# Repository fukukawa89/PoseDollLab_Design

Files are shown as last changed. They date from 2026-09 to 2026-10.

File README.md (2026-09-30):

# PoseDoll 人偶硬件设计

通用静态测姿人偶的独立设计仓库；Manny / Quinn 为软件适配目标。原来位于 `DollSimulation` UE 工程中的硬件、固件与硬件诊断工具已经迁入本目录；UE 插件、角色资产与完整 Python 模拟器留在原项目。

## 当前状态

**O21 已生成约 1500 元的降本工程候选。** 保留 O20 骨架和46路测量；改用 MT6701CT、单面传感板、中央三组16路选择和预制五芯线。单套目标分配1482.50元，尚无正式报价。传感板 ERC/DRC 与固件/主机测试通过；中央板布线、装配集成、实物标定和UE端到端仍未完成，不是整机制造放行。

- [O21设计与成本依据](Hardware/PoseDoll44/docs/DESIGN_REVO21.zh-CN.md)
- [O21预算与通道预览](Hardware/PoseDoll44/tutorials/full-doll-o21/index.html)
- [O21工程设计包](Hardware/PoseDoll44/bench/revO21/PoseDoll_O21_CostDown_Design.zip)
- [加工询价要求](Hardware/PoseDoll44/bench/revO21/RFQ.zh-CN.md)

### O20已保存机械基线

O20为900f572 / posedoll-o20-lightweight-20260930，原ZIP和文件保持不变。保留用户已接受的双髋布局、非相邻姿势避碰及O11摩擦配合结论。

- [O20设计说明](Hardware/PoseDoll44/docs/DESIGN_REVO20.zh-CN.md)
- [O20机械设计包](Hardware/PoseDoll44/bench/revO20/PoseDoll_O20_Universal_Design.zip)

### O19历史记录

**O19 已生成腿杆对齐候选：替换4件腿部连接架，仍为188件/117种打印件。** O11独立小样的配合与可调摩擦已由用户报告通过，不增加摩擦冗余。左大腿及双小腿中间直段对齐参考骨线，右大腿中间段保留向前6mm偏移。双髋中心各外移16mm和既有整机干涉仍保留；24案例及43个中间样本无新增干涉，不能据此声称整机全域通过。

- [O19设计与验证说明](Hardware/PoseDoll44/docs/DESIGN_REVO19.zh-CN.md)
- [O19单台设计包](Hardware/PoseDoll44/bench/revO19/PoseDoll_O19_Universal_Design.zip)
- [O19腿部对照与干涉展示](Hardware/PoseDoll44/tutorials/full-doll-o19/index.html)：本地服务 `/tutorials/full-doll-o19/index.html`。

### O18已保存基线

O18已保存为 `08e8f8b` / `posedoll-o18-prototype-20260930`，342项文件和原ZIP校验通过。以下为O18发布时状态。

**O18 已生成结构简化候选：188件/117种打印件，保留46路测量与USB直连。** 相比O17少14件半壳、28枚螺钉和28枚螺母。O17已冻结为 `5a5ac22` / `posedoll-o17-prototype-20260930`。整机既有干涉仍未解决，先验证Q001/Q002关节小样，不能制造放行。

- [O18设计与已知问题](Hardware/PoseDoll44/docs/DESIGN_REVO18.zh-CN.md)
- [O18简化设计包](Hardware/PoseDoll44/bench/revO18/PoseDoll_O18_Universal_Design.zip)
- [O18三维与外壳对照页](Hardware/PoseDoll44/tutorials/full-doll-o18/index.html)：本地服务 `/tutorials/full-doll-o18/index.html`。

### O17已保存基线

**O17简化候选已冻结：202件/124种打印件。** 保留设计包、三维页面、USB固件与验证报告的原始字节。

- [O17设计与已知问题](Hardware/PoseDoll44/docs/DESIGN_REVO17.zh-CN.md)
- [O17设计包](Hardware/PoseDoll44/bench/revO17/PoseDoll_O17_Universal_Design.zip)
- [O17三维页面](Hardware/PoseDoll44/tutorials/full-doll-o17/index.html)

### O16已保存基线

**O16 单一通用测姿人偶设计候选已冻结保存。** 实体型号收敛为一个，数字高度492.14 mm，46路原始测量；保留O15 Quinn机械几何，不再分别生成两种体型。相邻机构不干涉仍是硬要求，连续全域避碰、实物标定与O16双角色UE验收尚未完成。

- [O16完整设计说明](Hardware/PoseDoll44/docs/DESIGN_REVO16.zh-CN.md)
- [O16单人偶设计包](Hardware/PoseDoll44/bench/revO16/PoseDoll_O16_Universal_Design.zip)：一套打印、采购、线束、实体profile与离线测量参考。
- [O16三维查看页](Hardware/PoseDoll44/tutorials/full-doll-o16/index.html)：先运行下方本地服务，再访问 `/tutorials/full-doll-o16/index.html`。
- 复建与核验脚本：`Hardware/PoseDoll44/cad/revO16/`。本轮不含接触修正，不要求目标角色与实体几何重合。

### O15历史基线

**O15完整数字样机保留，等待实物验证。** 480 mm UE 参考、静态摆姿采集；整机无 1.2 kg 硬门槛，允许手托。采用 FDM 打印与现成金属小件，不需要定制机加工金属件。91 cm 方案继续保留为备用。

- [本次提交与审查入口](Hardware/PoseDoll44/docs/REVIEW_HANDOFF_O15.zh-CN.md)：先读此页，再查详细设计、证据和未验证项。
- [O15 详细审查请求](Hardware/PoseDoll44/docs/REVIEW_REQUEST_REVO15.zh-CN.md)；[数字结果汇总](Hardware/PoseDoll44/generated/revO15/runs/o15_20260929_r1/FINAL_BATCH_SUMMARY.json)。
- [Quinn 统一测试包](Hardware/PoseDoll44/bench/revO15/PoseDoll_O15_Quinn_Prototype.zip) / [Manny 备选包](Hardware/PoseDoll44/bench/revO15/PoseDoll_O15_Manny_Prototype.zip)：只选一套，每套 214 种文件、273 件打印件。
- [中文装配与测试说明](Hardware/PoseDoll44/bench/revO15/guide.html)；[静态采集软件设置](Tools/PoseDollHardwareBridge/README_O15.zh-CN.md)。HTML 请下载打开或通过下方本地服务查看。

本次提交同时收录此前尚未提交的 O5—O14 迭代和 O15 使用的历史依赖。各轮已封存文件保留原字节，旧文档中的“当前”指该轮检查点。O15 的采样几何检查、切片、电路规则、固件构建和 UE 桥接已有数字证据；完整强度、保持力、耐久、带线运动和电子实测仍未完成。

历史入口：[O4](Hardware/PoseDoll44/docs/REVIEW_REQUEST_REVO4.zh-CN.md)、[O3](Hardware/PoseDoll44/docs/START_HERE_REVO3.zh-CN.md)、[O2](Hardware/PoseDoll44/docs/START_HERE_REVO2.zh-CN.md)、[O 初轮](Hardware/PoseDoll44/docs/START_HERE_REVO.zh-CN.md)。不要把历史制造说明与 O15 混用。

以下为备用版的历史基线：

- **机械基线为 Rev N1**：两款分别按 UE 人物参考比例设计，参考身高约 91 cm；胸前大挡板已取消，左肩局部刮碰已修正。
- **下一项为“局部采集 + 外置电源/USB 接口盒”**：方向已确定，新电路板、安装结构和线束尚未实施。
- **小型化仍待比较**：当前尺寸不是已证明的下限，不能直接缩放现有文件，也不能认定重新设计的小型关节必然昂贵。
- 44 个协议槽中，41 轴测量，骨盆 3 轴固定参考；整体位置和全部整体旋转在 UE 调整。
- 当前交付是数字原型候选，尚未实物鉴定。

## 阅读入口

0. [O15历史方案](Hardware/PoseDoll44/docs/REVIEW_HANDOFF_O15.zh-CN.md)。以下 Rev M/N 文档用于备用版。

1. [最新 Rev N1 设计入口](Hardware/PoseDoll44/START_HERE_REVN.zh-CN.md)
2. [胸部修订与设备外置方案](Hardware/PoseDoll44/docs/CHEST_AND_EXTERNAL_REVN.zh-CN.md)
3. [尺寸、磁铁和关节小型化评估](Hardware/PoseDoll44/docs/SIZE_REVIEW_BEFORE_EXTERNAL.zh-CN.md)
4. [制造说明](Hardware/PoseDoll44/docs/FABRICATION_REVM.zh-CN.md)、[装配说明](Hardware/PoseDoll44/docs/ASSEMBLY_REVM.zh-CN.md)、[测试和校准](Hardware/PoseDoll44/docs/BUILD_AND_CALIBRATE_REVM.zh-CN.md)
5. [迁移记录和验证](docs/MIGRATION.zh-CN.md)

Rev M 文档描述原完整基线，使用时应应用 Rev N1 的取消件和左肩修订。更早版本与 `planning/` 是历史依据，不能混作当前制造说明。

## 目录组织

| 路径 | 用途 |
|---|---|
| `Hardware/PoseDoll44/cad/` | 参数化机械模型，保留当前模型仍引用的历史模块 |
| `Hardware/PoseDoll44/electronics/` | 原生 KiCad 工程、符号/封装及板级 STEP 输入 |
| `Hardware/PoseDoll44/mechanical_manifest/` | 轴、接口、比例和网络定义 |
| `Hardware/PoseDoll44/docs/`、`verification/` | 设计说明、数字检查和原型验收依据 |
| `Hardware/PoseDoll44/generated/` | 总装、打印件、查看器、交付清单和本地 CAD 缓存 |
| `Hardware/PoseDoll44/reference/`、`references/` | UE 参考数据及元件资料 |
| `Hardware/PoseDoll44/harness/` | 两款线束与下料表 |
| `Firmware/PoseDollFullBody/` | 六节点完整固件与主机端 C 核心测试 |
| `Firmware/PoseDollHardware/` | 早期单关节固件，历史用途 |
| `Tools/PoseDollHardwareBridge/` | 诊断、校准、数据转换和测试 |
| `Tools/PoseDollSimulator/`、`Shared/` | 硬件需要的协议/运动学代码及配置快照，不含模拟器 GUI |
| `planning/` | 原始规划包副本，父目录中的原下载包也保留 |
| `scripts/` | 独立仓库的检查、构建和查看器入口 |
| `.local/` | 本机迁移清单、运行结果等，不入 Git |

保留 `Hardware/`、`Firmware/`、`Tools/` 层级，以保持已有相对路径及历史资料的可追溯性。协议快照来源与逐文件哈希见 [software_snapshot.json](docs/software_snapshot.json)。

## 环境与离线检查

在本目录打开 PowerShell。本机已经建立独立 `.venv`；新克隆可执行：

```powershell
py -3.13 -m venv .venv
.\.venv\Scripts\python.exe -m pip install -r requirements.txt
.\.venv\Scripts\python.exe scripts/check_repository.py
.\scripts\Build-Design.ps1 -Stage OfflineTests
```

离线检查包括协议配置、Python 测试、C 核心测试和 C/Python 数据帧一致性；不连接硬件或操作 UE。C 测试需要 Visual Studio C 工具链，`-VcVars` 可指定 `vcvars64.bat`。本机迁移后结果为 **81 个 Python 测试、9 个 C 场景通过，数据帧逐字节一致**。

## 打开三维查看器

O15 使用以下命令启动服务，然后访问 `http://127.0.0.1:8769/tutorials/full-doll-o15/index.html`（脚本原来的启动提示仍指向 O14，以此 URL 为准）：

```powershell
python scripts/serve_posedoll_tutorials.py --port 8769
```

提交资料可在新克隆中用 Python 标准库复核：

```powershell
python scripts/verify_o15_review.py
```

以下命令与说明保留为旧版查看器入口：

```powershell
.\scripts\Start-Viewer.ps1
```

默认根据 `verification/revO3/latest.json` 打开 Rev O3 查看器，当前为 `http://127.0.0.1:8874/generated/revO3/runs/o3_20260924_r3/review.html`；通过 `-Revision revN` 打开 91 cm 备用版，仅绑定本机。`-NoBrowser` 只启动服务；端口冲突时可用 `-Port` 指定另一端口，不会自动终止其他进程。

Rev O3 的当前及历史检查运行、HTML、网格、STEP、原生 KiCad 板件、固件产物与原始日志随本次审查提交收录；宿主 C 编译产物通过逐件哈希的 portable ZIP 保存。Rev O 第一轮的 HTML、轻量网格、布局数据及三档关节 STEP 也保留。十份体型布局 STEP 下载需先用 `Build-RevO.ps1 -Stage CAD` 重建。91 cm 备用查看器仍依赖未纳入 Git 的大型网格，需复制旧输出或重建。

## CAD、电路和固件

- CAD：CadQuery 2.7。现有 `Hardware/PoseDoll44/tools/run_cad.py` 可使用本机 CQ-editor 2.7 的环境，需要 CQ-editor 保持开启、Python 版本匹配；也可自行安装常规 CadQuery 环境。
- 电路：KiCad 10，打开 `electronics/` 中对应 `.kicad_pro`。搬迁前已打开的 CQ-editor/KiCad 文件，应从新目录重新打开，避免保存回原路径。
- 固件：ESP-IDF 6.1、ESP32-S3。旧构建缓存已保留，但含旧绝对路径；不要直接在其中增量构建。
- 布线工具：Freerouting 2.4.1 JAR 保留在本机 `Hardware/PoseDoll44/tools/vendor/`，不入 Git；许可证与说明保留。

```powershell
.\scripts\Build-Design.ps1 -Stage CAD
.\scripts\Build-Design.ps1 -Stage Firmware
```

CAD 阶段生成/复核 Rev M 完整基线，耗时较长。Rev N1 的修订脚本位于 `cad/revN/`，依赖 Rev M 完整输出及其复核结果，不是上述命令自动生成的另一套角色。当前源码与必要 CAD 输入纳入 Git。

新构建入口使用本仓库 `.venv`。Firmware 阶段会把检测到旧工程路径的节点缓存移入 `.local/legacy-firmware-builds/` 后重新构建，不删除缓存、不烧录。旧脚本中的 CQ-editor、KiCad、ESP-IDF 安装盘符仍是本机配置；换电脑须配置工具路径，历史工具可参考 `local_toolchain.example.json`。UE 参考重新导出需要原 UE 工程及插件，但导出脚本现在将数据写到本设计仓库。

## Git 与本地成果

Git 收录设计源码、KiCad 工程、固件、必要板级 STEP/角色参考输入、协议快照、说明、交付元数据和检查记录。`.gitattributes` 保留原行尾，避免检出时破坏来源文件的字节哈希。

大型总装 STEP、查看器大网格、CAD 缓存、ESP-IDF 构建目录、Python 环境和第三方工具二进制保留在磁盘，由 `.gitignore` 排除；没有启用 Git LFS。Rev O 审查快照额外收录三档单关节总成 STEP、两个 A 级配合样片 STEP/STL、轻量查看器与本轮原始编译/ERC/DRC 日志，Rev O3 本次另显式收录三个检查运行及其可追溯产物，仍未放开其他版本的整个生成目录。其他机器如需完整本地成果，应另外复制 `Hardware/PoseDoll44/generated/`。**推送 Git 不等于备份全部 6.87 GB 本地成果。**

现有验证报告保留为历史快照，迁移后的路径修复和检查另列记录；没有把迁移当成新一轮全身工程验证。本轮提交由使用者推送到远端；审查应指定 `design/revO-desktop-external` 分支和所读取的完整提交号。

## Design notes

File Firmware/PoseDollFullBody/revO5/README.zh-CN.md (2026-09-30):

# Rev O5 请求式静态采集固件

本目录是 O5 独立后继，保留 A（14 芯跨肩）硬件拓扑，未改写旧 PD41 / O1–O4。G0 和 N1–N6 已通过 ESP-IDF 6.1 编译；**未烧录、未连接传感器，实际 SPI/CAN/USB 时序未测量**。

## A 路径

UE PDS1 request → 主机 `Tools/PoseDollHardwareBridge/bridge.py` → USB PDG5 → G0 的 PDC5 CAN 请求 → 区域 AS5048 诊断与角度读取 → G0 新扫描 → 主机 → PDS1 → UE。

每次扫描先清空 41 个测量槽和节点 boot；3 个根槽为 fixed。区域节点只在新 token 请求到达后读实际配置的 SPI 端口，不从旧周期缓存取值。G0 逐区查询；使用 G0 的首个发送前时刻与最后接收后时刻作为保守全扫描区间，区域时钟只提供 duration，不拼接为全局绝对时间。

约 10 Hz；单个区域查询最多 20 ms，全扫描仍受 100 ms 上限约束；3 s 采集事务截止。A 路径丢失/无效数据将终止采集，下一次需要新 UUID。没有以重复请求重置原采样时间。区域返回的故障字保留，缺节点/缺端口不补齐。最终稳定性和 Capture 仍由 UE 判断。以上是代码策略，不是实测时序保证。

`CONFIG_PD_BENCH_PORTS` 配置该区域前 K 个实接端口（默认 9，再限制到该区端口数）。局部台架只能使用主机 `--diagnostic`，禁止当作完整 41 轴姿势。配置端口掩码不是传感器存在性证明；完整扫描还必须逐槽通过实际读数/诊断校验。

## USB PDG5/1：220 字节，小端序

| 偏移 | 字段 |
|---|---|
| 0 / 4 / 5 / 6 | `PDG5` / version=1 / type / u16 length=220 |
| 8 / 16 | u64 device / G0 boot |
| 24 / 40 | UUID 原始 16 字节 / u64 scan |
| 48 / 56 / 64 | u64 request_start / scan_start / scan_end，单位 µs，均为 G0 时钟 |
| 72 | 6 × u64 区域 boot，N1…N6 |
| 120 | 44 × u16，固定槽 `0x4000`，角度 `<0x4000`，missing=`0xffff`，fault=0x8000 加诊断标志 |
| 208 / 216 | u64 本轮配置并读取端口掩码 / 前 216 字节的 CRC32 |

type：1 PROBE、2 HELLO、3 REQUEST、4 ACCEPTED、5 SCAN、6 CANCEL、7 ERROR、8 STOP。REQUEST/CANCEL/STOP 必须匹配 device/boot。重复当前 REQUEST 只确认相同 UUID 和原 request_start，ACK 的 scan/start/end 为 0。新的 UUID 才开始新事务。串口未完成帧 500 ms 超时；错误数据不会作为姿势解码。ESP 控制台使用 UART0，USB JTAG 单独承载此二进制协议。

## CAN PDC5/1

查询 ID=`0x600+node`，回复 ID=`0x610+node`，node=1…6。标准 CAN 每帧 8 字节：byte0 是片号，其余 7 字节数据，最后补零。请求 28 字节（4 片），回复 52 字节（8 片）；严格顺序、CRC32、100 ms 重组上限，任何错误按整次失败处理。

请求：version/op/node/reserved、G0 boot、token、预期区域 boot、CRC。回复：version/kind/node/count、G0 boot、token、区域 boot、duration、9 个角度/状态字、端口掩码、CRC。具体偏移见 `static_gateway.c`；USB 的完整固定轴序见桥接 `layout.json`。N1/N2/N3/N4/N5/N6 的起始槽分别为 3/6/12/28/21/37，数量 3/6/9/9/7/7。物理 CS 引脚沿用 `../main/pd41_config.h`，旧实时 deadline 常量未用于本实现。

## C 路径的恢复实验

`remote_runtime.*` 是 PDR4/1 编解码器外的有界运行时模型，尚未接 STM32 启动、SPI、UART、DE 或实际 RS485。线格式仍为 68/80 字节，不暗改版本。

一个事务缓存：采集中重复请求返回本地 WAIT（不新增 wire BUSY）；采集完成后，相同字节请求重放同一 80 字节回复，原测量 start/end 不变。100 ms 限制只约束该扫描的重试；下一次合法扫描可在 10 Hz 周期重新采样。已过期的重试使本次 capture 失败，需要更大的 capture_counter。复位必须用新的 boot/nonce/generation 重新绑定；外层入网握手仍须由驱动实现。主控端重试必须保留第一次发出请求的时刻；不能用收到缓存回复的时刻冒充新样本。

## 复算

从设计仓库根目录运行：

```powershell
scripts/Run-RevO5-GatewayTests.cmd "$PWD/.local/o5_gateway_new"
scripts/Run-RevO5-LinkTests.cmd "$PWD/.local/o5_link_new"
Firmware/PoseDollFullBody/revO5/build.ps1 -Role G0 -BuildRoot "$PWD/.local/o5_idf_new"
```

其他角色依次替换为 N1…N6。主机 C 测试 `/W4 /WX`；测试回调是模拟读数。IDF build 不等于实物通过。SDK/编译器本地路径集中在构建脚本中；未执行 flash。

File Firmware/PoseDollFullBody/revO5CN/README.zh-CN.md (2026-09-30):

# MT6701 SSI 数字实验：未接入采集

仅包含平台无关的 24 位帧数学解码与故障输入检查。它不与 ESP-IDF、STM32、O5 G0/区域节点或 UE 的 Capture 路径链接。

使用 Rev1.8 手册的 14 位角度、4 位状态、6 位 CRC、多项式 x^6+x+1。CRC init=0/xor=0 为待确认假设，不是已经验证的硬件契约；SPI 模式未指定。`MT_DECODED_UNQUALIFIED` 表示在该假设下可解释，`capture_eligible` 始终为 false。任一磁场/按压/失跟踪/保留状态均拒绝作为稳定姿势。不能仅由全零合法 CRC 推断设备在线。

测试涵盖全部 2^18 数据输入，对全部 2^14 角度逐位翻转 24 个传输位，并检查长度、空输入、全零和全一。CRC 测试使用独立多项式长除法，不是拿实现自身生成期望值。

运行 `scripts/Run-RevO5CN-CodecTests.cmd <输出目录>`，要求本地 MSVC C11。不得将此试验文件当作已实现的 SSI 硬件驱动。

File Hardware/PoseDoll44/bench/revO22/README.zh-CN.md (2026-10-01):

# O22 工程包入口

先打开 [设计说明](DESIGN.zh-CN.md)，再看 [12项审查状态](optimization_tracker.json)。

- 一套USB测姿人偶，46路原始轴，41个语义自由度；核心测量数量不减少。
- `print_batch/manifest.json`：整机完整打印清单（186件）；`physical_tests/sensor_coupon/`是另外两个可拆卸传感小样附件，不要重复采购O11原摩擦件。
- `manufacturing/`：Gerber、钻孔、贴片坐标、BOM和单套询价模板。
- `electronics/`：KiCad原理图及PCB。载板正式文件名为`PoseDoll_O22_SSI_Carrier.kicad_pcb`，4层；placement/route_input等是过程文件，不用于下单。
- `harness/routing_plan.json`：46路端口、实际骨段固定点、预切长度、完整左臂示例；首件前长度未放行。
- `physical_tests/ACCEPTANCE.zh-CN.md`：新传感小样、16路长支路、逐轴标定及46路→UE验收；空表都是真实未测状态。
- `source/`：PC侧采集/校准/导出与39项单元测试。
- `firmware_source/`、`firmware_binaries/`：沿用O21 P21R/1，原始文件哈希见SOURCE_INDEX。刷写请使用对应固件说明，不混用P17R。
- `ue/target_profiles/`、`ue/editor_scripts/`、`ue/plugin_source/`：双目标配置、回归脚本和对应插件源文件。把这些改动用于现有DollSimulation仓库并重新编译；不要把三个源文件当成独立完整插件。
- `cad_source/`：生成脚本副本，用于审计。重建CAD需完整设计仓库及SOURCE_INDEX列出的历史输入；加工文件已经独立导出，打印不要求运行旧CAD生成器。
- `verification/`：数字测试证据，所有合成输入均明确标注。没有硬件测试或供应商成交价。

ZIP保留`bench/revO22`和`tutorials/full-doll-o22`的相对目录。解压到任意空目录，在根目录运行：

```powershell
python bench/revO22/serve_preview.py
```

然后打开 http://127.0.0.1:8771/tutorials/full-doll-o22/index.html 。该服务仅绑定本机地址。

使用现有工程中的快捷采集脚本：在UE中打开含一个Control Rig的目标序列并停在需要的帧，执行：

```python
import sys, unreal
sys.path.insert(0, unreal.Paths.project_dir() + 'Scripts/O22')
import capture_file
capture_file.capture(r'C:\your_capture\capture.payload.json', 'quinn')
```

正式入口不使用synthetic覆盖开关。它创建可撤销关键帧，保存由编辑者决定；身体整体位置和动画修饰继续在UE中处理。

**目前不能据此宣称整机已无干涉、精度已达标或成本已压到1500元。** 数字工作已收敛为首件包；实测、正式询价以及旧有极限姿势干涉仍是放行条件。

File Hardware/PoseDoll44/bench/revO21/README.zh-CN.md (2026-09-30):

# O21 单台低成本 USB 人偶：目标约 1500 元

本包是 **降本工程设计候选**，不是完整可下单的整机制造包。目标预算 ¥1482.50，按已有打印机、自行打印与机械总装、电子板和线束外包、包含必要备件与运费计算。0 份正式报价，较贵情形约 ¥2210；不含多轮开发失败或购买计量设备。

保留 O20 骨架、46 路原始测量、41 个语义旋转自由度、已获用户实测通过的 O11 摩擦原理和双髋各外移 16mm。新采集方案为 MT6701CT-STD-R＋3×16 路 DO 选择器＋XIAO USB 主控。新 P21R/1 固件、电路和线束不能与 O20/AS5048A 六针级联混装。

- **DESIGN.zh-CN.md**：完整设计、原厂依据、预算与精度边界。
- **RFQ.zh-CN.md / budget.json**：加工方询价清单与逐项预算，包含工程最低收费检查。
- **electronics/sensor**：12×10×1mm SOP8 单面元件小板，ERC/DRC 通过；没有磁场/机构配合实测。
- **electronics/carrier**：中央原理图和网表，ERC 通过；尚未布局布线或确认所有精确采购料号。
- **firmware_source / firmware_binaries**：编译通过的 ESP32-S3 工程候选；没有刷写或连接实物。
- **source**：USB 解码、可选实测周期误差表、机械 FK；保存原始包与标定，拒绝缺轴/过期/坏数据。
- **profiles**：46 路绑定；未标定的空模板，不得冒充已测标定。
- **verification**：本轮软件、电路、浏览器检查记录。
- **mechanical_baseline.json**：O20 版本与 ZIP 哈希。原机械打印文件在已保存的 O20 包中，本包不重复旧整机制造文件。

先运行 python serve_preview.py，打开终端提示的本地地址（viewer/index.html）。预算页也可直接离线打开。便携包中的“机械继承记录”是 O20 来源文件；完整可交互三维页在仓库 tutorials/full-doll-o20/index.html。

软件复核（安装 requirements-reference.txt 中依赖）：

    python source/test_device.py
    python source/test_o21.py
    python source/verify_package.py

本机固件可用 firmware_source/build.ps1 -BuildRoot <独立构建目录> 编译；脚本内记录了本次 ESP-IDF 6.1 的本地工具路径，异机需调整。source_build 中的生成脚本依赖完整设计仓库及其历史输入；它们用于追溯，不是脱离仓库的自动再造程序。KiCad 10 原生文件可独立打开，标准封装依赖 KiCad 10 库。

未完成：中央 PCB 布线/DFM，精确保险丝和连接器定料，新器件/控制盒/线束整机 CAD 集成，相邻机构出线避碰，磁场与全范围角度标定，供应商正式报价，生产 UE 适配及保存/重开验收。O11 已通过的摩擦配合不会因此被重新列为未通过。

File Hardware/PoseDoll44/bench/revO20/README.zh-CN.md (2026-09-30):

# O20 单台USB人偶：少10件，打印体积少2.8%

O19已保存：98c084a / posedoll-o19-leg-alignment-20260930。O20独立提供115种、186件单台打印清单，其中185件装在人偶上，1件为焊接治具。

合并两侧脚趾固定外壳，少2件打印件、4颗M3×20螺钉、4个M3螺母。14件骨架中23段芯孔及控制盒开孔使CAD打印实体少约16.845 cm³。按历史PETG实心口径合计约减29.35 g，非称重；实际值应对比相同切片设置。

双髋各外移16 mm按用户决定保留。远端部件相碰按姿势避让处理，相邻机构仍检查。O11配合与可调摩擦已由用户报告通过，不增加摩擦冗余。

W001–W017为新打印件，其余沿用；W016/W017用原肩轴和垫片。空心杆切片查看最大5 mm内腔桥接，避免无法取出的内部支撑。制造网格已回读验证；新杆加载刚度与UE端到端尚未实测。

运行python serve_preview.py，打开http://127.0.0.1:8771/viewer/index.html。完整性检查：python source/verify_package.py。已有采集/USB测试：python source/test_device.py、python source/test_usb.py。

详见DESIGN.zh-CN.md、PRINT_UNIVERSAL.csv、DESIGN_STATUS.json及verification。cad_source的正式构建入口为design.py、export.py；复建依赖仓库冻结历史输入，打印无需复建。

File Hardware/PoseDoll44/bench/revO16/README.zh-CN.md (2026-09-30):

# PoseDoll O16 Universal

一个实体型号，46路原始测量，25个模块，数字中立高度492.14 mm。

先读 DESIGN.zh-CN.md 与 DESIGN_STATUS.json。本包是数字设计候选，不是整机制造放行。连续全域避碰、带线实测、标定、保持力及O16的Manny/Quinn端到端UE验证尚未通过。

本轮保留O15 Quinn机械几何，取消第二体型；新建目标无关的实际机械模型与采集参考实现。不是重新优化后的另一套关节STL。完整打印数量见 PRINT_UNIVERSAL.csv：214种、273件；同一编号的STL/3MF不要重复打印。

查看三维：解压后在本目录运行 `python -m http.server 8771 --bind 127.0.0.1`，打开 http://127.0.0.1:8771/viewer/index.html 。页面不依赖互联网库。

完整性检查：`python source/verify_package.py`，仅用标准库。
测量参考测试：安装独立环境的NumPy后运行 `python source/test_device.py`。

profiles/calibration_INCOMPLETE.json必须保持未标定状态，直到填写真实证据；measurement_SYNTHETIC.json只是格式示例。source/device.py是离线参考，未接入生产串口或UE。target_adapter_contract.json是适配任务契约，不是已完成的角色配置。

historical_o15/仅提供原装配/采购工艺参考；原文中的Quinn指本版几何来源，不代表还需要第二台人偶。电子和固件使用原型号名称以保持可追溯。默认固件未绑定真实MAC，不直接作为已配对硬件。

原工作区可用 cad/revO16/build.py 复建配置、清单与查看器，用package.py重建本包；完整机械重建仍需要工作区内的历史CAD依赖。

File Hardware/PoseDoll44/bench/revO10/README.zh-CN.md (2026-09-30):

# O10 独立摩擦试验：先知道能否稳住，再定关节尺寸

**这不是整臂打样，也不是孔径测试。** 要测的是：真实 PA12、钢片和碟簧组合，在可调范围内能提供多大的保持力、是否难以转动、停留后是否滑移。没有硬件，因此记录表的测量栏全部留空。

先打开[动画页面](../../tutorials/design-lab/index.html)，选择“04 看测试”。页面中的配重和细线只演示加载方向，不预测保持效果。

## 为什么现在需要这个数据

当前悬空臂模型要求弯折轴约 **0.392 N·m** 的保持力。按两侧各承担一半的初步分配，单侧试验的筛选下限约 **0.196 N·m**；真正的双侧载荷分配仍须在完整关节上检查。100 mm 水平力臂挂约 200 g，即产生约 0.196 N·m，此外还必须计入长臂自身重量。

两片 A8 碟簧反向串联，并不会把 210 N 变成 420 N。厂家目录点为单片高0.45 mm、力210 N；目录也列出了薄碟簧的力偏差。例如按二级偏差，该点可能对应189～273 N，具体等级须与供应商确认。这不是实测值。[锐尔立目录](https://www.raleigh-spring.cn/discspring/list_84_2/)

按现有双侧端面模型和210 N估计，有效摩擦系数需约0.21；若取189 N，则约需0.24。自由钢片、钢片与铝座接触、实际表面、压力分布和塑料蠕变都会影响它。继续假设一个系数来定碟簧数量、轴长和关节直径，会把这个未知量带进胸肩设计。

**测试结果用于决定保持现有尺寸、增加弹簧组，还是扩大摩擦面。** 当前胸肩试排还有双侧前收20°的碰撞；这个试验不会使该结构自动合格，也不代替后续的避让、连接架及完整带线总装工作。

## 小样与器件

| 项目 | 数量建议 | 说明 |
|---|---:|---|
| PA12长臂小样 | 3件 | 与拟议叉架采用同种打印工艺、方向和表面处理；不要用另一种塑料的结果替代 |
| 铝底座 | 1件 | 6061候选；30×30×8 mm，3个Ø4.4通孔，接触面平整；材质、加工和表面状况写入记录 |
| 钢接触片 | 2片，重复件可另备 | 外径12、内径4.24、厚0.5 mm；材质和表面必须与后续关节一致，不能用外径9 mm的普通垫圈悄悄替代 |
| 锐尔立A8碟簧 | 6片 | 8×4.2×0.4 mm；两片反向为一组，三组可比较偏差 |
| M4×20螺钉、M4螺母 | 各1 | 页面显示名义包络；采购时核对实际头部和垫圈尺寸，螺纹使用合格标准件 |
| 前后承压垫圈 | 各1 | 前垫圈名义外径9、内径4.3、厚0.3；后垫圈厚0.8。实际尺寸改变时记录堆叠，不按模型高度假装已压到目录点 |
| 固定支架、两颗底座固定螺栓、挂线 | 1套 | 底座两个偏置安装孔固定在支架上，中心孔供转轴穿过；夹具不能夹住移动长臂 |
| 称、卡尺、角度/位移记录工具 | 按已有设备 | 挂重连同容器一起称；角度不确定度过大时只能记“不确定” |

[PA12长臂 STEP](PA12_lever.step) / [STL](PA12_lever.stl)；[铝底座 STEP](aluminium_base.step) / [STL](aluminium_base.stl)。STEP已做实体有效性和导出回读检查。可用这些文件核对加工方案；**不是整关节生产图纸**。零件采用装配坐标，打印排版时需要落到打印平台。

长臂中心孔成品目标为Ø4.3 mm，必要时在打印后修整到该尺寸。这个准备只保证能够装上轴。小样的摩擦接触内半径约2.15 mm，与关节拟议的2.12 mm略有差别，因此不把系数直接等同；真正的关节仍要复测。

## 如何装和测

1. 将底座固定，**中心轴水平放置**。绿色长臂在竖直平面中转动。顺序为：铝底座 → 内钢片 → PA12长臂 → 外钢片 → 两片反向碟簧 → 前承压垫圈 → 螺钉头；背面是后垫圈和螺母。
2. 清洁并记录实际表面状态。使用干燥接触作为本次候选，不能一件上油、一件不处理而混成同一组数据。拍照记录两片碟簧方向。
3. 先将两片碟簧的总压缩高度设在1.10 mm，记录实际读数；随后研究1.00、0.90 mm。不要把拧螺钉的力矩或这个高度写入“实测轴向力”栏，没有测力设备就把该栏留空。不以压平弹簧来增加保持力。
4. 称长臂自重，测它的重心到轴心的水平距离。将长臂置于水平，在距轴心约100 mm的孔上挂小配重，逐步增加并称量容器总质量。挂线应竖直。实际重力矩为：

   `T = 9.80665 × (挂重kg × 挂点水平力臂m + 长臂kg × 重心水平力臂m)`

5. 每个高度分别测正、反两个方向，至少重复3次。记录开始、60秒、10分钟和1小时的位置。先区分长臂弯曲、夹具松动和摩擦面的滑动；不能分清就记录“不确定”。不要把照片里“似乎没动”写成0°。
6. 记录刚开始转动的峰值阻力和持续转动的阻力。可用测力计在已知垂直力臂上拉动，力×力臂为转矩。要计入并扣除/说明重力作用，不能把抬升配重所需的总拉力全算成摩擦。
7. 记录拆下后的压痕、松动与表面变化。若底座、长臂或夹持已经明显变形，这条记录不能用于宣布摩擦方案合格。

0.3°停留漂移、60 mm手持力臂和20 N操作力沿用为**暂定筛选线**，不是用户确认的最终手感或精度。角度读数的不确定度要和漂移一起比较；例如0.29°±0.05°不能判定通过0.3°。

小样用穿透螺钉和背面螺母，便于独立实验；它不能验证拟议M3自定义轴的防松、铝环变形、两侧分配或整臂的手感。只有小样出现有余量的工作窗口后，再带着实测数据修订并验证完整关节。

## 怎样交回数据

复制[空白记录表](measurement_template.json)，每次测量填一份。空白、非有限数值和分辨率不足都会保留为未完成或不确定。当前目录没有用户的实测数据。

在design根目录可运行：

```powershell
.venv/Scripts/python.exe -X utf8 Hardware/PoseDoll44/cad/revO10/evaluate_bench.py 你的记录.json
```

输出只分析这一条小样观察，不会升级成“整关节通过”。没有轴向力实测时不会生成摩擦系数，也不会把目录210 N填入实测栏。

国产微型滑环是另一项独立电气候选，尚不要求和摩擦小样一起购买。先核对LPMS-05D实际供货图纸、引线和版本，再用现有静态采集协议测转动中的导通、错误帧、掉电和恢复；当前没有可连接硬件，未执行该测试。

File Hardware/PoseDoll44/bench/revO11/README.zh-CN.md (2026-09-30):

# O11：家用打印小样的制作与测试

本版把定制铝底座改成两个打印半件，长臂也用家用 FDM 打印。金属件全部按目录规格购买，无需车轴、铣铝、激光切特殊钢片或打印金属。这里先制作的是独立材料小样，完整人偶尚未制造放行。

## 先打开什么

- 图解页面：`../../tutorials/print-first/index.html`，可旋转、拆开并高亮零件。
- `print_beds/bench.3mf`：只含底座两半和长臂，已经按建议方向摆放。单位 mm，没有 G-code、机器配置或实测打印结果。
- `print_beds/*_on_bed.stl`：单个打印件；以 `printed_` 开头的三件用于小样。
- `print_beds/core_fit_only.3mf`：双轴核心的装配研究件，尚不是完整肩部的制作包。
- `measurement_template.json`：空白记录表，所有数值都需要实际测量。

导入 3MF 时选择自己的打印机、喷嘴和耗材。不要执行别人机器的 G-code，也不要把作者的 X1C 机型设置直接搬到其他打印机。

## 需要准备的零件

| 零件 | 小样数量 | 成品规格或制作方式 |
|---|---:|---|
| 底座前半、底座后半、长臂 | 各1 | 家用 FDM 打印；文件名为 printed_base_plus、printed_base_minus、printed_lever |
| 轴肩螺钉 | 1 | NBK **SBSM-M3-4-8**，光轴直径4、肩长8、M3螺纹长7、头径7、头高3、内六角对边2 mm；在华目录渠道。不得随意用全螺纹螺钉代替 |
| M4 大垫圈 | 2 | 外径12、内径4.3、厚1 mm，嘉立创 FA EPDA-S1W-K 的 M4 规格，SUS304 |
| M4 普通平垫圈 | 1 | 外径9、内径4.3、厚0.8 mm，EPDA-S1W-B 的 M4 规格 |
| M3 大垫圈 | 1 | 外径9、内径3.2、厚0.8 mm，EPDA-S1W-K 的 M3 规格；装在底座内部 |
| M3 六角螺母 | 3 | 对边5.5、厚2.4 mm 的普通六角螺母；1颗内部、2颗连接底座 |
| A8 碟簧 | 2 | 瑞力 A 系列，外径8、内径4.2、料厚0.4 mm，反向串联；不是开口弹簧垫圈 |
| M3×35 圆柱头内六角螺钉 | 2 | 普通标准件，连接两半底座；内六角对边2.5 mm |

目录规格已核对，库存和批次还没有采购核实。商品标题只写“M4垫片”不够，要核对三项尺寸，特别避免把厚1.6 mm的重型垫圈买成厚1 mm的宽型垫圈。SUS304平垫圈是本轮摩擦副候选，不能自动继承先前特殊钢片的摩擦系数。

另备现成小台钳或夹具、2 mm和2.5 mm内六角扳手、5.5 mm扳手、游标卡尺、细绳、小挂钩及可称重的砝码/重物。夹具要同时固定两半底座。底座外侧还留有M4通孔，可按固定板厚度选常规螺栓；这些属于外部台架，不包含在15件小样CAD中。

## 推荐的第一批打印

以 **PLA-CF** 为首轮材料候选，参考用户提供的 ToddlerBot 文件。并不是已经验证它能承受本关节全部长期载荷。普通 PLA 也可先做低载试装，不要将不同材料、方向、壁厚的试验结果混在一起。

- 用耗材厂家认可的耐磨喷嘴；本轮起点是0.4 mm喷嘴、0.2 mm层高、6道外壁。
- 小样的三件先用100%填充、5层顶面/5层底面，目的是固定试验变量，避免把填充差异误认为材料差异。此设置由本项目选择，不是 ToddlerBot 的默认25%填充。
- 使用厂家对应机型的温度和速度配置。机器、喷嘴和耗材未经确认，本包没有编造通用 G-code。
- 长臂平放；底座两半按3MF方向让分合面朝打印平台。切片时检查内部螺母/垫圈座的桥接与支撑；支撑必须能够从分合面清除。
- 看逐层预览：载荷面不能只剩稀疏填充，孔边不能出现断线，不能有封死而无法清理的支撑。几何排版已检查，尚未用用户实际机型完成切片或试打。
- 若要制作双轴核心的装配样件，承力环分合面朝平台，叉架横放方向仅作为候选。检查弧面支撑和孔的层间方向。完整核心的承载验证仍独立于这个小样。

不要通过盲目拧紧去挤出孔径公差。打印中心孔名义4.25 mm；实际小孔可能偏小，去毛刺后确认光轴能够转动，必要时用合适手工具修孔并记录最终尺寸。不要磨薄标准垫圈去强行套用旧版尺寸。

## 按这个顺序装

1. 将两个底座半件分开。把内部M3螺母放入六角槽，M3大垫圈放入相邻圆槽。圆垫圈朝向长臂一侧。它们通过打印件的承压台阶承受轴向力。
2. 合上底座，用两颗M3×35螺钉与两颗外侧螺母连接。先检查分合面闭合、内部零件未夹歪，再均匀紧固。
3. 在正面依次放：**M4大垫圈 → 打印长臂 → M4大垫圈 → 两片反向碟簧 → M4普通平垫圈 → 轴肩螺钉**。
4. 让轴肩螺钉拧入内部M3螺母。先消除明显松旷，再逐步调整；不要把拧紧扭矩直接换算为夹紧力。
5. 固定底座，让转轴水平、长臂在竖直面内摆动。先空载移动，确认没有擦碰、卡死、松脱或分合面张开。

两片碟簧反向串联增加可用压缩行程，不会把210 N变成420 N。目录中的210 N对应特定单片高度，是参考点，不是本件实测力或允许悬挂21 kg。

## 测什么，而不是只改孔径

首先检查小样能否在保持姿势的同时仍然容易转动，并观察打印材料在持续夹紧后是否松弛。孔径只影响能否装配，是前置检查。

1. **先低载。** 从小挂重开始，逐级接近约0.20 N·m的单摩擦点筛选目标。100 mm的实际垂直力臂大约对应200 g挂重，但还需加上长臂、挂钩和绳子的自重力矩。这个目标由新载荷预算确定，并非测得的能力。
2. **记录夹紧状态。** 分别研究两片碟簧总高1.10、1.00、0.90 mm的情况；这些是候选试验点。准确测不到时记录“未测得”，不要用拧了几圈替代高度或力。0.80 mm只用于数字极限尺寸检查，不是推荐的试验起点。
3. **保持与漂移。** 正、反向分别记录60、600、3600秒，另做24小时停留。初始漂移筛选值0.3°；测量误差若已经接近或超过它，只能判“测不清”，不能判通过。
4. **分清底座动还是长臂滑。** 给底座和长臂分别设参照线，对固定背景拍照或测位移，记录两者相对变化。100 mm处0.3°约相当于0.52 mm位移，可用于理解所需测量分辨率，不能替代误差核算。
5. **摆动手感。** 测开始转动和匀速转动所需的力，并记录操作位置。不同预紧分别比较；更能保持不代表更好操作。
6. **松动与磨损。** 给螺钉头做见证标记；多次往返后复查螺母、表面、孔径、夹紧高度和保持能力。出现裂纹、明显变形或突然滑脱即结束该样品试验，保留记录。

若单点小样效果好，下一步才是带两个摩擦点的完整打印核心测试，包括不均匀分担载荷、反向空程和紧固件松动。小样合格不能直接放行整机。外侧转动座、胸肩连接架、电子器件与线束也不能用小样结果代替。

## 本轮可追溯来源

- [ToddlerBot论文](https://arxiv.org/html/2502.00893v3)与[作者物料表](https://hshi74.github.io/toddlerbot/hardware/01_bill_of_materials.html)：打印主体配现成轴承/紧固件的案例。它的主动驱动不能证明我们的被动保持能力。
- [Bambu PLA-CF](https://us.store.bambulab.com/products/pla-cf)：材料与耐磨喷嘴要求。
- [NBK轴肩螺钉目录](https://static.nbk1560-chn.com.cn/images/zh-CN/product/adjustbolt/SBSM/SBSM_1.pdf)：本轮选用的目录规格。
- [嘉立创FA垫圈尺寸表](https://static.jlcfa.com/Serial/E06/EPDA/542502462063341570.pdf)：两种大垫圈与普通平垫圈。
- [瑞力碟簧](https://www.raleigh-spring.cn/discspring/list_84_2/)：弹簧目录参考。实际选购和力—位移仍需核对。

这轮没有采购、打印或硬件测量。所有3D打印文件都是塑料结构件，不是要求家用打印机打印铝或钢。

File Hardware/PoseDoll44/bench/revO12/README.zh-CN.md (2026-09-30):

# O12：按你找到的淘宝零件制作测试小样

本页对应 **6 mm 螺纹轴肩螺钉**和用户提供的垫圈、碟簧、螺母及连接螺钉。先制作独立小样，不是完整人偶。

## 先用哪个文件

- [新版小样 3MF](print_beds/O12_taobao_bench.3mf)：底座两半和长臂，共 3 个塑料打印件，单位 mm。
- [底座后半 STL](print_beds/printed_base_minus_on_bed.stl)。
- [底座前半 STL](print_beds/printed_base_plus_on_bed.stl)。
- [长臂 STL](print_beds/printed_lever_on_bed.stl)：几何沿用 O11；已经打印且尺寸正常时可以复用。
- [动画指南](../../tutorials/taobao-bench/index.html)：旋转、拆开、高亮本版零件。
- [空白记录表](measurement_template.json)：填写实际测量结果，不会自动判定硬件合格。

**底座两半必须一起使用 O12 文件，不混用旧版半件。** 3MF 只有几何与建议摆放，没有 G-code、机器配置或已验证的支撑。

## 为什么改底座

原来的 7 mm 螺纹参考件改为你可以买到的 6 mm 螺纹件。内部螺母及其承压垫圈的座，整体向螺钉头移动 **1 mm**；底座外形仍为 50×30×8 mm，长臂不变。

以底座背面为 z=0、正面为 z=8：
- 螺母原位置 1.0～3.4 mm，新位置 **2.0～4.4 mm**。
- M3 大垫圈原位置 3.4～4.2 mm，新位置 **4.4～5.2 mm**。
- 在两片碟簧总高 1.10、1.00、0.90 mm 时，6 mm 螺纹伸过螺母的名义余量分别为 **1.10、1.20、1.30 mm**；原底座分别只有 0.10、0.20、0.30 mm。
- 打印承压台阶由 3.8 mm 变成 **2.8 mm**。这提高了螺纹覆盖余量，但不能宣称提高了底座强度。台阶变形与持续夹紧后的松弛是本版必须观察的现象。

几何按名义尺寸计算，没有得到淘宝批次的加工公差或打印误差。螺钉端部倒角、螺纹根部退刀区都可能减少有效啮合。敏感性计算使用的是明确标注的假设范围，不是商家承诺的公差。

## 买这些金属小件

| 零件 | 小样用量 | 你找到的规格 | 到货先看什么 |
|---|---:|---|---|
| 轴肩螺钉 | 1 | 304；光杆 Φ4×8，M3×0.5 螺纹长6，头径7、头高3 | 用 3 mm 内六角扳手；记录肩长、螺纹长和端部倒角 |
| M4 大垫圈 | 2 | 外径12、厚1，商品标称孔4 | 每一片能否轻松滑过光杆 |
| M4 普通平垫圈 | 1 | 外径9、厚0.8，商品标称孔4 | 能否轻松滑过光杆 |
| M3 大垫圈 | 1 | 外径9、厚0.8，商品标称孔3 | 能否直接穿过 M3 螺纹段，不靠旋拧 |
| A8 碟簧 | 2 | 不锈钢；外径8、孔4.2、料厚0.4、自由总高0.6 | 钢号和弹力未知；检查自由高度及卸载后是否恢复 |
| M3 普通六角螺母 | 3 | 对边5.5、厚2.4、牙距0.5 | 一颗放内部，两颗连接底座；先与对应螺钉试拧 |
| M3×35 圆柱头内六角螺钉 | 2 | 304；头下长35，头径5.6、头高3、牙距0.5 | 使用 2.5 mm 内六角扳手 |

另备 5.5 mm 扳手、卡尺、能同时固定底座两半的夹具、细绳/小挂钩、可以称量的小重物。仅采购小样所需的试验数量即可，不按这份清单购买整机数量。

## 打印前，先做三项金属件试装

1. **两种 M4 垫圈分别套到轴肩螺钉上。** 先穿过细螺纹段，再推到 Φ4 光杆段。用手轻推就应能滑动，不靠敲打、钳子或拧紧来压过台阶。
2. **M3 大垫圈只套过细螺纹段。** 它本来就不需要越过 Φ4 轴肩；能够直接穿过 M3 螺纹即可。如果必须像螺母一样旋拧才能通过，不作为这个小样的平垫圈使用。
3. **螺母分别试拧。** 先在底座外检查 M3 螺母与轴肩螺钉、M3×35 螺钉配合正常。碟簧孔也应能套过光杆，先记录自由高度；少量压缩后的回弹检查留到小样装好后进行。

商品写“M4 / M3”经常是配用螺钉的公称规格，实际孔径可能略大。**4.3 mm / 3.2 mm 孔径的垫圈确实存在**，可见[嘉立创 FA 尺寸表](https://static.jlcfa.com/Serial/E06/EPDA/542502462063341570.pdf)。但不需要凭标题反复换货：先对这批做上述实际试装，并记录结果。

如果实际孔恰好等于轴径，模型没有体积穿插也不表示一定能滑动。修改塑料孔不能扩大金属垫圈孔。某片卡住时，先换一片试；同批都不能通过，再换实际孔径有余量的成品垫圈。本版不要求新手用钻头夹持加工小垫圈，也不通过磨细光杆来迁就它。

## 打印和装配

首轮仍用 PLA-CF 作候选；普通 PLA 可以做低载装配练习，结果需分开记录。按耗材厂家选择适配的喷嘴、温度和机器配置。沿用 O11 的试验起点：0.2 mm 层高、6 道外壁、100% 填充、5 层顶底面。它们是固定试验变量的选择，不是强度已经达标的证明。

底座分合面朝打印平台，长臂平放。先检查切片中螺母座、垫圈座与孔边是否成形、支撑是否可从分合面清除；这些文件尚未在你的打印机上切片或试打。打印中心导向孔仍为名义 **4.25 mm**，没有为了“适配4 mm垫圈”而缩小。

装配顺序：

1. 分开底座，将一颗 M3 螺母放入六角槽，M3 大垫圈放入相邻圆槽；圆垫圈朝长臂一侧。
2. 合上底座，用两颗 M3×35 螺钉和外侧螺母连接。先看分合面闭合、内部零件不歪，再均匀紧固。
3. 正面依次装 **M4 大垫圈 → 长臂 → M4 大垫圈 → 两片反向碟簧 → M4 普通平垫圈 → 轴肩螺钉**。
4. 用 **3 mm** 内六角扳手慢慢旋入轴肩螺钉。不要因为“还能拧”就一直拧到底；用弹簧压缩状态和实际手感控制，拧紧扭矩不能直接当作轴向力。
5. 同时夹住底座两半，让转轴水平、长臂在竖直面摆动。先空载，确认没有卡滞、摩擦异常、分合面张开或松脱，再挂小重物。

## 不锈钢碟簧怎么试

本批只有“不锈钢”材质描述，钢号、状态和力—位移曲线均未知。**O12 没有给这批碟簧指定 210 N 弹力。** 两片反向串联增加行程；不能因为有两片就把某个单片力值翻倍。

先量单片自由高度和厚度。小样装好并固定后，缓慢调整螺钉使碟簧少量压缩，再松开卸载，查看是否回弹。确认不是已经压平、变形或装反。1.10、1.00、0.90 mm 的总高只是几何参考点，不是必须达到的拧紧目标，也不对应已经确认的夹紧力。测不准就记录“未测得”；不要继续拧紧来追求某个高度，更不要压平两片碟簧。若实际自由高度与0.6 mm不同，不能照搬上述压缩量。

保持试验从 **20 g左右的小挂重**开始，逐级增加。小样的初始筛选目标仍约 **0.20 N·m**；100 mm 实际垂直力臂约对应200 g挂重，但还必须加上长臂、挂钩、绳子的自重力矩。这个目标不是已验证能力，若出现异常不继续加重或强行加预紧。

记录正反方向的：
- 60秒、600秒、3600秒，之后再做24小时停留。
- 底座与长臂分别相对背景的位移，避免把底座挠曲当成长臂滑动。
- 开始摆动和持续摆动的力；转动是否顺滑。
- 螺钉见证标记、分合面、内部承压台阶附近有无变形，碟簧卸载后是否恢复。

0.3°仍只是初始漂移筛选值；100 mm处约为0.52 mm位移。测量误差接近它时应记“测不清”。开裂、明显变形、突然滑脱、碟簧永久塌陷或螺钉异常松动时结束该样品试验，保留记录。

## 本轮数字检查的范围

- 15件小样均为单一、有效的名义实体。
- 四种碟簧总高：1.20（自由高度参考）、1.10、1.00、0.90 mm；每种105对零件检查，无所检正体积穿插。
- 长臂在每种高度下以5°步长抽样，共292个状态，无所检穿插；不是连续运动公差认证。
- 内部螺母、垫圈的装入和半件闭合路径以0.5 mm步长检查；有承压台阶阻挡向外脱离。
- 3 mm直工具杆的外部空间检查通过；没有认证扳手手柄、套筒深度或手指空间。
- 3MF与STL导出回读、单位及打印摆放检查完成；未实际切片、打印、测量保持力或验收强度。

本版只修改独立小样；O11双轴核心、完整肩部及原来的整机未完成项没有由本次结果获得放行。

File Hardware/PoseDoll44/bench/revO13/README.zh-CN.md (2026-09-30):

# O13 双轴核心试装说明

这是下一阶段的四件打印主体与标准件试装包，用来验证两个转轴同时工作时的配合。当前 O12 长臂小样已经收到“装配与初步手感通过”的用户反馈，仍用于补充负载和停留记录。

本包包含 C01、C02 两个叉架，以及 C14、C15 两个承力环半件。它不包含外侧扭转座、传感器、连接架或人偶全身。

## 打印文件

- `print_beds/O13_core_fit_only.3mf`：四个主体的几何摆放，单位 mm；没有机器配置和 G-code。
- `print_beds/C01_on_bed.stl`、`C02_on_bed.stl`、`C14_on_bed.stl`、`C15_on_bed.stl`：逐件文件。
- 查看器：`http://127.0.0.1:8769/tutorials/full-doll/index.html`，选择“双轴核心”，拖动 α、β 滑块。

先沿用本次实际成功打印的耗材和工艺，并向服务商记录其名称与参数。当前反馈还没有这些数值，因此本轮没有声称某种材质已经通过实测。模型中的摆放需要服务商逐层查看孔、台阶及支撑，尚未执行实际切片。

## 所需标准件

| 零件 | 数量 | 对应尺寸 |
|---|---:|---|
| 轴肩螺钉 | 4 | Φ4 × 8，M3 螺纹长 6 mm，头径 7、头高 3，3 mm 内六角 |
| M4 大垫圈 | 8 | 外径 12、厚 1，同现有小样 |
| M4 普通垫圈 | 4 | 外径 9、厚 0.8，同现有小样 |
| A8 碟簧 | 8 | 外径 8、内径 4.2、厚 0.4，每处两片反向，现货不锈钢 |
| M3 螺母 | 4 | 对边 5.5、厚 2.4 |
| M3 大垫圈 | 4 | 外径 9、厚 0.8 |
| 承力环合拢螺钉 | 4 | 参考 M1.6 × 6，头径 3、头高 1.6，商品尺寸待核对 |
| 承力环合拢螺母 | 4 | 参考 M1.6，对边 3.2、厚 1.3，商品尺寸待核对 |

除了最后两种环合拢紧固件，其余沿用已经安装成功的小样规格。先核对 M1.6 商品尺寸，再决定这份核心试装的采购；没有要求购买定制金属件。

## 装配顺序

1. 在环半件内放入四处 M3 螺母及其反力大垫圈，再放入环合拢螺母。螺母应坐进对应六角槽，反力垫圈坐进圆形台阶。
2. 合拢 C14 与 C15，用四颗 M1.6 螺钉连接。检查接缝贴合、内部标准件没有翘起。
3. 放入两片叉架。每侧从环向螺钉头方向的顺序为：M4 大垫圈 → 打印叉架耳 → M4 大垫圈 → 两片反向碟簧 → M4 普通垫圈 → 轴肩螺钉头。螺纹进入环内 M3 螺母。垫圈朝向和碟簧叠法沿用当前成功装好的小样。
4. 初始只给小预紧。逐侧小幅调整，确认左右两端能共同工作，再移动另一个转轴。调整目标是顺滑且能保持合适阻力，不是拧到尽头。

模型沿用了现货 6 mm 螺纹和 3 mm 内六角，内部反力台阶厚 2.8 mm。垫圈的图示公称孔径与批次实测公差仍未混为一谈；已有的一件成功装配支持复用该批零件。

## 本次真正要观察的事情

| 观察 | 怎么做 | 记录什么 |
|---|---|---|
| 双轴是否顺畅 | 先固定一个轴，转动另一个轴；再交换，最后同时小幅改变两轴角度 | 是否有突然变紧、卡住、刮碰或明显跳动 |
| 对侧预紧是否互相影响 | 每次只调一侧螺钉，然后转动对应轴与另一个轴 | 哪一颗螺钉改变了哪根轴的手感 |
| 环与叉架是否松动 | 从两个方向轻推同一位置，并观察环接缝、轴孔和叉架端部 | 可见位移、异响或反向空程，最好附视频 |
| 停留是否漂移 | 在一个容易观察的角度放开，按同一负载先看 1 分钟，再看 10 分钟 | 角度是否变化；是否需要重新调整 |

这些观察还没有发生。本轮小样通过，不能代替双轴核心的实测。手托人偶被允许，因此“不足以完全自保持”本身不再使方案失败；卡滞、裂纹、松脱以及无法获得有效角度读数仍需解决。

现有长臂小样的定量记录可先做：保留同一夹持位置，记录已知负载质量、转轴到负载重心的水平距离、停留时间和是否下滑。角度不为水平时不要直接把长臂总长当成重力力臂。当前 A8 弹力未知，本项目没有把旧目录 210 N 数值套在这批不锈钢碟簧上。

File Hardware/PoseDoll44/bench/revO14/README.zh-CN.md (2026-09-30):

# O14 双轴核心试件

请直接打开 `PRINT_ORDER.zh-CN.html`，或访问 http://127.0.0.1:8769/tutorials/core-print/index.html 。HTML 已声明 UTF-8，包含支撑图、数量和装配测试步骤。

`O14_core_supplier_review.zip` 可发给服务商；里面是独立 HTML 与四件几何文件，不包含可直接上机的 G-code。C01/C02 必须启用支撑。几何 3MF 本身不保存支撑设置，请在真实机型/材料配置里重新切片。

本轮只改四件打印主体的摆放，没有改它们的机械尺寸。现有长臂小样继续保留；新试件用于双轴配合测试。M1.6 合拢螺钉和螺母商品尺寸未确认。零件说明中列出的切片参数是诊断起点，不是已通过实物试验的制造配置。

`generic_diagnostic_NOT_MACHINE_PROFILE.ini` 仅供复核本轮 PrusaSlicer 诊断，不应当作为 A1/P1S 的设备配置导入上机。

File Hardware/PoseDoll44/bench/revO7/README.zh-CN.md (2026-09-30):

# Rev O7 小样台架任务书

当前先制作材料试片并测碟簧，不建议制作整个人偶或直接按 LP6 总装 STEP 下单。LP6 是研究装配，生产螺纹、公差、紧固件强度、工具配合和受载变形尚未定型。用户尚无硬件，本目录没有实测结果。

## 首批测试件

| 项目 | 建议首批数量 | 要解决的问题 |
|---|---:|---|
| 锐尔立 B 系列 8×4.2×0.3 mm 碟簧 | 至少 6 片，组成 3 对 | 两片对合串联的实际力—高度曲线与组间差异 |
| 锐尔立 A 系列 8×4.2×0.4 mm 碟簧 | 至少 12 片，组成 3 组四串 | M4 当前组合的实际曲线，确定锁骨轴是否有足够保持力 |
| LP6 接触尺寸的未填充 PEEK 试片 | 至少 3 片，接触区 ID12 / OD28 / 厚0.6 mm | 大接触环的静摩擦、低速起动与停留变化 |
| M4 接触尺寸的未填充 PEEK 试片 | 至少 3 片，接触区 ID5.2 / OD14.8 / 厚0.4 mm | 小接触环能否覆盖约0.304 N·m 的双面保持预算 |
| 两种尺寸金属对偶试片 | 每种至少 1 件 | 使用可追溯牌号和表面加工；其结果只适用于该材料配对 |

[试片 STEP 与尺寸表](coupons/) 包含四个研究实体。外耳用于试验夹具在摩擦区外固定塑料片；金属件安装孔用于实验室夹具。**这里没有完整的测力/测矩夹具设计**，需要加工方或实验室确认装夹、实际尺寸、平面度、金属牌号和表面工艺后再加工。当前关节 CAD 的 `steel` 只是密度分类，不代表已经选定生产钢号。

锐尔立 B8 的目录点为118 N、自由高0.55 mm；目录 Ht 显示0.36 mm，模型使用由75%锥高压缩计算的0.3625 mm。三组理想并联才得到354 N。它不是最大力，也不是已校准的整关节预紧力。[锐尔立官方目录](https://www.raleigh-spring.cn/discspring/)

PEEK 先作为可测的候选。原厂页面给出的摩擦系数来自特定 ASTM 条件，不能直接代入本关节。[Ensinger 原厂材料数据](https://www.ensingerplastics.com/en-us/shapes/peek-tecapeek-natural)

## 台架 A：弹簧曲线

1. 给每片弹簧和每组组合编号，测实际厚度、自由高度、内外径，记录批次与方向。
2. 使用经过校准、适合该力级的压缩测力装置。先测单片，再测对合组合，记录加载和卸载曲线以及重复后的变化。
3. 工作行程依据实际锥高和厂家允许范围确定。**不得仅按模型里的固定高度或螺纹转数推定安全压缩量。** O7 向下取整只约束名义补偿，不是硬件机械限位。
4. 记录组合在预期工作附近的力、回差和组间偏差。三组高度相同不等于三组力相同；这些数据用于后续压力板、导向与紧固件计算。

原始记录使用 `spring_curve_template.json`，保留仪器导出文件。该模板没有填入目录点冒充测量值。

## 台架 B：单面摩擦试片

实验室用校准夹具固定外耳、控制真实法向力，测单面起动扭矩。先测并记录夹具自身阻力；金属对偶牌号、表面加工、塑料批次、温度和实际尺寸必须随记录保存。

在数个真实预紧力下，每个方向至少重复3次，记录起动扭矩和60秒加载停留后的角度变化。可先从低载荷开始，再依据夹具、材料和已测弹簧范围增加。测量值使用 N、N·m、秒、度，不能把单面测量当作双面实测。

`plan.json` 由当前逐件重心载荷报告生成：LP6 最苛刻悬空臂保持预算约0.463 N·m，M4 约0.304 N·m。60 mm 手持力臂、20 N 操作力和0.3°停留漂移仅为**暂定的台架筛选线**，不是用户已确认的最终手感/精度标准。抬起手臂的力包含重力与摩擦。

同一预紧设置中法向力实测范围不得超过均值的5%，才能作为同组初筛；仍须保留原始数据。重复次数不是寿命试验。两面等效推算通过后，也只能进入单关节测试。

## 数据入口

填写 `measurement_template.json` 中的 `samples`，每条记录使用唯一 `sample_id`，保留相对路径和仪器日志 SHA256。脚本会拒绝合成/目录数据、缺少批次/校准编号、非法数值、重复记录、路径越界、日志被改写及不匹配的计划哈希。

在设计仓库根目录执行：

```powershell
.venv/Scripts/python.exe -X utf8 scripts/analyze_revo7_bench.py --plan Hardware/PoseDoll44/bench/revO7/plan.json --data Hardware/PoseDoll44/bench/revO7/measurement_template.json --out Hardware/PoseDoll44/verification/revO7/runs/o7_20260924_r1/bench_measured.json
```

空模板返回 `AWAITING_HARDWARE`。软件测试用例全部是合成数据，不是实测。即使录入结果满足初筛，脚本也不会设置整关节合格或制造放行；文件哈希只能证明记录未变，不能证明实验真实性。

## 测完以后再做什么

用实测静摩擦范围和弹簧曲线确定各轴预紧窗口。如果能同时保持姿态和轻松调整，再完成单关节生产图、力路/螺纹/螺钉强度及限位，然后做受载滑动、三组力不均、正反向加载、轴承基准变化与反复摆姿测试。再据此设计肩锁骨共同支架、完整 PCBA、线束和全身联合动作。

背部中央采集方案另需 AS5048 链路的实际波形、断链/重放识别和峰值供电验证。48×48×12 mm 是已检查的空盒空间目标，尚无相应的中央 PCBA。O6 的 DC1 仍是隔离实验，不能据此改成生产采集架构。

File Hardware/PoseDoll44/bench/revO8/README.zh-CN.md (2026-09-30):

# O8 首批配合小样：给第一次做机械的人

目前没有实物结果。本轮先验证打印配合，不要求你先购买整套人偶零件或测矩设备。

## 第一步：把 A_first_fit 给打印方

建议用同一批次的未填充 PA12，SLS 工艺，不涂装、不润滑。供应商需确认实际牌号、最小细节、清粉/喷砂工序和摆放方向。候选服务包括 [嘉立创](https://www.jlc.com/portal/q7i27832.html)；2026-09-25 核对其规范，100 mm 以内的尼龙公开尺寸精度为 ±0.3 mm，这不足以直接保证原始细小轴孔配合。报价、接受订单和实际尺寸承诺尚未确认。

| 文件 | 数量 | 用来做什么 |
|---|---:|---|
| hole_gauge_Z.stl / STEP | 1 | 轴线沿 Z 的五个孔，名义 Ø4.0 / 4.2 / 4.4 / 4.6 / 4.8 mm |
| hole_gauge_Y.stl / STEP | 1 | 相同孔径，换一个打印方向；要求打印方保留方向差异并记录 |
| pin_D4.stl / STEP | 3 | Ø4、直段长 12 mm 的打印轴，底部圆柄用于轻推和转动 |
| fastener_gauge.stl / STEP | 1 | 检查金属螺钉能否穿入、螺母是否能放入并止转 |

共 4 类文件、6 件打印试片。每个 STL 只有一个独立零件；单位 mm。STEP 与 STL 是同一件的两种格式，不要重复计数。缺口标记编号起点；从缺口端开始数孔。

`B_core_reference` 只提供下一阶段核心参考件，**不计入首批量规订单**。若首批配合不合适，先调整工艺或配合尺寸；不能把试片中“最大的孔”直接套用到所有关节。

## 第二步：准备少量标准件

- M1.6 × 6、螺距 0.35 mm 的内六角圆柱头螺钉，6 件。名义头径 3 mm、头高 1.6 mm，1.5 mm 内六角工具。
- M1.6 六角螺母，6 件。名义对边 3.2 mm、厚 1.3 mm，螺距同为 0.35 mm。
- 1.5 mm 内六角工具、分装盒、标签、拍照工具。已有卡尺可作初检；精细孔径和实际间隙优先让加工/检测方测量。

这些是金属标准件，不是打印件。可向国内紧固件供应商按完整尺寸询价，先核对实物与包装；尚未声称某家有库存或报价最优。尺寸依据：[HPC 螺钉目录](https://shop.hpceurope.com/pdf/gbPDFauto/CHC.pdf)、[万千紧固件螺母尺寸表](https://www.wqjgj.cn/product/luomu/liujiao/4147.html)、[Fastenright 微型螺母目录](https://www.fastenright.com/general-fixings/micro-hexagon-fullnuts-din-934/mf06)。实际供货规格变化需要复核。

## 第三步：先记录原状，再试配

1. 给三根轴编号 P1 / P2 / P3，两件孔片编号 Z / Y。拍照保留缺口、打印纹理和订单材料。记录日期、材料牌号、批次、打印方向和后处理；不要先打磨、扩孔或润滑。
2. 从缺口端的 1 号孔开始，用手指轻轻推轴。每根轴都试两件孔片的五个孔，共 30 个配合组合。不要敲击或借助螺钉强行压入。
3. 每个组合写：`进不去`、`能进入但卡`、`能轻转` 或 `明显晃动`。若有卡尺，测轴的两个方向及两处位置；孔径不易用普通卡尺精确测量，注明测量工具与不确定性。
4. 螺钉螺母试片从缺口端数 1～4 号。通孔分别是 Ø1.8 / 2.0 / 2.2 / 2.4 mm；螺母槽对边分别是 3.3 / 3.5 / 3.7 / 3.9 mm。先把螺母放进对应凹槽，再从另一面轻轻旋入螺钉。分别记录是否能穿入、坐平、拧动时是否带着螺母空转。
5. 较大的螺母槽可能放得进，却失去止转作用；这种情况不要判为“通过”。记录裂纹、白化、明显变形或不同样件差异，停止继续施力。

`measurement_template.json` 是空白辅助记录。你也可以直接提供照片和按上述编号填写的文字；无需先学习 JSON。没有任何预填的实测值或自动制造放行。

## 配合数据回来之后

先决定孔轴与螺母槽的工艺补偿，再打印四件核心小样。当前已生成各加长 2 mm 的两只叉架和上下半环；它们名义上可以分段装配，但打印后仍须验证。

核心装配先只用低力检查进出、正反向松动和是否卡滞。不用挂重物直接试“能承受几公斤”。保持扭矩与起动阻力需要夹具与测量；当前未完成专用测矩夹具设计，也没有合格预紧扭矩。不要把螺钉转数当成预紧力。

后续要测两方向的起动/运行扭矩、正反向空程、不同角度的保持、60 秒停留漂移以及重复后的变化。60 秒是暂定筛选时间，不是寿命认证。应先确认实际样件与可用夹具，再确定加载范围。旧 LP6 约 0.463 N·m 是旧负载预算，不能冒充新核心的能力或新整机要求。

## 观看与来源

[离线动画指南](../../tutorials/tut-prototype/index.html) 展示真实 STL 与装配顺序；[设计结果](../../docs/O8_TUT_PROTOTYPE.zh-CN.md) 区分了通过的数字范围、失败组合和待测项。

核心来源固定到 [atamid 9a152b1](https://github.com/oliglauser/atamid/tree/9a152b1d82374d1960ebd2216563fb30b1b6875b/Hardware/Mechanics)。本轮量规由项目独立参数化生成。四件核心是对原 STL 的研究性改型，并非完整原设备或已授权的生产发行包；上游许可与完整发行资料尚需另行核对。

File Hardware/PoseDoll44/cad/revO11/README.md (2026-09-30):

# O11 reproduction

Run from the design repository using `.venv/Scripts/python.exe -X utf8`.
O10 outputs are immutable; every new generator writes only to O11 paths.

1. `Hardware/PoseDoll44/cad/revO11/build_printed_core.py`
2. `Hardware/PoseDoll44/cad/revO11/build_braked_module.py`
3. `Hardware/PoseDoll44/cad/revO11/check_braked_module.py`
4. `Hardware/PoseDoll44/tools/run_cad.py Hardware/PoseDoll44/cad/revO11/continuous_forks.py`
5. `Hardware/PoseDoll44/cad/revO11/clavicle_trial.py --candidate -60,38,10`
6. `Hardware/PoseDoll44/cad/revO11/update_loads.py`
7. `Hardware/PoseDoll44/cad/revO11/build_printed_bench.py`
8. `Hardware/PoseDoll44/cad/revO11/check_assembly.py`
9. `Hardware/PoseDoll44/cad/revO11/export_print_pack.py`
10. `Hardware/PoseDoll44/cad/revO11/summarize.py`
11. Run the local page smoke check, then `scripts/seal_revo11.py` (or `--verify` for an existing seal).

Optional research steps: `audit_reference.py` reads the provided local ToddlerBot
3MF and the public published BOM. `search_layout.py` compares the 16 recorded
layout candidates before the full chosen-layout check. Their results are not
hardware observations. No ToddlerBot part geometry or G-code is copied.

The inherited O9 mesh core and O7/O8 kinematics remain source dependencies.
`build_finite_twist.py` supplies the revised O11 short printed housing concept.
The copied frame helpers preserve the existing convention; they do not establish
anatomical or full-body acceptance. Retained forearm modules are historical CAD
inputs, not automatically converted or approved by this iteration.

Use a new run directory for later changes after sealing. The printed material,
friction, creep, full torso/carriers/electronics/wiring and one explicit Quinn
pose collision remain unqualified; see the Chinese design report.

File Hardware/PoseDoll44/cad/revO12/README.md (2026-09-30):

O12 independent coupon only. Run build_taobao_bench.py, then prepare_page.py, inspect the local taobao-bench page, and seal with scripts/seal_revo12.py. Sealed O11 is immutable; O12 does not re-certify its core or full-body geometry. Unknown washer fit and spring force remain explicit.

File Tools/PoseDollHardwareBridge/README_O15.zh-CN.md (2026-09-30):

# O15：46原始角度 → UE静态姿势

这是O15完整数字样机对应的新桥接入口：`o15_bridge.py`。旧O5/PD41工具继续保留，不能互换线协议。

先完成 `Hardware/PoseDoll44/bench/revO15/guide.html` 的电子配对和物理标定。默认BODY/G0固件对端MAC为零，禁止直接拿默认构建作为已配对硬件。BODY与G0用真实MAC生成各自的defaults，使用新的绝对BuildRoot编译。

从本仓库根目录运行一次诊断（COM7只是示例，换成实际G0端口；每次日志文件名必须不同）：

```powershell
.venv/Scripts/python.exe Tools/PoseDollHardwareBridge/o15_bridge.py --ue-root E:/UnrealProjects/DollSimulation --serial COM7 --mapping Hardware/PoseDoll44/generated/revO15/runs/o15_20260929_r1/raw46_mapping_candidate.json --wiring Hardware/PoseDoll44/generated/revO15/runs/o15_20260929_r1/raw46_wiring_candidate.json --diagnostic --log .local/o15_diagnostic_001.jsonl
```

诊断只输出原始扫描，不发布有效全身姿势。用它检查46个编号、方向、静态噪声、断线/掉电。零位和方向必须实测；CAD参考不是实测标定。

完整硬件标定完成后，将INCOMPLETE模板另存为 `raw_calibration_MEASURED.json`，填入真实BODY device id、46轴实测zero_deg/sign和证据。五个physical_tests必须是已经实际完成的项目；没有完成的保持false。不要为了让连接成功填假值。

```powershell
.venv/Scripts/python.exe Tools/PoseDollHardwareBridge/o15_bridge.py --ue-root E:/UnrealProjects/DollSimulation --serial COM7 --mapping Hardware/PoseDoll44/generated/revO15/runs/o15_20260929_r1/raw46_mapping_candidate.json --wiring Hardware/PoseDoll44/generated/revO15/runs/o15_20260929_r1/raw46_wiring_candidate.json --raw-calibration Hardware/PoseDoll44/bench/revO15/commissioning/raw_calibration_MEASURED.json --log .local/o15_capture_001.jsonl --port 39178
```

桥接器监听本机127.0.0.1:39178，供已有UE静态采集功能连接。41个测量语义轴+3个固定骨盆轴；六条链共用一个物理BODY。完整性、CRC、boot、请求身份、扫描年龄、标定绑定仍必须通过；降低采集频率不允许把缺失/故障填成正常角度。

当前真实运行过的是64项桥接测试和合成PDG15→生产BridgeCore→实际UE的正常/缺失/CRC/boot用例。没有真实ESP32、AS5048、USB或无线采集结果。

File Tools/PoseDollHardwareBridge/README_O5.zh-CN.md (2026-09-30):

# O5 静态硬件桥接

A 拓扑的请求式 PDG5/1 → PDS1/1 桥接，与此目录旧 PD41 诊断/标定脚本并存。没有读取 PD41 周期缓存或把旧数据重新标成请求后采样。

数字测试已覆盖 native C 编解码向量、完整轴序、缺失/故障、启动身份、CRC、请求/扫描顺序、取消迟到和字节拆包；真实 UE 联调使用 **simulated** 原始 PDG5 字节。串口生产入口仅在打开实际串口后标记 **hardware**。该标记只说明数据来源，不能证明校准、机械精度或制造合格。

## 日后台架入口（本轮无硬件，未执行）

```powershell
python -m pip install -r Tools/PoseDollHardwareBridge/requirements-o5.txt
python Tools/PoseDollHardwareBridge/bridge.py --ue-root E:/UnrealProjects/DollSimulation --serial COM7 --diagnostic --log bench_new.jsonl
```

`--diagnostic` 请求一轮原始采集并输出缺失/故障，不发布 PDS1 FullBody hello。单轴、九轴台架使用此模式。输出日志必须是新文件，含方向、主机单调时钟和原始字节。COM7 是示例，不会由脚本自动选择/烧录设备。

41 个端口和 6 个节点具备条件后，省略 `--diagnostic` 可建立 loopback 39178 上的 UE 静态连接。仍要求所有读数完整有效，CRC/boot/profile/calibration/固定根槽/扫描年龄均通过。UE 端 500 ms 稳定窗口与一次性写入策略保持。

**当前 UE Shared 的 virtual profile / zero-pi 是软件参考，不是人偶实物标定。** 原始台架读数可以验证通信；具有物理意义的 Capture 必须先完成同一拓扑的零位、符号、传动比、真实轴偏置标定，并让两端加载同一审核后的 profile/calibration 文件及哈希。本轮没有生成实体标定，不能把模拟通过解读为角度准确度通过。

运行时上限：1 个活动请求；32 个已结束 ID，30 s 寿命；每连接最多 4096 个请求 ID；PDG5 收包最多 32 帧，残帧 500 ms 超时；3 s 采集截止。已知迟到回复仍先检查 CRC/身份/状态，再丢弃；未知 ID 和故障不会因“可能是旧包”被忽略。

## 数字复现

```powershell
$env:POSEDOLL_UE_ROOT='E:/UnrealProjects/DollSimulation'
python -m pytest Tools/PoseDollHardwareBridge/tests -q
```

`tests/pdg5_golden.bin` 是本轮主机 C 测试导出的 220 字节向量；独立 Python 解码并逐字节回编匹配。`layout.json` 检查全部 44 个槽，不仅检查数量。

`synthetic_ue_peer.py` 与 `run_ue_bridge_o5.py` 用于隔离 UE 项目的真实 TCP/Capture 联调，需设置 `POSEDOLL_DESIGN_ROOT`、`POSEDOLL_TEST_PYTHON`，并以 UnrealEditor-Cmd 的 ExecutePythonScript 运行后者。它会创建测试资产，应仅用于独立测试项目。正常输入写入一次；missing、CRC、boot 三种错误均写入零次。没有串口、ESP32 或 AS5048 的执行证据。

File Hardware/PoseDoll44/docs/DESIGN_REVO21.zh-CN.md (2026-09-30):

# O21：约 1500 元的单台 USB 测姿人偶

O21 的选择是：**保留 O20 关节和骨架，改用 MT6701CT-STD-R，重新设计采集板与预制线束。** 一台人偶输出全部 46 路机械测量，经过原有运动学得到 41 个语义自由度，由 UE 目标适配保持人物自己的骨长。身体自由度不删减，不增加电机、摄像头或接触修正。

本版是可审查的降本工程设计：有原生电路、通道绑定、可编译固件、主机解码与测试，**不是已完成实物验证的整机制造包**。中央板还需布局布线，新器件/线束/控制盒还需装配集成；成本是采购约束而非供应商报价。

## 预算口径与结论

按用户确认口径：已有打印机、自己打印与机械总装；电子板和线束委托加工；一套必须付的最小订单、工程费、必要备件、运费都要计入。用户自己的打印、组装和标定时间不计人工费。精密仪器购买、外包计量和多轮开发失败不属于这份单套预算。

**目标分配 ¥1482.50，约 ¥1483。** 已包含两块完整备用传感板、两片贴片损耗/备用芯片及 ¥100 杂费预留。当前没有供应商正式报价。若各项均落在文件中较贵的情形，总额约 ¥2210；这不是统计置信区间，也不是“保底上限”。1500 元有设计上的可能性，现阶段尚未证实能按此价格购齐。

| 成本项 | 单套目标/元 | 包含内容 |
|---|---:|---|
| MT6701 芯片 | 362.50 | 50 片：46 使用、2 完整板备件、2 贴片损耗/余料 |
| 48 块传感板加工 | 180 | PCB、无源件、单面 SMT、工程/钢网/分板、电测 |
| 中央采集载板 | 130 | PCB、3 个选择器、缓冲、连接器、贴装及工程费 |
| USB 主控 | 55 | XIAO ESP32-S3 普通版及排针装配 |
| 电源及保护 | 35 | 5V 转 3.3V、保护和加工；与载板报价分账 |
| 金属标准件 | 215 | O20 螺钉、肩轴、垫片、碟簧、螺母及备件/取整 |
| 磁铁 | 45 | D6×2.5 径向充磁，46 使用＋5 备件 |
| 预制线束 | 180 | 48 套，板端焊接、压接、插头、标号和导通检查 |
| 打印耗材 | 80 | 买 1kg，含支撑、通常损耗和控制盒材料额度 |
| 附件与运费 | 100 | 5V 2A 适配器、USB 线、扎带胶、简单标定夹具材料 |
| 杂费/差价预留 | 100 | 不代替上面任何必需项目 |
| **合计** | **1482.50** | **预算分配，待实际含税到手报价替换** |

公开依据是 [LCSC C3003196](https://www.lcsc.com/product-detail/C3003196.html)：2026-09-30 读取的 MT6701CT-STD-R，30+ 为 $1.0355/片；50 片 $51.775。按预算假设 7.00 元/美元约 ¥362.43。这个汇率不是即期报价，美元目录价也不是国内含税包邮价。不能套用 100/1000 片阶梯。其他费用均为询价目标，没有伪装成已经拿到的价格。

报价较高时，先查两种 PCB 的工程最低收费、单面贴装、拼板最低数量、尾线加工和肩轴采购。不得用删自由度、廉价未校准传感器或转嫁精细焊接劳动的办法“凑够 1500”。

## 从核心功能倒推零件

核心链路是：关节实际转动 → 编码器原始数值 → 方向/零位/非线性标定 → 机械正向运动学 → UE 的参考姿势与坐标变换 → 可编辑人物姿态。

电机、减速器、电池、无线节点、摄像头、目标接触识别都不是这条链路的必要条件。O20 已经去掉了许多这些负担，继续在杆件上省几克材料，无法抵消每轴较贵传感器和双面小板/FFC 加工的费用。因此，本轮重点转向重复了 46 次的电子部件。

46 路读数不是可以随意删除的冗余：内部四轴关节的转动要一起用于复合方向计算。只给 41 个“人体角度”，却不测量内部轴，可能丢失真实姿态。若以后改成三轴机构，需要重新验证运动范围与相邻干涉，不能作为本轮无代价的减料项。

## 机械保留与新的安装边界

- 一台通用人偶；O20 的参考实体中立高度约 492.14mm，原关节中心、骨架比例保持。
- 双髋各向外 16mm 按用户决定保留；相邻机构仍需避碰，远端肢体接触可通过摆姿规避。
- O11 小样的配合与可调摩擦已由用户报告通过，沿用肩轴/垫片/碟簧，不追加摩擦冗余。
- 磁铁仍为 D6×2.5 径向充磁；不能因外形相同就宣称新芯片磁场与间隙合格。
- 传感 PCB 目标仍为 12×10×1mm。SOP8 封装高度、焊点、五芯出线、应变释放和现有压板需重新做实体包络检查。
- 中央板暂定装在上背部，原控制盒不直接沿用。最终尺寸、固定支架、线束与活动关节的关系尚未完成 CAD 集成；不能把 O20 的无新增碰撞报告当成 O21 的装配证明。

本版不宣称整机更轻或总零件更少。独立支线比级联线更长，可能增加线重；主收益是芯片和加工成本。网页里的 O20 三维模型被明确标作“机械继承参考”，没有把旧 AS5048 板显示成已完成的新设计。

## 电气方案

### 传感板：SOP8、单面贴装、工厂预焊尾线

选定 **MT6701CT-STD-R，SOP8**，不使用旧 O5CN 的 QFN 试验板。原厂 Rev1.8 第 3、24 页引脚为：

| 脚号 | 信号 | O21 接法 |
|---|---|---|
| 1 | VDD | 传感器 3.3V |
| 2 | MODE | 接 VDD，选择 I2C/SSI |
| 3 | OUT | 不连接 |
| 4 | GND | 地 |
| 5 | PUSH | 不连接；SSI 状态仍保留 |
| 6 | DO/SDA | 经 33Ω 到五芯尾线 DO |
| 7 | CLK/SCL | 对应组的 CLK |
| 8 | CSN | 对应组的 CSN，板端 10k 上拉 |

供电旁路为 100nF＋1µF。尾线焊盘顺序：**GND、3V3、CLK、DO、CSN**。板端取消 FFC 座和 FFC 转细线工序，由加工方完成五芯焊接、标识与拉力/导通检查；用户只装机械和插接。

线材与连接器必须作为成套采购：参考 JST SH 5P 板座和对应壳/端子，允许供应商提出有完整规格的同厂配套替代。不能只按“SH1.0”名称混插。30AWG 多股细线是询价起点，绝缘外径、弯曲性能及端子压接范围需供应商确认。

### 中央采集：三组 16 路，只切换数据线

三组分别为躯干/头/锁骨 14 路、双臂 16 路、双腿 16 路。每路 DO 独立进入 CD74HC4067，三个公共输出分别进入主控的三个输入。**不同传感器的 DO 从未直接短接在一起。** 这避开 MT6701 的 SSI/I2C 引脚复用问题；它不是 AS5048A 级联替换。

每组广播 CLK/CSN。主控选择一个 0–15 槽位，最多同时读三路 24 位数据，16 个槽位构成完整 46 路扫描。同一轮里不同槽位的采样并非同一瞬间，因此保留扫描起止时刻和 O20 的 60ms 最大偏斜要求。约 25kHz 的候选软件时钟，纯时钟等待约 15.36ms/轮，不能当作实测总延迟。

XIAO 引脚：GPIO1 使能，GPIO2/4/5/6 选择槽位，GPIO7 时钟，GPIO43 片选，GPIO8/9/44 分别读三组。GPIO3 保留未接，避免改变启动配置；USB 使用芯片原生 USB 引脚。

2×SN74LVC244A 将控制信号送到传感电源域，1×SN74LVC125A 将三个数据输出送回 USB 主控电源域。默认关闭的 OE 和具有掉电隔离特性的缓冲保留，不能为了省几元造成外部供电反灌。

### 供电

原厂给出每片最大 14mA，46 片仅传感器就达 **644mA**，不能把整套传感器接在 XIAO 的 3V3 输出上。USB 为主控供电，外部 5V 2A 为传感器电源供电；共地，但两路 3.3V 和 USB VBUS 不并联。

电源原理图采用 AP3429A 的参考拓扑，2.2µH、电感饱和电流至少 3.5A，反馈 300k/66.5k 得名义约 3.307V。输入反接保护、输入保险与共同的 3.3V 输出保险保留。全部传感器、选择器和输出缓冲在同一保险后供电，断开时一起掉电，避免某组无供电却仍从 CLK/CSN 反灌。输出保险要求 1A、最大冷态电阻不超过 0.15Ω，反馈采样点在保险前。单路故障拒绝整次采集，维修后重新发起，不提供分组带故障自动恢复。具体保险丝型号、导通压降、启动/短路响应、板上温升与纹波需实测，芯片标称“2A”不是本板已经通过 2A 温升验证。

## 精度与坏数据

[MT6701 Rev1.8 原厂手册](https://www.magntek.com.cn/upload/pdf/202407/MT6701_Rev.1.8.pdf)给出 14 位角度、INL 典型 ±1°/最大 ±1.5°。14 位意味着约 0.022°/计数，**不意味着 0.022° 精度**。推荐磁体与当前外形一致，但磁场、气隙及偏心仍必须实测。不能直接复用 AS5048A 的标定文件，也不能预先保证精度等同。

SSI 保存 14 位角度、4 位状态、6 位 CRC；协议同时保存各路空闲高电平检查结果。CRC 错误、异常磁场/失锁/非正常状态、时效过期或缺轴都拒绝本次采集。数值 0 是合法角度，不直接当断线；全零数据配合空闲低会拒绝。CRC 与空闲检查不是所有短路的完备检测，通道接错、CSN/DO 特殊短接等还要靠线束电测、逐轴绑定与已知角度测试排查。

Python 提供周期误差表修正，零位也通过同一误差表计算；原始 USB 包、原始角度、修正后角度和标定版本分别保存。误差表只能来自独立角度夹具的实测，不能用传感器自身读数自证准确。校准拟合点和独立验证点分开；校正固定误差不等于消除回差、松动、噪声或温漂。

O20 的稳定采集条件保留：至少 6 轮、稳定窗口 500ms、峰峰变化不超过 0.5°、最大扫描间隔/数据年龄 120ms。没有为迁就便宜器件而放宽。建议样机先验证每轴全使用角度范围的最大误差 ≤1°、双向重复差 ≤0.3°；这是本轮提出的样机目标，不是已通过结果或旧版已有承诺。不达标则不能宣称“核心测量性能不变”。

## UE 接口

P21R/1 是新的 248 字节协议，保留 46 个 24 位原始字，而不是伪装成旧 P17R/1。O20 固件、六针 FFC 和采集板不能混用。

解码后的关节名称、顺序与机械 FK 保持一致；测试对比 O20 模型确认，同一机械轴角度产生同一骨段变换。因此基础映射的数学关系不因换芯片改变。但 **O20 本身的生产 UE 目标适配与保存/重开验证仍未完成**，O21 没有将这项旧未完成项写成已通过。新的协议需先转换为该测量输出，再由目标适配进入 Manny/Quinn。目标的全局位移、手指、辅助骨和接触美化依然交给 UE。

## 本版文件与验证边界

- budget.json：每项目标、较贵情形、数量、证据类别，网页可现场改价。
- profiles/wiring.json：46 路唯一物理绑定；线长为询价额度，不是生产裁线表。
- mechanical_procurement_O20.json：保留机械物料和备件数量。
- electronics/sensor：原生 SOP8 传感器原理图/PCB 候选与 ERC/DRC 结果。
- electronics/carrier：中央板原生原理图、网表、元件表；尚未布线。
- firmware_source：新 SSI 扫描、P21R 编解码与采集事务，不写芯片 EEPROM。
- source：主机解码、误差表、机械 FK 和测试。
- verification：实际执行的检查；没有实物或 UE 端到端通过记录。
- RFQ.zh-CN.md：可交给加工方的报价要求；本次没有发送询价或下单。

下一步的最小实物验证应是同一 O11 机构上的 **1 块 SOP8 传感板＋已有磁铁＋新读出电路**。先验证已知角度、全使用范围、磁场状态和断线，再扩到完整 16 路组与最远 600mm 支线。新中央板布线/DFM、控制盒与线束相邻避碰随后完成，再装全机做 46 路绑定、原始记录→UE→保存重开测试。O11 的摩擦配合无需重复作为未解决问题。

来源还包括：[CD74HC4067 原厂手册](https://www.ti.com/lit/ds/symlink/cd74hc4067.pdf)、[SN74LVC244A 原厂手册](https://www.ti.com/lit/ds/symlink/sn74lvc244a.pdf)、[AP3429A 原厂手册](https://www.diodes.com/datasheet/download/AP3429.pdf)、[Seeed XIAO 引脚说明](https://wiki.seeedstudio.com/xiao_esp32s3_getting_started/)、[SmartKnob 作者的 MT6701 驱动](https://github.com/scottbez1/smartknob/blob/master/firmware/src/mt6701_sensor.cpp)。协议实现为项目自行编写；SmartKnob 用于核对 CRC 的顺序与公开使用的 SPI 模式，不作为本板的硬件验证。

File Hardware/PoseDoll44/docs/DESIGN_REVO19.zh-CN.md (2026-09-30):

# O19 腿部连接杆对齐优化

O18 已保存为 `08e8f8b`，标签 `posedoll-o18-prototype-20260930`。O18 包含342项带哈希文件，设计包 SHA-256 为 `65e74ea2ee1191e7b7bc30909e66c15424c8b2c1608889a85eba3c7dff7b203d`。O19 独立保存，不覆盖 O11、O16、O17 或 O18。

## 本轮决定

保留一套 USB 测姿人偶，沿用既有 Quinn 比例的实体参考，Manny 与 Quinn 为软件适配目标。仍为46路原始测量、25个物理模块、41个语义旋转自由度、188件打印件和117种打印件。中立数字实体高度492.140 mm。

本轮只替换四件腿部连接架的自由杆段，不增加摩擦副、锁紧机构、传感器或其他零件。所有有效关节中心、角度组成、骨段坐标、零位定义、五金净数量和USB协议保持O18状态。原采集软件与固件继续使用。

## O11 实物报告：已通过

用户于2026-09-30报告：O11独立小样的打印件与实际螺丝、垫片严丝合缝，刚好能装入；长杆的摩擦阻力随螺丝拧紧而增加，拧得很紧时几乎不能转动。

这项结论已接受，不再把O11配合及可调摩擦列为未完成任务，也不因担心保持力增加额外冗余。来源为用户实际试装，见 `generated/revO19/o11_user_validation.json`；没有编造具体扭矩。该证据不等同于O18侧装壳体、O19新杆件或传感器精度的实测报告。O11历史目录中的7mm螺纹和O12以后6mm螺纹的来源记录分别保留，没有擅自推断用户实装的具体批次。

## “整机干涉”具体是什么

整机干涉是两个真实结构件、五金或电子件在某个姿态下占用了同一片空间，实物会相碰，从而无法继续摆到目标角度。它与目标角色皮肤、衣服或道具的穿模是两个不同的问题。

可复现例子：O18中立姿势的 `frame/pelvis` 与 `frame/forearm_l` 相交约1895.939 mm³，即1.896 cm³。这个数是相交体积，不是间隙、距离或穿透深度。O19未修改这两件，此处问题仍在。新网页的“整机干涉示例”用两件实际CAD和其布尔交集高亮展示该位置。

O18此前的24案例报告只检查13件变化连接架与其他零件的相交；本轮报告只检查4件新腿杆与整机其他几何。两者都不能称为所有零件、所有角度的整机通过结论。侧躺、俯卧等空角度案例没有地面、支撑和整体空间变换，不能据此声称卧姿避碰通过。

## 腿部改动与剩余偏差

承力杆外形中心线不等于有效转轴。只有转轴位置、父子变换和骨段长度决定刚体运动学；因此将杆画直不会自动修正被外移的髋轴心。

|替换件|O18同高度的杆中心距参考骨线|O19中间直段距参考骨线|该直段长度|
|---|---:|---:|---:|
|L001 左大腿连接架|18.745 mm|0 mm|25 mm|
|L002 右大腿连接架|21.514 mm|6 mm，向前|25 mm|
|L003 左小腿连接架|1.291 mm|0 mm|29 mm|
|L004 右小腿连接架|1.291 mm|0 mm|29 mm|

这是中间直段的比较，不是宣称整根连接杆或整条腿与UE完全重合。两端仍保留必要转接。右大腿若也完全归零，会新增手臂后摆时的手部碰撞，因此保留向前6mm偏移；大腿顶部转接范围也经过避碰调整。主杆直径保持10mm，端部的原关节几何保留；数字布尔检查端部差异小于1e-4 mm³。

髋中心仍各向外16mm；左右有效髋距约90.987mm，UE参考约58.987mm。膝、踝的中立有效中心仍与既有UE参考位置吻合。腿部参考骨线按既有480mm Quinn参考缩放计算，492.140mm为包含实体零件的最终中立包络高度，两者不是同一尺寸定义。

## 为什么没有直接把髋中心搬回去

本轮试算了零偏移的多组四轴髋机构安装方向、相位和冗余轴分解，以及8/12/14mm等较小偏移。部分零偏移方案在站立、装配位和坐姿无髋部碰撞，但深蹲或外展发生实体相交。例如相位90°、倾转60°、零偏移的试案，深蹲出现髋环相交；外展出现两侧传感板托夹相交。该试案被拒绝，没有混入O19正式零件。

这些是有限搜索结果，不是数学上证明“无法对齐”。继续消除16mm髋偏移需要重新解决髋机构的空间包络，例如改变髋模块布置或整体参考尺度，并重做相邻模块与走线检查。当前不以缩小姿态要求、增加保持力零件或隐藏碰撞来换取对齐结论。

试算证据保留在 `hip_mount_candidates.json`、`hip_mount_refined.json`、`hip_mount_final_search.json`、`hip_mount_compromise.json` 和 `hip_branch_search.json`。另保留初次直杆试案产生新碰撞的记录，便于区分已放弃试案与正式四件替换件。

## 查看器修正

蓝线：独立UE解剖参考模型的对应关节中心连线，采用Quinn比例。橙线：实体模块实际有效转轴中心连线，按当前示例姿态求值。二者都来自各自的运动学数据，不从连接杆外形推测。

旧网页的参考线连接的是实体骨段坐标原点。中立补偿可能使它们看上去与UE一致，却掩盖实际髋转轴偏移。O19改为独立绘制两套轴心并用十字标记端点。线表示本设备支持的关节拓扑，不是UE全部蒙皮辅助骨。

“腿部对照”默认左O18、右O19。可切正面/侧面、关闭金属和电子件、单独显示连接架和两套参考线。“整机干涉示例”的红色为实际布尔交集的透视高亮，便于看到实体内部的相交区域。

## 已完成的验证

- 四件新杆各为一个闭合实体。STL与3MF已重新读入校验；非流形边为0，格式间体积差小于0.001mm³。
- 与O18比较24个姿态案例（含重复中立角度的标签），四件新腿杆对所有保留几何没有新增或增大的相交体积，比较容差0.001mm³。继承干涉如实保留。
- 对坐下、下蹲、外展、跪姿、手臂后摆补查43个中间样本，语义角步长不超过10°，同样没有新增或增大的相交。四轴冗余分解可能跨分支，这不是连续编码器路径或连续扫掠的证明。
- 采集/USB共21项原有测试在O19配置下通过，包括46通道异常拒收、坐标/四元数计算、CAD姿态回归和数据包检查。
- 骨架变换、原始通道、标定参考角、USB协议、五金净数量与O18一致；没有把O11摩擦报告当作传感器标定。
- 浏览器检查、冻结包哈希与ZIP一致性记录随交付包提供。

软线束的最终绕行与绑点仍随新杆件实装核对；本次碰撞检查包含已有硬件、板件和刚性尾线模型，不含未建模的软线束连续包络。连接器端点和原链路/裁线数据未改变，不能因此宣称新的绑线方式已经实测。

## 文件与使用

- 网页：`tutorials/full-doll-o19/index.html`。
- 单台设计包：`bench/revO19/PoseDoll_O19_Universal_Design.zip`。
- 四件新打印件：`bench/revO19/print_batch/L001`至`L004`，各有STL与3MF。
- 唯一有效正式替换源：`generated/revO19/changed_parts.npz`及`changes.json`。
- CAD源码：`cad/revO19/design.py`；路径含 `experiment` 或 `search` 的文件仅为被评估的试案。
- 旧O18保持原提交和原包；O11用户报告单独记录，不回写历史验证结论。

离线包先运行 `python serve_preview.py`，打开本机 `http://127.0.0.1:8771/viewer/index.html`。校验包运行 `python source/verify_package.py`。CAD复建仍依赖仓库内冻结的旧版输入，包内cad_source不是全部依赖的独立复制。

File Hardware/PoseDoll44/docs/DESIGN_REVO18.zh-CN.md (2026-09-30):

# O18：一体单轴外壳简化版

O17 已保存为 `5a5ac22`，标签 `posedoll-o17-prototype-20260930`。其 349 个封装文件和 ZIP 的 SHA-256 已核验；本轮另建 O18 目录，不覆盖 O16/O17。O17 ZIP 校验值为 `6eb955ef5a5256c8ad3be155e1a847e869f7c05424e6e6616c7ce1437521019d`。

O18 将 14 处单轴关节的可拆半壳并入对应连接架，改用侧向装入预紧螺母和反力垫片的结构。单台打印件从 **202 件减少到 188 件**，种类从 **124 种减少到 117 种**；另去掉 **28 枚 M3×20 螺钉和 28 枚 M3 螺母**。本轮合计少装 70 个零件。与 O16 的 273 件相比，打印件累计减少约 31.1%。

这是可供审查和打印小样的机械改版。**整机仍有已知干涉，不能整机制造放行。** 侧装配合、承力强度、保持力、寿命、实物角度误差和 UE 端到端尚未实测。

## 简化依据

设备需要确定各个可动骨段之间的相对方向。只要独立关节仍可自由运动，就不能仅为减件而删掉其测量，也不能用软件插值充当实测。O18 继续保留 46 路传感器、25 个物理模块及 41 个语义旋转自由度。

反之，同一刚体内的外壳分件和装配紧固件，可以在装配路径允许时合并。原单轴外壳分为两半，主要为了装入内部螺母与反力垫片。保留预紧机构，给这两个零件开侧装通道，即可取消半壳与它的四件紧固件。这是本轮实际实施的简化。

左右脚趾两处合并连接架在制造网格回读中未稳定保持几何，本轮保留 O17 原件；失败候选不进入 O18 整机清单。

磁铁座与传感板仍可拆。若把磁铁座直接封死在转臂上，会挡住肩螺栓的安装及预紧调整，因此本轮保留它们。没有通过减少可表达姿态或固定原有自由度来得到数量下降。

## 实际改动

每侧各改 7 处：锁骨前后、锁骨上下、肘屈伸、前臂扭转、腕屈伸、腕侧摆、膝屈伸。胸部连接架容纳左右两处锁骨根关节，所以 14 处合并对应 13 个新连接架，编号 H001—H013。

| 项目 | O17 | O18 |
|---|---:|---:|
| 单台打印件，含原焊接间距治具 | 202 | 188 |
| 整机打印文件种类 | 124 | 117 |
| 本轮壳体连接 M3×20 螺钉 | 28 | 0 |
| 本轮壳体连接 M3 螺母 | 28 | 0 |
| 原始测量通道 | 46 | 46 |
| 语义旋转自由度 | 41 | 41 |
| 独立物理模块 | 25 | 25 |
| 数字中立姿势包络高度 | 492.14 mm | 492.14 mm |

表中的螺母数量仅指本轮取消的壳体连接件；关节预紧螺母、传感板固定螺母等仍保留，不能按此表把所有 M3 螺母删掉。采购以 `procurement.json` 净数量为准。H 件替换旧连接架及半壳，不能把两个版本重复打印装配。

一体件仍保留原壳体横孔，本轮没有为填孔而重新增大包络。原分缝仅作名义实体连续处理，保留已有线束和相邻机构避让槽。几何清理容差为0.0001 mm，导出后再次检查闭合性、体积及碰撞；不能仅凭清理容差推断没有新增碰撞。轴中心、肩螺栓、弹簧及摩擦垫片、磁铁、传感器及其名义气隙保持不变。

## 侧装结构与装配顺序

在原单轴关节局部坐标中，从 +Y 一侧向内装入零件。螺母通道名义宽 7 mm、高 2.65 mm；反力垫片通道宽 9.4 mm、高 0.95 mm。垫片厚度名义 0.8 mm，多出的高度放在垫片下方；原 `z=-5.3 mm` 反力面保留。名义上部承力厚度为 2.8 mm，底部最低厚度为 1.8 mm，不能据这些尺寸直接推定打印件强度。

1. 先检查裸打印连接架的通道，去除支撑与毛刺；不要扩大原反力承台或肩螺栓定位孔。
2. 在未装转臂、肩螺栓、电子件和其他外围零件时，侧向装入原 M3 预紧螺母和反力垫片。复杂连接架先装完各处的这两件。
3. 按原顺序安装摩擦垫片、转臂、弹簧、肩螺栓及原有预紧件，逐步调整保持力。肩螺栓穿过后限制内部螺母、垫片侧向脱出。
4. 安装 O17 沿用的磁铁总成和传感板托夹。磁铁侧壁仍按 O17 工艺粘接并固化，不能仅靠圆孔配合来保证磁铁不自转。
5. 检查旋转阻力、保持力、反力面变形、松动与回差，再做传感器标定。

CAD 检查覆盖了 14 个完整裸连接架，每处螺母和垫片各取 65 个位置、16 mm 行程，合计 2070 个名义插入位置；还检查了垫片承力面保留、肩螺栓对侧向逃逸的阻挡，以及螺母保留六角面在正负 15° 的止转干涉。此检查没有模拟打印误差、弹性、磨损，也不是所有零件已经装好后的维修抽出保证。

## 先做一套关节小样

`coupon/Q001` 是与本轮相同生成规则的一体单轴外壳，`coupon/Q002` 是配套转臂。两件不计入 188 件整机净数量。它们配合沿用的 N001 传感板托夹和 N004 单轴磁铁总成，以及原单轴关节的预紧五金、磁铁和传感板，可做完整关节小样。详细物料对应写入 `FIRST_PRINT.json`。

先确认侧装和拆卸可以完成，再在实际材料、打印方向及预紧力下检查反力面压陷、开裂、蠕变与保持力。记录同一角度从两个方向返回的回差，以及静置后的角度漂移。没有实测结果之前，不把 Q001 的名义通道通过当作整机强度或测量精度合格。

若 O17 的托夹弹片与磁铁粘接小样尚未验证，继续完成那些验证；O18 不替代它们。

## 干涉检查与未采用的改法

O17 已有的手臂与骨盆等干涉仍然存在。本轮试算过直接扣掉骨盆架在数字中立姿势中与手臂重叠的材料；仅此操作就使骨盆架变成 **6 个分离实体**。该方案未加入 O18。不能靠隐藏碰撞物或删断承力连接来宣称无干涉。

O18 对 13 件新连接架执行了装配姿势和原有 23 个姿势共 24 个离散样本的增量回归，保留同一配对在 O17/O18 的重叠体积。结果以 `verification/geometry_verification.json` 为准。判定阈值 0.001 mm³ 用于数字布尔结果比较；它不是允许实物穿透的装配间隙。

检查范围是“至少一件为本轮新连接架”的配对。未变零件之间的碰撞不属于这次增量检查，也没有连续全域、软线束扫掠和实物摆姿的合格结论。旧姿势菜单是设计诊断样本，不能当作都能摆出的动作清单。下一项整机优化应重排躯干、肩带与骨盆的承力路径和设备包络，再联合校验活动范围，而非继续削切现有骨盆架。

## 测量、USB 与 UE

沿用 O17 的 C1-U 电子方案、六条 SPI 链、P17R/1 USB 协议及已编译固件。固件、裸板和采集运行时代码保持原字节。O18 设备配置有新版本 ID 与摘要；标定模板重新绑定它，状态仍为 INCOMPLETE，旧标定不能直接宣称适用于新装配实物。

USB 数据线只给主控供电；传感器通过 J7 独立 5V 供电，GND 共地，C1-U 的 D1 必须不装。原上电、反灌、压降、温升与线缆应力释放检查仍适用，详见 `POWER_AND_USB.zh-CN.md`。无需摄像头。

一体外壳不会改变角度转换公式。原始读数、零位、方向和标定版本必须保留，缺失或坏数据仍拒绝采集。根部位置/整体转动和手指未测；脊柱、颈部辅助骨的分配属于派生数据。目标角色接触、穿模和动作修饰交给 UE 后期。

离线 FK/故障处理及 USB 测试在 O18 配置上运行；这是计算与协议检查，不是 Manny/Quinn 最终求值骨骼的端到端测试。本轮不更改 UE 工程。

## 文件与复建

- `print_batch`、`PRINT_UNIVERSAL.csv`：117 种、188 件；STL/3MF 二选一。新件优先使用3MF；若float32量化会破坏闭合性，STL使用标准高精度ASCII格式，具体见清单中的stl_format。
- `coupon`、`FIRST_PRINT.json`：额外关节小样，独立于整机净数量。
- `profiles`、`source`：O18 配置及沿用的 O17 USB/测量引擎。
- `firmware_source`、`firmware_binaries`、`electronics`：O17 的冻结副本，依哈希核对，不声称重新设计电子或重新刷机。
- `verification`：实际几何、文件、运行时与浏览器验证结果。
- `cad_source`：O18 源码；复建需本仓库冻结的 O15/O17 输入，ZIP 本身不是独立 CAD 依赖全集。
- `FILES_SHA256.json`：包内文件校验；`source/verify_package.py` 可离线核验。

仓库复建顺序：先运行 `cad/revO18/design.py`，再运行 `export.py`、`verify_geometry.py`、`verify_exports.py`；执行 `bench/revO18/source/test_device.py` 与 `test_usb.py`，复核浏览器后再运行 `package.py`。失败步骤应停止后续封装。代码中的 O17/P17R 名称表示沿用协议和测量 schema，不表示配置错用了旧机械版本。

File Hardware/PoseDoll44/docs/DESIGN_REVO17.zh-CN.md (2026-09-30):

# PoseDoll O17：USB 直连的一体件简化版

O17 是在已保存的 O16 上完成的数字设计候选。一个实体人偶，静态摆姿采集，接受 USB 连线，不依赖摄像头。保留 O16 的 46 路实测、41 个语义旋转自由度和全部关节中心；本轮重点是减少零件与重复装配。未宣称整机实物或 UE 端到端验收通过。

## 已保存的 O16

- 本地 Git 提交：`26255df`；标签：`posedoll-o16-saved-20260930`。
- O16 目录和原设计包保持不变。该包 SHA-256：`b4944bcba95b2ab10523fd785509abc652174c75843798b3c82d85f966861096`。
- O16 为 273 件、214 种打印件，仍可独立打开、核验和复建。保存不代表升级为制造放行版本。

## 实际减掉了什么

| 项目 | O16 | O17 | 说明 |
|---|---:|---:|---|
| 实体人偶 | 1 | 1 | 同一硬件供不同 UE 角色适配 |
| 单套打印件 | 273 | **202** | 减少 71 件，约 26.0%，包含保留的焊接间距治具 |
| 打印件种类 | 214 | **124** | 六种新打印件替换合并件和两个改动骨架 |
| 原始测量通道 | 46 | **46** | 没有删除关节动作或用估计值代替测量 |
| 语义旋转自由度 | 41 | **41** | 关节中心、骨架关系、编码器名义位置保持 |
| XIAO 主控 | 2 | **1** | 人偶直接接电脑，无 G0 网关 |
| 电池、射频天线 | 1 块、2 副 | **0、0** | 改为有线数据和桌面供电 |
| 附件螺钉 / 螺母 | — | **各少 8 个** | 来自电池盖和 G0；关节预紧紧固件保留 |

打印件减少的对应关系：34 组「传感板托 + 板夹」变为 34 件一体托夹；34 组「磁铁座 + 磁铁盖」变为 34 件一体座盖；删除电池盖和 G0 两件外壳。骨盆去除电池盒，胸部增加 USB 开口与扎带槽，但两处骨架仍各是一件。

`N001` 一体托夹 28 件，`N002` 一体托夹 6 件；`N003` 紧凑磁铁座盖 18 件，`N004` 铰链磁铁座盖 16 件；`N005` 骨盆骨架 1 件，`N006` 胸部骨架 1 件。其余 P 编号是逐文件校验保留的 O16 零件。以 `PRINT_UNIVERSAL.csv` 为最终数量依据，STL 和 3MF 是同一件的两种格式。

## 为什么这样简化不减少姿态测量

需要测量的是相邻刚体的实际相对转动。安装座、盖板和螺钉本身不增加姿态信息。因此先合并没有相对运动的零件，保留传感器和关节运动轴。

O17 的 raw 顺序、正向运动学变换、固定骨段与标记、角度诊断范围均与 O16 相同。每个新件仍随原来的刚体运动，没有把两个不同运动部件粘成一个刚体。输出仍使用矩阵 / 四元数，不能把多轴机构的内部编码器角度直接当作角色的单个欧拉角。

头颈与髋部改为三轴、46 路减至 43 路，仅保留为后续研究方向，**不计入本次成果**。还没有针对完整关节任务验证新机构的活动范围和实体避碰。肩部的大范围运动尤其不宜直接删除冗余轴。

## 一体传感板托夹

保留原有底座、可拆接口、定位键和 M3 螺钉，先把 PCB 滑入独立托夹，再装回人偶。传感板的名义位置与原来一致。拆下托夹后，仍能接近磁铁和关节预紧机构。

开口朝托夹局部 +Y 方向。右侧留下约 9 mm 长、0.8 mm 厚、0.8 mm 宽的弹片；抬起的前端阻止 PCB 滑出。取板时手动释放弹片，不能拉着 FFC 硬拽。PCB 装好后才连接 FFC。

小挠度梁估算：释放行程 1.2 mm 时，表面应变约 1.78%。这是几何估算，**不是 PETG 强度或寿命保证**；模型中的释放通道检查将弹片从干涉体中移除，也不是形变仿真。需要试打印验证实际释放行程、断层、蠕变和反复拆装。若卡扣不可靠，保留 O16 可拆托夹，不能用胶封住 PCB 或省略定位。

## 一体磁铁座盖

采用两种参数化座盖，沿用原来的径向尺寸、安装台阶、两个 M2 孔和磁铁名义位置。先在拆下的零件中侧向装入磁铁，再安装到关节上。侧向通道斜着避开大部分螺钉支承面；装上原 M2 螺钉后，螺钉头阻止磁铁沿该通道退出。检查得到的最小螺钉支承面积保留比例约 69.6%，不等于已经验证夹紧强度。

**圆形磁铁必须可靠传递转角。** 螺钉防脱不能保证磁铁不在圆孔里转动。本版在磁铁侧壁与座的间隙使用少量非导电粘接剂，底面保持就位，按胶的厂家说明固化；禁止让胶进入传感器间隙或螺孔。先做磁铁标记、读数和反复摆动对照试验。固化后的「磁铁 + 一体座」作为可更换总成；需要换磁铁时替换总成，不承诺可以无损取出粘好的磁铁。

新座盖由原始参数重建，避免将旧网格的共面接缝直接焊合造成非流形边。与旧三角网格存在极小数值差异，已写入验证报告。不能把它表述成数学上毫无容差的逐点子集证明。

## USB 数据与供电

使用一个 XIAO ESP32S3，直接通过 USB Serial/JTAG 与电脑通信，无 ESP-NOW、配对 MAC 或 G0。固件已单独编译，使用新的 `P17R/1` 协议头；不能把 O16 固件或旧协议接收器当作 O17 即插即用的软件。

本版采用**两路有线连接**：电脑 USB 给主控供电并传输数据；独立稳压 5V USB 电源经 J7 给传感器降压电路供电。两个正电源不相连，电路共地。XIAO 官方资料列出的 Type-C 输入为 5V，详见 [Seeed 官方说明](https://wiki.seeedstudio.com/xiao_esp32s3_getting_started/)。

原 C1 裸板可保留，装配变体称为 **C1-U**：**D1 不装**，BOM 与贴片坐标已更新。已装过的旧板需拆掉 D1 后再连接。D1 原本会把外部 5V 送到主控的 USB 电源节点，直接双电源连接不符合本版接线。

选用稳压 5V、额定至少 2A 的桌面电源，作为工程余量目标，并非已测得整机功耗。保留现有 3.3V 降压器及六路保护，不从 XIAO 的 3.3V 引脚给所有传感器供电。不要使用输出 9V/12V 的 PD 触发线。采购单包含 USB 数据线、5V 电源线、扎带和粘接剂，不再购买人偶电池或 G0。

胸部控制盒上沿新增 USB 开口及扎带槽。实际插头的横截面须小于所给包络并按实物试装；线缆在外壳处做应力释放，在人偶后方留松弛回环。新 USB 软线的完整运动包络、拉力与弯折寿命尚未验证。

## 数据链的正确性

`46 个编码器 → 六条原 SPI 链 → 单一主控 → USB → 原始记录 → 标定 → 实体姿态 → UE 角色适配`。

每次请求含独立采集标识，设备身份与启动标识固定在一轮采集中。扫描时间上限 60 ms，名义间隔 100 ms；完整稳定窗口至少 500 ms。坏包、缺轴、磁场诊断异常、重放、超时或混合设备不能转成零角度。

USB 参考工具保存原始字节、解码帧和标定。逐通道时间采用整次顺序扫描的保守最早时间界，并单独保留起止界；不声称 46 路同时采样。主机用发送请求之前的时间建立保守年龄上界，避免把 USB 缓冲里的旧数据当成新数据。

提供的是离线验证与采集参考；**未运行新的 Manny / Quinn UE 端到端验收**。角色骨长仍由目标角色保持；根部位移 / 整体旋转、手指不测。目标的多段脊柱、颈部和辅助扭转骨仍须区分实测与派生。接触、脚底、穿模和动作修饰留给 UE 后期。

## 已知整机干涉

本轮直接复查确认：O16 中立姿势的左前臂连接架与骨盆架重叠约 1895.94 mm³，O17仍保留这一问题。24个工况（23个保存姿势加装配姿势）的检查只比较改动件相关的碰撞增量，并没有消除旧干涉。图中的姿势不能当作可摆到的实物姿势；`REGRESSION_PASS_WITH_INHERITED_OVERLAPS` 不能读作整机零碰撞。

因此本版交付为**简化小样候选**：数量、可制造网格和测量模型已经具体化，但全机干涉仍是整机制造前必须解决的问题。

## 先做的小样与放行条件

1. 先打印 N001、N002、N003、N004 各一件，使用真实 PCB、FFC、磁铁和标准螺钉试装。避免一次打印整套 202 件。
2. 检查托夹能定位 PCB、连接器不受力、弹片能够操作和反复拆装，磁铁总成不轴向窜动或相对转动。保留零位、误差、回差和重复性记录。
3. D1 不装的 C1-U 先限流上电，核对 J7 极性和两路电源断开时的反灌电流、传感器末端电压和温升；再做 USB 断连、拔掉一轴、故障标志和设备重启测试。
4. 验证单关节、相邻组合和实际带线摆姿，检查保持力、打印蠕变和关节邻近干涉。离散数字回归不能替代全工作域或实物验证。
5. 用独立量具验证实体，再分别在 Manny / Quinn 最终求值骨架与可编辑关键帧上验收基础转换。

本轮的实测空白须保留为空白，不得从数字样例填出「通过」。`verification/` 记录几何、服务通道、21 项 Python 测试、C 协议与会话测试、固件编译和浏览器检查；报告中的 `physical_tested` 与 `ue_end_to_end_tested` 均应保持 false。

## 复建与核验

仓库中使用现有 CAD Python 环境，依次运行 `cad/revO17/geometry.py`、`export.py`、`verify_geometry.py`、`test_device.py`、`test_usb.py`，最后运行 `package.py`。这些脚本只写 O17 路径。CAD 复建依赖仓库中冻结的 O15/O16 输入；交付包中的 STL / 3MF 和查看页可以单独使用。

固件源代码在 `Firmware/PoseDollFullBody/revO17/`。`build.ps1` 只编译，不刷写。`test_native.cmd` 运行本机 C 校验。禁用射频后，启动标识使用临时启用的内部熵源生成；参见 [Espressif ESP32-S3 随机数说明](https://docs.espressif.com/projects/esp-idf/zh_CN/v6.1/esp32s3/api-reference/system/random.html)。

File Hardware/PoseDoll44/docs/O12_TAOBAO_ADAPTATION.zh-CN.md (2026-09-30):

# O12：用户淘宝零件适配与独立小样

运行：generated/revO12/runs/o12_20260926_r1，2026-09-26。

用户明确授权采用6 mm螺纹的Φ4×8×M3轴肩螺钉，并尝试商品标称孔4/3 mm的垫圈及不锈钢A8碟簧。本轮将其作为实物试装候选，新增O12小样打印包和动画指南。没有验证用户提及的“6 mm是国标要求”；设计依据是截图尺寸，不依赖这一标准推断。

入口：[操作指南](../bench/revO12/README.zh-CN.md)、[动画页面](../tutorials/taobao-bench/index.html)、[3MF](../bench/revO12/print_beds/O12_taobao_bench.3mf)。

## 已修改

- 两半打印底座内部螺母/反力垫圈座向螺钉头移动1 mm；外形50×30×8和长臂保持。
- 6 mm螺纹在碟簧总高1.1/1.0/0.9 mm时的名义末端余量改为1.1/1.2/1.3 mm。
- 承压台阶从3.8降为2.8 mm；这是几何取舍，不能宣称强度等效或更好。
- 轴肩螺钉按304标签、3 mm内六角；底座螺钉头径改为5.6 mm，扳手仍2.5 mm。
- M4/M3垫圈名义孔按用户商品标注4/3 mm建模，实际孔和滑动配合状态均为unknown。单独的孔径检查明确显示零间隙不等于可装配。
- 碟簧材质为“不锈钢，钢号/状态未提供”，力值和曲线为null；不把原目录210 N分配给这一批。
- 空白实测模板增加三项金属配合试装、实际肩径/长度、螺纹端倒角、碟簧自由高与永久变形记录。

## 检查

完整结果在digital_checks.json。4种轴向状态各105对零件求交通过；4×73个长臂角度样本通过；内部零件装入、底座闭合、向外保持阻挡与3 mm直工具杆外部空间检查通过。15件保持单一有效实体。STL/3MF回读体积误差限0.03 mm³；网页用简化显示网格，计算使用完整网格。

生成器在检查前将CSG求值为独立网格，以继承的1e-5 mm焊接精度固定实体，并检查检查过程不改变输入实体记录。名义圆孔与圆轴等径属于零余量，不能由求交为零认证实物滑动。

128组螺纹敏感性计算使用假设的肩长±0.1、螺纹长±0.2、螺母座±0.2、螺母厚±0.1、堆叠±0.1 mm，以及端部0.5/根部0.3 mm不完整螺纹区。最小有效覆盖为2.2 mm，部分假设组合不能覆盖螺母完整厚度。它是反例范围，不是商家公差或螺纹承载验收。具体数组和假设随报告保存，不能改写为“全公差通过”。

本次不重认证O11双轴核心或胸肩布局。原来未关闭的Quinn动作干涉、整机结构、线束与实物验证仍保留。≤1.2 kg不是硬门槛，产品仍为静态姿势采集。

## 复算与证据

先运行仓库Python：
1. Hardware/PoseDoll44/cad/revO12/build_taobao_bench.py
2. 检查tutorials/taobao-bench本地页面。
3. scripts/seal_revo12.py；已有封存用--verify。

生成器禁止覆盖已封存O12运行。O11封存的78个文件和其上游证据保持不变。封存只证明记录完整，不代表制造放行。

参考尺寸：[嘉立创FA垫圈表](https://static.jlcfa.com/Serial/E06/EPDA/542502462063341570.pdf)确实列出M4孔4.3、M3孔3.2。用户这批可能用公称规格作商品标注，也可能实际孔更小，必须实际试装，不能猜测批次参数。

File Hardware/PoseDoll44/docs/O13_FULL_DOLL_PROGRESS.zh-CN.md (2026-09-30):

# O13：实物小样通过后的整机设计进展

运行：`o13_20260929_r1`。记录日期：2026-09-29。

用户已安装 O12 长臂小样，报告打印件与所购标准件贴合良好，当前摩擦大致能保持长臂角度，轻力可拨动。本轮按用户授权，将**这一件的装配与初步手感登记为通过**，继续沿“家用 FDM 主体 + 现成金属小件”推进。

这次没有测得保持扭矩、弹簧力、打印材料或长期漂移。用户预计拧紧后摩擦会更大，记录为待验证预期。旧 O12 封存文件维持历史状态，新的实物反馈另存于 `bench/observations/o12_20260929_user_feedback.json`，所以旧报告的“当时没有实测”与本次新增观察可以同时保留。

## 更新后的使用要求

静态摆姿后采集；优先靠自身摩擦保持，可以用手辅助支撑。自保持不足不再单独判为失败。手托过程中仍须保持目标姿势稳定，并取得完整、新鲜、有效的角度数据。碰撞、卡滞、结构松脱及传感器故障仍需解决。

480 mm 为人体参考，910 mm 备用设计保留。没有 1.2 kg 重量硬门槛。本轮没有改动固件、UE 设备校准或固定/缺失/故障协议语义。44 个输出轴位仍保留 41 路测量、3 路固定语义；这不是对四角度冗余机械机构所需原始传感器通道数的重新验收。

## 已完成的结构修改

1. 完整双轴核心同步到用户现货：Φ4 × 8 轴肩，M3 螺纹长 6 mm，3 mm 内六角。内部 M3 螺母区间改为 7.5–9.9 mm，反力垫圈为 9.9–10.7 mm，保留 2.8 mm 打印承压台阶。名义螺纹覆盖完整 2.4 mm 螺母厚度。
2. 两叉架外形与原 O11 连续检查使用的数组逐项一致。保留原动作角度和骨长，肩安装点每侧向外移 8 mm；肩间距增加 16 mm。此变化只在设计布局中，尚未发布到 UE 校准。
3. 锁骨输出叉架与肩部输入壳体的一半通过实际打印连接架连成一体。采用从壳体外侧绕入、在后端承接的路线；四个角色/左右组合都形成单一连续实体。另一半壳体、金属螺钉和螺母继续作为碰撞障碍检查，不能因为“同一刚体”而忽略穿插。被淘汰的直连、前端接入等结果保留在 `carriers/rejected_*.json`。
4. 开发紧凑腕部候选：沿用小样的 15 件机械堆叠，底座宽度缩为 28 mm，转臂截短并留连接孔；另加传感器、磁铁、转子杯、连接器和支架占位一起检查。仅在腕部替换旧模块，肘与前臂暂保留旧模块。全部单轴都换成新模块的尝试反而增加失败，未采用。
5. 背部保留 48 × 48 × 12 mm 空间，将其向下移动 8 mm。联合检查已包括新连接架和紧凑腕部。该体积仍是空预留，尚没有布置成完整 PCBA、固定架和带线总装。

## 数字结果及边界

| 检查 | 结果 | 范围 |
|---|---|---|
| 双轴核心打印主体 | 4 件均为有效单一实体；名义堆叠无所检穿插 | 网格名义几何，不是强度或工艺验收 |
| 完整关节目标端点 | 204 / 204 未检出所检穿插 | 原映射包含重复状态；不是 204 个独立极值工况 |
| 两叉架连续间隙 | 复核继承原 80 个区间单元、下界 ≥0.6 mm 的证据 | 仅两叉架，α±28°、β±98°；不是所有零件连续证书 |
| 插入、保持和工具 | 8 个螺母/垫圈抽样插入路径、轴向阻挡、4 根 3 mm 直工具杆通过相应检查 | 工具手柄、实际装配公差及强度仍未覆盖 |
| 肩长/弹簧高度敏感性 | 8 组组合，每组 15 个角度样本 | 不代表碟簧弹力已测得 |
| 胸肩相关端点 | 102 / 102 无所检穿插 | 限定的胸肩配对，未包含所有腕部互碰 |
| 胸肩路径抽样 | 102 条路径、3894 个内部样本无所检穿插 | 采用左右原时间网格并集，各臂取各自原采样点；不是严格同时连续轨迹，也未包含后加入的连接架与紧凑腕部 |
| 旧腕部全臂配对基线 | 92 / 102 端点清除 | 扩大配对后保留 10 个失败端点 |
| 新连接架 | 102 / 102 无新穿插，4 个组合均为单一实体 | 尚未做全路径、装拆、强度、工具手柄与切片验收 |
| 新连接架 + 紧凑腕部 + 占位联合检查 | 96 / 102 端点清除 | 仍有 6 个失败；完整躯干、下肢、真实线束及所有承力连接不在模型内 |
| 左右手分别运动补充检查 | 136 / 136 无所检穿插 | 紧凑腕部与原手臂模块；该补充检查未加入后续连接架 |
| 后移电路空预留 | 102 / 102 清除，预留体四周另扩展 0.5 mm | 含新连接架及紧凑腕部的端点；仍是空体积 |

求交器先做包围盒筛选，再逐实体做网格布尔求交；组间体积是逐件相交体积之和，不一定等于并集体积。阈值为 1e-4 mm³，原网格在导入时以 1e-5 mm 焊接。这些数值不能代替制造公差或受载变形。

检查器另用包含、分离、接触、旋转穿插和左右不等采样网格等 7 个反例检查方法，全部通过。

## 剩下 6 个端点为什么失败

Manny 和 Quinn 各有三个：双臂内收 20°、原对称抱臂、原不对称抱臂候选。原目标全部保留，未通过缩小角度或删除测试变成“通过”。

内收 20° 的原测试同时作用于两臂。在 Quinn 中，左右腕侧偏轴中心只相隔约 0.76 mm；该双臂组合会让腕部进入同一区域。新增 136 个独立左右手端点检查均清除，因此不能把它直接解释为某个单轴活动范围不够。抱臂案例还包含腕部与对侧前臂/肘部的接近，需要继续处理组合姿态和安装空间。辅助支撑不会消除这些几何碰撞。

## 质量、载荷和手感

新联合布局的已建模单臂实体预算约 175.9–176.2 g，另保留每臂 144 g 未定型下游零件预算。实体连接架替代原两块打印实体计算，未重复累加；腕部传感器占位没有再次当成已知 PCBA 质量计入，其重量仍在未定型预算内。

假设塑料实体密度 1.22 g/cm³、金属 7.85 g/cm³。实际打印材料未知，这些是载荷预算，不是本次成品实称，更不是整个人偶重量。当前报告增加了两根锁骨轴的重力矩。所有已算轴中，最大的优选自保持目标约 0.458 N·m，包含 1.5 倍重力系数和 0.02 N·m 线束余量；它已经不是硬性通过条件。

实际摩擦扭矩和碟簧力都保持未知。没有沿用 O11 目录 210 N。报告中的“100 mm 垂直支撑力臂、零摩擦”手托力只是情景计算，不能当作实测操作力。

## 全身设计目前覆盖到哪里

新查看器登记两个角色的全部 44 个语义轴位，含坐姿、下蹲、头部倾斜、髋外展、躯干弯扭、交叉腿的全身参考。绿色/灰色实体为当前手臂机械几何，黄色为腕部传感器与支架占位，细线为参考骨架。下肢参考姿态没有冒充已完成的机械运动检查。

18 个手臂语义轴位已有实体参考及部分连接；颈、腰胸、髋腿脚的其余 23 个测量轴位还没有本轮完整的细化关节与承力连接。腰到胸中心约 33 mm，而整个肩部模块主轴包络约 73.5 mm，沿同一轴向直接复制两套不能据此认可。通过改变朝向、分散布置或共享结构是否可行，仍需实际建模；这里没有声称所有方案都不可能。

外侧扭转座仍需实际预紧与测量方案，完整手臂连接、所有电路/线束、整机碰撞和强度也未放行。手动支撑只改变自保持要求，不能把这些未完成项目改成通过。

## 下一项硬件验证与交付

现有 O12 小样继续使用。3 mm 扳手到货后，优先补充实际材料、小幅调整后的手感、已知负载与力臂、1 分钟/10 分钟停留变化。无需为了本轮的 CAD 修改重新打印已经装好的长臂小样。

下一阶段硬件包是**双轴核心试装**，共四个打印主体，继续使用当前这批标准件；承力环新增的 M1.6 合拢螺钉/螺母需要核对商品尺寸。测试目标是双轴配合、对侧预紧相互影响、卡滞、反向空程和停留变化。它是阶段性试装候选，尚未实际切片、打印或测试；不是全身打印包。

- [整机布局与核心转动查看器](http://127.0.0.1:8769/tutorials/full-doll/index.html)
- `bench/revO13/README.zh-CN.md`：四件核心装配与测试说明。
- `bench/revO13/print_beds/O13_core_fit_only.3mf`：几何模型，无 G-code。
- `cad/revO13/README.md`：复算顺序。
- `generated/revO13/runs/o13_20260929_r1/`：原始报告、几何数据和最终证据快照。

最终快照核验文件一致性及报告显式记录的依赖；它不补造所有实验运行时的逐次读取日志，也不等于制造验收。O12 及其上游 O11 封存核验保持通过。

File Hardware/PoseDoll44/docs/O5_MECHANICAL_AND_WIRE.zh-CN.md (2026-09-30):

# O5 机械与线束数字实验的边界

继续保留 480 mm 参考、直接手动摆姿、41 个测量轴、无线和外置 G0。1.2 kg 不是失败判据。当前实验不更新完整质量预算，不把旧约 1.656 kg 预算称为成品重量。

## 同条件 A/C 空间比较

`cad/revO5/shared_arm_screen.py` 导入 O3 的实际关节零件、O4 A/C 两组 PCBA/插头/工具/R12/RF 模型、N2 原生 KiCad STEP。在 Manny 和 Quinn 的相同 480 mm 参考中安放左侧九轴、N2、双侧近端板及左上臂远端板；保留九路六芯传感线，只有 J50 比较 14 芯和 4 芯。

试验 profile 明确记录锁骨 24 mm、肩轴 28+28 mm、腕轴 25 mm 的局部偏置，关节沿自身轴线移位 36 mm。它们是**未冻结的摆放变量**，没有写入 UE 设备标定。每个角色每种方案检查 26 个离散姿态，全部外部包围盒交叠只记“潜在冲突”；中立位另外执行两组真实 BRep 求交，确认关节与 N2 实体、关节与天线空域的冲突。

这是一组具体布局的失败反例，**不是所有可能布局的不可行性证明**。不能据此说 480 mm 必须放大，也不能说 C 已合格。安装叉架/紧固件、真实外壳、右臂完整镜像、背后动作、连续扫掠、最小曲率与线束恢复力仍缺；当前原生 STEP 是待修改的定位总装，不是可制造单臂。

J50 草案含一圈 R12 余量与 20 mm 安装余量，最长约为 Manny A 305.9 / C 304.8 mm、Quinn A 295.2 / C 294.1 mm。草案折线不是合格可制造路线。供电分析另外引用这些草案长度和报告哈希；它不能代替最终长度、压接或弯曲寿命。

**本轮结论：A 继续作为采集软件/台架基准；C 暂缓定型。** 目前两者首先受到共同胸肩机构和 RF 空间的限制，不能仅以线数/PCB 面积宣布 C 获胜。下一步应修改可装配肩部模块/叉架和 N2/近端板位置，再比较同一合格路径下的真实线束。

## 输出连接候选

`output_coupler.py` 保留原 O3，试验延长 D 形轴与两片夹环。8 mm 啮合、名义 0.025 mm 配合余隙、0.3 mm 分缝，M2 横向通孔；名义夹环与轴、调节扳手工作空间求交为零。代价是后端增加 16 mm，已计入上述单臂比较。

这是输出连接初稿：螺钉/螺母、夹紧力、轴向保持和反向载荷未定级；不以“零求交”证明已紧固。当前不冻结此加长方案。下一轮优先比较与叉架一体的侧向输出连接，避免继续叠加轴向长度。

实际最大弹簧力仍未知。326 N 只是目录工作点；200/326/450/600 N 与摩擦系数 0.08/0.12/0.18 的结果均为条件计算。前背片定位、后背片受扭滑动、约 0.65° 外耳空程、中断螺纹/约 0.65 mm 薄壁、摩擦层结合仍 OPEN。误差≤1°、重复性≤0.3°、60 s 漂移≤0.5°、1000 次往返是未来样件验收起点，本轮均未实测。

## 线材合同和供电

JST SH `SSH-003T-P0.2-H` 规定 AWG 32–28、绝缘外径 0.4–0.8 mm，因此原 26 AWG 组合被拒绝。[JST 原厂目录](https://www.jst-mfg.com/product/pdf/eng/eSH.pdf)

候选为 Alpha Wire `2842/19`，28 AWG、19/40 绞线、PTFE，外径范围 0.635–0.7366 mm；目录直流电阻为标称值，不是线批保证上限。AWG/外径筛选满足端子范围，但精确绞束与压接高度/拉脱力仍需供应商工艺页。目录弯曲半径 10×外径也不等于反复扭转寿命。[Alpha Wire 产品页](https://www.alphawire.com/products/wire/hook-up-wire/premium/2842_19)

合同保留 3.3 V 四芯接头。计算取源电压 -5%、4 个串联触点环境后各 40 mΩ、TPS2553 导通电阻 135 mΩ、PCB 50 mΩ 假设，并扫描温度、电流、长度和电阻余量。48 组条件中 6 组低于 3.0 V；50 mV 储备是工程假设，不是认证指标。100 kΩ±1% 限流设置的条件范围约 232–306 mA，因此 250 mA 负载不能按“低于典型限流”放行。[TPS2553 数据表](https://www.ti.com/lit/ds/symlink/tps2553.pdf)、[THVD1400 数据表](https://www.ti.com/lit/ds/symlink/thvd1400.pdf)

草案最长线约 305 mm，在 60°C、线阻+10%、200 mA 下计算约 3.036 V，超过最低值但达不到上述 50 mV 储备。电流/浪涌、实际最长路线、独立压接电阻和热均未知。保留 SH4/28 AWG 作为候选，不放行；若实测与定型路线不满足，才比较独立防误接的 5 V+本地稳压或真正支持更粗线的接头。不得向当前 3.3 V 板直接送 5 V。

压接设备参考已写入 JSON 合同，剥线长/压接高度/拉脱力为空值，绝不以猜测数字替代工艺。[JST 工具目录](https://www.jst-mfg.com/product/pdf/eng/eCRIMPING_MACHINES_AND_TOOLS.pdf)

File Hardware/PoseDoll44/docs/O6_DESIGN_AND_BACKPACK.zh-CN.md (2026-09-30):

# Rev O6：关节、双臂布置与背部集中备选

本轮继续以 480 mm 人体参考和静态姿势采集为主线。取消 1.2 kg 硬门槛；91 cm 备用版保留。用户已明确允许在分散模块妨碍活动时采用背部集中方案，旧文档的“不得外凸背包”不再作为绝对限制。传感器磁铁与测角头仍在关节处；“集中背部”指采集、通信和配电模块。

**本轮得到两个可复算的单关节研究模型及背部集中比较。完整双臂和整机仍未通过；没有实物测试或制造放行。** 实际执行结果见 [动态汇总](../verification/revO6/runs/o6_20260924_r1/results.json)。

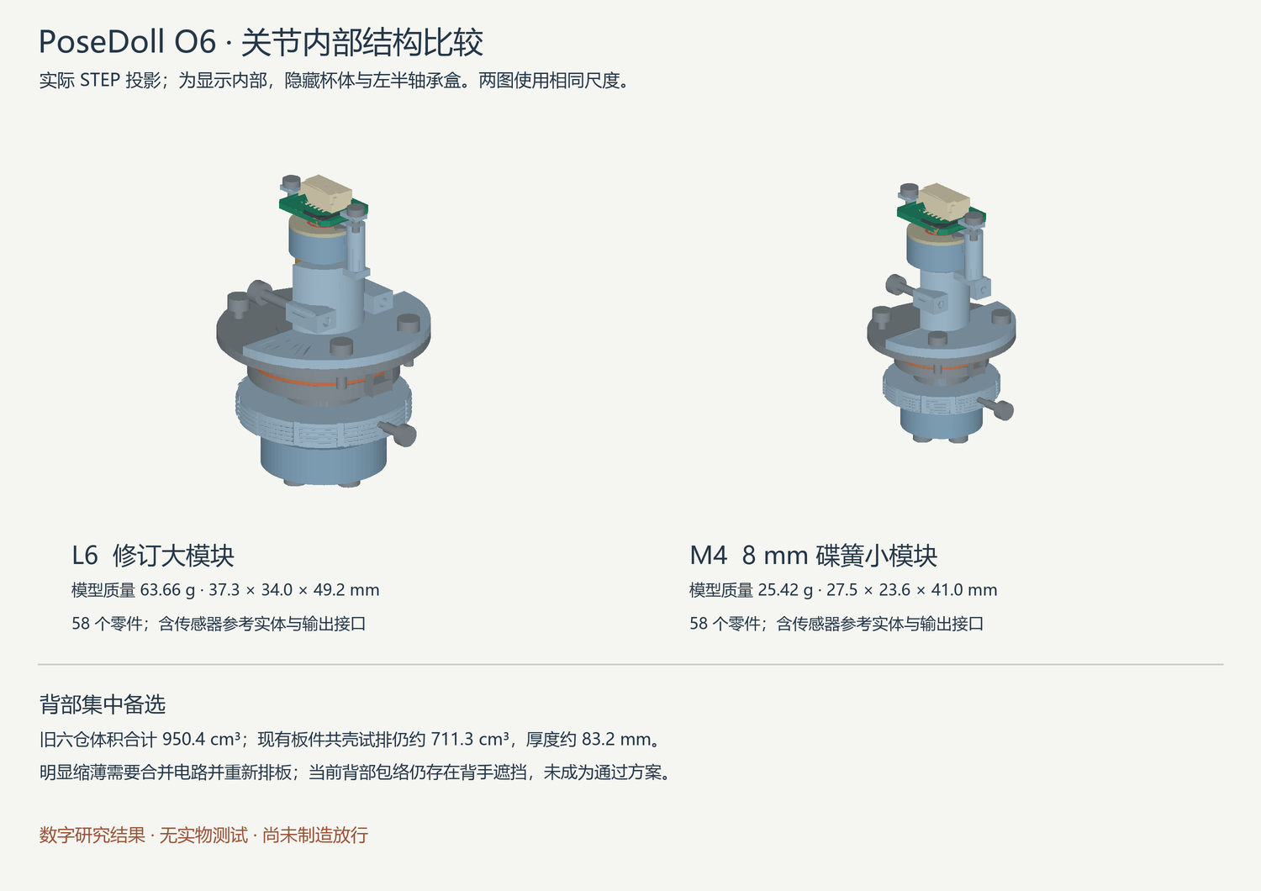
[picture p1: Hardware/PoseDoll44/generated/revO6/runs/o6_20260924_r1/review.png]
关节审查图


## 机械改动

- 前装式制动杯配可拆钢端板；前背片与端板、后背片与压力座分别合成单件，减少松动接口。
- 导槽在母螺纹前结束，保留连续的后段参考螺纹。L6 螺纹包络最小壁厚约 1.57 mm；导槽与薄片捕获槽还有更薄部位，不能用该数值代替整个杯体强度。
- 四片受约束的导向薄片缩小后背片反转空程。捕获依赖已装入的滑动座；检查六向平移及几个磨损位置，不证明任意弹性脱出路径不存在。
- 短双 D 锥面输出接口包括中心保持螺钉、垫圈、四孔法兰。L6 后伸由 O5 的 34 mm 减至 23.4 mm，节省 10.6 mm；真实锥面、公差、预紧和连接梁仍未定型。
- L6 支承跨度试验值由 14 mm 减至 8.2 mm。按旧 0.04 mm 合计间隙/同轴度预算，几何倾斜项由约 0.164° 增至 0.280°。这不是实测编码器误差，也不是精度通过项。
- M4 采用 4 mm 轴和为 8 mm 碟簧重建的导向、杯体、输出接口。磁铁、AS5048 参考 PCBA 及连接器未缩放。增加小规格是为处理实际干涉，未重新强制推行整机减重。

| 当前原生模型 | 零件数 | 模型质量 | 外包络约值 | 磨损/压缩组合 |
|---|---:|---:|---|---:|
| L6 修订 | 58 | 63.66 g | 37.3 × 34.0 × 49.2 mm | 52 |
| M4 试验 | 58 | 25.42 g | 27.5 × 23.6 × 41.0 mm | 32 |

质量按实体体积与材料密度计算，含模型中的传感器及输出接口，不含完整连接梁、整机壳体、线束和其它未建零件；不是成品实称。

L6 保留原 12 mm SCHNORR 参考弹簧。M4 首个模型采用锐尔立 A 系列 8 × 4.2 × 0.4 mm、目录工作点 210 N 的候选；它不直接替换旧 12 mm 弹簧。此前 12.5 mm 国产碟簧与旧导向孔干涉的否决仍有效。目录工作点不是最大预紧力，批次曲线、公差与寿命未验证。[锐尔立目录](https://www.raleigh-spring.cn/discspring/)

## 新发现的 CAD 证据缺陷

旧 ruled-face 螺旋在本机 CadQuery/OCC 上可能显示实体有效，但切除出现负交集或移除体积大于整个刀具。M4 某次约 1639.308 mm³ 的杯体在“切除”后增至 1765.253 mm³；L6 的同类运算也不守恒。因此，早期名义零干涉和装配通过项不能继续采信。

O6 改用 Frenet 管道扫掠，加入螺旋体积估算、交集上下界以及切除/合并守恒检查，布尔运算明确使用 0.00001 mm 数值容差。**数值容差不是加工公差。** 当前两个模型重新生成、重新验证，没有沿用错误模型的通过项。

[旧版本失效记录](../verification/revO6/runs/o6_20260924_r1/SUPERSEDED.json) 与诊断保留。当前模型只使用 joint_L6_validated 和 joint_M4_validated；joint_short、最初几个 M4 版本及其派生布局只供回溯。旧 O3/O5 封存未改写，也不能因此自动升级为通过。

## 单关节验证范围

验证了 58 件的装配覆盖、径向轴承盒、滑动座前装、后盖旋入及弹簧压缩、5° 步长单轴旋转和磨损/压缩组合。L6 的轴承盒横向螺钉先装，M4 的杯体轴向螺钉先装；错误顺序的失败记录保留。

后导向名义自由角约为 L6 0.1626–0.1628°、M4 0.1292–0.1294°；驱动键与制动盘另做正反方向几何搜索。这不是整关节实测回差，不能把各项简单相加后宣称验收；两面摩擦、载荷、变形、锥面与装配公差均会影响实际表现。

两种空心销式工具已有实体和单关节后方直线接近检查。调预紧前须支撑节段并拆去输出接口和止退螺钉；未覆盖相邻机构、手部空间、工具转动全路径或工具强度。

真实最大弹簧力、前端板螺钉反力和剥牙、锥面贴合、摩擦材料粘接、承载滑动卡滞、生产倒角/毛刺及极限公差仍未关闭。离散磨损补偿可能使部分弹簧压缩略超过目录工作点，必须按实际力曲线和限位重新定调节范围。

## 双臂和载荷

单臂筛选后，增加左右共 18 个模块的同时搜索：12 组机械偏置，每组 100 次确定性随机起点。随后每个离散状态均检查全部 153 对模块。粗包络评分是启发式，不能充当实体相交体积或全局最优证明。

实际完成 100 个状态：Manny 50 个中 22 个失败，Quinn 50 个中 24 个失败；每状态覆盖全部 153 对模块。当前仍有必要动作的关节实体碰撞，**完整双臂未通过**。双侧优化消除了部分肘、腕朝中线堆叠的问题；肩部多轴模块和抱臂仍有缺口。移动采集板不能直接解决关节本体碰撞。

机械试验 profile 明确记录内部枢轴和安装偏置，不作为 UE 生产校准。还缺实际连接梁、完整 PCBA、颈胸机构、壳体与连续曲率线束；某姿态模块间无碰撞不代表完整单臂通过。

载荷按每件实际 COM 和父/子刚体计算，并显式加入未建连接梁、手部、壳体与线束的工程质量分配。加入躯干倾斜后，锁骨前后轴不能继续按竖直轴零重力矩选型。低摩擦假设下仍有保持力缺口，报告同时列出操作力，没有统一增加所有关节预紧。它是悬空单臂分析，不覆盖以手撑地、外物载荷或完整人偶支撑反力。

## 背部集中备选 B

用现有六块区域板的实际板尺寸、元件庭院和原插头预留试排共用壳体。保留 12 mm 弯线敏感性时，一个紧凑排布约 **83 × 103 × 83.2 mm，711.3 cm³**；旧六仓合计 950.4 cm³，不含电源仓和支架。重复壳体有所减少，但仍很厚。

这些板未布线，部分配合头/元件高度未确认，六个无线模块的完整 RF 空间也未满足。711.3 cm³ 不是合格成品体积。粗运动筛查仍有背手遮挡。另列的 66 × 76 × 22 mm 只是中央板重排目标，没有实际 PCB，不能用于报通过或报减重。

按真实父子刚体关系得到的跨轴线数如下，范围仅为六芯原始传感器线和 J50，不含无关干线：

| 左臂截面 | 原始线全回背部 | A：14 芯 J50 | C：4 芯 J50 |
|---|---:|---:|---:|
| 肩俯仰 | 36 | 26 | 16 |
| 肩外展 | 30 | 20 | 10 |
| 上臂旋转 | 24 | 14 | 4 |
| 肘屈伸 | 18 | 18 | 18 |

九路端口总计 54 芯，不表示每根肩轴都经过 54 芯。要缩小背部方案，必须同时重排电路和回线，不能只挪 PCB。

随后补做了背部空间扫描：630 个宽、高、厚、安装高度组合，61 个目标姿态，从中立位按不超过 5° 步长插值，每个角色 837 个路径状态。20 个方盒只通过了明示半径的人体胶囊包络筛查；其中薄型目标为 54 × 48 × 22 mm，位置在胸部局部 z=30～78 mm。

**该薄型目标被真实关节检查否决。** 六板共仓盒和上述薄盒分别放入当前双臂布置，各检查 100 个状态，两者均在全部 100 个状态与至少一个真实模块相撞，主要涉及锁骨机构。此结论只否决这两个盒子及位置与当前布局的组合，不证明所有背部方案都不可行。它说明背部方案必须与肩锁骨机构共同布局，不能把人体包络通过项当作板件已经放得下。新检查见 [背部空间及真实模块报告](../verification/revO6/runs/o6_20260924_r1/backspace/)。

## DC1：薄背部控制器的串行链路数字实验

原厂资料描述 AS5048A 菊花链及后一传输返回上一命令结果的流水线。本轮新增隔离的 DC1 数字实验：五个诊断/角度/零位寄存器加最后 NOP，保留 O5 诊断判定。**未接入固件、G0 或 UE，未生成中央 PCB。** 原厂“四线 SPI”加供电和地至少六芯，返回线及分叉/连接器仍须实际设计。[原厂手册索引](https://look.ams-osram.com/m/d6b55afbdfe4b3d0/original/AS5048_UG000223_1-00.pdf)

官方索引可读，直接手册下载本次返回 404；未用第三方镜像替代原厂依据。近端/远端顺序仍须台架验证。

数字实验覆盖 1/3/6/7/9 芯片、2080 个单比特翻转、长度错误、全零和全一。明确保留三类不能据此排除的反例：有效帧整体重放、有效响应列重复、偶数位错误。41 个有效角度字不能证明 41 个物理测量节点存在。

41 轴每链六次传输，仅增加假设 CS 开销时，50 kHz 约 78.828 ms、100 kHz 约 39.468 ms。它们是计算值，不是驱动或电气实测。25 kHz 超过当前 100 ms 软件扫描预算，本实验未改写 A 的约束。静态用途允许今后调整节奏，但仍须保留样本年龄、完整性与故障语义。

DC1 的 capture_eligible 固定为 False，缺少链序/断链识别、线束信号完整性、供电及保护实测时不能替换 A。若将六区域控制器合并为一个 MCU，必须重新说明共同故障域，不能继续引用七个物理 CAN 节点的结论。

## 供电与供应商

保留 AS5048 和当前接口基线。M4 是本轮实际采用中国供应商尺寸的数字候选。MT6701 + CJT O5CN 板继续隔离：新读取的官方中文 Rev1.9 图示与低空闲时钟解释更一致，但 CRC 初值/参考向量、EP、真实精度与波形尚未关闭。[MT6701 官方资料](https://www.novosns.com/en/datasheet/MT6701QT-AAD/MT6701_Rev.1.8.pdf)

峰值预算计入传感器、MCU、收发器无负载电流及端接负载，约 145 mA 是条件分配，不是验证后的最大电流。0.305 m、60°C、150 mA 算得约 3.055 V；200 mA 仅约 3.028 V，仍不满足 3.05 V 工程余量目标。JST 路径采用每压接 10 mΩ 仅作敏感性分析，不能用 CJT 数据保证 JST。降频减少平均功耗，不能省去峰值、启动或短路检查。

## 未关闭工作

1. 数字机械：多轴共同承力结构及连接梁、完整 PCBA/颈胸/壳体/线束联合装配；不得缩小动作清单来制造通过。
2. 背部备选：先与肩锁骨机构共同确定可用空间，同时解决 DC1 的故障/链序验证，再做原生中央板和真实线束。当前两个目标盒与实际模块相撞，不能用于宣称背部设计合格。
3. 需要实物或供应商资料：弹簧曲线、公差、摩擦/磨损/粘接、轴承/锥面精度、压接、信号波形、功耗保护及静态保持。

未 commit、未 push；O5/O5CN 封存及 UE 用户配置保持原字节。复算与审查入口见 [O6 审查请求](REVIEW_REQUEST_REVO6.zh-CN.md)。

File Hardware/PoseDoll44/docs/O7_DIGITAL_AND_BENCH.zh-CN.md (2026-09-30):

# Rev O7：扁平关节、背部空间与实物测试边界

本轮保留480 mm人体参考、静态姿势采集、91 cm备用方案和取消1.2 kg硬门槛的决定。现有UE插件和A固件未改变；O5/O5CN/O6封存及UE用户配置已复核。

**LP6 单关节名义装配与寿命几何已通过限定检查，薄背盒得到可用的空间目标；完整双臂仍失败。现在建议先测摩擦材料和碟簧，再决定多轴机构尺寸与预紧范围。没有实物测试或制造放行。**

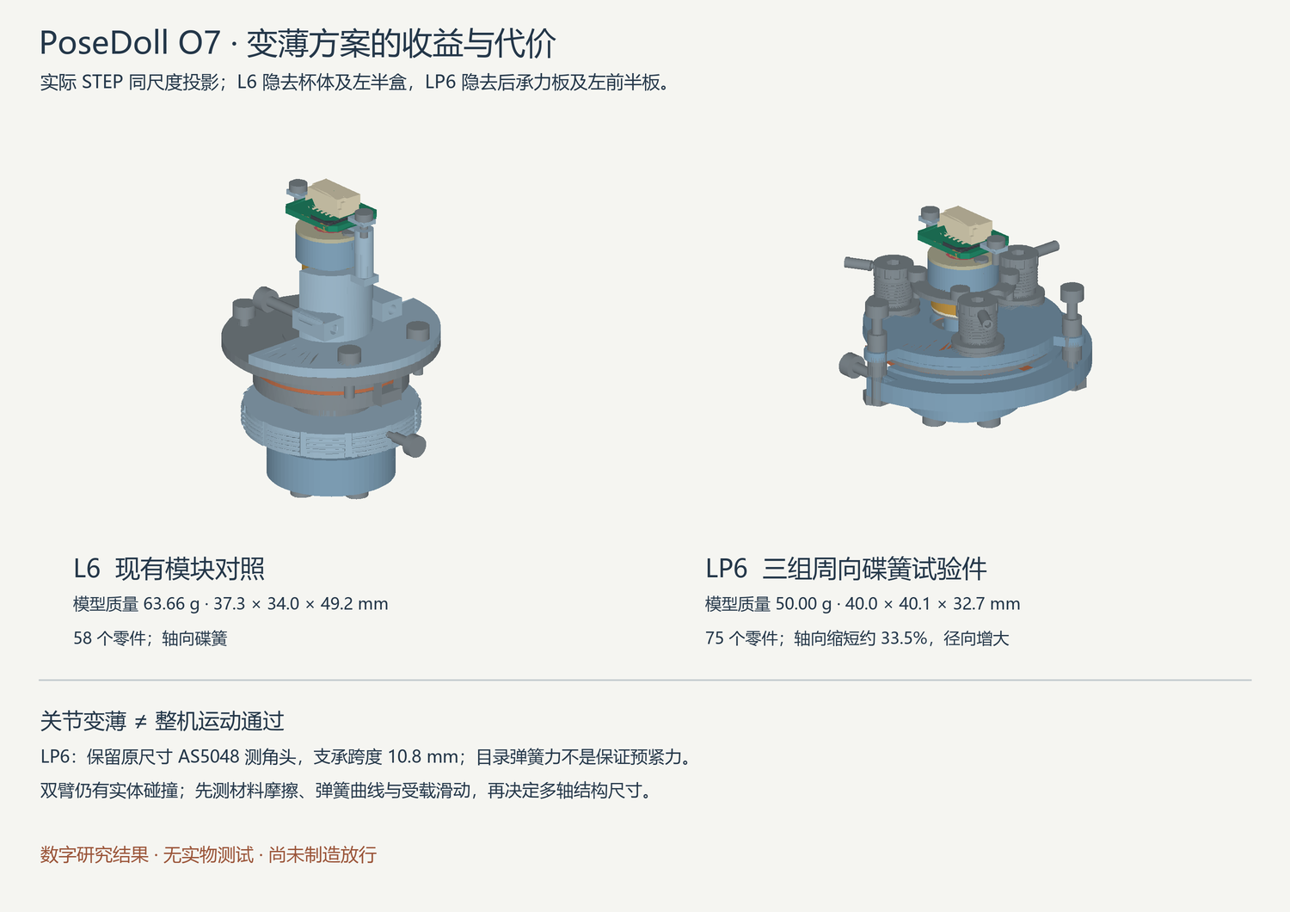
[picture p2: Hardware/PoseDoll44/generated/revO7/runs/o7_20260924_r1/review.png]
实际STEP同尺度比较


## 已落实的改动

| 项目 | O6 L6 对照 | O7 LP6 研究候选 |
|---|---:|---:|
| 轴向包络，含传感板/输出接口 | 49.24 mm | 32.74 mm，缩短约33.5% |
| 径向外包络 | 37.3×34.0 mm | 40.0×40.1 mm，增大 |
| 模型质量 | 63.66 g | 50.00 g，减少约21.5% |
| 零件数 | 58 | 75 |
| 两支承中心距 | 8.2 mm | 10.8 mm |

以上是实体体积/密度和包络计算，不是整机实称，也没有包含实际多轴连接梁、全身外壳、全部电路与线束。LP6没有因变薄而自动升格为最终选型。

LP6把两片串联的小碟簧分布到三个周向位置；前后承力板与外围拉紧件传递预紧反力，测角轴另有轴承/轴向基准。原尺寸AS5048参考PCBA与磁铁保留。输出法兰与轴做成一体；后轴承座轴向装入，轴环、前支承和轴承保持板分体装配。三组碟簧的真实力不均、承力板挠曲及导向卡滞尚未证明。

板托增加中央直径11.3 mm装配通道，同时横向加宽支承面。对真实PCB实体计算，两侧各保留约2.70 mm²名义接触面积；不是删除板托来获得空隙，也不是夹紧强度通过。绕开板托装入后轴承、在凸台上方合拢保持板等顺序已进入路径检查。受限工具、生产紧固件牙型和任意维修路径仍未验收。

采用锐尔立B系列8×4.2×0.3 mm作为LP6试验碟簧尺寸。每对串联的目录工作点118 N，三个理想相同站点合计354 N；这不是最大预紧力或整关节额定值。[锐尔立目录](https://www.raleigh-spring.cn/discspring/)

## 修正了什么检查问题

1. O6的磨损补偿向上取整，L6的52个状态中51个、M4的32个状态中29个会略超过名义目录压缩点。O7改成不超过该名义点的向下取整，并分别重跑52/32个实体状态。它可能降低保持力，且不能代替实际公差/力曲线或硬件限位。
2. 小径螺纹出现新的OCC反例：先开底孔再切螺旋时，实体有效、同源布尔守恒也能通过，却几乎没有切掉应有材料。独立六整圈积分应去除9.2303 mm³，坏顺序只去除约0.000004 mm³；改为先切螺旋再开底孔，实际去除9.2408 mm³，材料见证点也被切除。新增独立体积和见证点回归，不靠`isValid()`判断完成加工。
3. 保留全部O6动作。原样本中有18个角色/姿态条目超出原profile范围，现明确标为额外应力测试。原对称抱臂使两前臂中心线几乎相交；新增一高一低的非对称抱臂候选，并继续用真实模块检查，没有把旧碰撞改写成通过。
4. 手动抬臂力现在包含重力：所需操作扭矩包含制动阻力和逆重力分量。旧“摩擦扭矩÷手持力臂”只能描述摩擦部分。

## 实际完成的数字检查

- LP6当前75个零件：名义无体积干涉；69个分步装配检查覆盖全部零件；73个单轴转角位置，步长5°。
- 37个磨损/压缩/单站少压一档的几何组合无干涉；每片弹簧都没有超过名义目录压缩量。**压力板力平衡没有因此得到证明。**
- 轴环、传感器杯和摩擦片共30个六向平移尝试都有实体阻挡；这不是拔脱强度或任意脱出路径证明。
- 几何反向自由角区间：驱动键约0.062°，压力板导向约0.065°，每个摩擦片耳槽约0.075°。不能直接相加当作整机回差，也不是编码器精度。
- 双臂18模块、每姿态153对：102个状态仍有45个失败（Manny21、Quinn24）。在保留的旧100个状态中43个失败，O6为46个；新增加的两个非对称抱臂状态也失败。收益有限，不能把独立LP6复制到所有关节就宣称整机可用。

完整原始结果和输入哈希见[汇总](../verification/revO7/runs/o7_20260924_r1/results.json)。当前只使用 `LP6_current` 与 `bilateral_current`；前六次试验及失败原因见[历史标记](../verification/revO7/runs/o7_20260924_r1/SUPERSEDED.json)。

## 背部集中方案取得的进展

在630个空盒目标中，用当前试验机构与人体节段共同筛选，再对候选做实际零件检查。**48×48×12 mm、胸部局部坐标 `[-40,-24,0]～[-28,24,48] mm` 的空盒目标，通过了两个人体参考、102个目标，共1,700个中立到目标的采样状态检查，关节角步长不超过5°，满足0.5 mm检查门槛。** 未证明任意多轴协调路径或受载运动。

这给薄型背部中央板提供了空间目标，但它**没有装入任何完整中央PCBA、插头、壳体、固定梁、线束或RF预留**。其它未建的颈胸/腰机构也可能占用该空间。它不能与旧六板共壳711.3 cm³直接比较并称为硬件缩小到27.648 cm³，更不能证明整机动作通过。

O6的DC1仍是不可进入生产采集的隔离实验。集中采集架构还需要实际信号、链序/断链识别、共同故障域、供电与保护证据，才能进入中央板定型。

## 为什么下一步先需要实物

当前悬空臂预算约454.5 g，含明确列出的152 g未建附件分配，不是成品臂实称。按当前逐件重心和动作，LP6最苛刻保持预算约0.463 N·m；M4约0.304 N·m。按均匀磨损半径和目录力点估算，最低有效摩擦系数分别约0.065和0.145；它们只是设计条件。

未填充PEEK原厂页面的摩擦数据来自特定试验条件，不能证明本项目在薄片、停留、表面处理和反复反转下满足这些条件。[原厂数据](https://www.ensingerplastics.com/en-us/shapes/peek-tecapeek-natural)

以暂定20 N、60 mm力臂作手感初筛，摩擦从0.08变化到0.22时，LP6不能在同一固定预紧力下同时保证最小保持力和最大摆姿力。实际摩擦范围若较窄则可能存在窗口。继续仅用一个假定系数缩小关节，无法回答这个关键问题。20 N和0.3°停留漂移是台架初筛提案，并非用户已确认的最终验收标准。

[小样台架任务书](../bench/revO7/README.zh-CN.md) 已提供：两种尺寸的四个试片STEP/尺寸表、弹簧曲线和摩擦记录模板、当前载荷导出的筛选条件、原始日志哈希校验与23项数据入口反例测试。空模板仍明确返回 `AWAITING_HARDWARE`。

建议先完成这一小样阶段，再用实测结果决定各轴预紧、是否保留M4锁骨轴以及多轴支架的真实尺寸。完整单关节生产图、承力/公差验收和整机联合动作仍有工作；本轮没有把这些部分写成已完成。

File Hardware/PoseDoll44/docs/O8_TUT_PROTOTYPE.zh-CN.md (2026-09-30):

# Rev O8：从论文 TUT 到可验证的核心改型

运行：`o8_20260925_r1`。本轮继续采用 **2016 TUT 作为多轴核心研究候选、保留 O7 LP6 备用** 的路线，实际恢复并修改了几何，增加了装配、紧固件与配合试验。尚无硬件实测；没有整关节、单臂或整机制造放行。

面向新手的入口：[看真实零件与装配动画](../tutorials/tut-prototype/index.html)。第一批动作：[打印配合小样任务书](../bench/revO8/README.zh-CN.md)，4 类量规、共 6 件，附 STEP/STL 与空白记录。

## 1. 本轮决定

- 两只叉架各局部加长 **2 mm**，保留原轴心、轴颈、分体环与中央磁铁杯附近几何。它是截面拉长，不是整体缩放。0 / 1 / 2 / 3 / 4 mm 都有真实几何与对比结果。
- 先验证 **打印配合**，然后验证核心的实际阻力、松动和保持。暂缓 O7 专用 PEEK、碟簧批量采购；不直接照论文整套 PCB、滑环和外壳下单。
- 肩部安装方向作为候选调整，所有 O7 测试姿势和中立到目标的采样路径保留。这里完成旋转映射，尚未证明胸肩、外壳、PCBA、线束和手臂的共同空间。
- 中央两方向测量先保留 **原始有符号三轴磁场** 的实验路线。不能直接把旧固件的两个 joystick 输出数值当成跨过 90° 后仍无歧义的关节角。
- 静态 CaptureID / 新鲜度 / 故障语义、44 轴控制语义不变。480 mm 解剖参考、910 mm 备用以及取消 1.2 kg 硬上限的要求继续有效。

这不是已定型的供应商或最终结构选择。先在当前候选上取得必要的配合与承载证据，再决定是否修改材料、配合、结构或回到 LP6。

## 2. 确实恢复了什么

来源为 [atamid 的固定提交 9a152b1d82374d1960ebd2216563fb30b1b6875b](https://github.com/oliglauser/atamid/tree/9a152b1d82374d1960ebd2216563fb30b1b6875b)。原始 `jointTUT.stl` 未改写，SHA256 为 `05bc819a65068a68afdb275a639b267ba840d8e2f574fd21368b655a3bf570e0`。

从打印排版网格分离零件，去掉外部打印框与连接杆，利用圆柱端面、轴颈圆截面及半环平面恢复刚体位置。当前只恢复：

| ID | 含义 | 所属刚体 |
|---|---|---|
| C01 | 输入叉架与中央磁铁杯 | 输入端 |
| C14 / C15 | 下半环 / 上半环 | 中间环，绕第一轴转动 |
| C02 | 输出叉架 | 绕第二轴转动 |

没有把其他外接壳、锁扣或打印连接杆误计为已装好的模块。完整原 TUT 的两端 twist 接头、传感 PCB、线束、滑环与控制板仍未恢复成总装。

恢复轴心时，先用附近端面猜测的轴心造成 1.5 mm 偏差，继而通过实际轴颈截面圆心纠正；`reference/core_motion_initial_registration.json` 保留这次失败历史，**不能作为原设计缺陷结论**。最终恢复见 `reference/assembly_recovery.json`，最终动作检查见 `reference/core_motion.json`。圆拟合的微小残差只是网格拟合数值，不是实物制造精度。

## 3. 数字实验结果与准确范围

主要输出均在 [本轮运行目录](../generated/revO8/runs/o8_20260925_r1/)。穿透见证采用 VTK 表面接触与闭合网格有符号距离；超过 0.02 mm 才记录为穿透，接触但没有足够深度见证的结果保留为需审查，不默认通过。独立回归包含解析方盒、旋转、包含、独立多实体完全包含与间隙反例，共 19 项。

| 检查 | 实际结果 | 不能据此声称 |
|---|---|---|
| 原始四件核心：97 个离散角度 | 89 个无名义穿透；8 个失败 | 完整原设备有 89 个合格姿势 |
| 五种叉架长度：各 21 个关键角度 | 0 / 1 / 2 / 3 / 4 mm 分别通过 5 / 9 / 9 / 13 / 17 个；其余失败 | 选择通过最多的就一定最好 |
| 2 mm 改型两叉架间隙 | 中立、第一方向 +95/+100°、第二方向 +95/+100°这 5 个指定姿态的非配合面间隙保守下界 ≥0.6 mm | 所有正负角度、混合角度、实体公差和连续运动都有 0.6 mm |
| 加入 4 颗 M1.6×6 螺钉与 4 颗螺母 | 57 个离散姿态中紧固件没有对叉架穿透；座面接触独立记录 | 这 57 个姿态整体都通过，或螺纹强度通过 |
| 1.5 mm 六角工具杆 | 四个角各找到一组可接近的姿态 | 一种固定姿态能拧到全部螺钉，或任何手柄都能放入 |
| 五段核心装配平移 | 共 123 个离散位置无穿透；最后半环端面接触明确列为预期接触 | 连续路径、公差、手指操作和紧固顺序已经实物通过 |
| 量规实体 | 4 类 CAD 均为有效单实体；STEP 往返体积误差 <0.0001 mm³ | 打印一定达到模型尺寸 |
| 理想磁场实验 | 189 个域内角度往返；4 个歧义反例；2 个非法场输入拒绝 | 已取得传感器实际精度 |

原始四件核心在单方向 ±100°、以及两个方向各 ±75° 的四种组合出现碰撞。加长 2 mm 后，单方向 ±100° 的名义核心检查通过；±105/110° 和双向 ±75° 的组合仍失败，明确保留。1 mm 虽已消除所检查的单向 100° 穿透，但没有达到这次 0.6 mm 间隙筛选，所以当前选择 2 mm，而没有仅按“零相交”选择最短版本。

0.6 mm 是两件各 ±0.3 mm 服务尺寸误差启发的初始避让量，**不等同于严谨的总装公差分析**。间隙算法用“到目标表面的距离减去本三角形半径”给出保守下界，并自适应细分；无法完成的情况应返回 UNKNOWN。它不把最小顶点距离冒充准确的最小面间距离。该算法使用无符号距离，必须结合碰撞/包含检查解读。

关键可复算文件：`reference/core_motion.json`、`fork_search.json`、`fork_clearance.json`、`fastened_core/report.json`、`assembly_path.json`、`collision_regression.json`。

## 4. 尺寸、肩部路径与重量

2 mm 改型的四件核心外包络约 **23 × 23 × 53 mm**；塑料几何总体积 **4603.9955 mm³**。原始四件体积为 4508.3298 mm³，增加约 95.6657 mm³。没有采用未核实的密度把它宣称成“完整关节重量”。金属、外壳、连接件、PCB、线束与实际打印材料仍需加入。

O7 LP6 的约 50 g 是单轴模块的特定建模口径，而这里是缺少外接部分的两弯折轴核心；两者不能直接做减重百分比。整机重量、重心与各轴载荷必须在真实零件所属刚体确定后重新核算。

`map_shoulders.py` 对 Manny / Quinn、左右侧分别保留原来 51 个目标，以及关节角每步不超过 5° 的中立到目标路径，使用十万个方向的球面数值搜索寻找安装轴。结果最大所需弯折约 **95.56°**，矩阵重建误差接近浮点精度。它是数值候选，没有全局最优证明。

此时只选取 TUT 冗余自由度中的一种路径：第一弯折角保持 0，以近端 twist 改变弯折平面，再用远端 twist 配回完整方向。**这不是要求使用者只能这样摆，更不是已验证的自然手感**。该路径近端转角跨度接近 334°，必须继续处理有限转角止挡、线束连续路径与更好的四角分配；不能因为静态采集就默认电线可以无限扭转。

这里验证的是旋转表示，不是新肩机构、骨长、负载、完整动作与空间验收。原有 45/102 个双臂失败状态没有被这一局部实验改写成通过。

## 5. 紧固和装配细节

半环采用 M1.6×6、螺距 0.35 mm 螺钉及名义对边 3.2 mm、厚 1.3 mm 的螺母；相邻角头部方向交替。螺钉头部 Ø3×1.6 mm；座面到螺母的几何关系已建模，螺母内孔采用略大于螺纹大径的包络，仅用于避让。

1.3 mm 几何啮合长度不是强度结论。未建立生产螺纹、螺钉等级、打印材料压溃/蠕变、预紧力、松脱和磨损合格结论。四个角的座面接触有记录，未简单删除整对零件的碰撞检查。

装配候选顺序：两叉架沿轴向交错放入；下半环先在轴心下方 7 mm 从侧面送入再抬起；上半环在轴心上方 7 mm 从另一侧送入再落下。先有几何路径，再按它制作动画。螺钉放置、拧紧与工具接近不能替代完整的受力与保持检查。

## 6. 传感器复用的新约束

根据 [MLX90363 官方数据手册](https://media.melexis.com/-/media/files/documents/datasheets/mlx90363-datasheet-melexis.pdf) §13.4.1 / §16.2，原始三轴场输出需要正确处理符号、Z 灵敏度和标定；片内 joystick 公式对其中分量取平方。理想磁偶极反例中，85° 与 95° 的两个姿态在这种折叠表达下可相同。

`sensor_observability.py` 因此保留有符号场实验，并明确：磁铁必须跨越两个弯折关节；若移到中间环，会丢掉第一轴的观测。第一弯折到 90° 也存在另一角不可观测的理想退化；域外还有相同磁场的姿态别名。单靠软件范围检查不能识别全部别名，需要真实限位、可观测工作域与标定。

这个实验尚无实际 PCB / 固件驱动接入。有限磁铁、位置误差、间隙、邻近金属/磁铁、温度、重复性，以及 SPI 的 CRC、诊断、滚动计数和采样新鲜度仍需处理。论文精度没有转写成项目的已达指标。

## 7. 下一步与当前停止点

**当前先需要打印配合小样的实际结果。** 这些细小轴孔和螺母槽的实际尺寸、摩擦与变形不能用论文或服务商的通用公差替代。未解决它们前继续确定最终预紧或按比例扩展整机，会把未知量带到下一阶段。

量规数据决定工艺补偿；随后是四件核心的装配/松动检查和具备合适夹具的保持、起动、正反向与停留实测。完整测矩夹具、外接 twist 接头、有限转角走线、中央传感 PCBA、肩/单臂共同总装、全身载荷与动作仍是后续数字工作，**并不是只剩实物测试**。

若配合能稳定复现、同时存在足够保持又易于摆姿的调节窗口，就在本方案继续；否则先根据实际失败原因调整，再比较 O7 LP6。此时没有需要用户在互斥方案间作出的新取舍。

## 8. 文件与复算

- 源码：[cad/revO8](../cad/revO8/)；从真实 STL 特征恢复、局部截面拉长、碰撞/间隙、紧固、路径、旋转与磁场实验分开。
- 输出：[generated/revO8/runs/o8_20260925_r1](../generated/revO8/runs/o8_20260925_r1/)。JSON 保留失败、范围与 `physical_tested:false`。
- 量规：[bench/revO8/fit_gauges](../bench/revO8/fit_gauges/)；打样任务书与空白模板在上一层。
- 教学页面：[tutorials/tut-prototype](../tutorials/tut-prototype/index.html)。离线 WebGL，不引用 CDN，不进行实时碰撞判定。

在设计仓库根目录，使用现有 `tools/run_cad.py` 启动装有 CadQuery / VTK 的运行环境，例如：

```powershell
.venv/Scripts/python.exe -X utf8 Hardware/PoseDoll44/tools/run_cad.py Hardware/PoseDoll44/cad/revO8/check_collision_method.py
.venv/Scripts/python.exe -X utf8 Hardware/PoseDoll44/tools/run_cad.py Hardware/PoseDoll44/cad/revO8/audit_reference.py
.venv/Scripts/python.exe -X utf8 Hardware/PoseDoll44/tools/run_cad.py Hardware/PoseDoll44/cad/revO8/search_forks.py
```

依赖顺序为 `reference_features` → `reference_assembly` → `extend_forks` → 各数字实验，`build_fit_gauges` 生成量规。`reference_features` 需要 NumPy；静态预览图使用 Pillow；完整软件路径与输入哈希见 `evidence_manifest.json`。本轮没有构建/运行新的 ESP-IDF 或 UE 固件改动，也没有提交 commit 或推送。

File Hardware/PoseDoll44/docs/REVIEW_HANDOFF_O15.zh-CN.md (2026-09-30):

# O15 提交与审查入口

本次将 O4 提交 `451cbe0` 之后尚未入库的 O5—O15 设计、固件、桥接、历史证据与最终统一试制包合并为一个审查检查点。分支为 `design/revO-desktop-external`；审查时记录实际读取的 `git rev-parse HEAD`。用户自行 push。

先阅读 [O15 详细审查请求](REVIEW_REQUEST_REVO15.zh-CN.md)，再看 [最终汇总](../generated/revO15/runs/o15_20260929_r1/FINAL_BATCH_SUMMARY.json)、[工作记录](../cad/revO15/WORK.md) 和 [中文装配指南](../bench/revO15/guide.html)。历史封存文件中“未提交”等描述是生成时的快照，本次没有改写这些文件或重新宣称物理验收。

## 本次交付

- 全身打印机构与实体连接架，头、手、足和背部设备；Quinn 默认、Manny 备选。每套 214 种文件、273 件打印件，只选一套数量。
- 46 个原始编码器映射为 41 个测量语义轴与 3 个固定骨盆槽。6 条链共用一个身体控制器；静态采集，缺失/故障/未标定不能保存为有效姿势。
- 原生 KiCad 中央载板和传感小板、制造文件、线束清单、BODY/G0 固件与 UE 桥接工具。
- [Quinn ZIP](../bench/revO15/PoseDoll_O15_Quinn_Prototype.zip)、[Manny ZIP](../bench/revO15/PoseDoll_O15_Manny_Prototype.zip)；采购、打印方向/支撑、装配、标定模板及集中测试记录均随包。

## 证据与边界

本轮已记录 242 个几何文件的实际通用切片、每体型 416 步原始角度路径和 689 个设备/刚性尾线工况检查；两板原生 ERC/DRC 与连通性通过；BODY/G0 编译及真实 UE 接收合成数据的正常/故障反例通过。提交前重跑桥接测试 88 项通过（含 O5 与 O15）；仓库历史输入检查通过，O14 封存验证与其上游链通过。一次测试因沙箱的系统临时目录权限导致夹具初始化失败，改用工作区临时目录后全部通过，未修改产品逻辑。

没有重跑整套 CAD 或制造测试；哈希检查用于确认交付与已完成报告一致。重点仍是完整手工装配/工具可达性、FDM 强度与蠕变、预紧与保持力、柔性导线的夹线/拉力/疲劳、最远端供电与信号波形，以及 46 轴实测标定。约 1.65–1.67 kg 是预算。采样姿势无未解释相邻干涉不等于连续运动无碰撞；允许非相邻部位通过摆姿避让。所有实测集中在同一批样机完成。

## 克隆后的使用与复核

```powershell
python scripts/verify_o15_review.py
python scripts/serve_posedoll_tutorials.py --port 8769
```

打开 `http://127.0.0.1:8769/tutorials/full-doll-o15/index.html`。验证器只需 Python 标准库，按当前克隆路径解析原始绝对路径清单，核对最终报告/源码、固件源文件与日志及两个 ZIP；它不运行 CAD、ESP-IDF 或 UE，也不会宣称硬件通过。原 `FINAL_EVIDENCE_INDEX.json` 和各 ZIP 保持原字节。

Git 收录最终查看器、打印几何、两个交付 ZIP、原生电路及必要历史依赖。浏览器临时会话、output 开发临时文件、通用诊断 G-code、Python 环境、ESP-IDF 构建目录、下载的工具安装包不入库；文件仍留在本机。大型生成数据不等于新克隆中能直接运行所有开发搜索脚本，重建需要各脚本指定的 CadQuery/Manifold/KiCad/PrusaSlicer/ESP-IDF 工具；UE 实测需要独立 UE 工程。

## 包完整性

- Quinn SHA256：`83981bd77a43e3ca6ae00cf691d2a072229715fc54f09c2cc00b507f0e017b36`
- Manny SHA256：`e80579b8bd3ac2b2960c1bd5a562b0e81753d15b79569c7e625a4b0cf09d9ebc`

两个 ZIP 各 512 个文件，内部 510 项内容哈希和 ZIP CRC 已检查；几何 manifest 的体型与 214 种/273 件数量另行验证。

提交整理补充：O15 原生协议测试重新通过（1536次报文位翻转、192种截断、4400次传感响应位翻转及10种链长）。从 Git 暂存区导出的独立目录也已运行交付验证器通过，避免仅靠本机未入库文件通过验证。全量 `git diff --check` 会报告旧源码的文件尾空行以及原始生成文件/日志的行尾空格；这些封存字节有哈希绑定，予以保留，不把该格式检查宣称为全量通过。新整理的首页、本文、ignore与验证脚本单独进行格式检查。

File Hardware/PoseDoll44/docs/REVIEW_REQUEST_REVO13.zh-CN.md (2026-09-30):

# O13 审查请求

先读 `O13_FULL_DOLL_PROGRESS.zh-CN.md`，再查看运行 `o13_20260929_r1` 和 `cad/revO13/README.md`。

用户本轮已亲自装好 O12 小样，授权按本件装配/初步手感通过继续。整机允许人手支撑，优先自保持；1.2 kg 上限已取消，仍以静态摆姿采集和家用 FDM + 现货小件为主线。

请重点审查：

1. 6 mm 螺纹现货在完整核心中的保持与装配结构，2.8 mm 塑料承压台阶及四件核心的试装范围是否合适。
2. 8 mm/侧肩部安装偏移、连接架实体联合、外側扭转座及其后续可装配性；不要将 102 个端点清除扩展为全路径通过。
3. 旧腕部基线 10 个失败、紧凑腕部联合布局 6 个失败、补充独立端点 136 个清除三者的区别，以及剩余组合姿态如何解决。
4. 腕部传感器/支架仍是占位，真实固定、磁场、线束和原始传感器数量尚未确认；44 个语义轴位没有直接证明测量硬件可行。
5. 新连接架与紧凑腕部的质量/载荷预算是否存在遗漏或重复，手托场景是否清楚地区分情景计算和实测。
6. 尚未细化的颈、腰胸、髋腿脚如何优先复用当前结构，何时需要新的关节布局。用户没有要求为减重而重做全部规格。

保留所有失败及未完成项。不要用小样实测通过、手托许可、空的背部预留或参考骨架推断整机制造放行。

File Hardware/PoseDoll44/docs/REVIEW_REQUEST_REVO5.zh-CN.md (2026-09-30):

# PoseDoll Rev O5 数字交付与下一轮审查入口

本轮按用户“目前没有硬件，先完成可验证的数字工作”执行。**UE 恢复与采集协议的软件部分已有实际测试；胸肩布局仍有确认的冲突，C 方案暂缓定型。未做实物测试，也没有制造放行。**

设计基线 `451cbe0aa0c0b4016bee3da4d1dedc340a4c28f1`，UE 基线 `90e5104c63ea2b807ee2ea6e4cb63d21d8773687`。运行 `o5_20260924_r1`。本交付为工作区结果，尚未 commit/push；后续提交号不能回写成先前测试时的 HEAD。用户原有 UE `Config/DefaultEditor.ini` 保持且排除在补丁外。

## 本轮结果

| 范围 | 实际完成 | 尚未关闭 |
|---|---|---|
| T0 | 双仓库输入、旧 O4 产物、用户改动和最终源包的哈希核验 | 无制造含义 |
| T1 | UE 有界已结束 ID 分流；PDR4 单扫描幂等缓存/原年龄保留；10 Hz 新扫描与旧缓存过期分离 | C 的 STM32/UART/DE 入网与驱动未实现/未实测 |
| T2 | 拒绝 SH+26 AWG；落实 SH+具体 28 AWG 候选；48 条供电敏感性条件与单臂草案长度联算 | 压接工艺、实际长度、电流/浪涌、压降/温升/弯曲寿命 |
| T3 | A 请求式 AS5048 节点/G0 代码、PDG5/PDC5、严格主机 PDS1 桥接；7 个固件角色编译 | 串口/SPI/CAN 实物闭环与物理标定未运行 |
| T4 | 同一 Manny/Quinn 单臂试验 A/C 对比；9 路传感线、双侧近端板、N2、RF/插头/工具包络；每方案 26 姿态 | 两方案共享的胸肩冲突；叉架、外壳、完整右臂、连续线路/动作仍未完成 |
| T5 | 输出夹持连接几何初稿与扳手空间；承认后端 +16 mm 代价 | 新 PCB 路由、受力额定、结合、背片定位/滑动、螺纹薄壁未合格 |
| T6 | 原 UE 写入与新进程重开继续通过数字回归 | 真实单臂与 41 轴整机未运行 |

1.2 kg 已不是硬上限；仍保留 480 mm 参考、完整本体目标≤500 mm/硬上限≤600 mm、41 测量+3 固定、外置 G0、6 逻辑区/7 CAN 节点、无线和直接手摆。当前定位试验没有获得完整人偶尺寸或质量合格结论。

## 已执行验证

- UE 正常非 Unity / 强制 Unity 构建均成功；5 组原生 Automation，75 项 Python 测试通过。
- 真实隔离 UE 的 8 组迟到消息用例通过：5 组合法取消后重采各写入一次，unknown/CRC/boot 错误各写入零次。集合上限 32、30 s 期限、重连清空，坏旧包继续严格拒绝。
- 24 项桥接 Python 测试通过；native C `/W4 /WX` 覆盖 PDR4 重试/年龄/复位，以及 PDG5/PDC5 的 41 次新读取回调、缺轴、token/boot、分包、CRC 和截断。
- PDG5 合成字节 → 正式桥接 → PDS1 → 真实 UE 的 4 组联调通过。正常数据 Capture 一次，missing/CRC/boot 错误零次。来源 **simulated**，不是硬件可靠性证明。
- 原 Capture、Undo/Redo、蒙版、Clutch、故障回归及另一个 UE 进程的保存重开通过；回读最大旋转差约 0.00000342°，只表示软件序列化一致性。
- ESP-IDF 6.1 编译 G0、N1–N6 全部成功；没有烧录。
- CadQuery 实际执行输出连接与单臂原生模型检查，KiCad 10.0.6 导出继承的 N2 板。N2 导出仍缺 J1/L1/U2 模型，不能作为完整 PCBA 合格证据。

不重复跑 1000 次模拟请求来代替本轮的硬件缺口；旧 O4 的耐久模拟记录原样保留。

## 机械反例和决策

试验布局中，锁骨关节与 N2 实体的求交量：Manny **999.63 mm³**、Quinn **987.82 mm³**；肩关节与近端板厂商天线空域的求交量分别为 **3340.49 / 5393.94 mm³**。这是这组定位的真实 BRep 反例，不是包围盒体积相加，也不能推出所有 480 mm 方案都无解。

A/C 共享这些冲突，故 C 暂缓定型。J50 草案最长约 305 mm；在假设 60°C、线阻 +10%、200 mA 时，C 的 Manny 草案末端计算约 3.036 V，未达到另设的 50 mV 储备。实际最大线长与电流未冻结，不能据此宣称原 3.3 V 供电已经合格。

详见 [机械、线束与局限](O5_MECHANICAL_AND_WIRE.zh-CN.md)、[固件协议](../../../Firmware/PoseDollFullBody/revO5/README.zh-CN.md)、[桥接入口](../../../Tools/PoseDollHardwareBridge/README_O5.zh-CN.md)。建议下轮审查优先决定具体的肩部输出/叉架与 N2/近端板重排，随后在同一可装配路径内比较 A/C；目前继续缩小孤立 C 板没有关闭主阻塞。

## 文件与复算

- [结构化结果](../verification/revO5/runs/o5_20260924_r1/results_revO5.json)：执行范围、工具、测试输入哈希、任务状态。
- [最终双仓库源锁](../verification/revO5/deliveries/o5_20260924_d1/FINAL_SOURCE_LOCK.json)、[交付校验清单](../verification/revO5/deliveries/o5_20260924_d1/DELIVERY_MANIFEST.json)。
- [UE 源码包](../verification/revO5/deliveries/o5_20260924_d1/UE_O5_source.zip)、[相对 UE 基线的补丁](../verification/revO5/deliveries/o5_20260924_d1/UE_O5_changes.patch)，供网页审查，无需访问另一个仓库。源包保留工作文件字节，patch 按 UE Git 的 LF 规则生成。
- [CAD 原生模型及全部直接输入](../verification/revO5/deliveries/o5_20260924_d1/hardware_native_and_inputs_o5.zip)。包含两个明确失败的原生单臂试验 STEP、输出连接候选与已核对输入，保留仓库相对路径；仅在新检出/独立目录恢复，避免覆盖自己的工作。
- [原始日志包](../verification/revO5/deliveries/o5_20260924_d1/raw_logs_o5.zip)：包含被 Git 通常忽略的 UE 日志与既有 Unity 修复记录。运行目录中的 JSON/TXT 可直接浏览。早期失败尝试与最终通过日志分开保留。

在设计仓库运行 `python scripts/seal_revo5.py --verify` 可核验直接文件和 ZIP 内每个成员的哈希，不解压覆盖本地文件。它只验证证据未漂移，不将物理未测或机械冲突变成 PASS。

## 请下一轮重点审查

1. PDR4 缓存与第一次 dispatch 时间在未来 STM32/主控驱动中如何保持；不要改变 `remote_runtime` 的新扫描/重试区别。
2. A 请求式驱动在实际 CAN 和 SPI 下的 100 ms 条件是否有余量，boot/断线/重启能否继续安全恢复。
3. 用哪种可承力的肩部输出与叉架替换当前 +16 mm 后伸夹环试验，如何重新布置 N2 和双近端板以留出 RF、工具和全部线束。
4. 保留具体 28 AWG 候选时，供应商压接与实际电流是否支持 3.3 V，还是需要独立防误接的新供电版本。
5. 仍未关闭的结合工艺、前后背片、外耳空程、最大弹簧力和中断螺纹，应先限定哪一种材料试片/受控关节；没有硬件时只能继续模型和供货资料工作。

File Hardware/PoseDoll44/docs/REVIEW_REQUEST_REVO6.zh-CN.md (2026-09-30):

# Rev O6 审查请求：完整肩臂与背部集中路线

请先读 [本轮设计与结果说明](O6_DESIGN_AND_BACKPACK.zh-CN.md)，再读 [实际结果汇总](../verification/revO6/runs/o6_20260924_r1/results.json)。本轮为未提交工作树；基线 HEAD 为 451cbe0aa0c0b4016bee3da4d1dedc340a4c28f1。实际审查对象由 O6 delivery 的哈希清单固定，不能仅用旧 HEAD 代表本轮代码。

用户要求：静态摆姿采集、没有硬件、1.2 kg 不再是硬门槛；优先推进可验证工作，需要时允许回到背部集中。91 cm 备用版保留。没有改变 41 测量轴 + 3 固定槽位，也没有缩减动作清单。

## 当前证据入口

| 项目 | 相对于 Hardware/PoseDoll44 的路径 | 结论范围 |
|---|---|---|
| L6 原生模型 | generated/revO6/runs/o6_20260924_r1/joint_L6_validated | 58 件，checked pipe 参考螺纹 |
| M4 原生模型 | generated/revO6/runs/o6_20260924_r1/joint_M4_validated | 58 件，8 mm 国产碟簧尺寸候选 |
| L6 正确装配顺序 | verification/revO6/runs/o6_20260924_r1/joint_L6_final | 52 个磨损/压缩组合；名义几何通过 |
| M4 正确装配顺序 | verification/revO6/runs/o6_20260924_r1/joint_M4_validated | 32 个组合；名义几何通过 |
| 双臂共同排布 | generated/revO6/runs/o6_20260924_r1/bilateral_search | 两角色、左右共 18 个模块 |
| 实际双臂相交 | verification/revO6/runs/o6_20260924_r1/bilateral_search/bilateral.json | 100 个状态中 46 个失败，完整机构未通过 |
| 条件载荷与手感 | verification/revO6/runs/o6_20260924_r1/bilateral_search/loads.json | 真实模块 COM + 明示质量分配；低摩擦保持力缺口 |
| 背部六板试排 | verification/revO6/runs/o6_20260924_r1/backpack/backpack_study.json | 未布线原板、未确认配合头与 RF 空间；不是合格 PCBA |
| 背部空间扫描 | verification/revO6/runs/o6_20260924_r1/backspace | 人体包络路径筛查 + 真实模块否决；两者不能互相替代 |
| 独立 DC1 数字实验 | verification/revO6/runs/o6_20260924_r1/daisy/results.json | 2080 单比特反例；仍无法证明物理节点数和新鲜度；不可采集 |
| CAD 内核反例 | verification/revO6/runs/o6_20260924_r1/thread_diagnostics | 旧 ruled 螺旋产生不守恒结果；早期模型通过项作废 |
| 原厂依据 | references/revO6/primary_sources.json | 如实区分完整 PDF、索引片段、缺失资料 |

没有实物测试、生产公差、最大预紧力、整机关节寿命、电气保护或制造放行。UE 与 O5/O5CN 封存按原字节保留。

## 希望优先审查的决策

1. 肩、锁骨和上臂旋转轴仍互相碰撞，继续调独立模块位置是否已收益有限？优先给出一个具有真实轴承、制动受力与输出连接路径的共同承力结构，保留人体比例与必要动作。不要删除碰撞动作或仅画理想重合轴。
2. L6 缩短输出和支承跨度是否值得保留？请评估 8.2 mm 双支承带来的间隙放大、短双 D 锥面、中心螺钉、外圈四孔接口，以及导向薄片的实际保持和带载滑动。
3. M4 国产 8 mm A 碟簧模型名义几何成立，但低摩擦条件下部分轴保持力不足。请根据载荷、手掰力和真实力曲线决定适用轴；不能把 210 N 目录点作为最大力或简单增加所有预紧。
4. 六块旧板共仓仍厚，且实际肩锁骨机构占用背部空间。背部集中应与机构重构共同设计。54 × 48 × 22 mm 的人体包络候选与当前关节相撞，已否决用于当前布局；不应据此宣布中央板可装下。
5. DC1 是 AS5048 菊花链的隔离数字实验。除了校验角度和诊断寄存器，如何证明链上节点数、顺序、身份/新鲜度以及局部断链后的行为？若合并物理 MCU，必须重审故障域，不能继续套用旧七物理节点论证。
6. 检查 O6 螺纹布尔守恒护栏是否充分、磨损补偿是否超出弹簧目录工作点，以及完整装配、工具、线束、PCBA、颈胸/壳体仍缺哪些必要数字工作。

供应商只按有依据的改进更换。保留 AS5048 基线及 Alpha 线材，MT6701/CJT 仍为隔离候选；M4 的新导向已按锐尔立 8 mm 碟簧重建。这不是对供应商或整个机构的最终最优证明。

## 复算方式

在 design 仓库根目录运行。现有报告封存后，请把重算输出写入新目录，不要覆盖封存产物。

```powershell
.venv/Scripts/python.exe -X utf8 scripts/seal_revo6.py --verify
.venv/Scripts/python.exe -X utf8 Hardware/PoseDoll44/tools/run_cad.py Hardware/PoseDoll44/cad/revO6/compact_interfaces.py --compact-bearing --out .local/o6_recheck/L6
.venv/Scripts/python.exe -X utf8 Hardware/PoseDoll44/tools/run_cad.py Hardware/PoseDoll44/cad/revO6/small_joint.py --spring-series A --out .local/o6_recheck/M4
.venv/Scripts/python.exe -X utf8 Hardware/PoseDoll44/tools/run_cad.py Hardware/PoseDoll44/cad/revO6/verify_family_v2.py --joint .local/o6_recheck/L6 --out .local/o6_recheck/L6_check
.venv/Scripts/python.exe -X utf8 Hardware/PoseDoll44/tools/run_cad.py Hardware/PoseDoll44/cad/revO6/verify_family.py --joint .local/o6_recheck/M4 --out .local/o6_recheck/M4_check
.venv/Scripts/python.exe -X utf8 scripts/search_revo6_backspace.py --out .local/o6_recheck/backspace
```

其余原生双臂搜索、相交、载荷、空心工具和 DC1 入口见 delivery 清单中的脚本。CAD 检查退出码 0 表示报告生成完成；设计状态必须读取报告中的 FAIL/PASS 及范围，不能把程序完成当作设计通过。

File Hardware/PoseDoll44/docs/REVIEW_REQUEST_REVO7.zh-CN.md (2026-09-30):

# Rev O7 审查入口

先读 [O7说明](O7_DIGITAL_AND_BENCH.zh-CN.md) 与 [小样任务书](../bench/revO7/README.zh-CN.md)。本轮没有UE/生产固件修改。用户授权推进到需要硬件测试的节点；目前没有硬件。

## 当前输入

- CAD生成器：`cad/revO7/pancake_joint.py`。
- 当前实体：`generated/revO7/runs/o7_20260924_r1/LP6_current/`。
- 单关节检查：`cad/revO7/verify_lp6.py`，当前报告对应同名 `verification/.../LP6_current/`。
- 双臂：`generated/.../bilateral_current/` 与 `verification/.../bilateral_current/`。
- 背盒路径：`cad/revO7/check_back_paths.py` 与 `verification/.../back_paths/back_paths.json`。
- 力与手感：`scripts/analyze_revo7_loads.py`、`scripts/prepare_revo7_bench.py`。
- 证据：`verification/.../results.json` 与 `verification/revO7/delivery/DELIVERY_MANIFEST.json`。

保留480 mm主线、91 cm备用、静态采集与无1.2 kg硬门槛。不要把材料目录值、STEP零碰撞、哈希验证或单面试片推算当成制造放行。

## 希望重点审查

1. LP6分体/轴向装配顺序是否仍有漏项；前后板受力挠曲是否可能改变轴承/测角基准。
2. 三个周向弹簧站点的力不均、三销导向冗余约束和浮动盘带扭矩滑动，哪些必须先测、哪些应先改结构。
3. 磨损向下取整降低保持力的影响；生产限位、实际最大力和紧固件强度仍未闭合。
4. 当前双臂45/102失败，如何在材料实测后做真正的共用多轴支架；不要仅复制LP6模块。
5. 48×48×12 mm是经过1,700个采样路径状态的空空间目标。中央板架构及PCBA/插头/线束/RF尚未放入，如何安排后续链路台架与排板。
6. 首批材料/弹簧小样是否足以决定下一步尺寸与预紧窗口；暂定手感线不是已确认的用户标准。

## 快速复核

在设计仓库根目录执行：

```powershell
.venv/Scripts/python.exe -X utf8 scripts/summarize_revo7.py --verify
.venv/Scripts/python.exe -X utf8 scripts/seal_revo7.py --verify
```

完整CAD命令见汇总的输入文件清单及各脚本 `--help`。不要重新生成到已封存目录；新运行应使用新目录。旧失败模型和调试程序不参与当前通过项，历史标记说明其失效原因。

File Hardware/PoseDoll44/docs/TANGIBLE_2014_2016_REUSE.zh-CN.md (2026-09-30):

# 2014 / 2016 可拼装输入设备：PoseDoll 硬件复用评估

当前数字工作入口：[Rev O9 运动验证页面](../tutorials/motion-lab/index.html)与[报告](O9_MOTION_VALIDATION.zh-CN.md)。先验证运动；O8 的“先打印配合小样”不再是前置停止条件。

后续实施已进入 [Rev O8 核心改型与配合小样](O8_TUT_PROTOTYPE.zh-CN.md)。本文件保留初始研究评估；最新实际验证和打样入口见 O8。

审查日期：2026-09-25。2016 年仓库固定到 `9a152b1d82374d1960ebd2216563fb30b1b6875b`。本报告依据用户提供的两篇论文、2014 硬件包、2016 仓库实际文件，以及当前 O7 结果。没有执行上游固件、重建完整总装或进行实物测试。

**可以利用，而且值得调整下一步的优先级：先研究 2016 年多轴关节与 2014 年摩擦调节结构的适配，保留 LP6 作对照，暂缓采购仅服务于 LP6/M4 的专用试片。当前资料足以开展复用设计，尚不足以直接给出整个人偶的采购和制造清单。**

这不改变 480 mm 人体参考、91 cm 备用方案、取消 1.2 kg 硬上限、静态采集及完整姿势控制要求。论文年代不构成淘汰理由；现有设计也不因已经投入开发就优先于有证据支持的新结构。

## 1. 哪一代的什么值得采用

| 内容 | 2014：TBT | 2016：TUT | 对 PoseDoll 的处理 |
|---|---|---|---|
| 多轴结构 | 两端扭转，中间单轴弯曲 | 两端扭转，中间是正交双铰链构成的万向节 | 优先研究 TUT，用于肩、髋、颈胸等多轴位置；肘膝仍按实际单轴需求设计 |
| 摆姿手感 | 需协调多个转轴；存在万向节锁相关的操作问题 | 改善多方向连续摆动，论文做了用户实验 | 值得复用运动原理；不能由用户实验推导本项目承载、寿命或全范围无奇异性 |
| 保持方式 | 三颗可接近的螺钉调节摩擦 | 论文把进一步控制摩擦列为未解决方向 | 借鉴 2014 的简单调节机构，但必须验证在 TUT 上能否同时做到保持和顺畅 |
| 磁测角 | 3 个单轴角度；BOM 是 MLX90316 | 3 个传感器产生 4 个读数：两次扭转与两个弯曲角；固件使用 MLX90363 | 中央双轴磁测角是有价值的候选；现有 AS5048 单轴板不能原样代替它 |
| 采集电路 | 每关节一个 MCU、局部采集 | 每关节两个 MCU、分布式转发 | 小型局部采集板可能减少跨关节线束；整体供电、故障范围及真实 PCBA 空间要重算 |
| 连续旋转与走线 | 有限角度，柔性导线 | 两个滑环支持连续旋转 | 静态人偶优先研究有限转角与线束余量；滑环先不列为必选件 |
| 上位机 | 拓扑发现、校准、骨架映射参考代码 | 关节选择与姿势插值；应用集成未交付齐全 | 保留现有 UE 采集流程，在传感输入适配层接入新模块 |

TUT 可以理解为：把“向两个方向弯”和“沿骨头拧转”集中到较小的机构中。它不是给几个独立 LP6 换一种外壳；关节内部的转轴、磁铁与电路分布都不同。因此最有价值的是成套的多轴结构和测量布局，而不是只换一颗芯片。

## 2. 已核对的实物设计资料

### 2014：复现资料较完整，但不能直接当作最终人偶方案

论文第 3—4 页、硬件手册第 5—11 页提供结构和装配依据。手册列出 14 个激光烧结塑料件、M1.6/M2 螺钉及螺母、3 颗磁铁、3 块带传感器的电路板、内部线束、光导与胶粘步骤；没有在这份关节清单中列出我们现有的独立 PEEK 制动片和多组碟簧。

PCB 文件包含原理图 PDF、元件表、制板 Gerber/钻孔/外形文件。实际查到的器件包括 MLX90316、STM32F101T8U6，以及 Harwin M80-6810642 / M80-8260642 连接器。手册指向历史激光烧结工艺，不能未经公差验证就按普通 FDM 打印效果判断其结构好坏。

这套资料能减少零件布局、装配顺序、接头锁定和校准设计的摸索。但旧器件库存、报价、PCB 层叠和本项目电气保护尚未核验；不能据此立刻下单。也不建议按比例缩放整个 STL，因为螺纹、磁铁和电路板不会跟着缩放。

### 2016：机械文件真实存在，交付并不是完整套件

[官方仓库](https://github.com/oliglauser/atamid)明确标注资料未齐。实际内容是：

- 6 个机械 STL，包括 `jointTUT.stl`、骨段、分叉件和供电盒；没有查到可编辑的参数化关节 CAD。
- 6 个 TARGET 原生 `.T3000` 电路文件：插针/插座板、中间板、主板、供电板和分叉板。没有现成的 PDF 原理图、整理好的 BOM 或 Gerber 套装，需先用兼容工具导出核对。
- MCU 工程指定 STM32F051K8Ux / UFQFPN32，角度驱动为 `mlx90363.c`；不是 ESP32，也不是把现有 AS5048 接头直接换接即可。
- README 中装配手册尚待编写，MayaBridge 尚待添加，BlenderPlugin 尚在开发。RigReducer 的 CMake 还含 macOS 路径、旧 Gurobi 6.5 和手工依赖路径，不能直接成为 UE 插件。

因此，2016 适合作为有真实文件支持的重建起点；2014 的手册可以辅助理解共同的接头等部件，但不能代替缺失的 TUT 装配说明。

本次未在 2016 checkout 找到以 LICENSE/COPYING 命名的统一许可文件。作者公开了设计且论文称其为 open hardware；在以后直接再分发原文件时，应再核实具体许可范围。本轮仅保存分析脚本、审查结果和可追溯来源，不将整个上游仓库纳入项目代码。

## 3. 本轮实际做了哪些数字检查

使用[审查脚本](../research/tangible_2014_2016/audit_sources.py)读取两种关节的原始三角网格，核对来源哈希，按坐标焊接后的连通表面分组。结果和逐组尺寸见 [evidence.json](../research/tangible_2014_2016/evidence.json)。

| 检查对象 | 2014 TBT STL | 2016 TUT STL |
|---|---:|---:|
| 三角面数量 | 83,596 | 95,548 |
| 原始文件 XYZ 外尺寸，单位按 mm 理解 | 25.30 × 66.26 × 53.86 | 23.78 × 67.00 × 77.00 |
| 连通表面组，坐标分别取 5 / 4 位小数结果一致 | 15 / 15 | 36 / 36 |
| 完整装配外尺寸 | 尚未重建 | 尚未重建 |

**STL 本身不存单位；上表是打印文件的排布尺寸，绝不是关节装起来后的长宽高。连通表面组数也不是零件采购数量。** 2014 手册的 14 个打印件与 STL 的 15 组需要在恢复装配时核对；2016 文件可见外围框架和多根细杆，不能把这些都当作工作零件。2014 最大表面组在此次焊接检查中还有 2 条非流形边，未自动修补或因此宣称不能加工。

2016 的两个主要叉形壳体，原文件局部包络约 23 × 23 × 26.76 mm；其他若干主要壳体横向也约 23 mm。这是值得继续做紧凑总装的依据，**不是已证明整个 TUT 比 LP6 缩小多少的结论**。LP6 当前 40.0 × 40.1 × 32.74 mm / 约 50 g / 75 件，描述的是完整单轴模型；不能与 TUT 的单个塑料壳体直接比重量或零件数。

[2014 表面分组图](../research/tangible_2014_2016/tbt2014_components.png) · [2016 表面分组图](../research/tangible_2014_2016/tut2016_components.png)

这些图使用原始网格绘制，各格独立缩放。未进行工作状态干涉、材料强度、保持扭矩或传感精度仿真。

另有一项明确的软件复用缺口：上游 `Hardware/Firmware/utility.c` 第 576 行只分配 `anglesZ[3]`，第 622 行写入 `anglesZ[3]`，第 631—634 行循环读取 4 个元素。第四项越界是源码可见的问题；本轮没有编译或运行上游固件，也没有据此推断实际原型发生了什么故障。它说明旧驱动与协议必须审查后移植，不能作为现成可靠固件直接刷入。

## 4. 三个不能从论文跳过的工程判断

**保持力仍需要试验。** 2014 论文的约 1° 精度、低于 0.1° 静置变化，与 2016 报告的低于 0.5° 角度误差，都是各自条件下的结果。静置读数稳定不等于挂上手臂后能保持，编码器读准也不等于机械没有回差。2016 第 8 页明确讨论了摩擦控制仍有困难。

当前 LP6 最苛刻保持预算约 0.463 N·m，来源是当前约 454.5 g 的悬空臂预算，而非所有新关节的通用额定要求。采用更轻的 TUT 结构后，应按新的部件质量、重心、力臂和支持条件重算。可先把旧预算作为对照工况，但不能把它变成所有部位的新硬门槛。此前 20 N 操作力与 60 秒漂移 0.3° 也仍是初筛提案。

**滑环未必值得照搬。** 2016 使用滑环以允许无限扭转，论文附录同时说明滑环会造成短时断电和数据扰动，因而引入分布式恢复协议。静态人偶不需要为了无限旋转接受这种复杂度；应先按人体所需角度检查柔性导线的路径、弯曲余量、拉脱与磨损。只有有限角度走线仍无法满足动作时，再比较滑环。减少采集频率本身不能消除线缆对机械运动的影响。

**少量传感器不能直接替代完整姿势测量。** 2016 用少量模块控制多骨骼角色，有一部分来自示例姿势插值：未直接控制的骨骼由算法生成。论文也报告了示例偏向奔跑时，其他姿势中的马腿会被带弯。这可以成为将来的可选姿势辅助功能，但不等于测到了完整人偶，也不能据此删掉当前 44 项姿势控制语义。

## 5. 推荐用于本项目的组合

机械主候选采用 **TUT 式正交双铰链，加适合人体的扭转自由度**，先恢复原版总装作为对照；随后研究有限转角、可靠走线和可调摩擦的版本。2014 的螺钉调节和内部小板布局提供结构参考。暂不为了通用拼装、无限旋转或复制作者的外观而保留所有模块。

传感方面，中央双轴测角先保留 MLX90363 作为对照候选，以免同时更换机械与测量原理。原厂目前仍提供[产品与资料页面](https://www.melexis.com/en/product/mlx90363/triaxis-mainstream-rotary-linear-joystick-position-sensor-ic-spi)，支持磁场三分量及 SPI 接口；这不是库存、采购价或供货周期证明，也不能证明本关节的有效角度范围。国产替代若能满足需要再作比较，不先把所有已有供应商方案推翻。

一个中央磁铁与双轴传感器不能单独观测完整三维姿态。原版还测两端扭转；若改成只保留一个扭转环，需要验证人体动作范围和操作手感。TUT 的四个角度读数要通过校准后的机构关系求相对旋转，再映射到 UE 对应的逻辑关节轴，不能直接丢掉第四个值，也不能随意塞入相邻的身体轴。

电路优先研究关节附近的小 MCU 采集，再把数字数据交给 G0/中央板。2014 的共享 I²C 与 2016 的半双工 USART 树，都不是已验证可接入当前 RS485 接口的即插即用节点。选择拓扑前仍须检查真实板件、连接器、线束和供电；背部 48 × 48 × 12 mm 目前只是 O7 空间目标。

UE 的静态采集、稳定性判定、Capture ID、数据新鲜度及 measured/fixed/missing/fault 区分继续保留。论文的断开检测约 2 秒不能替代本项目一次采集的数据有效性条件。RigReducer 不是本轮硬件复用的前提。

## 6. 下一步顺序与采购影响

1. **先完成数字恢复。** 对 TUT 的 STL 建立功能件、打印连接物与标准件清单；重建轴线、装配关系和磁铁/PCBA 位置，核对生产尺寸。输出能审查的总装和原版对照，不把 STL 排布当成工作姿态。
2. **再完成肩部局部比较。** 在原版与有限转角候选上同时检查肩—上臂—胸部的共同空间、输出接口、工具、导线，以及原先保留的动作目标。O7 双臂 102 状态仍有 45 个失败，不得删除旧失败姿态来宣称改善。同步重新估算质量和保持工况。
3. **然后制造一个有完整清单的对照关节。** 测保持扭矩、起动与持续调整力、正反向空程、停留漂移、受载磁测角和线束运动，再决定是否采用新的摩擦结构或沿用 LP6 路线。

旧的弹簧/摩擦小样试验方法仍有价值，但专用 PEEK 试片、B8/A8 碟簧和对应金属件不再是优先采购项。先避免为尚未选定的内部制动方案投入专用加工；也不要立刻照 2016 STL 下单整套人偶。当前已制作的动画指南继续作为 **O7 备选方案的教学材料**，不是本次 TUT 候选的装配说明。

本次结论是“复用路线值得推进”，不是“已经完成换型”。当前没有实物结果，也没有新的制造放行。

## 来源与复算入口

- 用户本地 2014 论文：`PoseDoll_HW44_Plan/tangible-and-modular-input-device-for-character-articulation-supplemental/tangible-and-modular-input-device-for-character-articulation-siggraph-2014-jacobson-et-al.pdf`。硬件手册与 PCB 文件位于同目录 `open_hardware_package/`。
- 用户本地 2016 论文：`PoseDoll_HW44_Plan/Rig-Animation-Input-Device-2016.pdf`。重点为第 3—4 页硬件、第 8 页限制、第 10 页通信附录。
- [2014 ETH 官方项目](https://igl.ethz.ch/projects/character-articulation-input-device/)；[2016 ETH 官方项目](https://igl.ethz.ch/projects/rig-animation-input-device/)；[2016 固定版本源码](https://github.com/oliglauser/atamid/tree/9a152b1d82374d1960ebd2216563fb30b1b6875b)。
- [O7 原始结论](O7_DIGITAL_AND_BENCH.zh-CN.md)、[本轮输入哈希和尺寸结果](../research/tangible_2014_2016/evidence.json)。原始研究文件保留在 `PoseDoll_HW44_Plan`，2016 checkout 位于 `research/tangible_reuse_20260925/atamid`，未改写上游设计。

复算需要 Python、NumPy 与 Pillow，在 `design` 根目录执行：

```powershell
python Hardware/PoseDoll44/research/tangible_2014_2016/audit_sources.py --plan-root ..
```

脚本固定检查上游提交，并在读取前后核对输入 SHA-256。表面连通性检查和示意绘图只服务于资料审查，不包含 CAD 工程验收。

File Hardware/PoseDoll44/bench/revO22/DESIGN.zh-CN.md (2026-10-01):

# O22 单人偶工程设计说明

2026-10-01。以已保存的 O21（5537190 / posedoll-o21-costdown-20261001）为基线，落实《分支 · 审查O21方案成本》的12项意见。**本版是可询价、可制作首件的工程候选，不是整机制造放行。** 正式状态见 [优化清单](optimization_tracker.json)。

## 功能与边界

一套 USB 人偶，25个关节模块、46路原始机械轴、41个语义自由度；不依赖摄像头、不加电机。保留 O20 的骨长、关节中心、腿杆走向及已经接受的双髋各16mm外移。A站姿最大实体高度491.716mm，低于600mm。根节点世界位移、根旋转、手指由UE编辑；脊柱/颈部细分属于已声明的派生映射，不伪称逐骨实测。目标角色的接触、贴地、蒙皮穿插由动画师后期调整。

O11的打印尺寸、螺钉垫片配合与可调摩擦已由用户于2026-09-30确认通过。本版不要求重复证明该摩擦原理，也不添加额外摩擦副。新测试只针对新传感板、安装、线束与读数。

## 已实现的优化

1. **限位诊断保留真实读数。** 容差为每轴独立标定误差上界加14bit半个计数，标定上界最高1.25°。限位附近标记`BOUNDARY_UNCERTAIN`，不把角度钳到限位；明显越界或多周解释不唯一则拒绝。
2. **120ms是总年龄。** 从最终一轮最早的通道采样到主机求值时刻计算，不把扫描时间与USB延迟分开各放宽120ms。500ms历史稳定窗口仍保留。
3. **默认A站姿。** 上臂约35°外展，所有原始轴距机械限位至少3°；只改变默认摆姿，不重定义机械零位或参考坐标。
4. **装好以后标定。** 支持有限行程的分段线性误差表及0/360°跨界。至少5个拟合点、相邻编码器跨度≤15°；独立验证角度至少4个、每角度正反向到达；不在未测区外推。独立参考不确定度≤0.1°，独立验证最大误差≤1°、正反向差≤0.3°。保留原始读数、原始USB包、标定内容与哈希。
5. **SOP8托架。** 34个可拆托夹与12个端轴安装位按12×10×1mm PCB、SOP8最大包络调整。元件面距服务坐标原点15.95mm，磁铁顶12.9mm；含焊接高度1.50–1.85mm与两个±0.10mm位置公差后，封装外壳至磁铁间隙为1.00–1.75mm。这不是芯片内部敏感面磁距的保证；磁状态和装后角度误差必须测量。
6. **线束实物模板。** 46根五芯线独立回中央板，三组14/16/16路。全部端口与载板位号对应。完整左臂10路包含锁骨、肩、肘、前臂与两个腕轴。新增`harness/routing_plan.json`列出实际安装坐标、固定骨段、234个离散姿势下的路径长度和松弛余量。最长预切750mm；46路每色合计22.75m，五色合计113.75m；另加两套750mm备件和加工损耗。折线路径只用于装配定位，必须弯成≥7mm半径；未证明动态无夹线或疲劳寿命。
7. **真正布线的中央板。** 80×94×1.6mm四层，外层35µm、内层17.5µm；地与SENSOR_3V45各占一内层。原两层细线方案的远端压降不足，因此改为四层。传感板与载板最终ERC、DRC、未连接和原理图一致性检查均零错误。Gerber、钻孔、坐标与BOM在`manufacturing/`。四层不等于SI、EMI、温升或波形已验证。
8. **电源料号和压降。** AP3429AW5-7，L1=74438357022，输入PTC=1206L110THR，输出保险丝=0467001.NR；R50/R51=316k/66.5k、0.1%、≤25ppm/K。电源标称3.451V，不能将它接入只允许3.3V的外部未知设备。按46×14mA加80mA逻辑、60°C铜阻、750mm AWG30、接触电阻、热态保险丝≤0.15Ω及电阻温漂计算，远端最低3.141V、空载上界3.532V。电源实际热阻、纹波及远端电压仍需验证。计算见`verification/power_budget.json`。
9. **UE可编辑闭环。** P21R原始包→CRC/新鲜度/稳定性→标定→机械FK→语义旋转→目标适配→Control Rig关键帧。Manny与Quinn分别保留目标Mesh的参考骨长；修复Quinn意外使用Manny初始骨变换的问题。4个姿势×2个角色通过保存和新进程重开；手腕编辑与撤销通过。全部证据标注合成输入，真实硬件仍待验收。

## 机械交付与限制

完整打印包150种、186件：185件在人偶上，1件XIAO板间距治具。X001–X081为本轮替换件，全部按实际装配实体导出、单实体检查，并做3MF数值回读；其余文件保持O20内容。不能把`mechanical/section/`或预览中的剖切模型当作打印文件。固定载板用4颗M2×6塑料自攻螺钉，盒盖用两条2.5mm扎带。XIAO两排针中心距15.24mm，板间净距4.0mm，继续使用P242治具。

背盒外尺寸86×100×27mm。打印实体体积从585.50增至599.36cm³，增加13.86cm³；按1.24g/cm³实心换算约17.2g，但不是切片耗材或实物重量。**本轮没有减少整机打印件，也不宣称整机减重。**

74个离散姿势中，O22改动没有增加被检查的相邻运动件相交；4个UE示例姿势的相邻检查为零。报告仍保留旧版极限姿势接触：如肩原始r0约−170°、肘−90°、前臂扭转约106°及145°、腕屈伸145°、胸侧摆45°。这些位置不能当作已经放行的无干涉工作范围，也不能因为“旧版就有”而忽略。原始传感器限位仅为读数诊断范围，不是可用机械空间的证明。没有连续、多轴组合全范围证明；首件需测定实际可用范围后再放行。骨盆与胸部之间隔着腰段，属于用户允许通过姿势避让的非相邻碰撞，独立记录。

## 使用顺序

先看[实物验收](physical_tests/ACCEPTANCE.zh-CN.md)。加工方先做少量电子首件；用已通过的O11小样加两个新测试支架验证磁距和读数，再做16路长支路及完整左臂。通过后装46路，完成真实标定与Manny/Quinn保存重开。`physical_tests/`的空表全部保持未测试，不自动填通过。

主机安装`requirements-reference.txt`。从本目录运行：

```powershell
python source/calibrate_axis.py measured_axis.json --output axis_result.json
python source/assemble_calibration.py --profile profiles/device_profile.json --device-id REAL_USB_ID --axis-dir measured_axes --tests physical_tests/test_manifest_INCOMPLETE.json --output calibration_MEASURED.json
python source/usb_capture.py --port COM实际端口 --profile profiles/device_profile.json --calibration calibration_MEASURED.json --output capture.record.json
python source/ue_export.py --profile profiles/device_profile.json --record capture.record.json --output capture.payload.json
```

UE插件增加`SolveMeasuredPose22`和`CaptureMeasuredPose22`；Python入口为`unreal.PoseDollEditorLibrary.capture_measured_pose22(sequence, rig, frame, payload_path, target_profile_path, False)`。调用前在Sequencer打开指定序列并刷新绑定；要求单个Control Rig段、目标Mesh匹配、可写且无时间变换。正式入口拒绝未完成实物资格的数据；`allow_synthetic_for_testing=True`只用于明确的数字测试。写入作为可撤销事务，保存由用户编辑流程执行。详见`ue/editor_scripts/`和插件补丁。

固件仍使用O21的P21R/1线协议和46路顺序，二进制按哈希原样继承；协议兼容不是新电路已上电的证据。

## 成本状态

[budget.json](budget.json)分项合计1482.50元，余17.50元；高价情景2220元，正式供应商报价0份。现有打印机、自行打印/机械装配，外包贴片、压接和板端焊接，计入备件、最小订单、工程费与运费。不要把LCSC美元参考价当国内含税到手价。外部计量仪器若需购买或付费借用，必须补入实际报价；当前精度门槛不能通过免费的假设放宽。询价与返价核算见[RFQ](manufacturing/RFQ.zh-CN.md)。

## 主要器件依据

- [MT6701 Rev1.9中文手册，2024.05](https://atta.szlcsc.com/upload/public/pdf/source/20260616/FEB700C1922508565884FF0A90656B50.pdf)：电源、SSI、SOP8尺寸与精度限值；14bit分辨率不等于14bit绝对精度。
- [JST SH官方图册](https://www.jst-mfg.com/product/pdf/eng/eSH.pdf)：BM05B-SRSS-TB、SHR-05V-S、SSH-003T-P0.2-H及线径配合。
- [AP3429官方手册](https://www.diodes.com/datasheet/download/AP3429.pdf)、[74438357022电感](https://www.we-online.com/components/products/datasheet/74438357022.pdf)：电源额定条件与电感下方禁铜要求。
- [Littelfuse 467](https://www.littelfuse.com/assetdocs/fuse-467-datasheet?assetguid=4a59f034-1cca-460e-a5ba-e1e66247c76d)、[1206L](https://www.littelfuse.com/assetdocs/littelfuse-ptc-1206l-datasheet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)：额定值；典型冷态电阻不能代替热态上限。
- [Vishay TNPW e3](https://www.vishay.com/docs/28758/tnpw_e3.pdf)、[Murata 22µF参考规格](https://search.murata.co.jp/Ceramy/image/img/A01X/G101/ENG/GRM21BR61A226ME51-01A.pdf)：电阻等级与电容额定值；供应商必须补DC偏压曲线与实际AVL。
- [MT6701CT-STD-R公开价格](https://www.lcsc.com/product-detail/C3003196.html)：2026-10-01所见30+档US$1.0355；50颗US$51.775，以7.00仅作预算换算。

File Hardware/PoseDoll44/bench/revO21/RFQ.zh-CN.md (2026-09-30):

# O21 单套询价要求（未发出）

请按一套含税、运费与全部工程最低收费报价，不按 100/1000 套摊销。目标为单套约 1500 元，但请填写真实价格，不省略达不到目标的项目。

## 1. 传感器板

- 交付 48 块合格 PCBA，46 装机、2 完整备件；MT6701CT-STD-R/SOP8，禁止自行替为 QFN 或 AS5600。
- 芯片预算采购 50 片，另两片覆盖合理贴片损耗或剩余裸芯片备件；实际损耗/拆盘费另报。
- 两层板 12×10×1mm、单面 SMT，100nF＋1µF＋33Ω＋10k。板端五个无锡膏尾线焊盘由加工方焊线。
- 请分别列出裸 PCB 最小数量、SMT 最小数量、开机/钢网/拼板/分板/器件损耗/电测/税/运费。
- 可提议 24 拼×2 块组装。若裸板最小 5 拼、组装可只做 2 拼，应计入 5 拼裸板费用；若必须贴装全部 5 拼，必须报 120 块及其额外芯片成本，不得仍写 48 块价。
- 当前 PCB 为工程候选，待磁体包络、板端出线与供应商 DFM 确认后才能出生产 Gerber。不要使用 O20/AS5048A 板资料替代。

## 2. 中央采集板

1 块组装，附原生原理图与网表。3×CD74HC4067PW、2×SN74LVC244APWR、1×SN74LVC125APWR、AP3429AW5-7、46 个匹配五针接口、XIAO 插接。中央 PCB 尚未布线，现阶段可报加工规则、最低收费、元件与工艺预算，不能提供已经定稿的板面积报价。

请报 1 块和供应商实际最小组装批次两个金额；买多余板的费用也算这套支出。载板 ¥130 与电源 ¥35 是成本额度而非双算同一加工费。若实际报价合并，预算表合并替换。

## 3. 线束

- 48 套五芯：46 装机＋2 备件。传感板端焊接和主板端压接全部由加工方完成。
- 活用线长暂定总 16.7m 五芯线；两套备件各 600mm，共 17.9m 五芯成品额度。长度见 profiles/wiring.json；仅供估算，待整机布线确认后出生产裁线表。
- 30AWG 多股柔性铜线，颜色/编号匹配 GND、3V3、CLK、DO、CSN，非六芯 FFC。请给每芯股数、绝缘外径上限、线阻、弯曲建议与端子适用规格。
- 默认同厂家完整 SH 1.0mm 5P 板座/插壳/端子；若替代，整套提供图纸和料号，不跨品牌盲配。
- 提供 100% 导通、相邻线短路检查、标号检查、板端应变释放和样本拉脱检查的费用。不要把板端 240 个焊点留给用户。

## 4. 机械件、磁铁与交付检查

沿用 mechanical_procurement_O20.json 的 suggested_total，计入袋装/最小数量，不改肩轴、垫片、碟簧配合尺寸。磁铁须 D6×2.5 径向充磁，共 51 件，提供规格与充磁方向。

请回复：每项含税单价与总价、最低批量、工程费、材料损耗、运费、交期、替代料清单、未包含工作。特别说明是否包含传感器角度校准；本预算默认用户做夹具标定，外包计量必须另计，不能口头默认已经包含。

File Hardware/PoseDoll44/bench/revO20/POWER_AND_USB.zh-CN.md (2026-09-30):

# O17 USB 与 C1-U 接线

状态：数字装配候选；未连接实物验证。完整设计和放行条件见 DESIGN.zh-CN.md。

```text
电脑 USB ── XIAO USB-C ── 主控3.3V / 数据
                           │ 六路带保护SPI
                           └── 46块编码器
独立稳压5V USB电源 ── J7 ── 原3.3V降压器 ── 六路传感器供电
                         D1 = 不装；禁止桥接到主控USB 5V
所有 GND 共地；两个正电源保持分开。
```

- C1-U 沿用 C1 裸板铜层，BOM 和 placement.csv 不含 D1。不要把 Gerber 的焊盘理解为必须装元件。旧板需先拆掉 D1。
- J7-1 = VIN_5V，J7-2 = GND。J8-1 = GND，J8-2 = VIN_5V，J8-3 = SENSOR_3V3。核对原理图与实物针序后接线，不凭线色。
- 只用稳定 5V 输入，电源额定至少 2A；此为设计余量，实际功耗、电压降与温升待测。禁止 PD 升压触发线。
- XIAO 使用普通 ESP32S3 版，不装摄像头扩展板，不接天线，O17 程序不启动射频。
- USB 数据线接 XIAO 本体；胸部上沿开口和扎带槽用于出线及应力释放。保留后方松弛线环，测试整个人偶姿势时检查线缆是否牵动关节。
- 先限流上电；分别断开两路电源检查反灌、关机轨电压与 GPIO 回灌，再接电脑做采集。C1-U 尚无新的上电合格记录。

P17R/1 与旧 P15R 固件不同。保留六条 SPI 链的顺序 6 / 4 / 10 / 10 / 8 / 8。不得以接收到46个字为依据跳过实际轴号、方向、零位和磁场诊断验证。

参考工具在 source/usb_capture.py，需要 NumPy 与 pyserial。指定端口、O17 profile、实测标定及新的输出文件：

```powershell
python source/usb_capture.py --port COM7 --profile profiles/device_profile.json --calibration my_measured_calibration.json --output capture_001.json
```

COM7 只是语法示例，不会自动寻找或刷写设备。附带 calibration_INCOMPLETE.json 不能产生合格硬件测量。原始字节和坏帧也要保留；拒绝结果不能转成角色零姿势。此工具尚未连接实际硬件或新的 UE 适配器。

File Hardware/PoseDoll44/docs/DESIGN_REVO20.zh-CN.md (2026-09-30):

# O20：减少固定外壳零件，给骨架减重

O19已保存为提交`98c084a`、标签`posedoll-o19-leg-alignment-20260930`。O20在新目录独立生成，O16–O19历史包保持原样。

## 本轮采用的需求

一台不超过600 mm的USB被动测姿人偶，无外部摄像头。准确采集所支持的关节运动，保留标定、完整性和基本姿态转换；不做自动接触修正。根位置/整体姿态与手指仍由UE制作，脊柱、颈部及辅助骨分配明确属于推导值。

用户于2026-09-30接受双髋有效中心各向外16 mm的布局。相邻零件及关节仍须可动；不直接相邻的肢体接触允许通过调整姿势避让。该决定不等于允许局部机构互相穿透，也不等于证明所有姿态可达。

O11小样的打印件、螺钉、垫片配合与可调摩擦已由用户报告通过；拧紧可使长杆几乎不能转动。继续采用原摩擦原理，不增加保持力冗余。该报告不是新的称重、传感精度或空心杆刚度测试。

## 第一性原理与改动

姿态测量依赖转轴、刚体之间的相对关系及传感器固定，而不依赖骨架中心必须填满材料。减重因此集中在自由杆段的芯部、控制盒板面，以及重复的固定外壳连接件。

1. **一体足架W016/W017**：将原足架与脚趾关节可拆固定半壳合并，采用O18已有的侧装螺母/垫片结构。每侧减少一件打印件、两颗M3×20螺钉和两个M3螺母。肩轴、原摩擦垫片、受压面、传感器、磁铁与转轴不变。
2. **14件骨架、23段芯孔**：自由杆段采用封闭内腔。10 mm外径对应5 mm内径，8 mm外径对应4 mm内径；逐段使用至少2 mm的实体壁厚保护包络，排除关节端部及其2 mm包围区域。弯头与端部保持连续，不增加粘接或拼装件。
3. **控制盒减重**：盖板增加28个直径7 mm圆孔，底板增加12个直径9 mm圆孔。避开原降压板支柱、PCB支柱、四角紧固件、USB/线束接口和两处骨架连接落点。

对理想均匀圆截面，半径减半的芯孔去除该截面25%的面积，仍保留93.75%的截面惯性矩与极惯性矩。这只是截面几何关系，不能当作FDM打印杆的强度、刚度或蠕变实测；整段材料减少量还受实心端部、弯头和避让区影响。

## 数量与质量

| 同口径项目 | O19 | O20 | 变化 |
|---|---:|---:|---:|
| 打印种类 | 117 | 115 | −2 |
| 单台打印清单数量 | 188 | 186 | −2 |
| 装在人偶上的打印件 | 187 | 185 | −2 |
| XIAO焊接间距治具 | 1 | 1 | 0 |
| 本轮移除五金 | — | — | 4颗M3×20螺钉、4个M3螺母 |
| 打印实体体积 | 602.343 cm³ | 585.498 cm³ | −16.845 cm³，约−2.80% |
| 原始测量通道 / 语义旋转DOF | 46 / 41 | 46 / 41 | 0 |
| 中立实体总高度 | 492.140 mm | 492.140 mm | 0 |

按历史预算的PETG密度1.27 g/cm³和五金几何包络换算：打印材料当量约减少21.39 g，移除五金约7.96 g，合计约29.35 g。按PLA-CF 1.22 g/cm³换算则合计约28.51 g；密度依据[Bambu PLA-CF官方材料表](https://store.bblcdn.eu/s8/default/aefa8303ad8d40248b0d86dfdad46518/Bambu_PLA-CF_Technical_Data_Sheet_V3.pdf)。PETG 1.27仍是既有预算假设。

这些数值是**实心材料当量与包络估算，未称重**。打印填充率、壁数、支撑和材料会改变实际差值；内部芯孔可能只去掉原本稀疏的填充，也可能改变内外壁路径，不能保证实际减重等于29 g。请使用同一打印机、材料和切片参数比较O19/O20耗材量。装配治具、可选备件不计入人偶质量；软线、USB线、胶和扎带也未含在本轮总模型质量中。完整逐件数据见`verification/mass_comparison.json`。

## 装配与制造

- W001–W017是本轮17件替换件，完整单台清单为`PRINT_UNIVERSAL.csv`。避免把旧足架和已合并的半壳同时装入。
- W016/W017：在安装转臂、肩轴与电子件之前，从关节本地+Y侧装入螺母及反力垫片，再安装原转动件和肩轴。65个位置采样检查16 mm装入路径，原垫片受压面保留，螺母抗转及肩轴阻挡退出分别检查。
- 不改变已验证关节的打印和螺栓预紧方法。空心自由杆需要在相同工艺下查看切片：最大内腔直径5 mm，孔顶需要桥接，不要生成无法清理的封闭内支撑。
- 网页的剖切模型仅为展示内部，STL/3MF均是完整零件。一些精密端部使用17位ASCII STL避免float32合点，两足架在摆到打印床前用1e-10 mm容差清除重合边，体积差小于1e-9 mm³；3MF保留双精度坐标；不应以文件体积较大判断模型多件。
- 控制盒为有孔样机外壳，无防尘防液体设计。新孔没有电子功能变化。

## 验证与边界

本轮对17件改变的打印实体做制造网格回读，检查闭合边、单一材料连通体、内腔边界和STL/3MF体积。所有未改打印件核验哈希；采购清单扣除实际8件五金。46路配置的轴顺序、限位、父子变换、参考零位、传输和静态捕获规则与O19相同。

24个姿势例子检查每一改动件对保留实体的相交。按同体、同模块或串联相邻模块归类为相邻机构；其余碰撞记录为远端姿势接触。另沿两侧脚趾和踝部原始轴以5°步长检查156个状态，保持其他原始轴不变，避免多轴分解分支跳变。156个状态中，88个属于语义捕获范围，均未发现足架相关的相邻机构相交；48个有旧有相邻接触的脚趾极限状态全部在捕获范围之外。超出语义捕获域的机械轴状态单独标记，不作为可用采集姿态。离散检查不能证明所有组合角度的连续全域无干涉。

封闭芯孔通过保留原表面三角形并加入反向内腔边界构建，避免对关节端部不必要的重建。布尔差分的极小数值残差保留在记录中，不据此声称具有精确连续碰撞证明。

采集与USB沿用已验证的运行代码，并对O20配置运行已有21项自动检查；这不等于46个实物传感器已标定，也不等于Manny和Quinn的UE采集、保存、重开端到端已完成。后续实物关注新空心杆在自重/摆姿力下是否发生不可忽略的弹性变形，以免出现传感器未测到的骨段弯曲；不重复要求验证已通过的O11摩擦原理。

## 文件与复建

网页：`tutorials/full-doll-o20/index.html`。离线包：`bench/revO20/PoseDoll_O20_Universal_Design.zip`。包中运行`python serve_preview.py`，访问`http://127.0.0.1:8771/viewer/index.html`；完整性检查为`python source/verify_package.py`。

正式CAD入口：`cad/revO20/design.py`、`export.py`；复建依赖仓库冻结O15–O19输入与相应Python环境。包中提供已生成的完整STL/3MF，不要求使用者为了打印重新生成所有历史CAD。原固件和电子件文件保持一致，标定文件仍明确标为INCOMPLETE。

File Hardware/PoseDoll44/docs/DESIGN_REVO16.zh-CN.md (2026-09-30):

# O16：单一通用静态测姿人偶设计

日期：2026-09-30。型号：**O16 Universal**。数量：**1 台**。状态：**数字设计候选，不是整机制造放行**。

本版按《优化人偶设计方案》最后两轮讨论收敛：可靠测量实体自身的姿态，确定性地转换给 UE，动画师在 UE 中处理接触、穿模与表演。对话最初的“双体型、逐骨几何重合、ExactFK 严格复刻”已被后续讨论修改，不能再作为本版约束。

## 1. 已冻结的需求

| 项目 | O16 的要求 |
|---|---|
| 实体数量 | 一个硬件型号、一套打印数量、一套通道与标定；不因切换 Manny / Quinn 更换身体零件 |
| 高度 | 标准直立姿态足底到最高实体点 ≤600 mm；计入人偶上的头部设备、紧固件与尾线，不含独立桌面网关 |
| 身体结构 | 人体式全身关节、合理比例与可用活动范围；不要求任何角色的骨长、轴心逐一重合 |
| 实体运动 | 相邻机构不得碰撞、夹线、拉紧导线；此项保留为硬性放行条件 |
| 测量 | 所有可动测量轴都必须被采集；零位、方向、回差、重复性、载荷挠曲与静态稳定性可核验 |
| 数据 | 断线、故障、未标定、混合采集、过期、重启、重放不能变为有效测量 |
| UE | 已知参考姿势与坐标关系下的基础转换正确；生成可编辑、可保存重开的关键帧 |
| 不承担的工作 | 自动贴地、接触识别、抓握约束、防穿模、动作美化；不据目标角色接触状态拒绝有效测量 |
| 工作方式 | 摆姿—扶稳—采集—在 UE 安排关键帧与过渡；本轮不增加连续高帧率动捕要求 |

骨盆相对桌面的六自由度、手指没有测量。整体运动与手型由 UE 编辑。没有增加被动测量支撑臂，也没有要求按 UE 每根颈椎、脊柱辅助骨安装独立传感器。

## 2. 机械基线与这次改变的范围

**选用 O15 Quinn 已完成的机械几何作为唯一通用实体。O16 本轮没有重画这些关节、连接架或外壳，也没有把它们整体缩放。** 选择它是为了复用已有数字装配、切片与带设备的检查资料，并消除两套实体的维护与误配。

O16 交付将这套几何固定为 `universal`；Quinn 只出现在来源记录和历史证据中。它不再是“只能驱动 Quinn 的实体”。打印件仍用已有 P 编号，左右件仍有区别，不能镜像替代 PCB 或混装左右零件。

已重新从最终实体网格计算：中立位包络约 **164.0 ×169.0 ×492.14 mm（前后×左右×高）**；张臂装配位高约492.93 mm。网格简化精度为0.03 mm，精确实体检查另见 `generated/revO16/exact_geometry_check.json`，实物尺寸仍待装配测量。

当前约49.2 cm已给60 cm留出约10.8 cm空间；没有理由仅为满足已取消的“UE逐骨重合”目标把它扩大到58 cm。此结论并不说明49.2 cm是理论最小尺寸。

| 部位 | 机构 | 原始传感器数 | 对外解释 |
|---|---|---:|---|
| 腰、胸 | 各一套3轴模块 | 6 | 两处实测相对旋转；目标更多脊柱骨由适配规则派生 |
| 头颈 | 万向节加两端扭转 | 4 | 一处三维相对姿态；不声称逐节颈椎实测 |
| 左右锁骨 | 每侧两个串联铰链 | 4 | 实际轴线不同中心，完整记录其机械偏移 |
| 左右肩 | 每侧四原始角多轴模块 | 8 | 全部四路参与三维姿态重建，不能丢一轴 |
| 左右肘 | 单轴铰链 | 2 | 屈伸 |
| 左右前臂 | 单轴旋转机构 | 2 | 旋前/旋后；不等于逐根 UE twist 骨实测 |
| 左右腕 | 每侧两个串联铰链 | 4 | 屈伸、侧摆，保留实际间距 |
| 左右髋 | 每侧四原始角多轴模块 | 8 | 与肩同类测量原理 |
| 左右膝 | 单轴铰链 | 2 | 屈伸 |
| 左右踝 | 每侧双轴模块 | 4 | 踝屈伸、内外翻 |
| 左右前足 | 每侧单轴铰链 | 2 | 前足屈伸；脚趾不是逐趾测量 |
| **合计** | **25个物理关节模块** | **46** | **41个姿态参数；另有3个固定骨盆兼容槽，固定值不是测量** |

保留FDM打印结构、现成轴肩螺钉、垫圈、碟簧、径向充磁磁铁与编码板。传感器应读到承力输出件的实际转动；磁铁座、轴肩、轴承与输出件滑动会造成测量错误，不能靠软件零位补偿长期掩盖。

本版实体仍保留背部C1控制盒、腰后供电模块及桌面USB网关；没有声称已经完成设备外移或减重。重量约1.67 kg是继承的预算，允许手托，不另加1.2 kg硬门槛。把控制盒移到桌面会改变线长、压降、信号完整性和线束拉力，因此不把尚未重验的外移结构混入本版零件包。

## 3. 单一数据源：实体是什么，就描述什么

`profiles/device_profile.json` 是O16的实体测量模型：

- 一个硬件ID、46路原始通道、25个模块的父子关系。
- 每个模块的固定安装变换、真实旋转次序、输出连接偏移。
- 真实骨盆参考与固定外形标记，不借用某个目标角色的骨长作实体真值。
- 中立原始角只是装配参考，不是46颗传感器的实测电气零位。

坐标为右手系，X前、Y左、Z上，毫米，列向量；四元数为xyzw。进入UE时统一转换单位与坐标，不逐项复制欧拉角。

每一段使用：`T_child = T_parent · T_mount · R_raw(q) · T_output`。肩髋和头的旋转次序为 `Rz(q0) Rx(q1) Ry(q2) Rz(q3)`，腰胸为前三项。踝为 `Ry(-q1) Rx(q0)`。左右镜像安装矩阵可能各自含反射，输出身体旋转必须始终为det=+1；不能直接把反射矩阵转成四元数。

这些偏移描述实体本身，并不是为了宣称与UE几何相同而添加的补偿。运行时直接由原始角生成矩阵/四元数，不需要先反解到旧的41轴欧拉范围。

**测量成功和目标适配成功分开保存。** 假如某个真实姿态无法被旧Control Rig配置表达，原始测量仍可存档，目标转换返回失败或不支持；禁止悄悄裁剪关节角、填零，或把适配失败说成传感器坏了。

`cad/revO16/device.py` 为离线参考实现；它不是已接入串口的生产驱动，也不自动写入UE资产。
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

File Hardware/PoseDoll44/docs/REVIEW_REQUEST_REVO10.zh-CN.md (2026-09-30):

# O10 评审入口

先读[本轮设计报告](O10_JOINT_AND_TEST.zh-CN.md)，并打开[交互说明](../tutorials/design-lab/index.html)。工作区尚未提交本轮commit；评审以`o10_20260926_r1/evidence_manifest.json`锁定文件。

请重点审查：

1. 端面制动、独立磁铁支撑及金属轴的力路；210 N为目录点，未测摩擦/蠕变，外侧转轴制动与M3轴防松仍开放。
2. 连续叉架间隙与完整关节端点检查的范围区别；零面积面处理、初始实体分离和数值误差。
3. 参考螺纹的旋出、套筒/肩轴支持、铝环结合与生产牙形/公差缺口。
4. 双轴锁骨试排的双侧前收碰撞，以及未建承力连接架、胸颈和带线总装。不得删除失败目标来获得通过。
5. LPMS-05D的版本、安装、引线与真实通信性能；目录尺寸和宣传不作为电气验收。
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

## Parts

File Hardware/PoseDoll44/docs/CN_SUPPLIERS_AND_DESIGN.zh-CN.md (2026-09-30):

# O5CN：国内供应商比较与五线传感板数字试验

2026-09-24，运行 `cn_20260924_r1`。结论：优先验证 **MT6701QT-STD 五线测角方案**，把 **CJT A1002 成套连接器**加入国内配套候选；现有 AS5048/O5 仍是采集基线。这里有已执行的电路、代码与局部 CAD 检查，没有实物合格结论，也没有采购放行。

本轮记录了 11 条器件/渠道候选，并不表示 11 家独立供应商，更不代表已找到全市场最优解。原先主要按资料完整性和可建模程度选择元件，未完成系统性的国内报价、供货和寿命比较。这次补充了这一环节的数字基础；原厂品牌、国内购买渠道、定制加工服务分别记录。

## 选择和取舍

| 对象 | 国内来源 | 这轮判断 | 具体理由 |
|---|---|---|---|
| 磁角度传感器 | 麦歌恩 MT6701QT-STD | 值得继续做独立试验 | 14 位 SSI、3×3 mm QFN，每轴不需要 MOSI；封装与接口均不同，不能直接换芯片 |
| 传感器接头 | 长江 CJT A1002WR-S-5P-LCP + A1002H-5P-2 + A1002-TP | 已纳入试验板 | 同厂成套配合，有压接参数；新建封装，没有假设能与 JST 混插 |
| 更粗供电线端子 | CJT A1002-TP-H | 暂缓 | 页面允许 26–32 AWG，但绝缘外径仍限 0.8 mm；没有找到已确认的合适 26 AWG 线及其压接工艺 |
| 小型连接器 | CJT A1001-T | 排除当前线材组合 | 外径上限 0.50 mm，小于现有线的 0.635–0.7366 mm |
| 线材 | 上海申远 UL1332、骏豪 UL1332，均为 28 AWG | 排除当前端子组合 | 目录外径分别为 1.02 mm、0.90±0.10 mm，超过 0.8 mm |
| 线材 | 赛摩 UL1571 28 AWG | 等待准确规格 | 名义外径 0.80 mm 已到上限，未给出本次可确认的上限公差及关节弯扭寿命 |
| 碟簧 | 锐尔立 B 系列 12.5×6.2×0.5，H0=0.85 | 禁止直接换入 | 当前弹簧外径为 12.0 mm，导向内径 12.16 mm；该候选直径大 0.34 mm，CAD 已证实相交 |
| 控制器 | 乐鑫 ESP32-S3-WROOM-1-N8 | 保留 | 现有设计已经采用国内厂商，无线能力继续保留 |
| 采购/加工 | 立创商城、嘉立创 CNC | 纳入国内路线 | 商品目录和加工平台不是实际报价、DFM、精密配合或来料验收证明 |

原始依据：

- [MT6701 原厂 Rev1.8 数据手册](https://www.magntek.com.cn/upload/pdf/202407/MT6701_Rev.1.8.pdf)，重点复核第 4、7、9、24–26、35 页。PDF 修订日期是 2022.12，URL 路径日期不作为新版证据。
- [CJT 系列目录](https://cjt.com/upload/A1002.pdf)、[WR 针座图 A3](https://cjt.com/up/A1002WR-S-XP-LCP_dwg.pdf)、[H-2 塑壳图 A0](https://cjt.com/up/A1002H-XP-2_dwg.pdf)、[压接与环境规范](https://cjt.com/ps/A1002-B_PS.pdf)、[26–32 AWG 的 -H 端子](https://cjt.com/en/pd5716.html)。旧系列目录和新图有不同日期，量产前须确认整套适用修订。
- [申远 UL1332](https://www.shenyuan.com.cn/p_display_185.html)、[骏豪 UL1332](https://www.junhaodx.com/tfldx/ultflx/66.html)、[赛摩 UL1571](https://www.sorm.com.cn/pd.jsp?id=23)。不能仅凭 UL 型号或 AWG 推断外径、柔性或可压接性。
- [锐尔立碟簧目录](https://www.raleigh-spring.cn/discspring/)、[嘉立创 CNC](https://www.jlc-cnc.com/companyProfile)、[乐鑫模组](https://www.espressif.com/zh-hans/products/modules)。
- 立创有 [MT6701QT-STD，C2913974](https://item.szlcsc.com/3200522.html) 和 [AS5048A-HTSP-500，C2655181](https://item.szlcsc.com/2747090.html) 的商品页。前者页面当前品牌显示 NOVOSENSE，与旧麦歌恩手册名称不同，需要在真实订货时核对；本轮未取得可核验的数量阶梯价格、库存及交期，未将平台宣传当成具体器件的供货保证。

**没有声称国产件一定更便宜或测角更准。** 现阶段可以证明的优势是接口少一根线，以及增加资料明确的国内配套来源。Alpha 2842/19、原 SCHNORR 参考、TI 电源/保护/通信、ST 卫星 MCU 暂时保留，未因品牌产地统一替换。

## 已落实的设计

### 五线传感板

原生 KiCad 工程在 `Hardware/PoseDoll44/electronics/sensor_revO5CN/`，包括原理图、两层布线、项目内符号与封装、网表和检查报告。外形仍为 12×10 mm，保持现有传感中心和边缘夹持位置。新针脚顺序为：

| 针脚 | 信号 |
|---|---|
| 1 | GND |
| 2 | 3.3 V |
| 3 | SSI CLK |
| 4 | SSI DO |
| 5 | SSI CSN |

区域板上逐端口 DO 隔离的要求保留，没有假设 MT6701 在未选中或断电时一定释放总线。新五针插头不能使用旧六针线序。区域主板和 C 卫星驱动尚未转为 MT6701，UE、PDG5、PDC5 生产路径也未接入该试验。

若 41 条传感器支线都采用该接口，导线段数可由 **246 降至 205，减少 41 段，即 16.7%**。这只适用于同线材、同走线路径的传感器支线，不包含 CAN 干线，也不改变 C 方案 J50 的四芯链路。它不等于全机线束体积降低 16.7%，更不等于关节直径降低。

在相同 250 kHz 时钟下，41 轴的纯串行比特时间从旧读取序列的 26.24 ms 变为 3.936 ms；这没有计入片选、隔离、调度、重试、CAN 或 USB，**不是实测扫描延迟**。静态捕捉的稳定窗口、扫描超时、数据时效和事务边界仍保留。

### 已执行的检查

- KiCad 10.0.6：ERC **0 违规**；含原理图一致性、全部轨迹错误的 DRC **0 违规、0 未连接**。规则为 0.15 mm 线宽/间距、0.30 mm 过孔钻孔，没有用忽略项隐藏问题。
- 独立读取最终 PCB：针脚/网名与本轮契约相符；8 个过孔，**0 个焊盘内过孔**，过孔铜边距 SMD 焊盘最小约 0.20 mm。初次自动布线出现焊盘内过孔，已增加避让后重新布线。
- C11 编解码试验以 MSVC `/W4 /WX /O2` 编译；独立多项式长除法对照 **262,144** 组角度/状态数据，另对全部角度进行 **393,216** 次单比特损坏检查；非法长度、空指针、全零/全一输入也已检查。
- CadQuery 导入原 O3 逐件 STEP，对新元件最大外形包络求交。名义调整后无新元件/旧机构相交；仍未覆盖焊料、连接器内部、完整配合头、带线维护路径、制造公差和实际磁场。

### 校验通过不代表可以装机

MT6701 的 14 位分辨率约为 0.022°/计数，不能当作 0.022° 的精度；手册 INL 典型/最大值为 ±1°/±1.5°，新传感器必须建立独立方向、零位和实际磁场校准。

手册给出了 CRC6 多项式和 18 位数据顺序，但本轮没有取得确认 init/xor 的原厂测试向量；时钟空闲态文字与图示也存在需要澄清之处。因此 codec 的 init=0/xor=0 明确标为数学假设，解码结果始终不能授权 Capture。全零输入在此假设下可以通过 CRC，测试特意保留这个反例，不能仅凭 CRC 证明连接正常。

QFN 裸露焊盘的电气接法没有在已核对的引脚表中说明。新封装保留隔离铜岛，**等待厂家确认，阻塞打样/制造放行**；没有擅自把它接地后宣称电气完成。压接端子的剥线、压接高度及拉脱力也仍需针对实际线批、模具和设备确认。

## 机械及供电结论

旧 STEP 的 FR4 实体厚度为 0.91 mm，与项目名义 1 mm 不完全相同。本轮保留原支承面 `z=27.685 mm`，把试验板按 1 mm 实体建模；未经调整会与两侧压板各相交约 0.14625 mm³。试验装配中压板与螺钉上移 **0.09 mm** 后消除名义相交。板厚公差、剩余啮合和夹紧力仍未合格，不改变旧 O3/O5 模型。

磁体至 MT6701 封装最近表面的名义间距约 **1.785 mm**。这个几何值不能证明芯片处磁场满足要求。新局部模块轴向包络约 49.885 mm，没有形成可宣称的关节缩小成果。肩部 N2/RF 既有干涉仍未关闭。

锐尔立候选每片在当前导向内有约 **3.293 mm³** 相交，四片均失败；目录载荷点为 294 N@0.59 mm，也不能继承原 326 N 参考。该厂家仍可以作为精确规格询价对象，但不能直接把物料名称换掉。

CJT 规范给出的接触电阻上限为初始 20 mΩ、部分环境条件后 40 mΩ，另外压接段 10 mΩ。采用后者分别计入四个接触与四个压接点，在旧草拟最长线、60°C、线阻加 10%、200 mA 条件下，假设 CJT 用于 J50 的远端电压约为 Manny **3.0285 V**、Quinn **3.0295 V**，仍不满足 3.05 V 的预留目标。J50 实际未换型，这个复算证明“换国产连接器”本身不能消除供电缺口。

## 后续选型依据

1. 国内供应路线优先落实 CJT 成套线束工艺、MT6701 精确订货身份和原厂 SSI/EP 资料。未发出询价，也未联系供应商。
2. 新线材必须同时给出 AWG、股数、绝缘外径上限、线阻上限、弯扭寿命及对应端子的压接工艺，不能用“柔软硅胶线”描述替代规格。当前国产线样本未胜出，不代表所有国内线材都不适合。
3. 自定义金属件可以向国内 CNC/精密加工路线评估，但现有微米级配合、薄壁和中断螺纹要逐项 DFM。平台通用能力说明不作为该零件的公差承诺。
4. 有硬件后才做 AS5048 与 MT6701 在相同磁体/装配/温度下的静态重复性、回零、掉电/断线和误捕捉对照，并比较真实价格、交期、返工成本后决定生产替换。

480 mm 主线、高度边界、41 测量轴+3 固定槽、外置 G0、6 个区域、7 个 CAN 节点、无线能力，以及取消 1.2 kg 硬门槛的要求保持不变。所有新增文件独立置于 O5CN 范围，原 O5 的封存材料保留。

## 审查与复算入口

- 结构化来源：`Hardware/PoseDoll44/references/revO5CN/`，含下载日期和 PDF SHA-256。
- 试验约束：`Hardware/PoseDoll44/mechanical_manifest/requirements_revO5CN.json`。
- 原生板：`Hardware/PoseDoll44/electronics/sensor_revO5CN/PoseDoll_MT6701_CJT_CN1.kicad_pcb`。
- 机械试验：`Hardware/PoseDoll44/generated/revO5CN/runs/cn_20260924_r1/sensor_installation_trial.step`。
- 定量结果：`Hardware/PoseDoll44/verification/revO5CN/runs/cn_20260924_r1/`。
- 可携带原生文件与输入：`Hardware/PoseDoll44/verification/revO5CN/delivery/cn1_native_and_inputs.zip`。

从设计仓库根运行（本地工具路径与既有项目一致）：

```powershell
& 'D:/ProgramFiles/KiCad/10.0/bin/python.exe' scripts/build_revo5cn_sensor.py
& 'D:/ProgramFiles/KiCad/10.0/bin/python.exe' scripts/verify_revo5cn_sensor.py
.venv/Scripts/python.exe -X utf8 Hardware/PoseDoll44/tools/run_cad.py Hardware/PoseDoll44/cad/revO5CN/supplier_trial.py
.venv/Scripts/python.exe -X utf8 scripts/analyze_revo5cn_suppliers.py
scripts/Run-RevO5CN-CodecTests.cmd "$PWD/.local/cn_codec_recheck"
.venv/Scripts/python.exe -X utf8 scripts/seal_revo5cn.py --verify
```

重新生成会改变 KiCad UUID、输出字节和时间信息；请先验证本次封存，再在独立副本复算，不要把重生成结果冒充原封存文件。

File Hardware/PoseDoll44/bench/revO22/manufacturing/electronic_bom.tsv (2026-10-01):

board | references | value | footprint | mpn_or_procurement_spec | per_board | assembled_boards | net_quantity | purchase_quantity_or_moq | acceptance
sensor | C1 | 100n X7R 16V | C_0603_1608Metric |  | 1 | 48 | 48 | SUPPLIER_QUOTE_REQUIRED | Supplier to return exact manufacturer MPN in AVL before first article; meet value, dielectric, rating and package.
sensor | C2 | 1u X7R 16V | C_0603_1608Metric |  | 1 | 48 | 48 | SUPPLIER_QUOTE_REQUIRED | Supplier to return exact manufacturer MPN in AVL before first article; meet value, dielectric, rating and package.
sensor | R1 | 33R | R_0603_1608Metric |  | 1 | 48 | 48 | SUPPLIER_QUOTE_REQUIRED | Supplier to return exact manufacturer MPN in AVL before first article; meet value, dielectric, rating and package.
sensor | J1 | FACTORY_SOLDERED_5_CORE | WirePads_5P |  | 1 | 48 | 48 | SUPPLIER_QUOTE_REQUIRED | Supplier to return exact manufacturer MPN in AVL before first article; meet value, dielectric, rating and package.
sensor | R2 | 10k | R_0603_1608Metric |  | 1 | 48 | 48 | SUPPLIER_QUOTE_REQUIRED | Supplier to return exact manufacturer MPN in AVL before first article; meet value, dielectric, rating and package.
sensor | U1 | MT6701CT-STD-R | SOIC-8_3.9x4.9mm_P1.27mm | MT6701CT-STD-R | 1 | 48 | 48 | SUPPLIER_QUOTE_REQUIRED | Exact listed MPN; substitutions require same pin map and documented electrical/package equivalence.
carrier | J54 | JST SH 5P top entry | JST_SH_BM05B-SRSS-TB_1x05-1MP_P1.00mm_Vertical | BM05B-SRSS-TB | 1 | 1 | 1 | SUPPLIER_QUOTE_REQUIRED | Exact listed MPN; substitutions require same pin map and documented electrical/package equivalence.
carrier | R2 R40 R41 R42 | 10k | R_0603_1608Metric |  | 4 | 1 | 4 | SUPPLIER_QUOTE_REQUIRED | Supplier to return exact manufacturer MPN in AVL before first article; meet value, dielectric, rating and package.
carrier | J29 | JST SH 5P top entry | JST_SH_BM05B-SRSS-TB_1x05-1MP_P1.00mm_Vertical | BM05B-SRSS-TB | 1 | 1 | 1 | SUPPLIER_QUOTE_REQUIRED | Exact listed MPN; substitutions require same pin map and documented electrical/package equivalence.
carrier | F4 | 1206L110THR / input 1.1A | Fuse_1206_3216Metric | 1206L110THR | 1 | 1 | 1 | SUPPLIER_QUOTE_REQUIRED | Exact listed MPN; substitutions require same pin map and documented electrical/package equivalence.
carrier | J45 | JST SH 5P top entry | JST_SH_BM05B-SRSS-TB_1x05-1MP_P1.00mm_Vertical | BM05B-SRSS-TB | 1 | 1 | 1 | SUPPLIER_QUOTE_REQUIRED | Exact listed MPN; substitutions require same pin map and documented electrical/package equivalence.
carrier | J32 | JST SH 5P top entry | JST_SH_BM05B-SRSS-TB_1x05-1MP_P1.00mm_Vertical | BM05B-SRSS-TB | 1 | 1 | 1 | SUPPLIER_QUOTE_REQUIRED | Exact listed MPN; substitutions require same pin map and documented electrical/package equivalence.
carrier | J26 | JST SH 5P top entry | JST_SH_BM05B-SRSS-TB_1x05-1MP_P1.00mm_Vertical | BM05B-SRSS-TB | 1 | 1 | 1 | SUPPLIER_QUOTE_REQUIRED | Exact listed MPN; substitutions require same pin map and documented electrical/package equivalence.
carrier | J10 | JST SH 5P top entry | JST_SH_BM05B-SRSS-TB_1x05-1MP_P1.00mm_Vertical | BM05B-SRSS-TB | 1 | 1 | 1 | SUPPLIER_QUOTE_REQUIRED | Exact listed MPN; substitutions require same pin map and documented electrical/package equivalence.
carrier | J42 | JST SH 5P top entry | JST_SH_BM05B-SRSS-TB_1x05-1MP_P1.00mm_Vertical | BM05B-SRSS-TB | 1 | 1 | 1 | SUPPLIER_QUOTE_REQUIRED | Exact listed MPN; substitutions require same pin map and documented electrical/package equivalence.
carrier | R30 R31 R32 R33 R34 R35 | 33R candidate | R_0603_1608Metric |  | 6 | 1 | 6 | SUPPLIER_QUOTE_REQUIRED | Supplier to return exact manufacturer MPN in AVL before first article; meet value, dielectric, rating and package.
carrier | J51 | JST SH 5P top entry | JST_SH_BM05B-SRSS-TB_1x05-1MP_P1.00mm_Vertical | BM05B-SRSS-TB | 1 | 1 | 1 | SUPPLIER_QUOTE_REQUIRED | Exact listed MPN; substitutions require same pin map and documented electrical/package equivalence.
carrier | C7 C8 C9 | 22u 10V X7R effective >=10u | C_0805_2012Metric | GRM21BR61A226ME51L (subject to DC-bias acceptance) | 3 | 1 | 3 | SUPPLIER_QUOTE_REQUIRED | Exact listed MPN; substitutions require same pin map and documented electrical/package equivalence. C7 effective >=10uF at 4.1V; C8+C9 effective >=20uF at 3.45V. Supplier DC-bias curve required.
carrier | J57 | JST SH 5P top entry | JST_SH_BM05B-SRSS-TB_1x05-1MP_P1.00mm_Vertical | BM05B-SRSS-TB | 1 | 1 | 1 | SUPPLIER_QUOTE_REQUIRED | Exact listed MPN; substitutions require same pin map and documented electrical/package equivalence.
carrier | J33 | JST SH 5P top entry | JST_SH_BM05B-SRSS-TB_1x05-1MP_P1.00mm_Vertical | BM05B-SRSS-TB | 1 | 1 | 1 | SUPPLIER_QUOTE_REQUIRED | Exact listed MPN; substitutions require same pin map and documented electrical/package equivalence.
carrier | J50 | JST SH 5P top entry | JST_SH_BM05B-SRSS-TB_1x05-1MP_P1.00mm_Vertical | BM05B-SRSS-TB | 1 | 1 | 1 | SUPPLIER_QUOTE_REQUIRED | Exact listed MPN; substitutions require same pin map and documented electrical/package equivalence.
carrier | J30 | JST SH 5P top entry | JST_SH_BM05B-SRSS-TB_1x05-1MP_P1.00mm_Vertical | BM05B-SRSS-TB | 1 | 1 | 1 | SUPPLIER_QUOTE_REQUIRED | Exact listed MPN; substitutions require same pin map and documented electrical/package equivalence.
carrier | U7 | AP3429AW5-7 | TSOT-23-5 | AP3429AW5-7 | 1 | 1 | 1 | SUPPLIER_QUOTE_REQUIRED | Exact listed MPN; substitutions require same pin map and documented electrical/package equivalence.
carrier | J38 | JST SH 5P top entry | JST_SH_BM05B-SRSS-TB_1x05-1MP_P1.00mm_Vertical | BM05B-SRSS-TB | 1 | 1 | 1 | SUPPLIER_QUOTE_REQUIRED | Exact listed MPN; substitutions require same pin map and documented electrical/package equivalence.
carrier | R1 R10 R11 R12 R13 R14 R15 | 100k | R_0603_1608Metric |  | 7 | 1 | 7 | SUPPLIER_QUOTE_REQUIRED | Supplier to return exact manufacturer MPN in AVL before first article; meet value, dielectric, rating and package.
carrier | J41 | JST SH 5P top entry | JST_SH_BM05B-SRSS-TB_1x05-1MP_P1.00mm_Vertical | BM05B-SRSS-TB | 1 | 1 | 1 | SUPPLIER_QUOTE_REQUIRED | Exact listed MPN; substitutions require same pin map and documented electrical/package equivalence.
carrier | J56 | JST SH 5P top entry | JST_SH_BM05B-SRSS-TB_1x05-1MP_P1.00mm_Vertical | BM05B-SRSS-TB | 1 | 1 | 1 | SUPPLIER_QUOTE_REQUIRED | Exact listed MPN; substitutions require same pin map and documented electrical/package equivalence.
carrier | J11 | JST SH 5P top entry | JST_SH_BM05B-SRSS-TB_1x05-1MP_P1.00mm_Vertical | BM05B-SRSS-TB | 1 | 1 | 1 | SUPPLIER_QUOTE_REQUIRED | Exact listed MPN; substitutions require same pin map and documented electrical/package equivalence.
carrier | J27 | JST SH 5P top entry | JST_SH_BM05B-SRSS-TB_1x05-1MP_P1.00mm_Vertical | BM05B-SRSS-TB | 1 | 1 | 1 | SUPPLIER_QUOTE_REQUIRED | Exact listed MPN; substitutions require same pin map and documented electrical/package equivalence.
carrier | J1 | 7P header | PinHeader_1x07_P2.54mm_Vertical | 2.54mm male header 1x7, 4.0mm PCB gap, rows 15.24mm | 1 | 1 | 1 | SUPPLIER_QUOTE_REQUIRED | Exact listed MPN; substitutions require same pin map and documented electrical/package equivalence.
carrier | J20 | JST SH 5P top entry | JST_SH_BM05B-SRSS-TB_1x05-1MP_P1.00mm_Vertical | BM05B-SRSS-TB | 1 | 1 | 1 | SUPPLIER_QUOTE_REQUIRED | Exact listed MPN; substitutions require same pin map and documented electrical/package equivalence.
carrier | J23 | JST SH 5P top entry | JST_SH_BM05B-SRSS-TB_1x05-1MP_P1.00mm_Vertical | BM05B-SRSS-TB | 1 | 1 | 1 | SUPPLIER_QUOTE_REQUIRED | Exact listed MPN; substitutions require same pin map and documented electrical/package equivalence.
carrier | J21 | JST SH 5P top entry | JST_SH_BM05B-SRSS-TB_1x05-1MP_P1.00mm_Vertical | BM05B-SRSS-TB | 1 | 1 | 1 | SUPPLIER_QUOTE_REQUIRED | Exact listed MPN; substitutions require same pin map and documented electrical/package equivalence.
carrier | J3 | EXTERNAL REGULATED 5V ONLY; NO USB VBUS TIE | JST_PH_B2B-PH-SM4-TB_1x02-1MP_P2.00mm_Vertical |  | 1 | 1 | 1 | SUPPLIER_QUOTE_REQUIRED | Supplier to return exact manufacturer MPN in AVL before first article; meet value, dielectric, rating and package.
carrier | U3 U4 U5 | CD74HC4067PW | TSSOP-24_4.4x7.8mm_P0.65mm | CD74HC4067PW | 3 | 1 | 3 | SUPPLIER_QUOTE_REQUIRED | Exact listed MPN; substitutions require same pin map and documented electrical/package equivalence.
carrier | C1 C2 C3 C4 C5 C6 | 100n | C_0603_1608Metric |  | 6 | 1 | 6 | SUPPLIER_QUOTE_REQUIRED | Supplier to return exact manufacturer MPN in AVL before first article; meet value, dielectric, rating and package.
carrier | J19 | JST SH 5P top entry | JST_SH_BM05B-SRSS-TB_1x05-1MP_P1.00mm_Vertical | BM05B-SRSS-TB | 1 | 1 | 1 | SUPPLIER_QUOTE_REQUIRED | Exact listed MPN; substitutions require same pin map and documented electrical/package equivalence.
carrier | J36 | JST SH 5P top entry | JST_SH_BM05B-SRSS-TB_1x05-1MP_P1.00mm_Vertical | BM05B-SRSS-TB | 1 | 1 | 1 | SUPPLIER_QUOTE_REQUIRED | Exact listed MPN; substitutions require same pin map and documented electrical/package equivalence.
carrier | J46 | JST SH 5P top entry | JST_SH_BM05B-SRSS-TB_1x05-1MP_P1.00mm_Vertical | BM05B-SRSS-TB | 1 | 1 | 1 | SUPPLIER_QUOTE_REQUIRED | Exact listed MPN; substitutions require same pin map and documented electrical/package equivalence.
carrier | J40 | JST SH 5P top entry | JST_SH_BM05B-SRSS-TB_1x05-1MP_P1.00mm_Vertical | BM05B-SRSS-TB | 1 | 1 | 1 | SUPPLIER_QUOTE_REQUIRED | Exact listed MPN; substitutions require same pin map and documented electrical/package equivalence.
carrier | J55 | JST SH 5P top entry | JST_SH_BM05B-SRSS-TB_1x05-1MP_P1.00mm_Vertical | BM05B-SRSS-TB | 1 | 1 | 1 | SUPPLIER_QUOTE_REQUIRED | Exact listed MPN; substitutions require same pin map and documented electrical/package equivalence.
carrier | J49 | JST SH 5P top entry | JST_SH_BM05B-SRSS-TB_1x05-1MP_P1.00mm_Vertical | BM05B-SRSS-TB | 1 | 1 | 1 | SUPPLIER_QUOTE_REQUIRED | Exact listed MPN; substitutions require same pin map and documented electrical/package equivalence.
carrier | J43 | JST SH 5P top entry | JST_SH_BM05B-SRSS-TB_1x05-1MP_P1.00mm_Vertical | BM05B-SRSS-TB | 1 | 1 | 1 | SUPPLIER_QUOTE_REQUIRED | Exact listed MPN; substitutions require same pin map and documented electrical/package equivalence.
carrier | J14 | JST SH 5P top entry | JST_SH_BM05B-SRSS-TB_1x05-1MP_P1.00mm_Vertical | BM05B-SRSS-TB | 1 | 1 | 1 | SUPPLIER_QUOTE_REQUIRED | Exact listed MPN; substitutions require same pin map and documented electrical/package equivalence.
carrier | J17 | JST SH 5P top entry | JST_SH_BM05B-SRSS-TB_1x05-1MP_P1.00mm_Vertical | BM05B-SRSS-TB | 1 | 1 | 1 | SUPPLIER_QUOTE_REQUIRED | Exact listed MPN; substitutions require same pin map and documented electrical/package equivalence.
carrier | F5 | 0467001.NR / 1A fast | Fuse_0603_1608Metric | 0467001.NR | 1 | 1 | 1 | SUPPLIER_QUOTE_REQUIRED | Exact listed MPN; substitutions require same pin map and documented electrical/package equivalence.
carrier | J39 | JST SH 5P top entry | JST_SH_BM05B-SRSS-TB_1x05-1MP_P1.00mm_Vertical | BM05B-SRSS-TB | 1 | 1 | 1 | SUPPLIER_QUOTE_REQUIRED | Exact listed MPN; substitutions require same pin map and documented electrical/package equivalence.
carrier | J16 | JST SH 5P top entry | JST_SH_BM05B-SRSS-TB_1x05-1MP_P1.00mm_Vertical | BM05B-SRSS-TB | 1 | 1 | 1 | SUPPLIER_QUOTE_REQUIRED | Exact listed MPN; substitutions require same pin map and documented electrical/package equivalence.
carrier | J37 | JST SH 5P top entry | JST_SH_BM05B-SRSS-TB_1x05-1MP_P1.00mm_Vertical | BM05B-SRSS-TB | 1 | 1 | 1 | SUPPLIER_QUOTE_REQUIRED | Exact listed MPN; substitutions require same pin map and documented electrical/package equivalence.
carrier | U1 U2 | SN74LVC244APWR | TSSOP-20_4.4x6.5mm_P0.65mm | SN74LVC244APWR | 2 | 1 | 2 | SUPPLIER_QUOTE_REQUIRED | Exact listed MPN; substitutions require same pin map and documented electrical/package equivalence.
carrier | J47 | JST SH 5P top entry | JST_SH_BM05B-SRSS-TB_1x05-1MP_P1.00mm_Vertical | BM05B-SRSS-TB | 1 | 1 | 1 | SUPPLIER_QUOTE_REQUIRED | Exact listed MPN; substitutions require same pin map and documented electrical/package equivalence.
carrier | R51 | 66.5k 0.1% | R_0603_1608Metric | TNPW060366K5BEEA | 1 | 1 | 1 | SUPPLIER_QUOTE_REQUIRED | Exact listed MPN; substitutions require same pin map and documented electrical/package equivalence.
carrier | C10 | 22p C0G starting value | C_0603_1608Metric |  | 1 | 1 | 1 | SUPPLIER_QUOTE_REQUIRED | Supplier to return exact manufacturer MPN in AVL before first article; meet value, dielectric, rating and package.
carrier | J28 | JST SH 5P top entry | JST_SH_BM05B-SRSS-TB_1x05-1MP_P1.00mm_Vertical | BM05B-SRSS-TB | 1 | 1 | 1 | SUPPLIER_QUOTE_REQUIRED | Exact listed MPN; substitutions require same pin map and documented electrical/package equivalence.
carrier | D1 | 1A Schottky / qualification Vf <=0.5V at full load | D_SMA | SS14 | 1 | 1 | 1 | SUPPLIER_QUOTE_REQUIRED | Exact listed MPN; substitutions require same pin map and documented electrical/package equivalence.
carrier | R50 | 316k 0.1% | R_0603_1608Metric | TNPW0603316KBEEA | 1 | 1 | 1 | SUPPLIER_QUOTE_REQUIRED | Exact listed MPN; substitutions require same pin map and documented electrical/package equivalence.
carrier | J15 | JST SH 5P top entry | JST_SH_BM05B-SRSS-TB_1x05-1MP_P1.00mm_Vertical | BM05B-SRSS-TB | 1 | 1 | 1 | SUPPLIER_QUOTE_REQUIRED | Exact listed MPN; substitutions require same pin map and documented electrical/package equivalence.
carrier | U6 | SN74LVC125APWR | TSSOP-14_4.4x5mm_P0.65mm | SN74LVC125APWR | 1 | 1 | 1 | SUPPLIER_QUOTE_REQUIRED | Exact listed MPN; substitutions require same pin map and documented electrical/package equivalence.
carrier | J22 | JST SH 5P top entry | JST_SH_BM05B-SRSS-TB_1x05-1MP_P1.00mm_Vertical | BM05B-SRSS-TB | 1 | 1 | 1 | SUPPLIER_QUOTE_REQUIRED | Exact listed MPN; substitutions require same pin map and documented electrical/package equivalence.
carrier | J31 | JST SH 5P top entry | JST_SH_BM05B-SRSS-TB_1x05-1MP_P1.00mm_Vertical | BM05B-SRSS-TB | 1 | 1 | 1 | SUPPLIER_QUOTE_REQUIRED | Exact listed MPN; substitutions require same pin map and documented electrical/package equivalence.
carrier | J34 | JST SH 5P top entry | JST_SH_BM05B-SRSS-TB_1x05-1MP_P1.00mm_Vertical | BM05B-SRSS-TB | 1 | 1 | 1 | SUPPLIER_QUOTE_REQUIRED | Exact listed MPN; substitutions require same pin map and documented electrical/package equivalence.
carrier | J53 | JST SH 5P top entry | JST_SH_BM05B-SRSS-TB_1x05-1MP_P1.00mm_Vertical | BM05B-SRSS-TB | 1 | 1 | 1 | SUPPLIER_QUOTE_REQUIRED | Exact listed MPN; substitutions require same pin map and documented electrical/package equivalence.
carrier | Q1 | 2N7002 | SOT-23 | 2N7002 | 1 | 1 | 1 | SUPPLIER_QUOTE_REQUIRED | Exact listed MPN; substitutions require same pin map and documented electrical/package equivalence.
carrier | J13 | JST SH 5P top entry | JST_SH_BM05B-SRSS-TB_1x05-1MP_P1.00mm_Vertical | BM05B-SRSS-TB | 1 | 1 | 1 | SUPPLIER_QUOTE_REQUIRED | Exact listed MPN; substitutions require same pin map and documented electrical/package equivalence.
carrier | J48 | JST SH 5P top entry | JST_SH_BM05B-SRSS-TB_1x05-1MP_P1.00mm_Vertical | BM05B-SRSS-TB | 1 | 1 | 1 | SUPPLIER_QUOTE_REQUIRED | Exact listed MPN; substitutions require same pin map and documented electrical/package equivalence.
carrier | J44 | JST SH 5P top entry | JST_SH_BM05B-SRSS-TB_1x05-1MP_P1.00mm_Vertical | BM05B-SRSS-TB | 1 | 1 | 1 | SUPPLIER_QUOTE_REQUIRED | Exact listed MPN; substitutions require same pin map and documented electrical/package equivalence.
carrier | J52 | JST SH 5P top entry | JST_SH_BM05B-SRSS-TB_1x05-1MP_P1.00mm_Vertical | BM05B-SRSS-TB | 1 | 1 | 1 | SUPPLIER_QUOTE_REQUIRED | Exact listed MPN; substitutions require same pin map and documented electrical/package equivalence.
carrier | L1 | 74438357022 / 2.2uH | L_Wuerth_MAPI-4030 | 74438357022 | 1 | 1 | 1 | SUPPLIER_QUOTE_REQUIRED | Exact listed MPN; substitutions require same pin map and documented electrical/package equivalence.
carrier | J2 | 7P header | PinHeader_1x07_P2.54mm_Vertical | 2.54mm male header 1x7, 4.0mm PCB gap, rows 15.24mm | 1 | 1 | 1 | SUPPLIER_QUOTE_REQUIRED | Exact listed MPN; substitutions require same pin map and documented electrical/package equivalence.
carrier | J35 | JST SH 5P top entry | JST_SH_BM05B-SRSS-TB_1x05-1MP_P1.00mm_Vertical | BM05B-SRSS-TB | 1 | 1 | 1 | SUPPLIER_QUOTE_REQUIRED | Exact listed MPN; substitutions require same pin map and documented electrical/package equivalence.
carrier | J18 | JST SH 5P top entry | JST_SH_BM05B-SRSS-TB_1x05-1MP_P1.00mm_Vertical | BM05B-SRSS-TB | 1 | 1 | 1 | SUPPLIER_QUOTE_REQUIRED | Exact listed MPN; substitutions require same pin map and documented electrical/package equivalence.
carrier | J12 | JST SH 5P top entry | JST_SH_BM05B-SRSS-TB_1x05-1MP_P1.00mm_Vertical | BM05B-SRSS-TB | 1 | 1 | 1 | SUPPLIER_QUOTE_REQUIRED | Exact listed MPN; substitutions require same pin map and documented electrical/package equivalence.

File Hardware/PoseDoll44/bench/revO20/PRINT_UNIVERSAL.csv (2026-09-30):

print_id | quantity | file | parts
P001 | 1 | print_batch/P001.stl | waist/C01
P002 | 1 | print_batch/P002.stl | waist/C14
P003 | 1 | print_batch/P003.stl | waist/C15
P012 | 2 | print_batch/P012.stl | waist/P_radial_pad; thigh_r/P_radial_pad
P013 | 2 | print_batch/P013.stl | waist/P_magnet_cap; thigh_r/P_magnet_cap
P014 | 2 | print_batch/P014.stl | waist/P_pcb_clip_-14; thigh_r/P_pcb_clip_-14
P015 | 2 | print_batch/P015.stl | waist/P_pcb_clip_+14; thigh_r/P_pcb_clip_+14
P016 | 2 | print_batch/P016.stl | waist/P_case_plus; thigh_r/P_case_plus
P017 | 1 | print_batch/P017.stl | chest/C01
P018 | 1 | print_batch/P018.stl | chest/C14
P019 | 1 | print_batch/P019.stl | chest/C15
P028 | 1 | print_batch/P028.stl | chest/P_radial_pad
P029 | 1 | print_batch/P029.stl | chest/P_magnet_cap
P030 | 1 | print_batch/P030.stl | chest/P_pcb_clip_-14
P031 | 1 | print_batch/P031.stl | chest/P_pcb_clip_+14
P032 | 1 | print_batch/P032.stl | chest/P_case_plus
P033 | 1 | print_batch/P033.stl | head/C01
P034 | 1 | print_batch/P034.stl | head/C02
P035 | 1 | print_batch/P035.stl | head/C14
P036 | 1 | print_batch/P036.stl | head/C15
P039 | 1 | print_batch/P039.stl | head/P_radial_pad
P040 | 1 | print_batch/P040.stl | head/P_magnet_cap
P041 | 1 | print_batch/P041.stl | head/P_pcb_clip_-14
P042 | 1 | print_batch/P042.stl | head/P_pcb_clip_+14
P043 | 1 | print_batch/P043.stl | head/P_case_plus
P044 | 1 | print_batch/P044.stl | head/D_radial_pad
P045 | 1 | print_batch/P045.stl | head/D_magnet_cap
P046 | 1 | print_batch/P046.stl | head/D_pcb_clip_-14
P047 | 1 | print_batch/P047.stl | head/D_pcb_clip_+14
P048 | 1 | print_batch/P048.stl | head/D_case_plus
P049 | 1 | print_batch/P049.stl | upperarm_l/C01
P050 | 1 | print_batch/P050.stl | upperarm_l/C02
P051 | 1 | print_batch/P051.stl | upperarm_l/C14
P052 | 1 | print_batch/P052.stl | upperarm_l/C15
P061 | 1 | print_batch/P061.stl | upperarm_l/P_radial_pad
P062 | 1 | print_batch/P062.stl | upperarm_l/P_magnet_cap
P063 | 1 | print_batch/P063.stl | upperarm_l/P_pcb_clip_-14
P064 | 1 | print_batch/P064.stl | upperarm_l/P_pcb_clip_+14
P065 | 1 | print_batch/P065.stl | upperarm_l/P_case_plus
P066 | 1 | print_batch/P066.stl | upperarm_l/D_radial_pad
P067 | 1 | print_batch/P067.stl | upperarm_l/D_magnet_cap
P068 | 1 | print_batch/P068.stl | upperarm_l/D_pcb_clip_-14
P069 | 1 | print_batch/P069.stl | upperarm_l/D_pcb_clip_+14
P070 | 1 | print_batch/P070.stl | upperarm_l/D_case_plus
P071 | 1 | print_batch/P071.stl | upperarm_r/C01
P072 | 1 | print_batch/P072.stl | upperarm_r/C02
P073 | 1 | print_batch/P073.stl | upperarm_r/C14
P074 | 1 | print_batch/P074.stl | upperarm_r/C15
P083 | 1 | print_batch/P083.stl | upperarm_r/P_radial_pad
P084 | 1 | print_batch/P084.stl | upperarm_r/P_magnet_cap
P085 | 1 | print_batch/P085.stl | upperarm_r/P_pcb_clip_-14
P086 | 1 | print_batch/P086.stl | upperarm_r/P_pcb_clip_+14
P087 | 1 | print_batch/P087.stl | upperarm_r/P_case_plus
P088 | 1 | print_batch/P088.stl | upperarm_r/D_radial_pad
P089 | 1 | print_batch/P089.stl | upperarm_r/D_magnet_cap
P090 | 1 | print_batch/P090.stl | upperarm_r/D_pcb_clip_-14
P091 | 1 | print_batch/P091.stl | upperarm_r/D_pcb_clip_+14
P092 | 1 | print_batch/P092.stl | upperarm_r/D_case_plus
P093 | 1 | print_batch/P093.stl | thigh_l/C01
P094 | 1 | print_batch/P094.stl | thigh_l/C02
P095 | 1 | print_batch/P095.stl | thigh_l/C14
P096 | 1 | print_batch/P096.stl | thigh_l/C15
P105 | 1 | print_batch/P105.stl | thigh_l/P_radial_pad
P106 | 1 | print_batch/P106.stl | thigh_l/P_magnet_cap
P107 | 1 | print_batch/P107.stl | thigh_l/P_pcb_clip_-14
P108 | 1 | print_batch/P108.stl | thigh_l/P_pcb_clip_+14
P109 | 1 | print_batch/P109.stl | thigh_l/P_case_plus
P110 | 1 | print_batch/P110.stl | thigh_l/D_radial_pad
P111 | 1 | print_batch/P111.stl | thigh_l/D_magnet_cap
P112 | 1 | print_batch/P112.stl | thigh_l/D_pcb_clip_-14
P113 | 1 | print_batch/P113.stl | thigh_l/D_pcb_clip_+14
P114 | 1 | print_batch/P114.stl | thigh_l/D_case_plus
P115 | 1 | print_batch/P115.stl | thigh_r/C01
P116 | 1 | print_batch/P116.stl | thigh_r/C02
P117 | 1 | print_batch/P117.stl | thigh_r/C14
P118 | 1 | print_batch/P118.stl | thigh_r/C15
P125 | 1 | print_batch/P125.stl | thigh_r/D_radial_pad
P126 | 1 | print_batch/P126.stl | thigh_r/D_magnet_cap
P127 | 1 | print_batch/P127.stl | thigh_r/D_pcb_clip_-14
P128 | 1 | print_batch/P128.stl | thigh_r/D_pcb_clip_+14
P129 | 1 | print_batch/P129.stl | thigh_r/D_case_plus
P130 | 2 | print_batch/P130.stl | foot_l/C14; foot_r/C14
P131 | 2 | print_batch/P131.stl | foot_l/C15; foot_r/C15
P185 | 1 | print_batch/P185.stl | frame/hand_r
P191 | 1 | print_batch/P191.stl | frame/hand_l
P206 | 1 | print_batch/P206.stl | frame/head
P208 | 1 | print_batch/P208.stl | frame/waist
P242 | 1 | print_batch/P242.stl | fixture/xiao_spacing_gauge
N001 | 28 | print_batch/N001.stl | waist/C01_sensor_cassette; waist/C02_sensor_cassette; chest/C01_sensor_cassette; chest/C02_sensor_cassette; head/C01_sensor_cassette; head/C02_sensor_cassette; upperarm_l/C01_sensor_cassette; upperarm_l/C02_sensor_cassette; thigh_r/C01_sensor_cassette; thigh_r/C02_sensor_cassette; foot_l/C01_sensor_cassette; foot_l/C02_sensor_cassette; foot_r/C01_sensor_cassette; foot_r/C02_sensor_cassette; clavicle_l.protract/sensor_cassette; clavicle_l.elevate/sensor_cassette; elbow_l.flex/sensor_cassette; forearm_l.twist/sensor_cassette; hand_l.flex/sensor_cassette; hand_l.deviate/sensor_cassette; calf_l.flex/sensor_cassette; ball_l.flex/sensor_cassette; elbow_r.flex/sensor_cassette; forearm_r.twist/sensor_cassette; hand_r.flex/sensor_cassette; hand_r.deviate/sensor_cassette; calf_r.flex/sensor_cassette; ball_r.flex/sensor_cassette
N002 | 6 | print_batch/N002.stl | upperarm_r/C01_sensor_cassette; upperarm_r/C02_sensor_cassette; thigh_l/C01_sensor_cassette; thigh_l/C02_sensor_cassette; clavicle_r.protract/sensor_cassette; clavicle_r.elevate/sensor_cassette
N003 | 18 | print_batch/N003.stl | waist/C01_magnet_cartridge; waist/C02_magnet_cartridge; chest/C01_magnet_cartridge; chest/C02_magnet_cartridge; head/C01_magnet_cartridge; head/C02_magnet_cartridge; upperarm_l/C01_magnet_cartridge; upperarm_l/C02_magnet_cartridge; upperarm_r/C01_magnet_cartridge; upperarm_r/C02_magnet_cartridge; thigh_l/C01_magnet_cartridge; thigh_l/C02_magnet_cartridge; thigh_r/C01_magnet_cartridge; thigh_r/C02_magnet_cartridge; foot_l/C01_magnet_cartridge; foot_l/C02_magnet_cartridge; foot_r/C01_magnet_cartridge; foot_r/C02_magnet_cartridge
N004 | 16 | print_batch/N004.stl | clavicle_l.protract/magnet_cartridge; clavicle_l.elevate/magnet_cartridge; elbow_l.flex/magnet_cartridge; forearm_l.twist/magnet_cartridge; hand_l.flex/magnet_cartridge; hand_l.deviate/magnet_cartridge; calf_l.flex/magnet_cartridge; ball_l.flex/magnet_cartridge; clavicle_r.protract/magnet_cartridge; clavicle_r.elevate/magnet_cartridge; elbow_r.flex/magnet_cartridge; forearm_r.twist/magnet_cartridge; hand_r.flex/magnet_cartridge; hand_r.deviate/magnet_cartridge; calf_r.flex/magnet_cartridge; ball_r.flex/magnet_cartridge
H003 | 1 | print_batch/H003.stl | frame/upperarm_l
H004 | 1 | print_batch/H004.stl | frame/elbow_l
H006 | 1 | print_batch/H006.stl | frame/hand_l.flex_frame
H008 | 1 | print_batch/H008.stl | frame/clavicle_r.protract_frame
H010 | 1 | print_batch/H010.stl | frame/elbow_r
H012 | 1 | print_batch/H012.stl | frame/hand_r.flex_frame
W001 | 1 | print_batch/W001.stl | frame/ball_r
W002 | 1 | print_batch/W002.stl | frame/forearm_r
W003 | 1 | print_batch/W003.stl | frame/ball_l
W004 | 1 | print_batch/W004.stl | frame/forearm_l
W005 | 1 | print_batch/W005.stl | frame/clavicle_l.protract_frame
W006 | 1 | print_batch/W006.stl | frame/calf_r
W007 | 1 | print_batch/W007.stl | frame/calf_l
W008 | 1 | print_batch/W008.stl | frame/thigh_r
W009 | 1 | print_batch/W009.stl | frame/thigh_l
W010 | 1 | print_batch/W010.stl | frame/upperarm_r
W011 | 1 | print_batch/W011.stl | frame/clavicle_r
W012 | 1 | print_batch/W012.stl | frame/clavicle_l
W013 | 1 | print_batch/W013.stl | frame/chest
W014 | 1 | print_batch/W014.stl | frame/pelvis
W015 | 1 | print_batch/W015.stl | accessory/chest/controller_lid
W016 | 1 | print_batch/W016.stl | frame/foot_l
W017 | 1 | print_batch/W017.stl | frame/foot_r

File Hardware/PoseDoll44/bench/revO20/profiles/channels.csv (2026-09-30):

raw_index | raw_id | chain | position_nearest_controller_zero_based | part | label
0 | waist/r0 | 1 | 0 | waist/P_sensor_PCB | J1.01
1 | waist/r1 | 1 | 1 | waist/C01_sensor_PCB | J1.02
2 | waist/r2 | 1 | 2 | waist/C02_sensor_PCB | J1.03
3 | chest/r0 | 1 | 3 | chest/P_sensor_PCB | J1.04
4 | chest/r1 | 1 | 4 | chest/C01_sensor_PCB | J1.05
5 | chest/r2 | 1 | 5 | chest/C02_sensor_PCB | J1.06
6 | head/r0 | 2 | 0 | head/P_sensor_PCB | J2.01
7 | head/r1 | 2 | 1 | head/C01_sensor_PCB | J2.02
8 | head/r2 | 2 | 2 | head/C02_sensor_PCB | J2.03
9 | head/r3 | 2 | 3 | head/D_sensor_PCB | J2.04
10 | clavicle_l.protract/r0 | 3 | 0 | clavicle_l.protract/sensor_PCB | J3.01
11 | clavicle_l.elevate/r0 | 3 | 1 | clavicle_l.elevate/sensor_PCB | J3.02
12 | upperarm_l/r0 | 3 | 2 | upperarm_l/P_sensor_PCB | J3.03
13 | upperarm_l/r1 | 3 | 3 | upperarm_l/C01_sensor_PCB | J3.04
14 | upperarm_l/r2 | 3 | 4 | upperarm_l/C02_sensor_PCB | J3.05
15 | upperarm_l/r3 | 3 | 5 | upperarm_l/D_sensor_PCB | J3.06
16 | elbow_l.flex/r0 | 3 | 6 | elbow_l.flex/sensor_PCB | J3.07
17 | forearm_l.twist/r0 | 3 | 7 | forearm_l.twist/sensor_PCB | J3.08
18 | hand_l.flex/r0 | 3 | 8 | hand_l.flex/sensor_PCB | J3.09
19 | hand_l.deviate/r0 | 3 | 9 | hand_l.deviate/sensor_PCB | J3.10
20 | clavicle_r.protract/r0 | 4 | 0 | clavicle_r.protract/sensor_PCB | J4.01
21 | clavicle_r.elevate/r0 | 4 | 1 | clavicle_r.elevate/sensor_PCB | J4.02
22 | upperarm_r/r0 | 4 | 2 | upperarm_r/P_sensor_PCB | J4.03
23 | upperarm_r/r1 | 4 | 3 | upperarm_r/C01_sensor_PCB | J4.04
24 | upperarm_r/r2 | 4 | 4 | upperarm_r/C02_sensor_PCB | J4.05
25 | upperarm_r/r3 | 4 | 5 | upperarm_r/D_sensor_PCB | J4.06
26 | elbow_r.flex/r0 | 4 | 6 | elbow_r.flex/sensor_PCB | J4.07
27 | forearm_r.twist/r0 | 4 | 7 | forearm_r.twist/sensor_PCB | J4.08
28 | hand_r.flex/r0 | 4 | 8 | hand_r.flex/sensor_PCB | J4.09
29 | hand_r.deviate/r0 | 4 | 9 | hand_r.deviate/sensor_PCB | J4.10
30 | thigh_l/r0 | 5 | 0 | thigh_l/P_sensor_PCB | J5.01
31 | thigh_l/r1 | 5 | 1 | thigh_l/C01_sensor_PCB | J5.02
32 | thigh_l/r2 | 5 | 2 | thigh_l/C02_sensor_PCB | J5.03
33 | thigh_l/r3 | 5 | 3 | thigh_l/D_sensor_PCB | J5.04
34 | calf_l.flex/r0 | 5 | 4 | calf_l.flex/sensor_PCB | J5.05
35 | foot_l/r0 | 5 | 5 | foot_l/C01_sensor_PCB | J5.06
36 | foot_l/r1 | 5 | 6 | foot_l/C02_sensor_PCB | J5.07
37 | ball_l.flex/r0 | 5 | 7 | ball_l.flex/sensor_PCB | J5.08
38 | thigh_r/r0 | 6 | 0 | thigh_r/P_sensor_PCB | J6.01
39 | thigh_r/r1 | 6 | 1 | thigh_r/C01_sensor_PCB | J6.02
40 | thigh_r/r2 | 6 | 2 | thigh_r/C02_sensor_PCB | J6.03
41 | thigh_r/r3 | 6 | 3 | thigh_r/D_sensor_PCB | J6.04
42 | calf_r.flex/r0 | 6 | 4 | calf_r.flex/sensor_PCB | J6.05
43 | foot_r/r0 | 6 | 5 | foot_r/C01_sensor_PCB | J6.06
44 | foot_r/r1 | 6 | 6 | foot_r/C02_sensor_PCB | J6.07
45 | ball_r.flex/r0 | 6 | 7 | ball_r.flex/sensor_PCB | J6.08

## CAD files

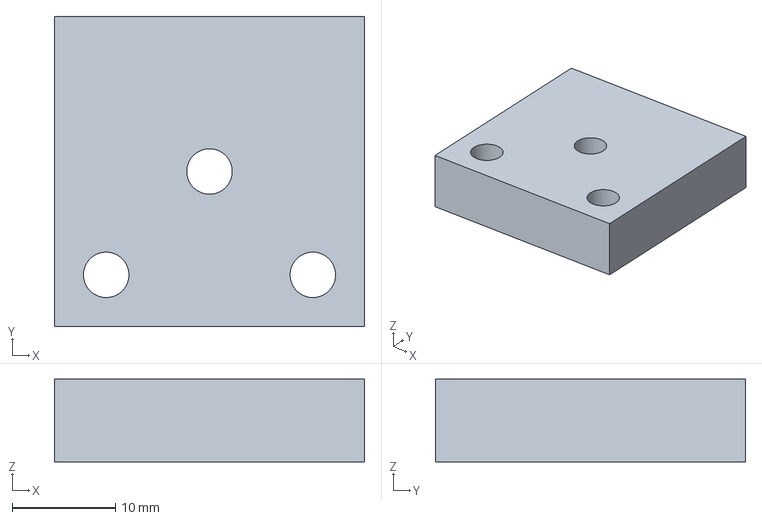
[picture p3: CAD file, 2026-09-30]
Hardware/PoseDoll44/bench/revO10/aluminium_base.step
30.0 x 30.0 x 8.00 mm

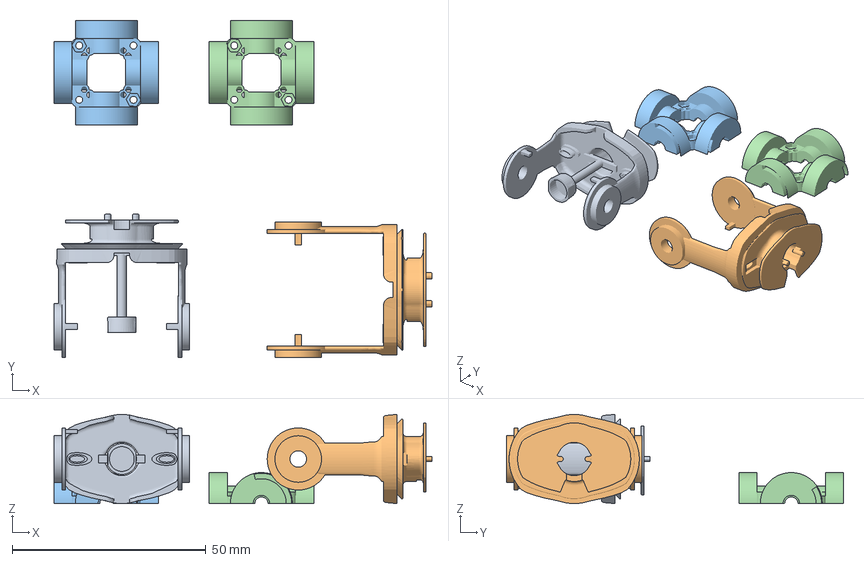
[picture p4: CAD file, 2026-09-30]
Hardware/PoseDoll44/bench/revO11/print_beds/core_fit_only.3mf
97.5 x 87.0 x 23.0 mm
C01
C02
C14
C15

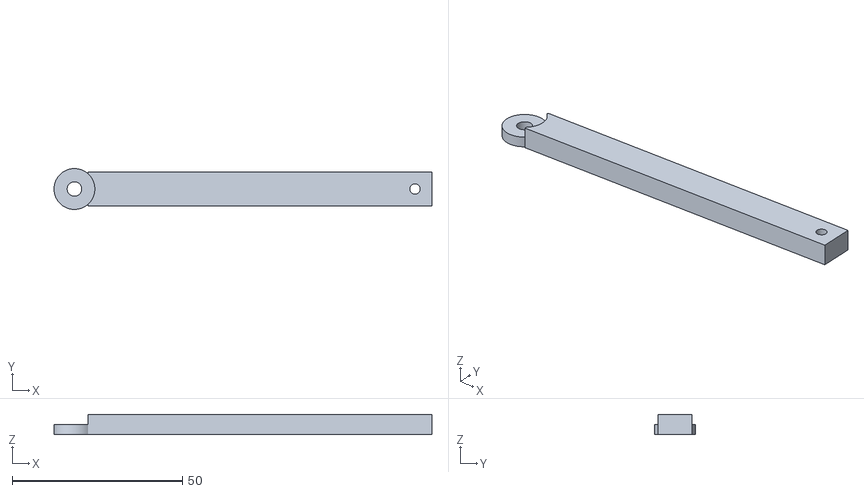
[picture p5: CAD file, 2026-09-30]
Hardware/PoseDoll44/bench/revO11/printed_lever.stl
111.0 x 12.0 x 6.00

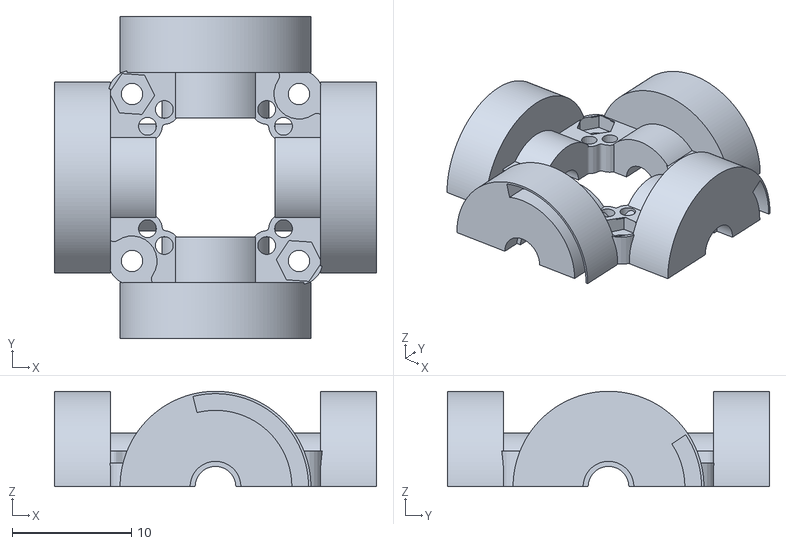
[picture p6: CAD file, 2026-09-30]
Hardware/PoseDoll44/bench/revO13/print_beds/C15_on_bed.stl
27.0 x 27.0 x 8.00

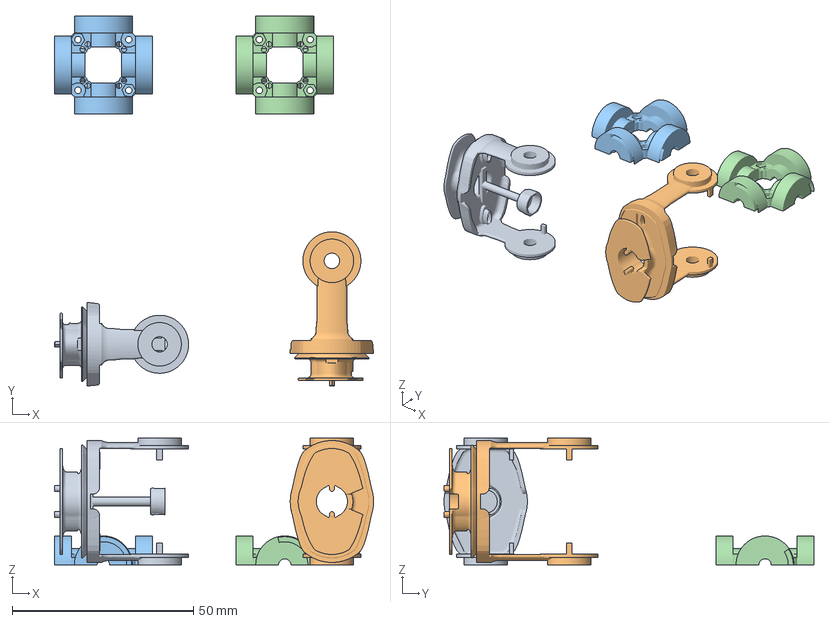
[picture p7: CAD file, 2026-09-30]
Hardware/PoseDoll44/bench/revO14/print_beds/O14_core_flat_faces_supports_required.3mf
88.0 x 102.0 x 35.0 mm
C01
C02
C14
C15

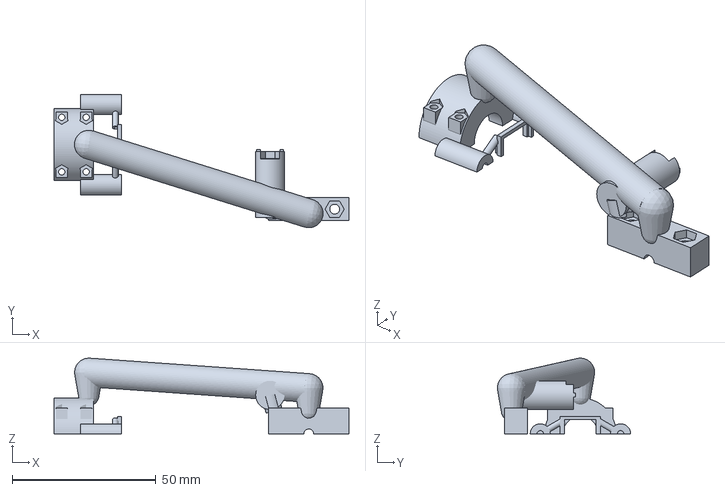
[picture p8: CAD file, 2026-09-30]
Hardware/PoseDoll44/bench/revO15/print_batch/P229.3mf
102.8 x 46.5 x 26.4 mm

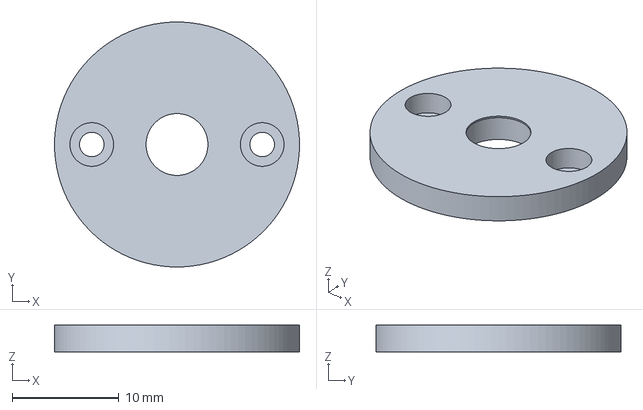
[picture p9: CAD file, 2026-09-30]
Hardware/PoseDoll44/bench/revO16/print_batch/P148.3mf
23.0 x 23.0 x 2.50 mm

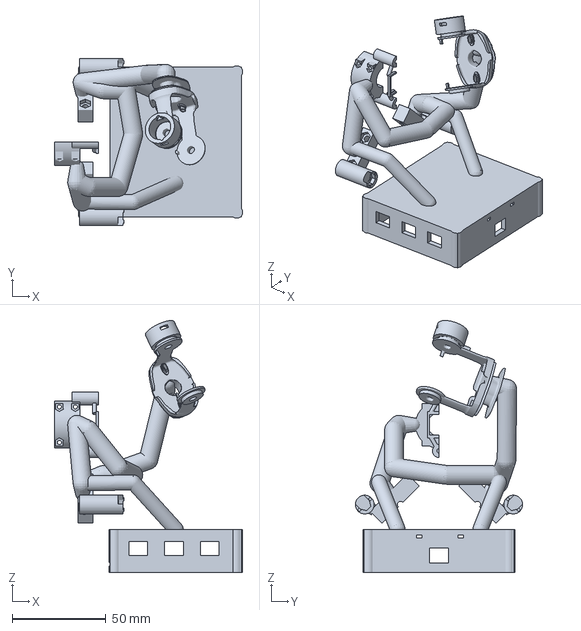
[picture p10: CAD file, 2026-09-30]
Hardware/PoseDoll44/bench/revO17/print_batch/N006.3mf
100.4 x 89.1 x 134.3 mm

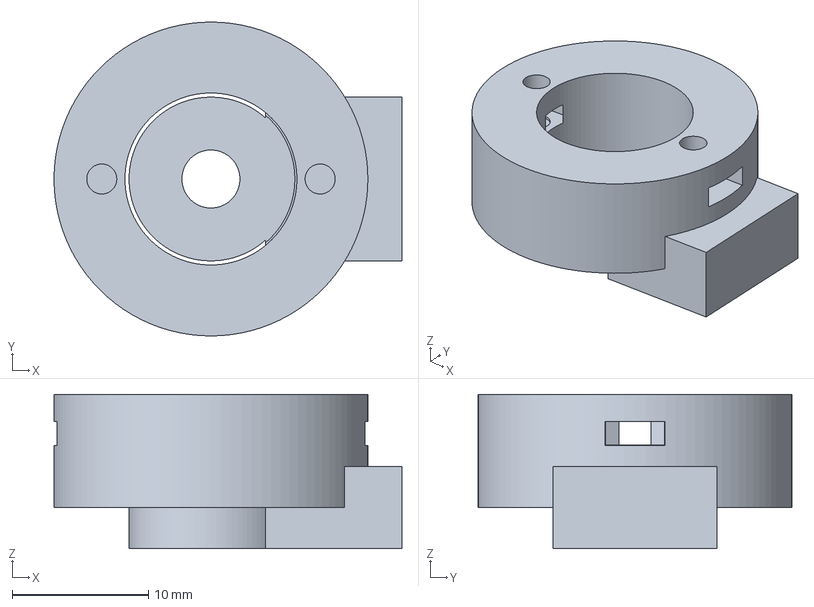
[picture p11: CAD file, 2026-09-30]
Hardware/PoseDoll44/bench/revO18/coupon/Q002.3mf
25.5 x 23.0 x 11.3 mm

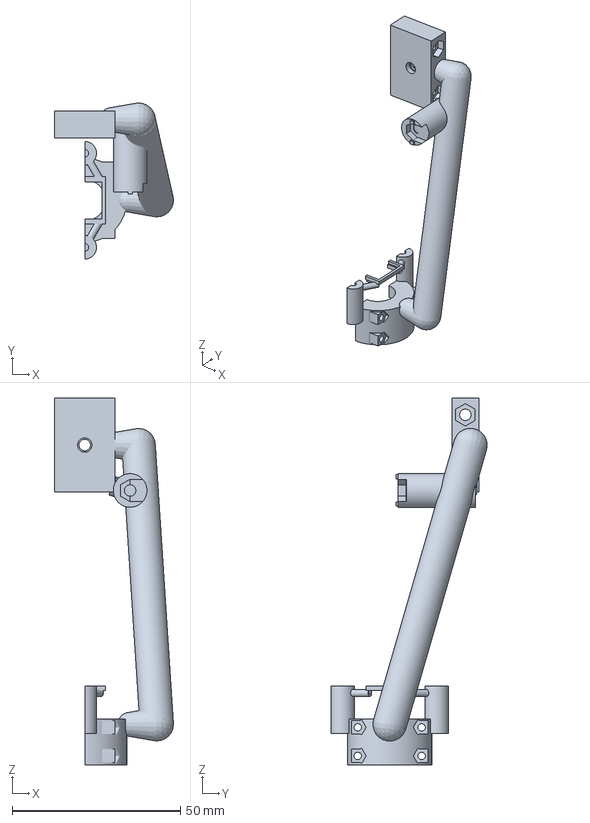
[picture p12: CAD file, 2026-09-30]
Hardware/PoseDoll44/bench/revO18/print_batch/H007.3mf
35.4 x 46.5 x 109.2 mm

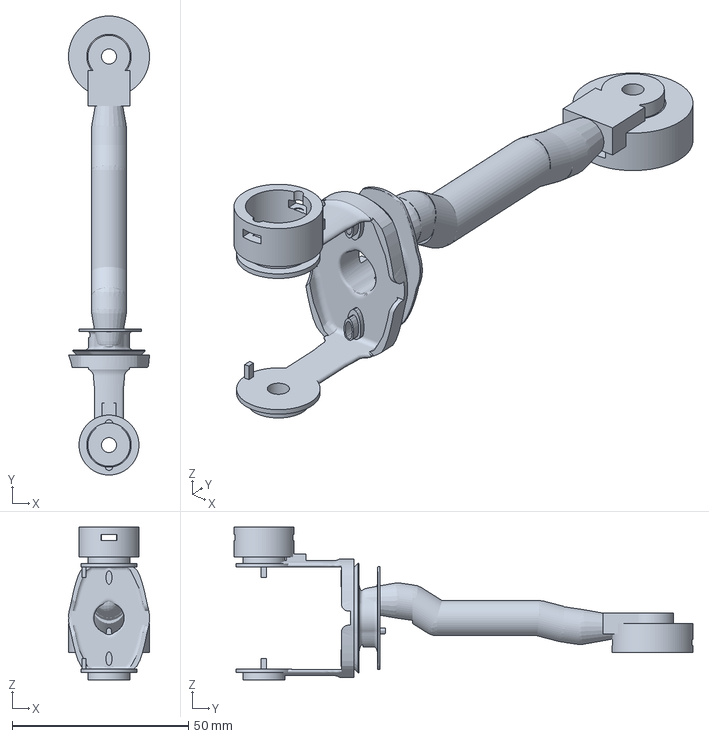
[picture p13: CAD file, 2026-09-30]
Hardware/PoseDoll44/bench/revO19/print_batch/L004.3mf
23.0 x 130.3 x 43.3 mm

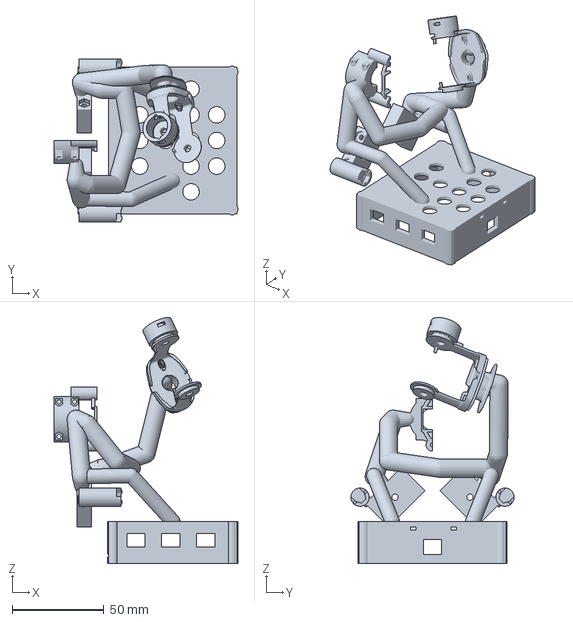
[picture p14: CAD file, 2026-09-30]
Hardware/PoseDoll44/bench/revO20/print_batch/W013.3mf
100.4 x 89.1 x 134.3 mm

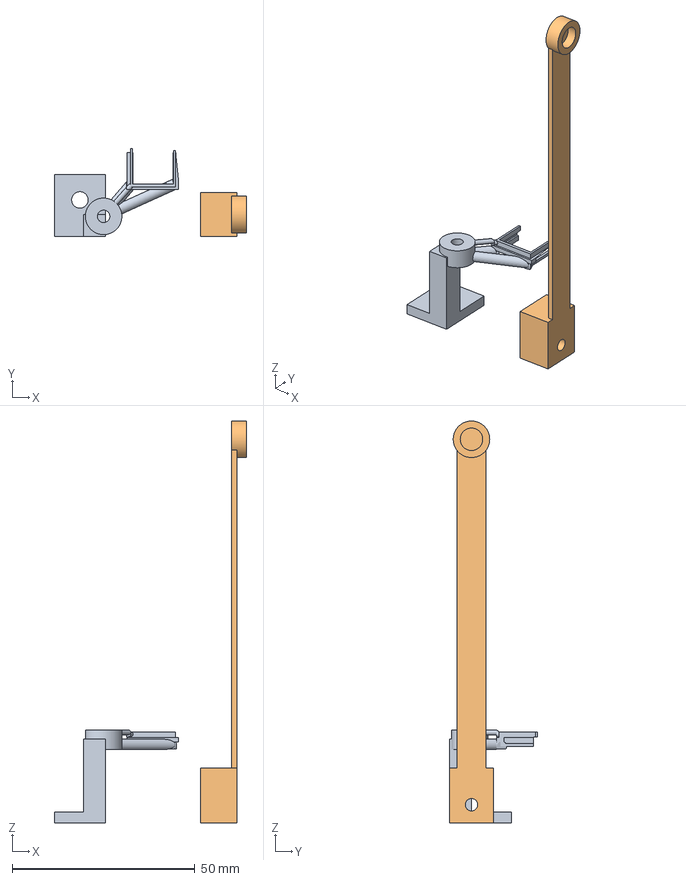
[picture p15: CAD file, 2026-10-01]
Hardware/PoseDoll44/bench/revO22/a1mini/optional/T01_sensor_coupon.3mf
52.6 x 24.0 x 110.0 mm
T01-01 T001 sensor_coupon/sensor_bridge
T01-02 T002 sensor_coupon/magnet_bridge

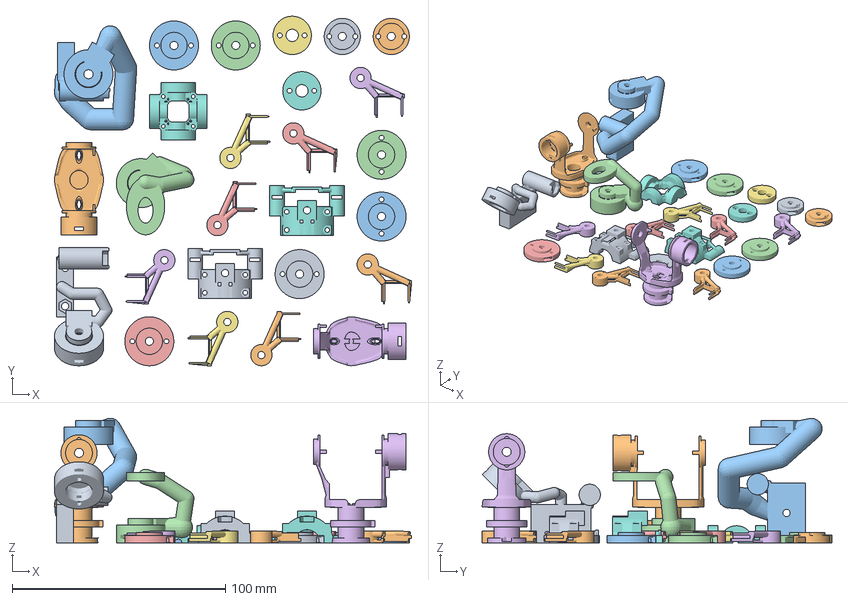
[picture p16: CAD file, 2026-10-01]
Hardware/PoseDoll44/bench/revO22/a1mini/plates/A05_left_arm_2.3mf
167.6 x 164.1 x 58.4 mm
A05-01 H006 frame/hand_l.flex_frame
A05-02 P050 upperarm_l/C02
A05-03 W004 frame/forearm_l
A05-04 P191 frame/hand_l
A05-05 N004 clavicle_l.elevate/magnet_cartridge
A05-06 X008 upperarm_l/C02_sensor_cassette
A05-07 X007 upperarm_l/C01_sensor_cassette
A05-08 P052 upperarm_l/C15
A05-09 X053 upperarm_l/P_case_plus
A05-10 X020 clavicle_l.elevate/sensor_cassette
A05-11 N004 hand_l.deviate/magnet_cartridge
A05-12 N004 forearm_l.twist/magnet_cartridge
A05-13 X022 forearm_l.twist/sensor_cassette
A05-14 P049 upperarm_l/C01
A05-15 X024 hand_l.deviate/sensor_cassette
A05-16 X057 upperarm_l/D_case_plus
A05-17 N004 hand_l.flex/magnet_cartridge
A05-18 X021 elbow_l.flex/sensor_cassette
A05-19 N004 clavicle_l.protract/magnet_cartridge
A05-20 N004 elbow_l.flex/magnet_cartridge
A05-21 X023 hand_l.flex/sensor_cassette
A05-22 X019 clavicle_l.protract/sensor_cassette
A05-23 P067 upperarm_l/D_magnet_cap
A05-24 P062 upperarm_l/P_magnet_cap
A05-25 N003 upperarm_l/C01_magnet_cartridge
A05-26 N003 upperarm_l/C02_magnet_cartridge

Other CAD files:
Hardware/PoseDoll44/bench/revO12/print_beds/printed_lever_on_bed.stl
Hardware/PoseDoll44/bench/revO22/a1mini_supports/projects/S00_support_trial_PLA_supports.3mf
Hardware/PoseDoll44/bench/revO22/mechanical/section/R2.stl
Hardware/PoseDoll44/bench/revO22/mechanical/stl/frame__head.stl
Hardware/PoseDoll44/bench/revO10/PA12_lever.step
Hardware/PoseDoll44/bench/revO10/PA12_lever.stl
Hardware/PoseDoll44/bench/revO10/aluminium_base.stl
Hardware/PoseDoll44/bench/revO11/print_beds/C01_on_bed.stl
Hardware/PoseDoll44/bench/revO11/print_beds/C02_on_bed.stl
Hardware/PoseDoll44/bench/revO11/print_beds/C14_on_bed.stl
Hardware/PoseDoll44/bench/revO11/print_beds/C15_on_bed.stl
Hardware/PoseDoll44/bench/revO11/print_beds/bench.3mf
Hardware/PoseDoll44/bench/revO11/print_beds/printed_base_minus_on_bed.stl
Hardware/PoseDoll44/bench/revO11/print_beds/printed_base_plus_on_bed.stl
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

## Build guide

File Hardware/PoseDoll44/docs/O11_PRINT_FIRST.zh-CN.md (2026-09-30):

# O11：按 ToddlerBot 的思路转向家用打印主体

运行目录：`generated/revO11/runs/o11_20260926_r1`。2026-09-26。

本轮将“家用 FDM 打印主体 + 目录标准金属小件”作为实际设计约束，已经改动 CAD、装配结构、试验夹具和前端指南。O10 的已封存结果保持不变。取消1.2 kg硬门槛和静态姿势采集的产品方向均保持。

## 从案例中确认了什么

[ToddlerBot论文](https://arxiv.org/html/2502.00893v3)采用打印结构与成品轴承、紧固件等配合；附录的髋部受力设计也使用金属轴和轴承。可借鉴的是打印承力结构、标准件接口与可接近的装配方式。其电机驱动不能直接证明我们无动力摩擦关节的保持力。

用户提供的3MF已按ZIP/XML/JSON只读检查，没有运行其中的打印指令。133个对象中，101个指定PLA-CF，18个PLA Matte，12个PLA Basic，2个TPU。全局设置为X1 Carbon、0.4 mm喷嘴、0.2 mm层高、6道外壁、25%网格填充；部分对象有独立覆盖，所以不是所有零件都用这组设置。

3MF SHA-256：`ffcf33e73cc1a192c13567a6b8416fa39488058a15225f19c22646349ab6ae26`。

[作者公开BOM](https://hshi74.github.io/toddlerbot/hardware/01_bill_of_materials.html)的Release和Screws页已只读提取，确有683、684、AXK0414轴承、轴套和多种小螺钉。数据存于 `research/revO11/toddlerbot_bom_readonly.json`；本地打印设置摘要存于同目录 `toddlerbot_3mf_audit.json`，没有复制作者的个人本地路径。

## 实际改动

| 对象 | O10基准 | O11候选 |
|---|---|---|
| 独立测试底座 | 定制铝底座 | 两半打印底座，内部放标准M3螺母和大垫圈 |
| 关节承力环 | 拟机加工铝件与内螺纹 | 打印分体环，螺母/垫圈从分合面装入，螺纹由金属螺母提供 |
| 四根关节轴 | 定制Φ4轴肩、特定肩长 | 目录成品NBK SBSM-M3-4-8，明确采用实际肩长和7 mm螺纹段 |
| 摩擦接触钢片 | 12×4.24×0.5 mm特殊环片 | 标准M4大垫圈12×4.3×1 mm |
| 前承压垫圈 | 0.3 mm薄片 | 标准M4平垫圈9×4.3×0.8 mm |
| 内部螺母反力面 | 铝环螺纹承力 | 标准M3大垫圈9×3.2×0.8 mm，压向打印承压台阶 |
| 外侧转动座 | 长后轴颈和0.2 mm独立承压薄垫 | 缩短后轴颈，以打印壳体的一体承压面定位转子；仍是待验证结构 |
| 材料小样 | PA12/铝/特殊钢片组合 | 首轮用PLA-CF打印底座和长臂，搭配同一标准件堆叠 |

**本轮独立小样和双轴核心均不需要定制金属件。** 这不是整机BOM已经全部定型：完整连接架、外侧转动座的保持方式、传感器和线束仍有待设计或验证。

轴肩螺钉通过NBK在华目录选择；它不是国产品牌。垫圈和通用紧固件可走嘉立创FA等中国供应渠道，碟簧沿用瑞力目录。此处确认了目录尺寸，没有采购、确认交期或比较全部市场价格。

## 解决尺寸变化，而不是缩小要求

标准垫圈更厚，目录螺钉也与旧定制轴不同。第一版直接代换出现螺纹端碰内部支架、头部挡住叉架、深度屈肘干涉等问题，已据真实求交结果修改：

- 近端叉架保留1.5 mm延长量，远端采用7 mm延长量，分别定尺寸。
- 摩擦面位于轴向13.5 mm，叉架摩擦段为14.5～17.5 mm，螺钉头起点20.2 mm。
- 内部M3螺母占6.5～8.9 mm，反力大垫圈占8.9～9.7 mm；标准螺纹覆盖完整名义螺母厚度。
- 转动座后端从局部z=-35.5改到-32.5 mm，后连接螺钉相应前移。后轴颈支承长度缩短，刚度与磨损仍需实测，不能只根据几何通过推断强度。
- 双轴核心跨螺钉头宽度从38.4变为46.4 mm。完整转动模块的主轴包络从约74.0变为73.5 mm，尺寸增长主要落在横向。
- 胸肩布局比较16个候选后，选用锁骨模块中心x=-60 mm、左右y=±38 mm、z相对原基准+10 mm。原候选左右中心为±20 mm。本研究保持中立手端锚点，没有删除原姿态；完整实体连接架尚未建立。

这些都是数字候选尺寸，尚未根据用户打印机误差、层间强度、变形或磨损验收。

## 检查结果和范围

| 检查 | 结果 | 不能由此推断 |
|---|---|---|
| 打印核心四个主体 | 均为单一、有效实体；完整名义装配无正体积穿插 | 打印强度和长期保持力 |
| 完整关节目标端点 | 204/204未发现所检刚体穿插，含原映射中的重复关节状态 | 所有中间运动、实物公差及线束均通过 |
| 两叉架连续间隙 | α±28°、β±98°；80个区间单元覆盖整个区域，名义下界≥0.6 mm | 环、螺钉、外壳、材料变形的连续整机验收 |
| 螺母/垫圈装入路径 | 0.5 mm步长抽样，无名义穿插；底座同样检查 | 未采样路径、公差与手指操作空间 |
| 螺母反力 | 向外移动时被垫圈/打印台阶阻挡，有真实几何约束 | 螺纹剥牙、塑料压溃和防松已合格 |
| 四侧2 mm直工具杆 | 核心维修姿态下无穿插 | 完整扳手手柄与整机维护空间 |
| 螺钉肩长/弹簧高度组合 | 肩长8、8.25 mm × 弹簧总高0.8、0.9、1.1 mm；每组合15个角度样本，无所检轴/叉架/环干涉 | 打印尺寸离散和真实弹簧力已经覆盖 |
| 独立测试夹具 | 15件名义装配无穿插；3件塑料打印，其余标准金属小件 | 夹具受载不变形 |
| 胸肩所检模块 | **101/102目标端点无所检穿插** | 整机或整臂放行 |

仍失败的是 **Quinn 双肩前收20°**，存在4对接头部件干涉。完整连接架、胸颈外壳、电路、线束和磁场尚未纳入；同一刚体候选的共享连接也没有因此被认证。不能把101/102改写成整机通过，不能削减该动作来把报告变绿。

旧版两个人体模型都失败的双肩前收案例，本轮Manny在选定布局下不再发现该穿插；Quinn仍保留。尺寸修改引入的深度屈肘干涉已在所检端点中消除。

## 质量与载荷

新模块按完整实体体积预算约 **50.68 g/个**，旧版相应预算约44.55 g；标准厚垫圈和紧固结构带来约6.1 g增加。打印体按PLA-CF密度1.22 g/cm³估算，未用低填充率减少载荷。整机重量未据此定型，也未恢复1.2 kg上限。

`loads.json`按新零件重心和当前布局更新了肩部无支撑手臂载荷，保留144 g的下游缺失件预算。所算最大弯折轴保持需求约0.3922 N·m；独立小样使用其一半约0.1961 N·m作为初始筛选目标。真实双点分担不能假定完全均匀。

以目录210 N为参考，叉架接触环平均压力约2.13 MPa，内部反力台阶平均压力约3.85 MPa。这些不是峰值应力，不能与材料拉伸强度简单相比来判断合格。SUS304标准垫圈与PLA-CF的摩擦、打印件受压松弛、孔磨损和螺钉防松均需要测量。

## 交付与下一步

入口：`tutorials/print-first/index.html`。完整操作说明：`bench/revO11/README.zh-CN.md`。小样3MF及逐件STL在 `bench/revO11/print_beds/`。文件仅包含塑料打印件；机器配置、支撑和逐层切片需要按实际设备复核。本轮没有实际切片、打印或硬件测试。

独立小样的目的，是让后续尺寸/材料选择有真实依据；它与仍待解决的Quinn胸肩干涉分别管理。不能用小样成功替代余下的数字结构工作，更不能据此制作整个人偶。

首批研究PLA-CF；若实际保持力、手感或受压稳定性不满足，再在同样几何、标准件和测量方法下比较PET-CF/尼龙体系或调整截面。无需为了预先假定的“必须金属”去订制铝环和薄钢片。

## 复算与证据

使用仓库 `.venv/Scripts/python.exe -X utf8` 运行 `cad/revO11/` 中的生成器与检查器。连续距离计算需通过已有 `tools/run_cad.py` 调用CAD环境。顺序见该目录README。

最终证据清单保存所有本轮文件哈希并检查报告依赖。O10的230个已封存文件及O7/O8/O9证据复核未变化。该封存是数据完整性检查，不是制造放行。

尺寸来源：[NBK轴肩螺钉目录](https://static.nbk1560-chn.com.cn/images/zh-CN/product/adjustbolt/SBSM/SBSM_1.pdf)、[嘉立创FA垫圈目录](https://static.jlcfa.com/Serial/E06/EPDA/542502462063341570.pdf)、[瑞力碟簧目录](https://www.raleigh-spring.cn/discspring/list_84_2/)。材料候选与喷嘴要求：[Bambu PLA-CF](https://us.store.bambulab.com/products/pla-cf)。

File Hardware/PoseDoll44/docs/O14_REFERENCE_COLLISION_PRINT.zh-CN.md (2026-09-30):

# O14：肩宽、碰撞判定与双轴核心打印修正

本轮响应用户 2026-09-29 的三项反馈：允许有限人体比例偏差；相邻关节干涉必须修改设计，非相邻自接触允许调整姿势避开；原核心说明乱码且两个叉架摆放缺少有效贴床/支撑检查。

## 设计变化与 UE 参考差异

取消 O13 的左右各 8 mm 肩部额外外移，重新生成四种 Manny/Quinn、左/右锁骨到肩部的一体连接架。四者都为一个连续实体。保留原 102 个端点与原角度目标，没有缩小目标来隐藏冲突。

| 480 mm 缩放参考 | 参考肩宽 | O13 肩宽 | O14 肩宽 | 本次姿势最大手端位置差 |
|---|---:|---:|---:|---:|
| Manny | 100.50 mm | 116.50 mm | 100.50 mm | 24.39 mm |
| Quinn | 84.90 mm | 100.90 mm | 84.90 mm | 25.25 mm |

原 +8 mm 外移解决的是左右肩模块自接触。按新规则可归为非相邻身体部位的姿势约束，因此不再为它扩大肩宽。

中立位肩、肘、腕屈伸轴心恢复到参考位置；上臂、前臂、腕到手端参考段长不变。这不意味着全人体所有骨长和轴心已经一致：锁骨中心向后约 48–49 mm、向外约 34–36 mm、向上 10 mm，三维偏离约 61 mm；腕侧偏轴与屈伸轴错开 8 mm。锁骨中心的偏差并不能自动视为用户已经接受的小偏差，仍是后续优化项。

手端比较使用相同语义角度，针对现有 102 个端点，最大值出现在双肩上提 40°。不是任意姿势的最大误差证明，不是编码器精度，也不是已验证的 UE 重定向效果。UE 设备校准未修改；用户尚未批准数值偏差上限。

## 碰撞分类与范围

同一关节内部、锁骨—肩—肘—前臂—腕屈伸—腕侧偏相邻机械区之间的穿插为结构缺陷。非相邻部位接触保留为姿势限制。未知零件分组会抛错；分类器的五项检查通过。

恢复肩宽后的 102 个端点：结构干涉端点 0；非相邻接触端点 12。保留所有原始配对和相交体积，在查看器显示为橙色，不写成这些姿势已经无碰撞。检查涵盖当前不同刚体组的模型、传感器占位和新连接架，并补查连接架对同刚体内肩壳硬件的穿插；不等于所有同刚体连接已验收。

本轮未复用旧版 3894 个路径样本作为恢复肩宽后的通过证据。新连接架中间运动、装拆路径、公差、强度、电路/线束及颈躯干下肢实体仍未完成。这些端点证据不能作为完整人偶制造放行。

## 打印修正与实际切片

C01/C02 旧方向虽最低点到达 Z=0，但平面接触面积为 0。用户指出的问题成立。现在换为耳部平面贴床，接触面积各约 98.88 mm²；C14/C15 分割面贴床，各约 312.73 mm²。全部四件机械体积与旧件一致，只改打印摆放，不以改姿势掩盖设计变更。

两个叉架的实体重心投影超出单独耳面接触范围，必须在偏置柄和悬空面下设置支撑，Brim 附着边不能代替支撑。

使用官方便携 PrusaSlicer 2.9.6 对四个 STL 实际生成了诊断路径。0.4 mm 喷嘴、0.2 mm 层高、6 圈墙、5 层顶底、100% 填充、5 mm Brim、自动普通支撑。全部四件切片退出码 0；叉架确有从首层起的支撑挤出路径。零件重心和按挤出量累积的过程质心均落在包含支撑的首层接触凸包内。

这些是切片和几何承托范围检查，不是逐层支撑连接的证明，也未证明附着力、冷却变形、拆支撑可达性或机械强度。诊断配置不是 A1/P1S 的实际机器/材料配置，温度和起止代码也未做设备适配。诊断 G-code 留在本地报告目录，不放入采购包，不直接上机。

供应商包含单文件中文 HTML 和几何文件；必须使用真实设备与耗材配置重新切片，检查孔槽中的支撑能够清理。M1.6 合拢螺钉/螺母尺寸尚需核对。先前成功的长臂小样继续使用，下一阶段新增双轴核心用于观察卡滞、预紧耦合、松动和漂移。

## 页面与验证

新增 `tutorials/full-doll-o14/` 和 `tutorials/core-print/`，由 `scripts/serve_posedoll_tutorials.py` 提供 UTF-8 Content-Type。旧查看器入口和旧“核心试装说明”自动转向新版；旧核心打印盘入口转向新说明，避免继续按旧摆放下单。历史 O13 文件字节不变。

浏览器验证：两角色共 114 个场景（其中 12 个仅全身参考）均加载并绘制；没有缺失模型、WebGL 错误或脚本错误。橙色接触提示、双轴滑块、四幅支撑图、8 行金属件清单、手机宽度、7 个本地链接和 UTF-8 响应均通过。截图和脚本保存在 `bench/revO14/verification/`。O13 112 文件及上游 O12 校验保持通过。

主要机器可读结果位于 `generated/revO14/runs/o14_20260929_r1/`：`reference_deviations.json`、`collision_classification.json`、`shoulder_width_trials.json`、`bed_geometry.json`、`slicing/report.json`、`page_checks.json`。后缀 `_o13` 为旧布局比较，不能与 O14 结果混用。`bed_geometry.json` 仅记录几何摆放阶段；已执行切片证据在后续 `slicing/report.json`。

本轮没有新的硬件测试；弹簧力与保持力仍未量化，没有整机制造放行。

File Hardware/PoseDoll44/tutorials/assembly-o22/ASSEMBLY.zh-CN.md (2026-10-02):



# O22 人偶拼装教程

对应 A1 mini 打印盘 A01–A10。按 **盘号 → 零件号 → 关节 → 电路端口** 查找，覆盖 25 个关节与中央板安装。左右一律按人偶自身区分。

本教程使用已保存的 O22 设计和 A1 mini 排盘，不改变结构。186 件 = 185 件装机件 + 1 件焊接量规；另有可选 T01 两件传感器小样。O11 的配合和摩擦已由你实测通过；O22 新传感板、线束及整机测量仍需首件实测，以下 CAD 图不是已完成实物装配的照片。

## 00 · 开始前先分袋、准备五金与电路

1. 每盘冷却取件后，按排盘编号图把零件装袋，标签写完整的“盘 A05-19 / N004 / 左锁骨前后”。N003、N004、P013 等打印编号可重复，盘内序号才唯一；它们不是传感器的电路端口。
2. 清除支撑和毛刺，尤其是垫片座、螺母窝、PCB 导轨、磁铁侧槽与摩擦轴面；使用你已验证的 O11 工艺，不扩大精配合孔来迁就错规格五金。
3. 工具：与螺钉头匹配的内六角批头（轴肩螺钉为 3 mm）、游标卡尺、镊子、小尖嘴钳、剪钳、万用表、标签笔、软垫。胶分别用于磁铁防转和电子线束柔性固线，按材料说明完全固化。
4. 先把电子加工包交给供应方：48 块已焊线的传感板（46 使用 + 2 完整备件）、1 块中央成品板、1 块 XIAO、压接并逐路标号的线束。由供应方完成贴片、板端焊接、端子压接及导通检测；你负责装配和插接。
5. 机械部分按 S01–S25 顺序装，传感板可以在每个关节完成后装入，但先不接电。推荐左臂做首个完整线束样段，通过后再按同样方法做右侧；不要封背盒后才开始排线。
6. 在软垫上托住骨架操作，不让未装完的关节承受整机重量。先调整摩擦，再覆盖轴肩的磁铁座盖；先放内部螺母和反力垫，再关闭环或端轴外壳。

## 01 · 从打印盘找到装配步骤

“首次领用”统计每件只取一次；在后续关节步骤出现的长骨是已经装上的连接件。可点击盘图放大编号，也可以直接打开对应步骤。

### 打印盘 A01 · 头颈与背盒盖

打印盘 A01 的 20 件；编号对应下方清单

涉及步骤：[S03](#S03)、[S26](#S26)

| 盘内编号 / 打印号 | 零件 | 首次领用 / 后续连接 |
| --- | --- | --- |
| A01-01 / X081 | o22/背盒盖 | [S26](#S26) |
| A01-02 / X050 | 骨架／头颈 | [S03](#S03) |
| A01-03 / P035 | 头颈/下环 | [S03](#S03) |
| A01-04 / P033 | 头颈/下叉 | [S03](#S03) |
| A01-05 / P034 | 头颈/上叉 | [S03](#S03) |
| A01-06 / X045 | 头颈/P_活动半壳 | [S03](#S03) |
| A01-07 / X049 | 头颈/D_活动半壳 | [S03](#S03) |
| A01-08 / P036 | 头颈/上环盖 | [S03](#S03) |
| A01-09 / X005 | 头颈/下叉_传感板托夹 | [S03](#S03) |
| A01-10 / X006 | 头颈/上叉_传感板托夹 | [S03](#S03) |
| A01-11 / P040 | 头颈/P_磁铁端盖 | [S03](#S03) |
| A01-12 / P045 | 头颈/D_磁铁端盖 | [S03](#S03) |
| A01-13 / N003 | 头颈/下叉_侧装磁铁座盖 | [S03](#S03) |
| A01-14 / N003 | 头颈/上叉_侧装磁铁座盖 | [S03](#S03) |
| A01-15 / X043 | 头颈/P_板夹_-14 | [S03](#S03) |
| A01-16 / X044 | 头颈/P_板夹_+14 | [S03](#S03) |
| A01-17 / X047 | 头颈/D_板夹_-14 | [S03](#S03) |
| A01-18 / X048 | 头颈/D_板夹_+14 | [S03](#S03) |
| A01-19 / P039 | 头颈/P_径向摩擦块 | [S03](#S03) |
| A01-20 / P044 | 头颈/D_径向摩擦块 | [S03](#S03) |

### 打印盘 A02 · 躯干 1/2

打印盘 A02 的 13 件；编号对应下方清单

涉及步骤：[S01](#S01)、[S02](#S02)、[S03](#S03)、[S04](#S04)、[S11](#S11)、[S26](#S26)

| 盘内编号 / 打印号 | 零件 | 首次领用 / 后续连接 |
| --- | --- | --- |
| A02-01 / X046 | 骨架／胸部 | [S02](#S02)；还用于 S03、S04、S11、S26 |
| A02-02 / X042 | 骨架／腰部 | [S01](#S01)；还用于 S02 |
| A02-03 / P002 | 腰部/下环 | [S01](#S01) |
| A02-04 / P018 | 胸部/下环 | [S02](#S02) |
| A02-05 / P001 | 腰部/下叉 | [S01](#S01) |
| A02-06 / P017 | 胸部/下叉 | [S02](#S02) |
| A02-07 / X041 | 胸部/P_活动半壳 | [S02](#S02) |
| A02-08 / X040 | 胸部/P_板夹_+14 | [S02](#S02) |
| A02-09 / X039 | 胸部/P_板夹_-14 | [S02](#S02) |
| A02-10 / X036 | 腰部/P_板夹_+14 | [S01](#S01) |
| A02-11 / X035 | 腰部/P_板夹_-14 | [S01](#S01) |
| A02-12 / P012 | 腰部/P_径向摩擦块 | [S01](#S01) |
| A02-13 / P028 | 胸部/P_径向摩擦块 | [S02](#S02) |

### 打印盘 A03 · 躯干 2/2

打印盘 A03 的 15 件；编号对应下方清单

涉及步骤：[S01](#S01)、[S02](#S02)、[S18](#S18)、[S22](#S22)、[S26](#S26)

| 盘内编号 / 打印号 | 零件 | 首次领用 / 后续连接 |
| --- | --- | --- |
| A03-01 / X038 | 骨架／骨盆 | [S01](#S01)；还用于 S18、S22 |
| A03-02 / X037 | 腰部/P_活动半壳 | [S01](#S01) |
| A03-03 / P003 | 腰部/上环盖 | [S01](#S01) |
| A03-04 / P019 | 胸部/上环盖 | [S02](#S02) |
| A03-05 / X004 | 胸部/上叉_传感板托夹 | [S02](#S02) |
| A03-06 / X001 | 腰部/下叉_传感板托夹 | [S01](#S01) |
| A03-07 / X003 | 胸部/下叉_传感板托夹 | [S02](#S02) |
| A03-08 / X002 | 腰部/上叉_传感板托夹 | [S01](#S01) |
| A03-09 / P242 | 工具／XIAO 焊接间距量规 | [S26](#S26) |
| A03-10 / P013 | 腰部/P_磁铁端盖 | [S01](#S01) |
| A03-11 / P029 | 胸部/P_磁铁端盖 | [S02](#S02) |
| A03-12 / N003 | 腰部/下叉_侧装磁铁座盖 | [S01](#S01) |
| A03-13 / N003 | 腰部/上叉_侧装磁铁座盖 | [S01](#S01) |
| A03-14 / N003 | 胸部/下叉_侧装磁铁座盖 | [S02](#S02) |
| A03-15 / N003 | 胸部/上叉_侧装磁铁座盖 | [S02](#S02) |

### 打印盘 A04 · 左臂 1/2

打印盘 A04 的 11 件；编号对应下方清单

涉及步骤：[S04](#S04)、[S05](#S05)、[S06](#S06)、[S07](#S07)、[S08](#S08)

| 盘内编号 / 打印号 | 零件 | 首次领用 / 后续连接 |
| --- | --- | --- |
| A04-01 / X054 | 骨架／左锁骨 | [S05](#S05)；还用于 S06 |
| A04-02 / W005 | 骨架／左锁骨前后中间架 | [S04](#S04)；还用于 S05 |
| A04-03 / H004 | 骨架／左肘 | [S07](#S07)；还用于 S08 |
| A04-04 / P051 | 左肩／上臂/下环 | [S06](#S06) |
| A04-05 / X058 | 骨架／左肩／上臂 | [S06](#S06)；还用于 S07 |
| A04-06 / X051 | 左肩／上臂/P_板夹_-14 | [S06](#S06) |
| A04-07 / X056 | 左肩／上臂/D_板夹_+14 | [S06](#S06) |
| A04-08 / X055 | 左肩／上臂/D_板夹_-14 | [S06](#S06) |
| A04-09 / X052 | 左肩／上臂/P_板夹_+14 | [S06](#S06) |
| A04-10 / P061 | 左肩／上臂/P_径向摩擦块 | [S06](#S06) |
| A04-11 / P066 | 左肩／上臂/D_径向摩擦块 | [S06](#S06) |

### 打印盘 A05 · 左臂 2/2

打印盘 A05 的 26 件；编号对应下方清单

涉及步骤：[S04](#S04)、[S05](#S05)、[S06](#S06)、[S07](#S07)、[S08](#S08)、[S09](#S09)、[S10](#S10)

| 盘内编号 / 打印号 | 零件 | 首次领用 / 后续连接 |
| --- | --- | --- |
| A05-01 / H006 | 骨架／左腕屈伸中间架 | [S09](#S09)；还用于 S10 |
| A05-02 / P050 | 左肩／上臂/上叉 | [S06](#S06) |
| A05-03 / W004 | 骨架／左前臂 | [S08](#S08)；还用于 S09 |
| A05-04 / P191 | 骨架／左手腕 | [S10](#S10) |
| A05-05 / N004 | 左锁骨升降/侧装磁铁座盖 | [S05](#S05) |
| A05-06 / X008 | 左肩／上臂/上叉_传感板托夹 | [S06](#S06) |
| A05-07 / X007 | 左肩／上臂/下叉_传感板托夹 | [S06](#S06) |
| A05-08 / P052 | 左肩／上臂/上环盖 | [S06](#S06) |
| A05-09 / X053 | 左肩／上臂/P_活动半壳 | [S06](#S06) |
| A05-10 / X020 | 左锁骨升降/传感板托夹 | [S05](#S05) |
| A05-11 / N004 | 左手腕侧摆/侧装磁铁座盖 | [S10](#S10) |
| A05-12 / N004 | 左前臂扭转/侧装磁铁座盖 | [S08](#S08) |
| A05-13 / X022 | 左前臂扭转/传感板托夹 | [S08](#S08) |
| A05-14 / P049 | 左肩／上臂/下叉 | [S06](#S06) |
| A05-15 / X024 | 左手腕侧摆/传感板托夹 | [S10](#S10) |
| A05-16 / X057 | 左肩／上臂/D_活动半壳 | [S06](#S06) |
| A05-17 / N004 | 左手腕屈伸/侧装磁铁座盖 | [S09](#S09) |
| A05-18 / X021 | 左肘屈伸/传感板托夹 | [S07](#S07) |
| A05-19 / N004 | 左锁骨前后/侧装磁铁座盖 | [S04](#S04) |
| A05-20 / N004 | 左肘屈伸/侧装磁铁座盖 | [S07](#S07) |
| A05-21 / X023 | 左手腕屈伸/传感板托夹 | [S09](#S09) |
| A05-22 / X019 | 左锁骨前后/传感板托夹 | [S04](#S04) |
| A05-23 / P067 | 左肩／上臂/D_磁铁端盖 | [S06](#S06) |
| A05-24 / P062 | 左肩／上臂/P_磁铁端盖 | [S06](#S06) |
| A05-25 / N003 | 左肩／上臂/下叉_侧装磁铁座盖 | [S06](#S06) |
| A05-26 / N003 | 左肩／上臂/上叉_侧装磁铁座盖 | [S06](#S06) |

### 打印盘 A06 · 右臂 1/2

打印盘 A06 的 14 件；编号对应下方清单

涉及步骤：[S11](#S11)、[S12](#S12)、[S13](#S13)、[S14](#S14)、[S15](#S15)、[S16](#S16)、[S17](#S17)

| 盘内编号 / 打印号 | 零件 | 首次领用 / 后续连接 |
| --- | --- | --- |
| A06-01 / H008 | 骨架／右锁骨前后中间架 | [S11](#S11)；还用于 S12 |
| A06-02 / W002 | 骨架／右前臂 | [S15](#S15)；还用于 S16 |
| A06-03 / H010 | 骨架／右肘 | [S14](#S14)；还用于 S15 |
| A06-04 / X062 | 骨架／右锁骨 | [S12](#S12)；还用于 S13 |
| A06-05 / X066 | 骨架／右肩／上臂 | [S13](#S13)；还用于 S14 |
| A06-06 / P071 | 右肩／上臂/下叉 | [S13](#S13) |
| A06-07 / X061 | 右肩／上臂/P_活动半壳 | [S13](#S13) |
| A06-08 / X065 | 右肩／上臂/D_活动半壳 | [S13](#S13) |
| A06-09 / P073 | 右肩／上臂/下环 | [S13](#S13) |
| A06-10 / X032 | 右手腕侧摆/传感板托夹 | [S17](#S17) |
| A06-11 / X030 | 右前臂扭转/传感板托夹 | [S15](#S15) |
| A06-12 / X028 | 右锁骨升降/传感板托夹 | [S12](#S12) |
| A06-13 / X009 | 右肩／上臂/下叉_传感板托夹 | [S13](#S13) |
| A06-14 / X031 | 右手腕屈伸/传感板托夹 | [S16](#S16) |

### 打印盘 A07 · 右臂 2/2

打印盘 A07 的 23 件；编号对应下方清单

涉及步骤：[S11](#S11)、[S12](#S12)、[S13](#S13)、[S14](#S14)、[S15](#S15)、[S16](#S16)、[S17](#S17)

| 盘内编号 / 打印号 | 零件 | 首次领用 / 后续连接 |
| --- | --- | --- |
| A07-01 / H012 | 骨架／右腕屈伸中间架 | [S16](#S16)；还用于 S17 |
| A07-02 / X027 | 右锁骨前后/传感板托夹 | [S11](#S11) |
| A07-03 / X029 | 右肘屈伸/传感板托夹 | [S14](#S14) |
| A07-04 / N004 | 右前臂扭转/侧装磁铁座盖 | [S15](#S15) |
| A07-05 / X010 | 右肩／上臂/上叉_传感板托夹 | [S13](#S13) |
| A07-06 / N004 | 右肘屈伸/侧装磁铁座盖 | [S14](#S14) |
| A07-07 / P074 | 右肩／上臂/上环盖 | [S13](#S13) |
| A07-08 / N004 | 右锁骨前后/侧装磁铁座盖 | [S11](#S11) |
| A07-09 / P072 | 右肩／上臂/上叉 | [S13](#S13) |
| A07-10 / N004 | 右手腕屈伸/侧装磁铁座盖 | [S16](#S16) |
| A07-11 / N004 | 右锁骨升降/侧装磁铁座盖 | [S12](#S12) |
| A07-12 / N004 | 右手腕侧摆/侧装磁铁座盖 | [S17](#S17) |
| A07-13 / P084 | 右肩／上臂/P_磁铁端盖 | [S13](#S13) |
| A07-14 / P185 | 骨架／右手腕 | [S17](#S17) |
| A07-15 / P089 | 右肩／上臂/D_磁铁端盖 | [S13](#S13) |
| A07-16 / N003 | 右肩／上臂/下叉_侧装磁铁座盖 | [S13](#S13) |
| A07-17 / N003 | 右肩／上臂/上叉_侧装磁铁座盖 | [S13](#S13) |
| A07-18 / X063 | 右肩／上臂/D_板夹_-14 | [S13](#S13) |
| A07-19 / X059 | 右肩／上臂/P_板夹_-14 | [S13](#S13) |
| A07-20 / X064 | 右肩／上臂/D_板夹_+14 | [S13](#S13) |
| A07-21 / X060 | 右肩／上臂/P_板夹_+14 | [S13](#S13) |
| A07-22 / P083 | 右肩／上臂/P_径向摩擦块 | [S13](#S13) |
| A07-23 / P088 | 右肩／上臂/D_径向摩擦块 | [S13](#S13) |

### 打印盘 A08 · 左大腿与左腿关节小件

打印盘 A08 的 27 件；编号对应下方清单

涉及步骤：[S18](#S18)、[S19](#S19)、[S20](#S20)、[S21](#S21)

| 盘内编号 / 打印号 | 零件 | 首次领用 / 后续连接 |
| --- | --- | --- |
| A08-01 / X073 | 骨架／左髋／大腿 | [S18](#S18)；还用于 S19 |
| A08-02 / P095 | 左髋／大腿/下环 | [S18](#S18) |
| A08-03 / P093 | 左髋／大腿/下叉 | [S18](#S18) |
| A08-04 / P094 | 左髋／大腿/上叉 | [S18](#S18) |
| A08-05 / X069 | 左髋／大腿/P_活动半壳 | [S18](#S18) |
| A08-06 / X072 | 左髋／大腿/D_活动半壳 | [S18](#S18) |
| A08-07 / P096 | 左髋／大腿/上环盖 | [S18](#S18) |
| A08-08 / X012 | 左髋／大腿/上叉_传感板托夹 | [S18](#S18) |
| A08-09 / X016 | 左踝／脚掌/上叉_传感板托夹 | [S20](#S20) |
| A08-10 / X025 | 左膝／小腿屈伸/传感板托夹 | [S19](#S19) |
| A08-11 / X015 | 左踝／脚掌/下叉_传感板托夹 | [S20](#S20) |
| A08-12 / X011 | 左髋／大腿/下叉_传感板托夹 | [S18](#S18) |
| A08-13 / X026 | 左脚趾屈伸/传感板托夹 | [S21](#S21) |
| A08-14 / N004 | 左膝／小腿屈伸/侧装磁铁座盖 | [S19](#S19) |
| A08-15 / N004 | 左脚趾屈伸/侧装磁铁座盖 | [S21](#S21) |
| A08-16 / P106 | 左髋／大腿/P_磁铁端盖 | [S18](#S18) |
| A08-17 / P111 | 左髋／大腿/D_磁铁端盖 | [S18](#S18) |
| A08-18 / N003 | 左髋／大腿/下叉_侧装磁铁座盖 | [S18](#S18) |
| A08-19 / N003 | 左髋／大腿/上叉_侧装磁铁座盖 | [S18](#S18) |
| A08-20 / N003 | 左踝／脚掌/下叉_侧装磁铁座盖 | [S20](#S20) |
| A08-21 / N003 | 左踝／脚掌/上叉_侧装磁铁座盖 | [S20](#S20) |
| A08-22 / X068 | 左髋／大腿/P_板夹_+14 | [S18](#S18) |
| A08-23 / X067 | 左髋／大腿/P_板夹_-14 | [S18](#S18) |
| A08-24 / X071 | 左髋／大腿/D_板夹_+14 | [S18](#S18) |
| A08-25 / X070 | 左髋／大腿/D_板夹_-14 | [S18](#S18) |
| A08-26 / P105 | 左髋／大腿/P_径向摩擦块 | [S18](#S18) |
| A08-27 / P110 | 左髋／大腿/D_径向摩擦块 | [S18](#S18) |

### 打印盘 A09 · 右大腿与右腿关节小件

打印盘 A09 的 27 件；编号对应下方清单

涉及步骤：[S22](#S22)、[S23](#S23)、[S24](#S24)、[S25](#S25)

| 盘内编号 / 打印号 | 零件 | 首次领用 / 后续连接 |
| --- | --- | --- |
| A09-01 / X080 | 骨架／右髋／大腿 | [S22](#S22)；还用于 S23 |
| A09-02 / P117 | 右髋／大腿/下环 | [S22](#S22) |
| A09-03 / P115 | 右髋／大腿/下叉 | [S22](#S22) |
| A09-04 / P116 | 右髋／大腿/上叉 | [S22](#S22) |
| A09-05 / X076 | 右髋／大腿/P_活动半壳 | [S22](#S22) |
| A09-06 / X079 | 右髋／大腿/D_活动半壳 | [S22](#S22) |
| A09-07 / P118 | 右髋／大腿/上环盖 | [S22](#S22) |
| A09-08 / X013 | 右髋／大腿/下叉_传感板托夹 | [S22](#S22) |
| A09-09 / X014 | 右髋／大腿/上叉_传感板托夹 | [S22](#S22) |
| A09-10 / X017 | 右踝／脚掌/下叉_传感板托夹 | [S24](#S24) |
| A09-11 / X018 | 右踝／脚掌/上叉_传感板托夹 | [S24](#S24) |
| A09-12 / X033 | 右膝／小腿屈伸/传感板托夹 | [S23](#S23) |
| A09-13 / X034 | 右脚趾屈伸/传感板托夹 | [S25](#S25) |
| A09-14 / N004 | 右膝／小腿屈伸/侧装磁铁座盖 | [S23](#S23) |
| A09-15 / N004 | 右脚趾屈伸/侧装磁铁座盖 | [S25](#S25) |
| A09-16 / P013 | 右髋／大腿/P_磁铁端盖 | [S22](#S22) |
| A09-17 / P126 | 右髋／大腿/D_磁铁端盖 | [S22](#S22) |
| A09-18 / N003 | 右髋／大腿/下叉_侧装磁铁座盖 | [S22](#S22) |
| A09-19 / N003 | 右髋／大腿/上叉_侧装磁铁座盖 | [S22](#S22) |
| A09-20 / N003 | 右踝／脚掌/下叉_侧装磁铁座盖 | [S24](#S24) |
| A09-21 / N003 | 右踝／脚掌/上叉_侧装磁铁座盖 | [S24](#S24) |
| A09-22 / X074 | 右髋／大腿/P_板夹_-14 | [S22](#S22) |
| A09-23 / X075 | 右髋／大腿/P_板夹_+14 | [S22](#S22) |
| A09-24 / X077 | 右髋／大腿/D_板夹_-14 | [S22](#S22) |
| A09-25 / X078 | 右髋／大腿/D_板夹_+14 | [S22](#S22) |
| A09-26 / P012 | 右髋／大腿/P_径向摩擦块 | [S22](#S22) |
| A09-27 / P125 | 右髋／大腿/D_径向摩擦块 | [S22](#S22) |

### 打印盘 A10 · 双侧小腿与脚掌骨架

打印盘 A10 的 10 件；编号对应下方清单

涉及步骤：[S19](#S19)、[S20](#S20)、[S21](#S21)、[S23](#S23)、[S24](#S24)、[S25](#S25)

| 盘内编号 / 打印号 | 零件 | 首次领用 / 后续连接 |
| --- | --- | --- |
| A10-01 / W006 | 骨架／右膝／小腿 | [S23](#S23)；还用于 S24 |
| A10-02 / W007 | 骨架／左膝／小腿 | [S19](#S19)；还用于 S20 |
| A10-03 / P130 | 左踝／脚掌/下环 | [S20](#S20) |
| A10-04 / P130 | 右踝／脚掌/下环 | [S24](#S24) |
| A10-05 / W003 | 骨架／左脚趾 | [S21](#S21) |
| A10-06 / W001 | 骨架／右脚趾 | [S25](#S25) |
| A10-07 / W016 | 骨架／左踝／脚掌 | [S20](#S20)；还用于 S21 |
| A10-08 / W017 | 骨架／右踝／脚掌 | [S24](#S24)；还用于 S25 |
| A10-09 / P131 | 左踝／脚掌/上环盖 | [S20](#S20) |
| A10-10 / P131 | 右踝／脚掌/上环盖 | [S24](#S24) |

T01 为传感器安装小样：T001 传感桥 + T002 磁铁桥，单独在台面上核验板厚、封装间隙与磁场。**不装在人偶上、不计入 186 件。** [小样与首件要求](../../bench/revO22/physical_tests/ACCEPTANCE.zh-CN.md)。

## 02 · 全部金属件与磁铁清单

下面是整机净用量。备件是采购损耗备份，**不是增加到关节里的冗余零件**；每步的五金清单已分配全部 958 件标准件（912 件金属紧固／摩擦件 + 46 颗磁铁）。电子连接器和排针另列，不混进这个总数。

| 规格 / SKU | 净用 | 可选备件 | 含备件采购数 | 装在哪里 |
| --- | --- | --- | --- | --- |
| A8不锈钢碟簧：8×4.2×0.4，自由高0.6 mm | 104 | 11 | 115 | 52 个轴肩支点，每点 2 片，相对安装；`A8_SS` |
| 径向两极磁铁 Φ6×2.5 mm；直径方向充磁，不能买轴向充磁 | 46 | 5 | 51 | 34 个侧装磁铁座盖 + 12 个 P/D 端轴，各 1 颗；`MAGNET_D6_T2P5_DIAMETRIC` |
| M1.6普通六角螺母（不要锁紧螺母替代外形） | 36 | 4 | 40 | 9 个十字核心合环，每处 4 枚；`NUT_M1P6` |
| M2普通六角螺母（不要锁紧螺母替代外形） | 164 | 17 | 181 | 侧装磁铁 68；端轴合壳 48；端轴磁铁盖 24；端轴板夹 24；`NUT_M2` |
| M3普通六角螺母（不要锁紧螺母替代外形） | 98 | 10 | 108 | 轴肩支点 52；传感板托夹 34；端轴摩擦调节 12；`NUT_M3` |
| M1.6×6 内六角圆柱头螺钉；按CAD头径/头高核对 | 36 | 4 | 40 | C14 / C15 合环，每核心 4 枚；`SCREW_M1P6_L6` |
| M2×20 内六角圆柱头螺钉；按CAD头径/头高核对 | 48 | 5 | 53 | 12 个 P/D 端轴合壳，每端 4 枚；`SCREW_M2_L20` |
| M2×4 内六角圆柱头螺钉；按CAD头径/头高核对 | 24 | 3 | 27 | 12 个 P/D 磁铁端盖，每端 2 枚；`SCREW_M2_L4` |
| M2×5 内六角圆柱头螺钉；按CAD头径/头高核对 | 68 | 7 | 75 | 34 个侧装磁铁座盖，每个 2 枚；`SCREW_M2_L5` |
| M2×8 内六角圆柱头螺钉；按CAD头径/头高核对 | 24 | 3 | 27 | 12 个 P/D 端轴 PCB 板夹，每端 2 枚；`SCREW_M2_L8` |
| M3×8 内六角圆柱头螺钉；按CAD头径/头高核对 | 46 | 5 | 51 | 34 个传感板托夹 + 12 个端轴摩擦调节，各 1 枚；`SCREW_M3_L8` |
| 轴肩螺钉 Φ4×8 / M3×0.5，螺纹长6 mm；头Φ7×3，内六角3 mm | 52 | 6 | 58 | 52 个轴肩摩擦支点，各 1 枚；`SHOULDER_D4_L8_M3_L6` |
| M3大平垫圈：外径9、厚0.8 mm，实物通孔验证 | 52 | 6 | 58 | 52 个支点的固定座内侧反力垫，各 1 片；`W_M3_D9_T0P8` |
| M4大平垫圈：外径12、厚1 mm，实物能自由套过Φ4光杆 | 104 | 11 | 115 | 52 个支点的旋转叉耳两侧，各 2 片；`W_M4_D12_T1` |
| M4普通平垫圈：外径9、厚0.8 mm，实物通孔验证 | 52 | 6 | 58 | 52 个支点的螺钉头下，各 1 片；`W_M4_D9_T0P8` |
| 塑料自攻 M2×6，头径≤4mm；新中央板安装 | 4 | 2 | 6 | 中央板四角，直接拧入打印柱；不用金属螺母；`SELF_TAP_M2_L6` |

螺钉长度按头下长度识别，分开存放 M2×4 / ×5 / ×8 / ×20。CAD 中 M1.6 螺钉头为 Φ3×1.6、内六角 1.5 mm、螺距 0.35 mm；M1.6 螺母对边 3.2、厚 1.3 mm。M2 螺母对边 4、厚 1.6 mm；M3 螺母对边 5.5、厚 2.4 mm。普通 M2 圆柱头包络为 Φ3.8×2，M3 为 Φ5.6×3；用现有验证件核对头部与沉孔。M3、M2、M1.6 都用普通六角螺母，不用带尼龙圈的锁紧螺母替换。磁铁必须直径方向充磁，不能买上下两面 N/S 的轴向充磁磁铁。

## 03 · 四种通用装法

每个步骤会直接写需要哪一种装法，并给出真实的盘号和五金数量。这里的顺序适用于现有设计；不同轴的朝向以该步骤的 CAD 模型为准。

### G1 · 轴肩、垫片和碟簧

每处轴肩摩擦支点的层次顺序；不按比例

1. 先找到固定座的六角螺母窝和反力垫座。放入 1 枚 M3 普通螺母、1 片 M3 外径 9 × 厚 0.8 反力垫，让螺母与轴孔同心；反力垫贴固定座内侧。先确认螺钉能轻松对正，不歪牙。
2. 在固定座反力壁外放 1 片 M4 外径 12 × 厚 1 大垫，再放旋转叉耳，再放第 2 片同规格大垫；叉耳由两片大垫夹住。
3. 向外依次放相对安装的 2 片 A8 碟簧、1 片 M4 外径 9 × 厚 0.8 普通垫。两片碟簧不要同方向完全套叠；沿用已通过实物验证的 O11 叠法。
4. 从外侧穿入 Φ4×8 / M3 螺纹长 6 的轴肩螺钉。光杆穿过垫片和叉耳，M3 螺纹进入里面的螺母。边小幅摆动边拧紧到你需要的保持力，不能用普通 M3 全螺纹螺钉替代。
5. 确认动的是叉耳，固定座内螺母不跟转、垫片未夹歪。装好磁铁座盖后会遮住轴肩头，所以先把摩擦力调好，再装磁铁与传感板。

### G2 · 两轴十字核心

1. 找 C14 下环、C15 上环盖与互相正交的 C01 / C02 两叉；有些叉已经和长骨一起打印，具体见每步的“一体件说明”。在环尚未封闭时，把 4 组 M3 螺母和 M3 反力垫放到对应捕获窝。
2. 先将两叉交叉放进开口环中，逐一对正四个支点孔。按 G1 安装四套轴肩摩擦结构，先保持能够转动和微调的位置，不先将一侧完全拧死。
3. 放入 4 枚 M1.6 螺母，合上 C15。四个角的螺钉头方向交错：同一对角线同向，两条对角线反向；按圆形头窝和六角螺母窝分辨，不能把 4 枚都从同一面穿入。用 4 枚 M1.6×6 交替、分次收紧。确认环的接缝贴合、叉耳和垫片仍在正确层次；不要靠螺钉硬拉未对齐的打印件。
4. 分别转动 C01 和 C02，再均匀调整四个轴肩螺钉。核心是四个支点、两个测量轴；背面的两个支点也必须装。
5. 在两个指定测量端装磁铁座盖和传感板托夹：每端 1 颗磁铁、2 枚 M2×5 + 2 枚 M2 螺母固定磁铁座盖，1 枚 M3×8 + 1 枚 M3 螺母固定板托夹。最后按 G4 确认芯片对准磁铁。

### G3 · P / D 有限扭转端轴

1. P 表示靠近父骨架一端，D 表示靠近子骨架一端。固定半壳 case_minus 已并入骨架；另取 case_plus、radial_pad、magnet_cap 和正负两只 PCB 板夹。
2. 找到带 M3 调节凸台的半壳，在尚未合壳、插入叉轴之前预装调节用 M3 螺母。把径向摩擦块放进该处的槽，凹面贴着叉臂的圆轴；M3×8 调节螺钉只顶摩擦块外侧，不直接顶打印轴。
3. 将带限位环的叉臂轴从侧面放入固定半壳，环落入环形槽，止挡进入对应空间。盖上 case_plus，用 4 枚 M2×20 和 4 枚 M2 螺母固定。先检查圆轴能在允许范围转动，再调 M3×8 的松紧。
4. 按 G4 固定 1 颗径向磁铁，磁铁端盖用 2 枚 M2×4 + 2 枚 M2 螺母固定。这里不是 M2×5，也不是合壳用的 M2×20。
5. 把传感板放在轴端两只板夹之间，器件面朝磁铁，出线边朝预留出口。两只板夹共用 2 枚 M2×8 + 2 枚 M2 螺母固定。不能用螺钉压到芯片或拉弯电路板。
6. 端轴有机械限位，也有线束限制，不是无限旋转轴。手动低速检查当前可用范围，无拉线、卡夹后再收线。

### G4 · 磁铁、传感板与局部应力释放

磁铁与传感板侧剖示意；IC 元件面朝磁铁

1. 领用工厂已焊好五线、做过导通检测并贴有端口标签的传感板。先核对板上元件面与出线端，不在装好的人偶上焊接。
2. 侧装 N003 / N004 磁铁座盖先从斜向开口滑入 Φ6×2.5 磁铁，在磁铁侧壁间隙用少量非导电胶防转，完全固化后安装两枚 M2×5。螺钉头能挡住磁铁滑出，但不能代替圆磁铁的防转粘接。P/D 端轴磁铁同样需要防止相对轴自转；保持端面清洁。
3. 卡扣式传感板托夹先脱离关节，在开口端轻让弹性卡舌，把 PCB 沿导轨平行滑入，让卡舌复位；线从开口端引出。不要从正面压芯片或弯曲 PCB 强塞。卡舌如有裂纹、永久变形，换该打印件。
4. 传感器 IC 顶面朝磁铁，磁铁旋转中心与 IC 中心相对；名义封装顶面间隙 1.00–1.75 mm。这个间隙不同于板面距离。实际磁场、偏心和测量误差仍由 O22 首件与标定记录确认。
5. 34 个托夹用 M3×8 + M3 螺母固定，12 个端轴用成对板夹固定。装完轻拉线束时不能带动 PCB，也不能让固线胶进入导轨或磁铁间隙。
6. 先做线束出口处应力释放，再在同一刚性骨段上用扎带固定；跨运动缝留 U 形活动段，不把相邻两骨段捆死。磁铁与座盖固化后视作一个替换单元。

### G5 · 一体式铰链的特殊顺序

1. 父骨架端部已经包含完整固定座，子骨架端部已经包含旋转叉耳。不再寻找旧版 base_service_half，也不用旧版固定座合壳螺钉。
2. 在旋转叉耳装入前，从固定座侧面的检修开口，沿槽送入 M3 螺母和 M3 反力垫，让它们分别落在六角窝和圆形座。这里“侧面”是零件自身的槽口，不是人偶统一的左侧。
3. 按 G1 装入旋转叉耳和一套轴肩结构。轴肩就位后帮助限制内部件滑出；先调整保持力。最后按 G4 装侧装磁铁座盖和板托夹。

## 04 · 按身体部位逐步拼装

### S01 · 腰部

连接 **盘 A03-01 · X038（骨架／骨盆） → 盘 A02-02 · X042（骨架／腰部）**。本步需打开打印盘：A02、A03。

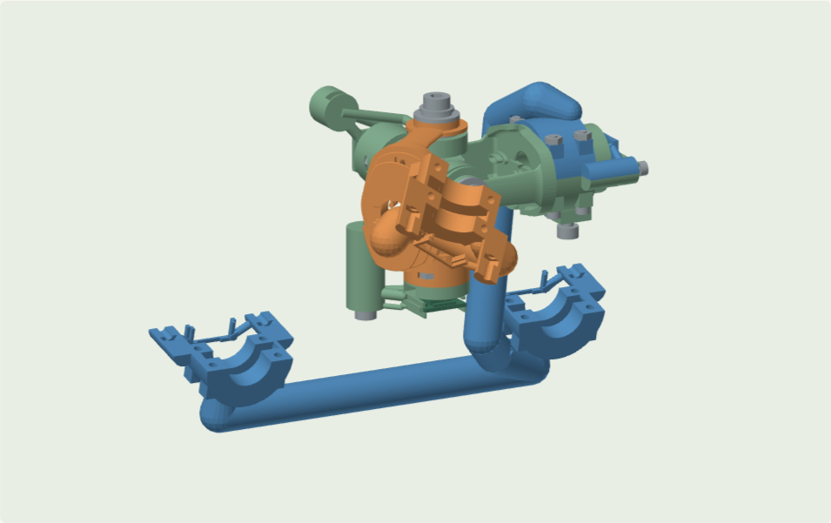
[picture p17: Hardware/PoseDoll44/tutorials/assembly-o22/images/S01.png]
S01 腰部 · CAD 装配位置；蓝色为父骨架，橙色为子骨架


| 取件位置 | 名称 / 原始键 | 本步用途 / 状态 |
| --- | --- | --- |
| 盘 A03-01 · X038（骨架／骨盆） | `frame/pelvis` | 本步新取。一体骨架；已包含 腰部/P_固定半壳、左髋／大腿/P_固定半壳、右髋／大腿/P_固定半壳 |
| 盘 A02-02 · X042（骨架／腰部） | `frame/waist` | 本步新取。一体骨架；已包含 腰部/上叉、胸部/P_固定半壳 |
| 盘 A02-03 · P002（腰部/下环） | `waist/C14` | 本步新取。十字关节下环；先装内部螺母和 M3 反力垫 |
| 盘 A02-05 · P001（腰部/下叉） | `waist/C01` | 本步新取。十字关节叉臂；与另一叉臂正交穿装 |
| 盘 A02-10 · X036（腰部/P_板夹_+14） | `waist/P_pcb_clip_+14` | 本步新取。端轴传感 PCB 的一侧板夹，与另一板夹成对使用 |
| 盘 A02-11 · X035（腰部/P_板夹_-14） | `waist/P_pcb_clip_-14` | 本步新取。端轴传感 PCB 的一侧板夹，与另一板夹成对使用 |
| 盘 A02-12 · P012（腰部/P_径向摩擦块） | `waist/P_radial_pad` | 本步新取。端轴径向摩擦块；凹面朝轴，M3×8 顶压外侧 |
| 盘 A03-02 · X037（腰部/P_活动半壳） | `waist/P_case_plus` | 本步新取。端轴可拆半壳；4 枚 M2×20 合壳 |
| 盘 A03-03 · P003（腰部/上环盖） | `waist/C15` | 本步新取。十字关节上环盖；4 枚 M1.6×6 合环 |
| 盘 A03-06 · X001（腰部/下叉_传感板托夹） | `waist/C01_sensor_cassette` | 本步新取。固定传感 PCB；先滑入板，再装到关节 |
| 盘 A03-08 · X002（腰部/上叉_传感板托夹） | `waist/C02_sensor_cassette` | 本步新取。固定传感 PCB；先滑入板，再装到关节 |
| 盘 A03-10 · P013（腰部/P_磁铁端盖） | `waist/P_magnet_cap` | 本步新取。端轴磁铁端盖；2 枚 M2×4 固定 |
| 盘 A03-12 · N003（腰部/下叉_侧装磁铁座盖） | `waist/C01_magnet_cartridge` | 本步新取。侧面装入并粘固磁铁；旋转侧用 2 枚 M2×5 固定 |
| 盘 A03-13 · N003（腰部/上叉_侧装磁铁座盖） | `waist/C02_magnet_cartridge` | 本步新取。侧面装入并粘固磁铁；旋转侧用 2 枚 M2×5 固定 |

| 五金 / 磁铁 | 本步数量 | 位置 |
| --- | --- | --- |
| M4大平垫圈：外径12、厚1 mm，实物能自由套过Φ4光杆 | 8 | 旋转叉耳两侧，每个支点 2 片 |
| A8不锈钢碟簧：8×4.2×0.4，自由高0.6 mm | 8 | 每个轴肩支点 2 片，相对安装 |
| M4普通平垫圈：外径9、厚0.8 mm，实物通孔验证 | 4 | 螺钉头下、碟簧外侧，每个支点 1 片 |
| 轴肩螺钉 Φ4×8 / M3×0.5，螺纹长6 mm；头Φ7×3，内六角3 mm | 4 | 轴肩摩擦支点，铰链 1 处 / 十字核心 4 处 |
| M3普通六角螺母（不要锁紧螺母替代外形） | 7 | 轴肩捕获窝、板托夹固定点，以及有 P/D 端轴时的摩擦调节槽 |
| M3大平垫圈：外径9、厚0.8 mm，实物通孔验证 | 4 | 固定座内侧，每个支点 1 片反力垫 |
| M1.6×6 内六角圆柱头螺钉；按CAD头径/头高核对 | 4 | C14 / C15 合环 |
| M1.6普通六角螺母（不要锁紧螺母替代外形） | 4 | C14 / C15 合环螺钉对应捕获窝 |
| M2普通六角螺母（不要锁紧螺母替代外形） | 12 | 本步各 M2 螺钉对应捕获窝，一螺钉配一螺母 |
| M2×5 内六角圆柱头螺钉；按CAD头径/头高核对 | 4 | N003 / N004 侧装磁铁座盖，每个 2 枚 |
| 径向两极磁铁 Φ6×2.5 mm；直径方向充磁，不能买轴向充磁 | 3 | 本步每个实测轴 1 颗，位于对应磁铁座 / 端盖 |
| M3×8 内六角圆柱头螺钉；按CAD头径/头高核对 | 3 | 每只传感板托夹 1 枚；每个 P/D 摩擦块调节 1 枚 |
| M2×20 内六角圆柱头螺钉；按CAD头径/头高核对 | 4 | P / D 端轴固定半壳与活动半壳合壳 |
| M2×4 内六角圆柱头螺钉；按CAD头径/头高核对 | 2 | P / D 端轴的磁铁端盖 |
| M2×8 内六角圆柱头螺钉；按CAD头径/头高核对 | 2 | P / D 端轴的成对 PCB 板夹 |

1. 取 盘 A02-03 · P002（腰部/下环）、盘 A03-03 · P003（腰部/上环盖）。两叉分别是 盘 A02-05 · P001（腰部/下叉） 的 C01 部位、盘 A02-02 · X042（骨架／腰部） 的 C02 部位；已经连在骨架上的叉不要拆分或另找重复打印件。
2. 按 [G2](#G2) 先预装 4 枚 M3 螺母与 4 片 M3 反力垫，把两叉交叉放入环，再按 G1 装四套轴肩结构；随后用 4 枚 M1.6×6 + 4 枚 M1.6 螺母合环。
3. P 端按 [G3](#G3)：盘 A03-01 · X038（骨架／骨盆） 内是一体固定半壳，容纳 盘 A02-05 · P001（腰部/下叉） 的圆轴与限位环；装 盘 A02-12 · P012（腰部/P_径向摩擦块），M3×8 + M3 螺母调摩擦。用 盘 A03-02 · X037（腰部/P_活动半壳） 和 4 枚 M2×20 + 4 枚 M2 螺母合壳。磁铁端盖用 2 枚 M2×4 + 2 枚 M2 螺母；两只 PCB 板夹用 2 枚 M2×8 + 2 枚 M2 螺母。
4. C01 测量端按 [G4](#G4)：盘 A03-12 · N003（腰部/下叉_侧装磁铁座盖） 内放 1 颗磁铁，用 2 枚 M2×5 + 2 枚 M2 螺母固定到叉臂端；盘 A03-06 · X001（腰部/下叉_传感板托夹） 先滑入传感板，再用 M3×8 + M3 螺母固定。
5. C02 测量端按 [G4](#G4)：盘 A03-13 · N003（腰部/上叉_侧装磁铁座盖） 内放 1 颗磁铁，用 2 枚 M2×5 + 2 枚 M2 螺母固定到叉臂端；盘 A03-08 · X002（腰部/上叉_传感板托夹） 先滑入传感板，再用 M3×8 + M3 螺母固定。
6. 局部慢慢活动，确认每一相邻活动面不挤压垫片、PCB 和线束。按需要的手感调保持力即可；当前可用行程由实物相邻件与线束决定，软件 raw_limits 不是要求你硬拧到的机械行程。

| 电路端口 / 中央板位号 | 测量轴 | 传感板装在 | 对应磁铁装在 | 每根线建议长度 |
| --- | --- | --- | --- | --- |
| 端口 A01 / J10 | `waist/r0` | 盘 A02-11 · X035（腰部/P_板夹_-14） + 盘 A02-10 · X036（腰部/P_板夹_+14） | 盘 A03-10 · P013（腰部/P_磁铁端盖） | 450 mm × 5 根，首件后定长 |
| 端口 A02 / J11 | `waist/r1` | 盘 A03-06 · X001（腰部/下叉_传感板托夹） | 盘 A03-12 · N003（腰部/下叉_侧装磁铁座盖） | 450 mm × 5 根，首件后定长 |
| 端口 A03 / J12 | `waist/r2` | 盘 A03-08 · X002（腰部/上叉_传感板托夹） | 盘 A03-13 · N003（腰部/上叉_侧装磁铁座盖） | 450 mm × 5 根，首件后定长 |

本步完成检查：A01、A02、A03 标签对应正确；磁铁不相对载体打滑；转轴可手动摆动并保持；线先松放到背盒方向，留待走线章节统一固定。

### S02 · 胸部

连接 **盘 A02-02 · X042（骨架／腰部） → 盘 A02-01 · X046（骨架／胸部）**。本步需打开打印盘：A02、A03。

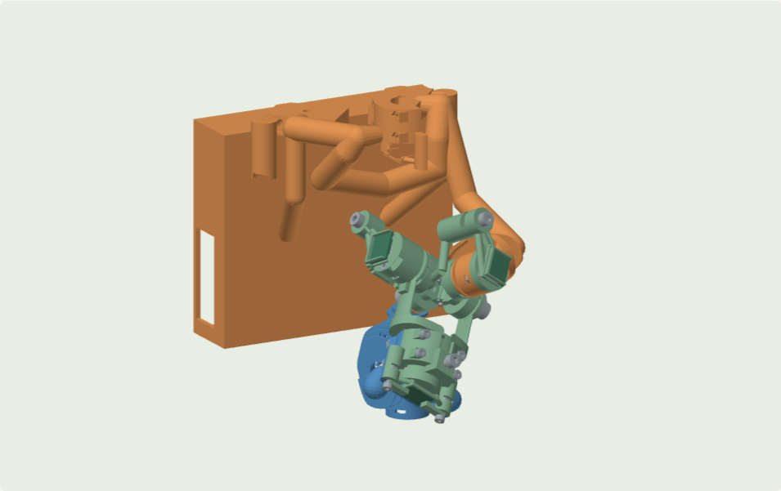
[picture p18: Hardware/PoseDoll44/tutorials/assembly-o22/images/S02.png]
S02 胸部 · CAD 装配位置；蓝色为父骨架，橙色为子骨架


| 取件位置 | 名称 / 原始键 | 本步用途 / 状态 |
| --- | --- | --- |
| 盘 A02-02 · X042（骨架／腰部） | `frame/waist` | 已在 S01 取用，直接使用已装骨架。一体骨架；已包含 腰部/上叉、胸部/P_固定半壳 |
| 盘 A02-01 · X046（骨架／胸部） | `frame/chest` | 本步新取。一体骨架；已包含 胸部/上叉、头颈/P_固定半壳、左锁骨前后/固定侧关节座、右锁骨前后/固定侧关节座 |
| 盘 A02-04 · P018（胸部/下环） | `chest/C14` | 本步新取。十字关节下环；先装内部螺母和 M3 反力垫 |
| 盘 A02-06 · P017（胸部/下叉） | `chest/C01` | 本步新取。十字关节叉臂；与另一叉臂正交穿装 |
| 盘 A02-07 · X041（胸部/P_活动半壳） | `chest/P_case_plus` | 本步新取。端轴可拆半壳；4 枚 M2×20 合壳 |
| 盘 A02-08 · X040（胸部/P_板夹_+14） | `chest/P_pcb_clip_+14` | 本步新取。端轴传感 PCB 的一侧板夹，与另一板夹成对使用 |
| 盘 A02-09 · X039（胸部/P_板夹_-14） | `chest/P_pcb_clip_-14` | 本步新取。端轴传感 PCB 的一侧板夹，与另一板夹成对使用 |
| 盘 A02-13 · P028（胸部/P_径向摩擦块） | `chest/P_radial_pad` | 本步新取。端轴径向摩擦块；凹面朝轴，M3×8 顶压外侧 |
| 盘 A03-04 · P019（胸部/上环盖） | `chest/C15` | 本步新取。十字关节上环盖；4 枚 M1.6×6 合环 |
| 盘 A03-05 · X004（胸部/上叉_传感板托夹） | `chest/C02_sensor_cassette` | 本步新取。固定传感 PCB；先滑入板，再装到关节 |
| 盘 A03-07 · X003（胸部/下叉_传感板托夹） | `chest/C01_sensor_cassette` | 本步新取。固定传感 PCB；先滑入板，再装到关节 |
| 盘 A03-11 · P029（胸部/P_磁铁端盖） | `chest/P_magnet_cap` | 本步新取。端轴磁铁端盖；2 枚 M2×4 固定 |
| 盘 A03-14 · N003（胸部/下叉_侧装磁铁座盖） | `chest/C01_magnet_cartridge` | 本步新取。侧面装入并粘固磁铁；旋转侧用 2 枚 M2×5 固定 |
| 盘 A03-15 · N003（胸部/上叉_侧装磁铁座盖） | `chest/C02_magnet_cartridge` | 本步新取。侧面装入并粘固磁铁；旋转侧用 2 枚 M2×5 固定 |

| 五金 / 磁铁 | 本步数量 | 位置 |
| --- | --- | --- |
| M4大平垫圈：外径12、厚1 mm，实物能自由套过Φ4光杆 | 8 | 旋转叉耳两侧，每个支点 2 片 |
| A8不锈钢碟簧：8×4.2×0.4，自由高0.6 mm | 8 | 每个轴肩支点 2 片，相对安装 |
| M4普通平垫圈：外径9、厚0.8 mm，实物通孔验证 | 4 | 螺钉头下、碟簧外侧，每个支点 1 片 |
| 轴肩螺钉 Φ4×8 / M3×0.5，螺纹长6 mm；头Φ7×3，内六角3 mm | 4 | 轴肩摩擦支点，铰链 1 处 / 十字核心 4 处 |
| M3普通六角螺母（不要锁紧螺母替代外形） | 7 | 轴肩捕获窝、板托夹固定点，以及有 P/D 端轴时的摩擦调节槽 |
| M3大平垫圈：外径9、厚0.8 mm，实物通孔验证 | 4 | 固定座内侧，每个支点 1 片反力垫 |
| M1.6×6 内六角圆柱头螺钉；按CAD头径/头高核对 | 4 | C14 / C15 合环 |
| M1.6普通六角螺母（不要锁紧螺母替代外形） | 4 | C14 / C15 合环螺钉对应捕获窝 |
| M2普通六角螺母（不要锁紧螺母替代外形） | 12 | 本步各 M2 螺钉对应捕获窝，一螺钉配一螺母 |
| M2×5 内六角圆柱头螺钉；按CAD头径/头高核对 | 4 | N003 / N004 侧装磁铁座盖，每个 2 枚 |
| 径向两极磁铁 Φ6×2.5 mm；直径方向充磁，不能买轴向充磁 | 3 | 本步每个实测轴 1 颗，位于对应磁铁座 / 端盖 |
| M3×8 内六角圆柱头螺钉；按CAD头径/头高核对 | 3 | 每只传感板托夹 1 枚；每个 P/D 摩擦块调节 1 枚 |
| M2×20 内六角圆柱头螺钉；按CAD头径/头高核对 | 4 | P / D 端轴固定半壳与活动半壳合壳 |
| M2×4 内六角圆柱头螺钉；按CAD头径/头高核对 | 2 | P / D 端轴的磁铁端盖 |
| M2×8 内六角圆柱头螺钉；按CAD头径/头高核对 | 2 | P / D 端轴的成对 PCB 板夹 |

1. 取 盘 A02-04 · P018（胸部/下环）、盘 A03-04 · P019（胸部/上环盖）。两叉分别是 盘 A02-06 · P017（胸部/下叉） 的 C01 部位、盘 A02-01 · X046（骨架／胸部） 的 C02 部位；已经连在骨架上的叉不要拆分或另找重复打印件。
2. 按 [G2](#G2) 先预装 4 枚 M3 螺母与 4 片 M3 反力垫，把两叉交叉放入环，再按 G1 装四套轴肩结构；随后用 4 枚 M1.6×6 + 4 枚 M1.6 螺母合环。
3. P 端按 [G3](#G3)：盘 A02-02 · X042（骨架／腰部） 内是一体固定半壳，容纳 盘 A02-06 · P017（胸部/下叉） 的圆轴与限位环；装 盘 A02-13 · P028（胸部/P_径向摩擦块），M3×8 + M3 螺母调摩擦。用 盘 A02-07 · X041（胸部/P_活动半壳） 和 4 枚 M2×20 + 4 枚 M2 螺母合壳。磁铁端盖用 2 枚 M2×4 + 2 枚 M2 螺母；两只 PCB 板夹用 2 枚 M2×8 + 2 枚 M2 螺母。
4. C01 测量端按 [G4](#G4)：盘 A03-14 · N003（胸部/下叉_侧装磁铁座盖） 内放 1 颗磁铁，用 2 枚 M2×5 + 2 枚 M2 螺母固定到叉臂端；盘 A03-07 · X003（胸部/下叉_传感板托夹） 先滑入传感板，再用 M3×8 + M3 螺母固定。
5. C02 测量端按 [G4](#G4)：盘 A03-15 · N003（胸部/上叉_侧装磁铁座盖） 内放 1 颗磁铁，用 2 枚 M2×5 + 2 枚 M2 螺母固定到叉臂端；盘 A03-05 · X004（胸部/上叉_传感板托夹） 先滑入传感板，再用 M3×8 + M3 螺母固定。
6. 局部慢慢活动，确认每一相邻活动面不挤压垫片、PCB 和线束。按需要的手感调保持力即可；当前可用行程由实物相邻件与线束决定，软件 raw_limits 不是要求你硬拧到的机械行程。

| 电路端口 / 中央板位号 | 测量轴 | 传感板装在 | 对应磁铁装在 | 每根线建议长度 |
| --- | --- | --- | --- | --- |
| 端口 A04 / J13 | `chest/r0` | 盘 A02-09 · X039（胸部/P_板夹_-14） + 盘 A02-08 · X040（胸部/P_板夹_+14） | 盘 A03-11 · P029（胸部/P_磁铁端盖） | 450 mm × 5 根，首件后定长 |
| 端口 A05 / J14 | `chest/r1` | 盘 A03-07 · X003（胸部/下叉_传感板托夹） | 盘 A03-14 · N003（胸部/下叉_侧装磁铁座盖） | 275 mm × 5 根，首件后定长 |
| 端口 A06 / J15 | `chest/r2` | 盘 A03-05 · X004（胸部/上叉_传感板托夹） | 盘 A03-15 · N003（胸部/上叉_侧装磁铁座盖） | 275 mm × 5 根，首件后定长 |

本步完成检查：A04、A05、A06 标签对应正确；磁铁不相对载体打滑；转轴可手动摆动并保持；线先松放到背盒方向，留待走线章节统一固定。

### S03 · 头颈

连接 **盘 A02-01 · X046（骨架／胸部） → 盘 A01-02 · X050（骨架／头颈）**。本步需打开打印盘：A01、A02。

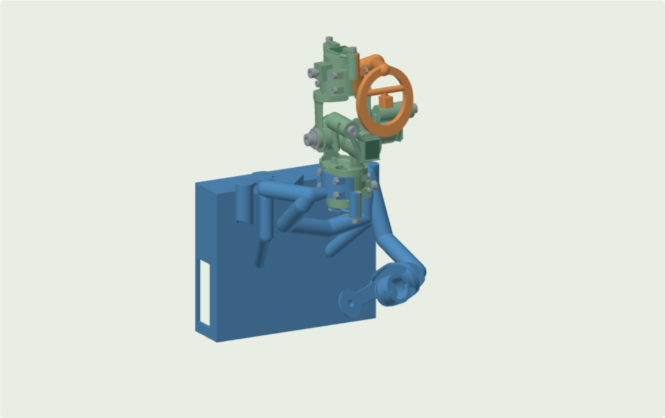
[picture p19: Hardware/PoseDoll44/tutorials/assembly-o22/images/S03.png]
S03 头颈 · CAD 装配位置；蓝色为父骨架，橙色为子骨架


| 取件位置 | 名称 / 原始键 | 本步用途 / 状态 |
| --- | --- | --- |
| 盘 A02-01 · X046（骨架／胸部） | `frame/chest` | 已在 S02 取用，直接使用已装骨架。一体骨架；已包含 胸部/上叉、头颈/P_固定半壳、左锁骨前后/固定侧关节座、右锁骨前后/固定侧关节座 |
| 盘 A01-02 · X050（骨架／头颈） | `frame/head` | 本步新取。一体骨架；已包含 头颈/D_固定半壳 |
| 盘 A01-03 · P035（头颈/下环） | `head/C14` | 本步新取。十字关节下环；先装内部螺母和 M3 反力垫 |
| 盘 A01-04 · P033（头颈/下叉） | `head/C01` | 本步新取。十字关节叉臂；与另一叉臂正交穿装 |
| 盘 A01-05 · P034（头颈/上叉） | `head/C02` | 本步新取。十字关节叉臂；与另一叉臂正交穿装 |
| 盘 A01-06 · X045（头颈/P_活动半壳） | `head/P_case_plus` | 本步新取。端轴可拆半壳；4 枚 M2×20 合壳 |
| 盘 A01-07 · X049（头颈/D_活动半壳） | `head/D_case_plus` | 本步新取。端轴可拆半壳；4 枚 M2×20 合壳 |
| 盘 A01-08 · P036（头颈/上环盖） | `head/C15` | 本步新取。十字关节上环盖；4 枚 M1.6×6 合环 |
| 盘 A01-09 · X005（头颈/下叉_传感板托夹） | `head/C01_sensor_cassette` | 本步新取。固定传感 PCB；先滑入板，再装到关节 |
| 盘 A01-10 · X006（头颈/上叉_传感板托夹） | `head/C02_sensor_cassette` | 本步新取。固定传感 PCB；先滑入板，再装到关节 |
| 盘 A01-11 · P040（头颈/P_磁铁端盖） | `head/P_magnet_cap` | 本步新取。端轴磁铁端盖；2 枚 M2×4 固定 |
| 盘 A01-12 · P045（头颈/D_磁铁端盖） | `head/D_magnet_cap` | 本步新取。端轴磁铁端盖；2 枚 M2×4 固定 |
| 盘 A01-13 · N003（头颈/下叉_侧装磁铁座盖） | `head/C01_magnet_cartridge` | 本步新取。侧面装入并粘固磁铁；旋转侧用 2 枚 M2×5 固定 |
| 盘 A01-14 · N003（头颈/上叉_侧装磁铁座盖） | `head/C02_magnet_cartridge` | 本步新取。侧面装入并粘固磁铁；旋转侧用 2 枚 M2×5 固定 |
| 盘 A01-15 · X043（头颈/P_板夹_-14） | `head/P_pcb_clip_-14` | 本步新取。端轴传感 PCB 的一侧板夹，与另一板夹成对使用 |
| 盘 A01-16 · X044（头颈/P_板夹_+14） | `head/P_pcb_clip_+14` | 本步新取。端轴传感 PCB 的一侧板夹，与另一板夹成对使用 |
| 盘 A01-17 · X047（头颈/D_板夹_-14） | `head/D_pcb_clip_-14` | 本步新取。端轴传感 PCB 的一侧板夹，与另一板夹成对使用 |
| 盘 A01-18 · X048（头颈/D_板夹_+14） | `head/D_pcb_clip_+14` | 本步新取。端轴传感 PCB 的一侧板夹，与另一板夹成对使用 |
| 盘 A01-19 · P039（头颈/P_径向摩擦块） | `head/P_radial_pad` | 本步新取。端轴径向摩擦块；凹面朝轴，M3×8 顶压外侧 |
| 盘 A01-20 · P044（头颈/D_径向摩擦块） | `head/D_radial_pad` | 本步新取。端轴径向摩擦块；凹面朝轴，M3×8 顶压外侧 |

| 五金 / 磁铁 | 本步数量 | 位置 |
| --- | --- | --- |
| M4大平垫圈：外径12、厚1 mm，实物能自由套过Φ4光杆 | 8 | 旋转叉耳两侧，每个支点 2 片 |
| A8不锈钢碟簧：8×4.2×0.4，自由高0.6 mm | 8 | 每个轴肩支点 2 片，相对安装 |
| M4普通平垫圈：外径9、厚0.8 mm，实物通孔验证 | 4 | 螺钉头下、碟簧外侧，每个支点 1 片 |
| 轴肩螺钉 Φ4×8 / M3×0.5，螺纹长6 mm；头Φ7×3，内六角3 mm | 4 | 轴肩摩擦支点，铰链 1 处 / 十字核心 4 处 |
| M3普通六角螺母（不要锁紧螺母替代外形） | 8 | 轴肩捕获窝、板托夹固定点，以及有 P/D 端轴时的摩擦调节槽 |
| M3大平垫圈：外径9、厚0.8 mm，实物通孔验证 | 4 | 固定座内侧，每个支点 1 片反力垫 |
| M1.6×6 内六角圆柱头螺钉；按CAD头径/头高核对 | 4 | C14 / C15 合环 |
| M1.6普通六角螺母（不要锁紧螺母替代外形） | 4 | C14 / C15 合环螺钉对应捕获窝 |
| M2普通六角螺母（不要锁紧螺母替代外形） | 20 | 本步各 M2 螺钉对应捕获窝，一螺钉配一螺母 |
| M2×5 内六角圆柱头螺钉；按CAD头径/头高核对 | 4 | N003 / N004 侧装磁铁座盖，每个 2 枚 |
| 径向两极磁铁 Φ6×2.5 mm；直径方向充磁，不能买轴向充磁 | 4 | 本步每个实测轴 1 颗，位于对应磁铁座 / 端盖 |
| M3×8 内六角圆柱头螺钉；按CAD头径/头高核对 | 4 | 每只传感板托夹 1 枚；每个 P/D 摩擦块调节 1 枚 |
| M2×20 内六角圆柱头螺钉；按CAD头径/头高核对 | 8 | P / D 端轴固定半壳与活动半壳合壳 |
| M2×4 内六角圆柱头螺钉；按CAD头径/头高核对 | 4 | P / D 端轴的磁铁端盖 |
| M2×8 内六角圆柱头螺钉；按CAD头径/头高核对 | 4 | P / D 端轴的成对 PCB 板夹 |

1. 取 盘 A01-03 · P035（头颈/下环）、盘 A01-08 · P036（头颈/上环盖）。两叉分别是 盘 A01-04 · P033（头颈/下叉） 的 C01 部位、盘 A01-05 · P034（头颈/上叉） 的 C02 部位；已经连在骨架上的叉不要拆分或另找重复打印件。
2. 按 [G2](#G2) 先预装 4 枚 M3 螺母与 4 片 M3 反力垫，把两叉交叉放入环，再按 G1 装四套轴肩结构；随后用 4 枚 M1.6×6 + 4 枚 M1.6 螺母合环。
3. P 端按 [G3](#G3)：盘 A02-01 · X046（骨架／胸部） 内是一体固定半壳，容纳 盘 A01-04 · P033（头颈/下叉） 的圆轴与限位环；装 盘 A01-19 · P039（头颈/P_径向摩擦块），M3×8 + M3 螺母调摩擦。用 盘 A01-06 · X045（头颈/P_活动半壳） 和 4 枚 M2×20 + 4 枚 M2 螺母合壳。磁铁端盖用 2 枚 M2×4 + 2 枚 M2 螺母；两只 PCB 板夹用 2 枚 M2×8 + 2 枚 M2 螺母。
4. D 端按 [G3](#G3)：盘 A01-02 · X050（骨架／头颈） 内是一体固定半壳，容纳 盘 A01-05 · P034（头颈/上叉） 的圆轴与限位环；装 盘 A01-20 · P044（头颈/D_径向摩擦块），M3×8 + M3 螺母调摩擦。用 盘 A01-07 · X049（头颈/D_活动半壳） 和 4 枚 M2×20 + 4 枚 M2 螺母合壳。磁铁端盖用 2 枚 M2×4 + 2 枚 M2 螺母；两只 PCB 板夹用 2 枚 M2×8 + 2 枚 M2 螺母。
5. C01 测量端按 [G4](#G4)：盘 A01-13 · N003（头颈/下叉_侧装磁铁座盖） 内放 1 颗磁铁，用 2 枚 M2×5 + 2 枚 M2 螺母固定到叉臂端；盘 A01-09 · X005（头颈/下叉_传感板托夹） 先滑入传感板，再用 M3×8 + M3 螺母固定。
6. C02 测量端按 [G4](#G4)：盘 A01-14 · N003（头颈/上叉_侧装磁铁座盖） 内放 1 颗磁铁，用 2 枚 M2×5 + 2 枚 M2 螺母固定到叉臂端；盘 A01-10 · X006（头颈/上叉_传感板托夹） 先滑入传感板，再用 M3×8 + M3 螺母固定。
7. 局部慢慢活动，确认每一相邻活动面不挤压垫片、PCB 和线束。按需要的手感调保持力即可；当前可用行程由实物相邻件与线束决定，软件 raw_limits 不是要求你硬拧到的机械行程。

| 电路端口 / 中央板位号 | 测量轴 | 传感板装在 | 对应磁铁装在 | 每根线建议长度 |
| --- | --- | --- | --- | --- |
| 端口 A07 / J16 | `head/r0` | 盘 A01-15 · X043（头颈/P_板夹_-14） + 盘 A01-16 · X044（头颈/P_板夹_+14） | 盘 A01-11 · P040（头颈/P_磁铁端盖） | 225 mm × 5 根，首件后定长 |
| 端口 A08 / J17 | `head/r1` | 盘 A01-09 · X005（头颈/下叉_传感板托夹） | 盘 A01-13 · N003（头颈/下叉_侧装磁铁座盖） | 350 mm × 5 根，首件后定长 |
| 端口 A09 / J18 | `head/r2` | 盘 A01-10 · X006（头颈/上叉_传感板托夹） | 盘 A01-14 · N003（头颈/上叉_侧装磁铁座盖） | 350 mm × 5 根，首件后定长 |
| 端口 A10 / J19 | `head/r3` | 盘 A01-17 · X047（头颈/D_板夹_-14） + 盘 A01-18 · X048（头颈/D_板夹_+14） | 盘 A01-12 · P045（头颈/D_磁铁端盖） | 325 mm × 5 根，首件后定长 |

本步完成检查：A07、A08、A09、A10 标签对应正确；磁铁不相对载体打滑；转轴可手动摆动并保持；线先松放到背盒方向，留待走线章节统一固定。

### S04 · 左锁骨前后

连接 **盘 A02-01 · X046（骨架／胸部） → 盘 A04-02 · W005（骨架／左锁骨前后中间架）**。本步需打开打印盘：A02、A04、A05。

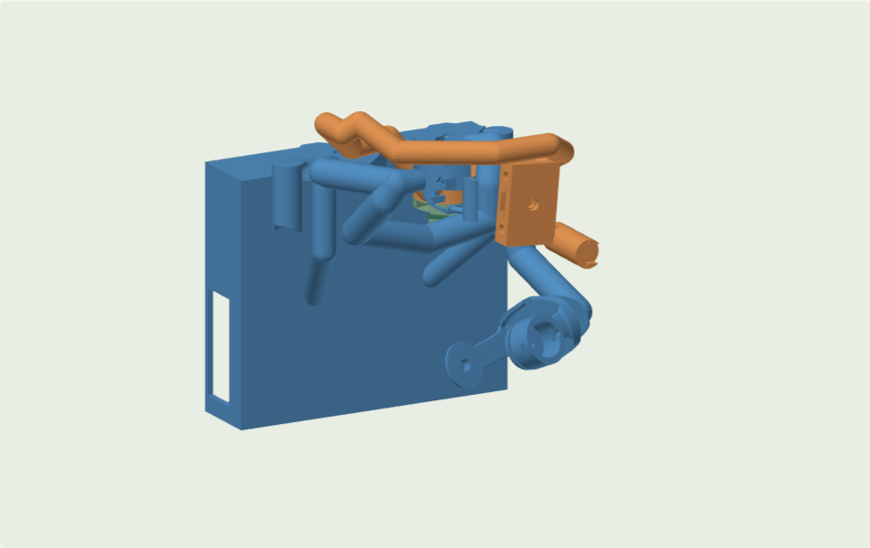
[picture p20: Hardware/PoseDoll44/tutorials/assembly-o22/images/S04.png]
S04 左锁骨前后 · CAD 装配位置；蓝色为父骨架，橙色为子骨架


| 取件位置 | 名称 / 原始键 | 本步用途 / 状态 |
| --- | --- | --- |
| 盘 A02-01 · X046（骨架／胸部） | `frame/chest` | 已在 S02 取用，直接使用已装骨架。一体骨架；已包含 胸部/上叉、头颈/P_固定半壳、左锁骨前后/固定侧关节座、右锁骨前后/固定侧关节座 |
| 盘 A04-02 · W005（骨架／左锁骨前后中间架） | `frame/clavicle_l.protract_frame` | 本步新取。一体骨架；已包含 左锁骨前后/旋转侧叉耳、左锁骨升降/固定侧关节座 |
| 盘 A05-19 · N004（左锁骨前后/侧装磁铁座盖） | `clavicle_l.protract/magnet_cartridge` | 本步新取。侧面装入并粘固磁铁；旋转侧用 2 枚 M2×5 固定 |
| 盘 A05-22 · X019（左锁骨前后/传感板托夹） | `clavicle_l.protract/sensor_cassette` | 本步新取。固定传感 PCB；先滑入板，再装到关节 |

| 五金 / 磁铁 | 本步数量 | 位置 |
| --- | --- | --- |
| M4大平垫圈：外径12、厚1 mm，实物能自由套过Φ4光杆 | 2 | 旋转叉耳两侧，每个支点 2 片 |
| A8不锈钢碟簧：8×4.2×0.4，自由高0.6 mm | 2 | 每个轴肩支点 2 片，相对安装 |
| M4普通平垫圈：外径9、厚0.8 mm，实物通孔验证 | 1 | 螺钉头下、碟簧外侧，每个支点 1 片 |
| 轴肩螺钉 Φ4×8 / M3×0.5，螺纹长6 mm；头Φ7×3，内六角3 mm | 1 | 轴肩摩擦支点，铰链 1 处 / 十字核心 4 处 |
| M3普通六角螺母（不要锁紧螺母替代外形） | 2 | 轴肩捕获窝、板托夹固定点，以及有 P/D 端轴时的摩擦调节槽 |
| M3大平垫圈：外径9、厚0.8 mm，实物通孔验证 | 1 | 固定座内侧，每个支点 1 片反力垫 |
| M3×8 内六角圆柱头螺钉；按CAD头径/头高核对 | 1 | 每只传感板托夹 1 枚；每个 P/D 摩擦块调节 1 枚 |
| M2普通六角螺母（不要锁紧螺母替代外形） | 2 | 本步各 M2 螺钉对应捕获窝，一螺钉配一螺母 |
| M2×5 内六角圆柱头螺钉；按CAD头径/头高核对 | 2 | N003 / N004 侧装磁铁座盖，每个 2 枚 |
| 径向两极磁铁 Φ6×2.5 mm；直径方向充磁，不能买轴向充磁 | 1 | 本步每个实测轴 1 颗，位于对应磁铁座 / 端盖 |

1. 将 盘 A02-01 · X046（骨架／胸部） 的固定关节座与 盘 A04-02 · W005（骨架／左锁骨前后中间架） 的旋转叉耳摆到图示连接位置。侧槽尚未被挡住时，预装 1 枚 M3 螺母与 1 片 M3 反力垫。
2. 按 [G5 一体铰链](#G5) 和 [G1 轴肩层次](#G1) 装 1 套轴肩结构。单个支点为 1 枚轴肩螺钉、2 片 M4 大垫、2 片 A8 碟簧、1 片 M4 普通垫，外加刚才放入的螺母和反力垫。
3. 调整摩擦后，按 [G4](#G4) 给 盘 A05-19 · N004（左锁骨前后/侧装磁铁座盖） 装 1 颗磁铁，固化后用 2 枚 M2×5 + 2 枚 M2 螺母固定到旋转侧。
4. 把下表所列传感板装入 盘 A05-22 · X019（左锁骨前后/传感板托夹），再用 1 枚 M3×8 + 1 枚 M3 螺母固定到固定侧。传感器与磁铁相对，不能把两者都固定到同一旋转骨段。
5. 局部慢慢活动，确认每一相邻活动面不挤压垫片、PCB 和线束。按需要的手感调保持力即可；当前可用行程由实物相邻件与线束决定，软件 raw_limits 不是要求你硬拧到的机械行程。

| 电路端口 / 中央板位号 | 测量轴 | 传感板装在 | 对应磁铁装在 | 每根线建议长度 |
| --- | --- | --- | --- | --- |
| 端口 A11 / J20 | `clavicle_l.protract/r0` | 盘 A05-22 · X019（左锁骨前后/传感板托夹） | 盘 A05-19 · N004（左锁骨前后/侧装磁铁座盖） | 200 mm × 5 根，首件后定长 |

本步完成检查：A11 标签对应正确；磁铁不相对载体打滑；转轴可手动摆动并保持；线先松放到背盒方向，留待走线章节统一固定。

### S05 · 左锁骨升降

连接 **盘 A04-02 · W005（骨架／左锁骨前后中间架） → 盘 A04-01 · X054（骨架／左锁骨）**。本步需打开打印盘：A04、A05。

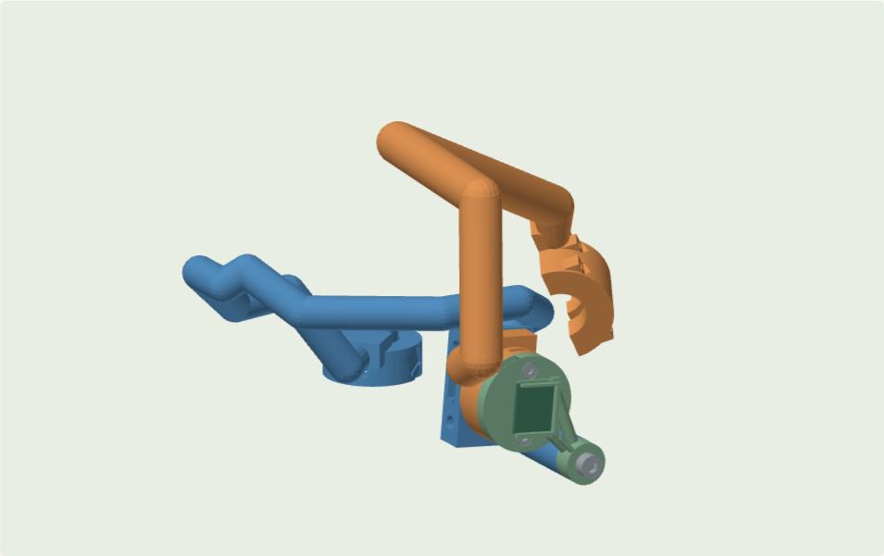
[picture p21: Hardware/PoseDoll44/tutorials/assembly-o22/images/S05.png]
S05 左锁骨升降 · CAD 装配位置；蓝色为父骨架，橙色为子骨架


| 取件位置 | 名称 / 原始键 | 本步用途 / 状态 |
| --- | --- | --- |
| 盘 A04-02 · W005（骨架／左锁骨前后中间架） | `frame/clavicle_l.protract_frame` | 已在 S04 取用，直接使用已装骨架。一体骨架；已包含 左锁骨前后/旋转侧叉耳、左锁骨升降/固定侧关节座 |
| 盘 A04-01 · X054（骨架／左锁骨） | `frame/clavicle_l` | 本步新取。一体骨架；已包含 左肩／上臂/P_固定半壳、左锁骨升降/旋转侧叉耳 |
| 盘 A05-05 · N004（左锁骨升降/侧装磁铁座盖） | `clavicle_l.elevate/magnet_cartridge` | 本步新取。侧面装入并粘固磁铁；旋转侧用 2 枚 M2×5 固定 |
| 盘 A05-10 · X020（左锁骨升降/传感板托夹） | `clavicle_l.elevate/sensor_cassette` | 本步新取。固定传感 PCB；先滑入板，再装到关节 |

| 五金 / 磁铁 | 本步数量 | 位置 |
| --- | --- | --- |
| M4大平垫圈：外径12、厚1 mm，实物能自由套过Φ4光杆 | 2 | 旋转叉耳两侧，每个支点 2 片 |
| A8不锈钢碟簧：8×4.2×0.4，自由高0.6 mm | 2 | 每个轴肩支点 2 片，相对安装 |
| M4普通平垫圈：外径9、厚0.8 mm，实物通孔验证 | 1 | 螺钉头下、碟簧外侧，每个支点 1 片 |
| 轴肩螺钉 Φ4×8 / M3×0.5，螺纹长6 mm；头Φ7×3，内六角3 mm | 1 | 轴肩摩擦支点，铰链 1 处 / 十字核心 4 处 |
| M3普通六角螺母（不要锁紧螺母替代外形） | 2 | 轴肩捕获窝、板托夹固定点，以及有 P/D 端轴时的摩擦调节槽 |
| M3大平垫圈：外径9、厚0.8 mm，实物通孔验证 | 1 | 固定座内侧，每个支点 1 片反力垫 |
| M3×8 内六角圆柱头螺钉；按CAD头径/头高核对 | 1 | 每只传感板托夹 1 枚；每个 P/D 摩擦块调节 1 枚 |
| M2普通六角螺母（不要锁紧螺母替代外形） | 2 | 本步各 M2 螺钉对应捕获窝，一螺钉配一螺母 |
| M2×5 内六角圆柱头螺钉；按CAD头径/头高核对 | 2 | N003 / N004 侧装磁铁座盖，每个 2 枚 |
| 径向两极磁铁 Φ6×2.5 mm；直径方向充磁，不能买轴向充磁 | 1 | 本步每个实测轴 1 颗，位于对应磁铁座 / 端盖 |

1. 将 盘 A04-02 · W005（骨架／左锁骨前后中间架） 的固定关节座与 盘 A04-01 · X054（骨架／左锁骨） 的旋转叉耳摆到图示连接位置。侧槽尚未被挡住时，预装 1 枚 M3 螺母与 1 片 M3 反力垫。
2. 按 [G5 一体铰链](#G5) 和 [G1 轴肩层次](#G1) 装 1 套轴肩结构。单个支点为 1 枚轴肩螺钉、2 片 M4 大垫、2 片 A8 碟簧、1 片 M4 普通垫，外加刚才放入的螺母和反力垫。
3. 调整摩擦后，按 [G4](#G4) 给 盘 A05-05 · N004（左锁骨升降/侧装磁铁座盖） 装 1 颗磁铁，固化后用 2 枚 M2×5 + 2 枚 M2 螺母固定到旋转侧。
4. 把下表所列传感板装入 盘 A05-10 · X020（左锁骨升降/传感板托夹），再用 1 枚 M3×8 + 1 枚 M3 螺母固定到固定侧。传感器与磁铁相对，不能把两者都固定到同一旋转骨段。
5. 局部慢慢活动，确认每一相邻活动面不挤压垫片、PCB 和线束。按需要的手感调保持力即可；当前可用行程由实物相邻件与线束决定，软件 raw_limits 不是要求你硬拧到的机械行程。

| 电路端口 / 中央板位号 | 测量轴 | 传感板装在 | 对应磁铁装在 | 每根线建议长度 |
| --- | --- | --- | --- | --- |
| 端口 A12 / J21 | `clavicle_l.elevate/r0` | 盘 A05-10 · X020（左锁骨升降/传感板托夹） | 盘 A05-05 · N004（左锁骨升降/侧装磁铁座盖） | 325 mm × 5 根，首件后定长 |

本步完成检查：A12 标签对应正确；磁铁不相对载体打滑；转轴可手动摆动并保持；线先松放到背盒方向，留待走线章节统一固定。

### S06 · 左肩／上臂

连接 **盘 A04-01 · X054（骨架／左锁骨） → 盘 A04-05 · X058（骨架／左肩／上臂）**。本步需打开打印盘：A04、A05。

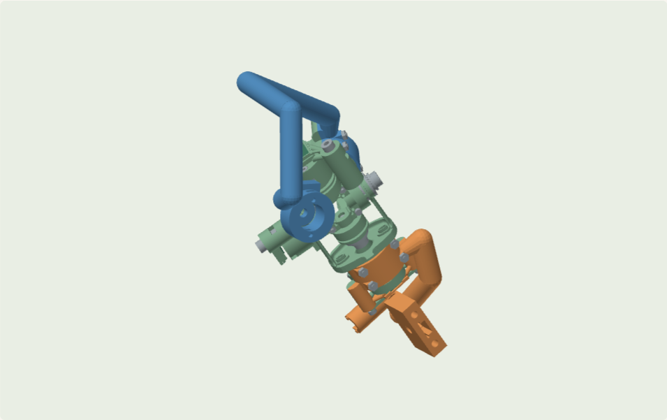
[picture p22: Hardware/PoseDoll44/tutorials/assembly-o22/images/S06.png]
S06 左肩／上臂 · CAD 装配位置；蓝色为父骨架，橙色为子骨架


| 取件位置 | 名称 / 原始键 | 本步用途 / 状态 |
| --- | --- | --- |
| 盘 A04-01 · X054（骨架／左锁骨） | `frame/clavicle_l` | 已在 S05 取用，直接使用已装骨架。一体骨架；已包含 左肩／上臂/P_固定半壳、左锁骨升降/旋转侧叉耳 |
| 盘 A04-05 · X058（骨架／左肩／上臂） | `frame/upperarm_l` | 本步新取。一体骨架；已包含 左肩／上臂/D_固定半壳、左肘屈伸/固定侧关节座 |
| 盘 A04-04 · P051（左肩／上臂/下环） | `upperarm_l/C14` | 本步新取。十字关节下环；先装内部螺母和 M3 反力垫 |
| 盘 A04-06 · X051（左肩／上臂/P_板夹_-14） | `upperarm_l/P_pcb_clip_-14` | 本步新取。端轴传感 PCB 的一侧板夹，与另一板夹成对使用 |
| 盘 A04-07 · X056（左肩／上臂/D_板夹_+14） | `upperarm_l/D_pcb_clip_+14` | 本步新取。端轴传感 PCB 的一侧板夹，与另一板夹成对使用 |
| 盘 A04-08 · X055（左肩／上臂/D_板夹_-14） | `upperarm_l/D_pcb_clip_-14` | 本步新取。端轴传感 PCB 的一侧板夹，与另一板夹成对使用 |
| 盘 A04-09 · X052（左肩／上臂/P_板夹_+14） | `upperarm_l/P_pcb_clip_+14` | 本步新取。端轴传感 PCB 的一侧板夹，与另一板夹成对使用 |
| 盘 A04-10 · P061（左肩／上臂/P_径向摩擦块） | `upperarm_l/P_radial_pad` | 本步新取。端轴径向摩擦块；凹面朝轴，M3×8 顶压外侧 |
| 盘 A04-11 · P066（左肩／上臂/D_径向摩擦块） | `upperarm_l/D_radial_pad` | 本步新取。端轴径向摩擦块；凹面朝轴，M3×8 顶压外侧 |
| 盘 A05-02 · P050（左肩／上臂/上叉） | `upperarm_l/C02` | 本步新取。十字关节叉臂；与另一叉臂正交穿装 |
| 盘 A05-06 · X008（左肩／上臂/上叉_传感板托夹） | `upperarm_l/C02_sensor_cassette` | 本步新取。固定传感 PCB；先滑入板，再装到关节 |
| 盘 A05-07 · X007（左肩／上臂/下叉_传感板托夹） | `upperarm_l/C01_sensor_cassette` | 本步新取。固定传感 PCB；先滑入板，再装到关节 |
| 盘 A05-08 · P052（左肩／上臂/上环盖） | `upperarm_l/C15` | 本步新取。十字关节上环盖；4 枚 M1.6×6 合环 |
| 盘 A05-09 · X053（左肩／上臂/P_活动半壳） | `upperarm_l/P_case_plus` | 本步新取。端轴可拆半壳；4 枚 M2×20 合壳 |
| 盘 A05-14 · P049（左肩／上臂/下叉） | `upperarm_l/C01` | 本步新取。十字关节叉臂；与另一叉臂正交穿装 |
| 盘 A05-16 · X057（左肩／上臂/D_活动半壳） | `upperarm_l/D_case_plus` | 本步新取。端轴可拆半壳；4 枚 M2×20 合壳 |
| 盘 A05-23 · P067（左肩／上臂/D_磁铁端盖） | `upperarm_l/D_magnet_cap` | 本步新取。端轴磁铁端盖；2 枚 M2×4 固定 |
| 盘 A05-24 · P062（左肩／上臂/P_磁铁端盖） | `upperarm_l/P_magnet_cap` | 本步新取。端轴磁铁端盖；2 枚 M2×4 固定 |
| 盘 A05-25 · N003（左肩／上臂/下叉_侧装磁铁座盖） | `upperarm_l/C01_magnet_cartridge` | 本步新取。侧面装入并粘固磁铁；旋转侧用 2 枚 M2×5 固定 |
| 盘 A05-26 · N003（左肩／上臂/上叉_侧装磁铁座盖） | `upperarm_l/C02_magnet_cartridge` | 本步新取。侧面装入并粘固磁铁；旋转侧用 2 枚 M2×5 固定 |

| 五金 / 磁铁 | 本步数量 | 位置 |
| --- | --- | --- |
| M4大平垫圈：外径12、厚1 mm，实物能自由套过Φ4光杆 | 8 | 旋转叉耳两侧，每个支点 2 片 |
| A8不锈钢碟簧：8×4.2×0.4，自由高0.6 mm | 8 | 每个轴肩支点 2 片，相对安装 |
| M4普通平垫圈：外径9、厚0.8 mm，实物通孔验证 | 4 | 螺钉头下、碟簧外侧，每个支点 1 片 |
| 轴肩螺钉 Φ4×8 / M3×0.5，螺纹长6 mm；头Φ7×3，内六角3 mm | 4 | 轴肩摩擦支点，铰链 1 处 / 十字核心 4 处 |
| M3普通六角螺母（不要锁紧螺母替代外形） | 8 | 轴肩捕获窝、板托夹固定点，以及有 P/D 端轴时的摩擦调节槽 |
| M3大平垫圈：外径9、厚0.8 mm，实物通孔验证 | 4 | 固定座内侧，每个支点 1 片反力垫 |
| M1.6×6 内六角圆柱头螺钉；按CAD头径/头高核对 | 4 | C14 / C15 合环 |
| M1.6普通六角螺母（不要锁紧螺母替代外形） | 4 | C14 / C15 合环螺钉对应捕获窝 |
| M2普通六角螺母（不要锁紧螺母替代外形） | 20 | 本步各 M2 螺钉对应捕获窝，一螺钉配一螺母 |
| M2×5 内六角圆柱头螺钉；按CAD头径/头高核对 | 4 | N003 / N004 侧装磁铁座盖，每个 2 枚 |
| 径向两极磁铁 Φ6×2.5 mm；直径方向充磁，不能买轴向充磁 | 4 | 本步每个实测轴 1 颗，位于对应磁铁座 / 端盖 |
| M3×8 内六角圆柱头螺钉；按CAD头径/头高核对 | 4 | 每只传感板托夹 1 枚；每个 P/D 摩擦块调节 1 枚 |
| M2×20 内六角圆柱头螺钉；按CAD头径/头高核对 | 8 | P / D 端轴固定半壳与活动半壳合壳 |
| M2×4 内六角圆柱头螺钉；按CAD头径/头高核对 | 4 | P / D 端轴的磁铁端盖 |
| M2×8 内六角圆柱头螺钉；按CAD头径/头高核对 | 4 | P / D 端轴的成对 PCB 板夹 |

1. 取 盘 A04-04 · P051（左肩／上臂/下环）、盘 A05-08 · P052（左肩／上臂/上环盖）。两叉分别是 盘 A05-14 · P049（左肩／上臂/下叉） 的 C01 部位、盘 A05-02 · P050（左肩／上臂/上叉） 的 C02 部位；已经连在骨架上的叉不要拆分或另找重复打印件。
2. 按 [G2](#G2) 先预装 4 枚 M3 螺母与 4 片 M3 反力垫，把两叉交叉放入环，再按 G1 装四套轴肩结构；随后用 4 枚 M1.6×6 + 4 枚 M1.6 螺母合环。
3. P 端按 [G3](#G3)：盘 A04-01 · X054（骨架／左锁骨） 内是一体固定半壳，容纳 盘 A05-14 · P049（左肩／上臂/下叉） 的圆轴与限位环；装 盘 A04-10 · P061（左肩／上臂/P_径向摩擦块），M3×8 + M3 螺母调摩擦。用 盘 A05-09 · X053（左肩／上臂/P_活动半壳） 和 4 枚 M2×20 + 4 枚 M2 螺母合壳。磁铁端盖用 2 枚 M2×4 + 2 枚 M2 螺母；两只 PCB 板夹用 2 枚 M2×8 + 2 枚 M2 螺母。
4. D 端按 [G3](#G3)：盘 A04-05 · X058（骨架／左肩／上臂） 内是一体固定半壳，容纳 盘 A05-02 · P050（左肩／上臂/上叉） 的圆轴与限位环；装 盘 A04-11 · P066（左肩／上臂/D_径向摩擦块），M3×8 + M3 螺母调摩擦。用 盘 A05-16 · X057（左肩／上臂/D_活动半壳） 和 4 枚 M2×20 + 4 枚 M2 螺母合壳。磁铁端盖用 2 枚 M2×4 + 2 枚 M2 螺母；两只 PCB 板夹用 2 枚 M2×8 + 2 枚 M2 螺母。
5. C01 测量端按 [G4](#G4)：盘 A05-25 · N003（左肩／上臂/下叉_侧装磁铁座盖） 内放 1 颗磁铁，用 2 枚 M2×5 + 2 枚 M2 螺母固定到叉臂端；盘 A05-07 · X007（左肩／上臂/下叉_传感板托夹） 先滑入传感板，再用 M3×8 + M3 螺母固定。
6. C02 测量端按 [G4](#G4)：盘 A05-26 · N003（左肩／上臂/上叉_侧装磁铁座盖） 内放 1 颗磁铁，用 2 枚 M2×5 + 2 枚 M2 螺母固定到叉臂端；盘 A05-06 · X008（左肩／上臂/上叉_传感板托夹） 先滑入传感板，再用 M3×8 + M3 螺母固定。
7. 局部慢慢活动，确认每一相邻活动面不挤压垫片、PCB 和线束。按需要的手感调保持力即可；当前可用行程由实物相邻件与线束决定，软件 raw_limits 不是要求你硬拧到的机械行程。

| 电路端口 / 中央板位号 | 测量轴 | 传感板装在 | 对应磁铁装在 | 每根线建议长度 |
| --- | --- | --- | --- | --- |
| 端口 B01 / J26 | `upperarm_l/r0` | 盘 A04-06 · X051（左肩／上臂/P_板夹_-14） + 盘 A04-09 · X052（左肩／上臂/P_板夹_+14） | 盘 A05-24 · P062（左肩／上臂/P_磁铁端盖） | 375 mm × 5 根，首件后定长 |
| 端口 B02 / J27 | `upperarm_l/r1` | 盘 A05-07 · X007（左肩／上臂/下叉_传感板托夹） | 盘 A05-25 · N003（左肩／上臂/下叉_侧装磁铁座盖） | 550 mm × 5 根，首件后定长 |
| 端口 B03 / J28 | `upperarm_l/r2` | 盘 A05-06 · X008（左肩／上臂/上叉_传感板托夹） | 盘 A05-26 · N003（左肩／上臂/上叉_侧装磁铁座盖） | 500 mm × 5 根，首件后定长 |
| 端口 B04 / J29 | `upperarm_l/r3` | 盘 A04-08 · X055（左肩／上臂/D_板夹_-14） + 盘 A04-07 · X056（左肩／上臂/D_板夹_+14） | 盘 A05-23 · P067（左肩／上臂/D_磁铁端盖） | 475 mm × 5 根，首件后定长 |

本步完成检查：B01、B02、B03、B04 标签对应正确；磁铁不相对载体打滑；转轴可手动摆动并保持；线先松放到背盒方向，留待走线章节统一固定。

### S07 · 左肘屈伸

连接 **盘 A04-05 · X058（骨架／左肩／上臂） → 盘 A04-03 · H004（骨架／左肘）**。本步需打开打印盘：A04、A05。

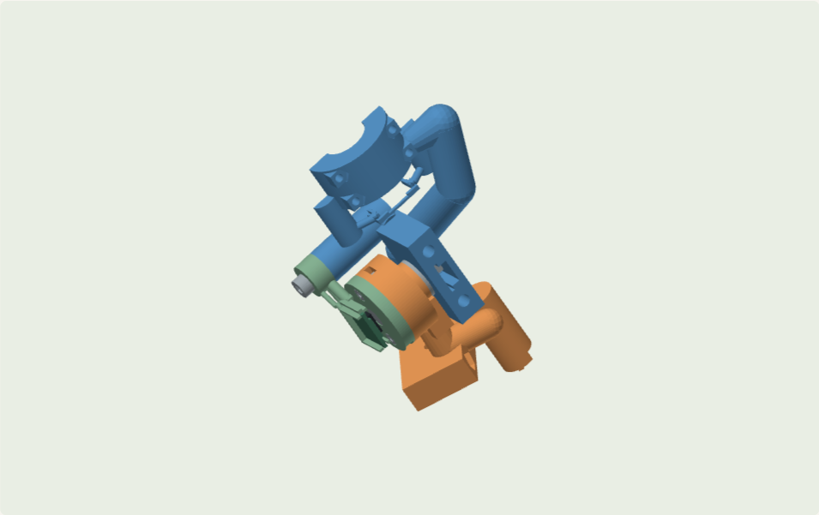
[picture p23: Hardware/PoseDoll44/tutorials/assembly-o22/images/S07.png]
S07 左肘屈伸 · CAD 装配位置；蓝色为父骨架，橙色为子骨架


| 取件位置 | 名称 / 原始键 | 本步用途 / 状态 |
| --- | --- | --- |
| 盘 A04-05 · X058（骨架／左肩／上臂） | `frame/upperarm_l` | 已在 S06 取用，直接使用已装骨架。一体骨架；已包含 左肩／上臂/D_固定半壳、左肘屈伸/固定侧关节座 |
| 盘 A04-03 · H004（骨架／左肘） | `frame/elbow_l` | 本步新取。一体骨架；已包含 左肘屈伸/旋转侧叉耳、左前臂扭转/固定侧关节座 |
| 盘 A05-18 · X021（左肘屈伸/传感板托夹） | `elbow_l.flex/sensor_cassette` | 本步新取。固定传感 PCB；先滑入板，再装到关节 |
| 盘 A05-20 · N004（左肘屈伸/侧装磁铁座盖） | `elbow_l.flex/magnet_cartridge` | 本步新取。侧面装入并粘固磁铁；旋转侧用 2 枚 M2×5 固定 |

| 五金 / 磁铁 | 本步数量 | 位置 |
| --- | --- | --- |
| M4大平垫圈：外径12、厚1 mm，实物能自由套过Φ4光杆 | 2 | 旋转叉耳两侧，每个支点 2 片 |
| A8不锈钢碟簧：8×4.2×0.4，自由高0.6 mm | 2 | 每个轴肩支点 2 片，相对安装 |
| M4普通平垫圈：外径9、厚0.8 mm，实物通孔验证 | 1 | 螺钉头下、碟簧外侧，每个支点 1 片 |
| 轴肩螺钉 Φ4×8 / M3×0.5，螺纹长6 mm；头Φ7×3，内六角3 mm | 1 | 轴肩摩擦支点，铰链 1 处 / 十字核心 4 处 |
| M3普通六角螺母（不要锁紧螺母替代外形） | 2 | 轴肩捕获窝、板托夹固定点，以及有 P/D 端轴时的摩擦调节槽 |
| M3大平垫圈：外径9、厚0.8 mm，实物通孔验证 | 1 | 固定座内侧，每个支点 1 片反力垫 |
| M3×8 内六角圆柱头螺钉；按CAD头径/头高核对 | 1 | 每只传感板托夹 1 枚；每个 P/D 摩擦块调节 1 枚 |
| M2普通六角螺母（不要锁紧螺母替代外形） | 2 | 本步各 M2 螺钉对应捕获窝，一螺钉配一螺母 |
| M2×5 内六角圆柱头螺钉；按CAD头径/头高核对 | 2 | N003 / N004 侧装磁铁座盖，每个 2 枚 |
| 径向两极磁铁 Φ6×2.5 mm；直径方向充磁，不能买轴向充磁 | 1 | 本步每个实测轴 1 颗，位于对应磁铁座 / 端盖 |

1. 将 盘 A04-05 · X058（骨架／左肩／上臂） 的固定关节座与 盘 A04-03 · H004（骨架／左肘） 的旋转叉耳摆到图示连接位置。侧槽尚未被挡住时，预装 1 枚 M3 螺母与 1 片 M3 反力垫。
2. 按 [G5 一体铰链](#G5) 和 [G1 轴肩层次](#G1) 装 1 套轴肩结构。单个支点为 1 枚轴肩螺钉、2 片 M4 大垫、2 片 A8 碟簧、1 片 M4 普通垫，外加刚才放入的螺母和反力垫。
3. 调整摩擦后，按 [G4](#G4) 给 盘 A05-20 · N004（左肘屈伸/侧装磁铁座盖） 装 1 颗磁铁，固化后用 2 枚 M2×5 + 2 枚 M2 螺母固定到旋转侧。
4. 把下表所列传感板装入 盘 A05-18 · X021（左肘屈伸/传感板托夹），再用 1 枚 M3×8 + 1 枚 M3 螺母固定到固定侧。传感器与磁铁相对，不能把两者都固定到同一旋转骨段。
5. 局部慢慢活动，确认每一相邻活动面不挤压垫片、PCB 和线束。按需要的手感调保持力即可；当前可用行程由实物相邻件与线束决定，软件 raw_limits 不是要求你硬拧到的机械行程。

| 电路端口 / 中央板位号 | 测量轴 | 传感板装在 | 对应磁铁装在 | 每根线建议长度 |
| --- | --- | --- | --- | --- |
| 端口 B05 / J30 | `elbow_l.flex/r0` | 盘 A05-18 · X021（左肘屈伸/传感板托夹） | 盘 A05-20 · N004（左肘屈伸/侧装磁铁座盖） | 500 mm × 5 根，首件后定长 |

本步完成检查：B05 标签对应正确；磁铁不相对载体打滑；转轴可手动摆动并保持；线先松放到背盒方向，留待走线章节统一固定。

### S08 · 左前臂扭转

连接 **盘 A04-03 · H004（骨架／左肘） → 盘 A05-03 · W004（骨架／左前臂）**。本步需打开打印盘：A04、A05。

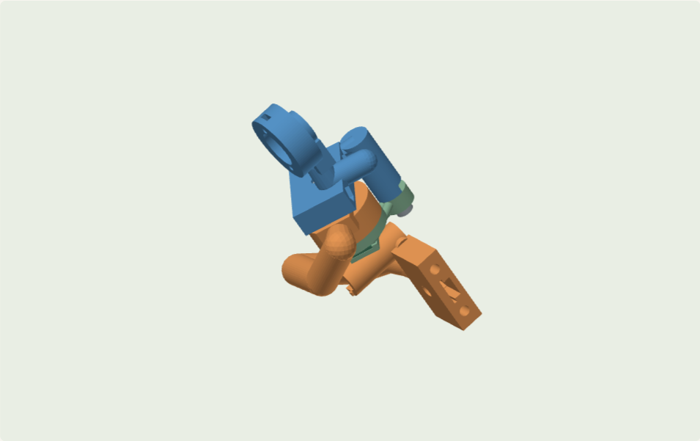
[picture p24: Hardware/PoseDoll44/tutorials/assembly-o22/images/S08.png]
S08 左前臂扭转 · CAD 装配位置；蓝色为父骨架，橙色为子骨架


| 取件位置 | 名称 / 原始键 | 本步用途 / 状态 |
| --- | --- | --- |
| 盘 A04-03 · H004（骨架／左肘） | `frame/elbow_l` | 已在 S07 取用，直接使用已装骨架。一体骨架；已包含 左肘屈伸/旋转侧叉耳、左前臂扭转/固定侧关节座 |
| 盘 A05-03 · W004（骨架／左前臂） | `frame/forearm_l` | 本步新取。一体骨架；已包含 左前臂扭转/旋转侧叉耳、左手腕屈伸/固定侧关节座 |
| 盘 A05-12 · N004（左前臂扭转/侧装磁铁座盖） | `forearm_l.twist/magnet_cartridge` | 本步新取。侧面装入并粘固磁铁；旋转侧用 2 枚 M2×5 固定 |
| 盘 A05-13 · X022（左前臂扭转/传感板托夹） | `forearm_l.twist/sensor_cassette` | 本步新取。固定传感 PCB；先滑入板，再装到关节 |

| 五金 / 磁铁 | 本步数量 | 位置 |
| --- | --- | --- |
| M4大平垫圈：外径12、厚1 mm，实物能自由套过Φ4光杆 | 2 | 旋转叉耳两侧，每个支点 2 片 |
| A8不锈钢碟簧：8×4.2×0.4，自由高0.6 mm | 2 | 每个轴肩支点 2 片，相对安装 |
| M4普通平垫圈：外径9、厚0.8 mm，实物通孔验证 | 1 | 螺钉头下、碟簧外侧，每个支点 1 片 |
| 轴肩螺钉 Φ4×8 / M3×0.5，螺纹长6 mm；头Φ7×3，内六角3 mm | 1 | 轴肩摩擦支点，铰链 1 处 / 十字核心 4 处 |
| M3普通六角螺母（不要锁紧螺母替代外形） | 2 | 轴肩捕获窝、板托夹固定点，以及有 P/D 端轴时的摩擦调节槽 |
| M3大平垫圈：外径9、厚0.8 mm，实物通孔验证 | 1 | 固定座内侧，每个支点 1 片反力垫 |
| M3×8 内六角圆柱头螺钉；按CAD头径/头高核对 | 1 | 每只传感板托夹 1 枚；每个 P/D 摩擦块调节 1 枚 |
| M2普通六角螺母（不要锁紧螺母替代外形） | 2 | 本步各 M2 螺钉对应捕获窝，一螺钉配一螺母 |
| M2×5 内六角圆柱头螺钉；按CAD头径/头高核对 | 2 | N003 / N004 侧装磁铁座盖，每个 2 枚 |
| 径向两极磁铁 Φ6×2.5 mm；直径方向充磁，不能买轴向充磁 | 1 | 本步每个实测轴 1 颗，位于对应磁铁座 / 端盖 |

1. 将 盘 A04-03 · H004（骨架／左肘） 的固定关节座与 盘 A05-03 · W004（骨架／左前臂） 的旋转叉耳摆到图示连接位置。侧槽尚未被挡住时，预装 1 枚 M3 螺母与 1 片 M3 反力垫。
2. 按 [G5 一体铰链](#G5) 和 [G1 轴肩层次](#G1) 装 1 套轴肩结构。单个支点为 1 枚轴肩螺钉、2 片 M4 大垫、2 片 A8 碟簧、1 片 M4 普通垫，外加刚才放入的螺母和反力垫。
3. 调整摩擦后，按 [G4](#G4) 给 盘 A05-12 · N004（左前臂扭转/侧装磁铁座盖） 装 1 颗磁铁，固化后用 2 枚 M2×5 + 2 枚 M2 螺母固定到旋转侧。
4. 把下表所列传感板装入 盘 A05-13 · X022（左前臂扭转/传感板托夹），再用 1 枚 M3×8 + 1 枚 M3 螺母固定到固定侧。传感器与磁铁相对，不能把两者都固定到同一旋转骨段。
5. 局部慢慢活动，确认每一相邻活动面不挤压垫片、PCB 和线束。按需要的手感调保持力即可；当前可用行程由实物相邻件与线束决定，软件 raw_limits 不是要求你硬拧到的机械行程。

| 电路端口 / 中央板位号 | 测量轴 | 传感板装在 | 对应磁铁装在 | 每根线建议长度 |
| --- | --- | --- | --- | --- |
| 端口 B06 / J31 | `forearm_l.twist/r0` | 盘 A05-13 · X022（左前臂扭转/传感板托夹） | 盘 A05-12 · N004（左前臂扭转/侧装磁铁座盖） | 550 mm × 5 根，首件后定长 |

本步完成检查：B06 标签对应正确；磁铁不相对载体打滑；转轴可手动摆动并保持；线先松放到背盒方向，留待走线章节统一固定。

### S09 · 左手腕屈伸

连接 **盘 A05-03 · W004（骨架／左前臂） → 盘 A05-01 · H006（骨架／左腕屈伸中间架）**。本步需打开打印盘：A05。

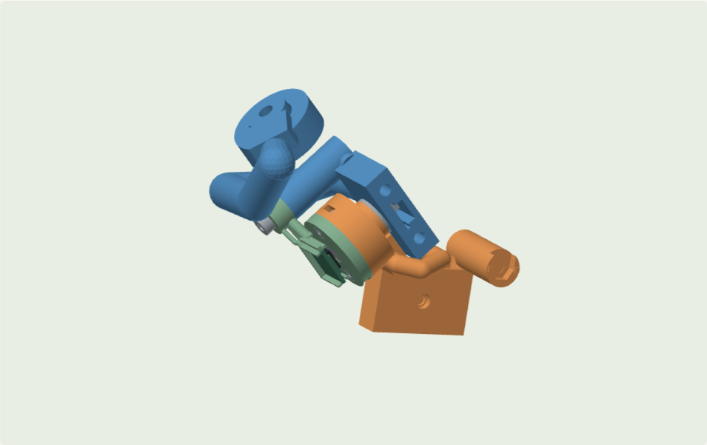
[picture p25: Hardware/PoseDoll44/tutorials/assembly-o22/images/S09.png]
S09 左手腕屈伸 · CAD 装配位置；蓝色为父骨架，橙色为子骨架


| 取件位置 | 名称 / 原始键 | 本步用途 / 状态 |
| --- | --- | --- |
| 盘 A05-03 · W004（骨架／左前臂） | `frame/forearm_l` | 已在 S08 取用，直接使用已装骨架。一体骨架；已包含 左前臂扭转/旋转侧叉耳、左手腕屈伸/固定侧关节座 |
| 盘 A05-01 · H006（骨架／左腕屈伸中间架） | `frame/hand_l.flex_frame` | 本步新取。一体骨架；已包含 左手腕屈伸/旋转侧叉耳、左手腕侧摆/固定侧关节座 |
| 盘 A05-17 · N004（左手腕屈伸/侧装磁铁座盖） | `hand_l.flex/magnet_cartridge` | 本步新取。侧面装入并粘固磁铁；旋转侧用 2 枚 M2×5 固定 |
| 盘 A05-21 · X023（左手腕屈伸/传感板托夹） | `hand_l.flex/sensor_cassette` | 本步新取。固定传感 PCB；先滑入板，再装到关节 |

| 五金 / 磁铁 | 本步数量 | 位置 |
| --- | --- | --- |
| M4大平垫圈：外径12、厚1 mm，实物能自由套过Φ4光杆 | 2 | 旋转叉耳两侧，每个支点 2 片 |
| A8不锈钢碟簧：8×4.2×0.4，自由高0.6 mm | 2 | 每个轴肩支点 2 片，相对安装 |
| M4普通平垫圈：外径9、厚0.8 mm，实物通孔验证 | 1 | 螺钉头下、碟簧外侧，每个支点 1 片 |
| 轴肩螺钉 Φ4×8 / M3×0.5，螺纹长6 mm；头Φ7×3，内六角3 mm | 1 | 轴肩摩擦支点，铰链 1 处 / 十字核心 4 处 |
| M3普通六角螺母（不要锁紧螺母替代外形） | 2 | 轴肩捕获窝、板托夹固定点，以及有 P/D 端轴时的摩擦调节槽 |
| M3大平垫圈：外径9、厚0.8 mm，实物通孔验证 | 1 | 固定座内侧，每个支点 1 片反力垫 |
| M3×8 内六角圆柱头螺钉；按CAD头径/头高核对 | 1 | 每只传感板托夹 1 枚；每个 P/D 摩擦块调节 1 枚 |
| M2普通六角螺母（不要锁紧螺母替代外形） | 2 | 本步各 M2 螺钉对应捕获窝，一螺钉配一螺母 |
| M2×5 内六角圆柱头螺钉；按CAD头径/头高核对 | 2 | N003 / N004 侧装磁铁座盖，每个 2 枚 |
| 径向两极磁铁 Φ6×2.5 mm；直径方向充磁，不能买轴向充磁 | 1 | 本步每个实测轴 1 颗，位于对应磁铁座 / 端盖 |

1. 将 盘 A05-03 · W004（骨架／左前臂） 的固定关节座与 盘 A05-01 · H006（骨架／左腕屈伸中间架） 的旋转叉耳摆到图示连接位置。侧槽尚未被挡住时，预装 1 枚 M3 螺母与 1 片 M3 反力垫。
2. 按 [G5 一体铰链](#G5) 和 [G1 轴肩层次](#G1) 装 1 套轴肩结构。单个支点为 1 枚轴肩螺钉、2 片 M4 大垫、2 片 A8 碟簧、1 片 M4 普通垫，外加刚才放入的螺母和反力垫。
3. 调整摩擦后，按 [G4](#G4) 给 盘 A05-17 · N004（左手腕屈伸/侧装磁铁座盖） 装 1 颗磁铁，固化后用 2 枚 M2×5 + 2 枚 M2 螺母固定到旋转侧。
4. 把下表所列传感板装入 盘 A05-21 · X023（左手腕屈伸/传感板托夹），再用 1 枚 M3×8 + 1 枚 M3 螺母固定到固定侧。传感器与磁铁相对，不能把两者都固定到同一旋转骨段。
5. 局部慢慢活动，确认每一相邻活动面不挤压垫片、PCB 和线束。按需要的手感调保持力即可；当前可用行程由实物相邻件与线束决定，软件 raw_limits 不是要求你硬拧到的机械行程。

| 电路端口 / 中央板位号 | 测量轴 | 传感板装在 | 对应磁铁装在 | 每根线建议长度 |
| --- | --- | --- | --- | --- |
| 端口 B07 / J32 | `hand_l.flex/r0` | 盘 A05-21 · X023（左手腕屈伸/传感板托夹） | 盘 A05-17 · N004（左手腕屈伸/侧装磁铁座盖） | 625 mm × 5 根，首件后定长 |

本步完成检查：B07 标签对应正确；磁铁不相对载体打滑；转轴可手动摆动并保持；线先松放到背盒方向，留待走线章节统一固定。

### S10 · 左手腕侧摆

连接 **盘 A05-01 · H006（骨架／左腕屈伸中间架） → 盘 A05-04 · P191（骨架／左手腕）**。本步需打开打印盘：A05。

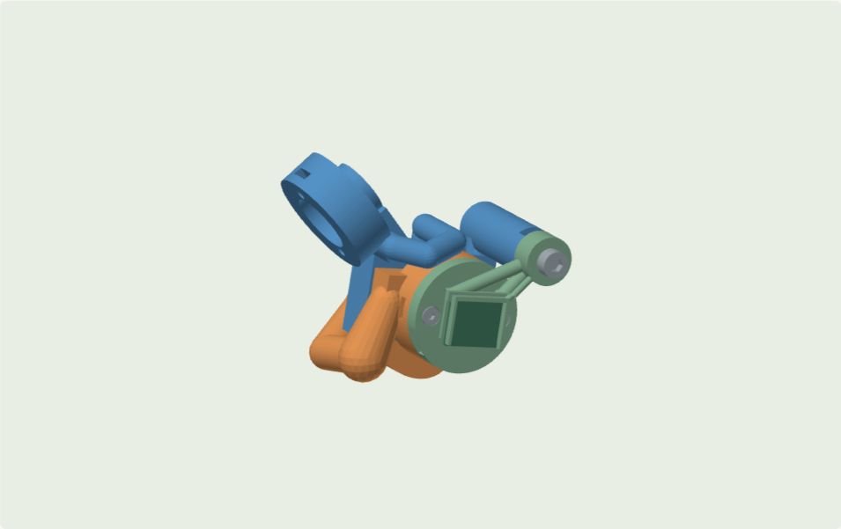
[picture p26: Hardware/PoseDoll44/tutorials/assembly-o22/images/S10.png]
S10 左手腕侧摆 · CAD 装配位置；蓝色为父骨架，橙色为子骨架


| 取件位置 | 名称 / 原始键 | 本步用途 / 状态 |
| --- | --- | --- |
| 盘 A05-01 · H006（骨架／左腕屈伸中间架） | `frame/hand_l.flex_frame` | 已在 S09 取用，直接使用已装骨架。一体骨架；已包含 左手腕屈伸/旋转侧叉耳、左手腕侧摆/固定侧关节座 |
| 盘 A05-04 · P191（骨架／左手腕） | `frame/hand_l` | 本步新取。一体骨架；已包含 左手腕侧摆/旋转侧叉耳 |
| 盘 A05-11 · N004（左手腕侧摆/侧装磁铁座盖） | `hand_l.deviate/magnet_cartridge` | 本步新取。侧面装入并粘固磁铁；旋转侧用 2 枚 M2×5 固定 |
| 盘 A05-15 · X024（左手腕侧摆/传感板托夹） | `hand_l.deviate/sensor_cassette` | 本步新取。固定传感 PCB；先滑入板，再装到关节 |

| 五金 / 磁铁 | 本步数量 | 位置 |
| --- | --- | --- |
| M4大平垫圈：外径12、厚1 mm，实物能自由套过Φ4光杆 | 2 | 旋转叉耳两侧，每个支点 2 片 |
| A8不锈钢碟簧：8×4.2×0.4，自由高0.6 mm | 2 | 每个轴肩支点 2 片，相对安装 |
| M4普通平垫圈：外径9、厚0.8 mm，实物通孔验证 | 1 | 螺钉头下、碟簧外侧，每个支点 1 片 |
| 轴肩螺钉 Φ4×8 / M3×0.5，螺纹长6 mm；头Φ7×3，内六角3 mm | 1 | 轴肩摩擦支点，铰链 1 处 / 十字核心 4 处 |
| M3普通六角螺母（不要锁紧螺母替代外形） | 2 | 轴肩捕获窝、板托夹固定点，以及有 P/D 端轴时的摩擦调节槽 |
| M3大平垫圈：外径9、厚0.8 mm，实物通孔验证 | 1 | 固定座内侧，每个支点 1 片反力垫 |
| M3×8 内六角圆柱头螺钉；按CAD头径/头高核对 | 1 | 每只传感板托夹 1 枚；每个 P/D 摩擦块调节 1 枚 |
| M2普通六角螺母（不要锁紧螺母替代外形） | 2 | 本步各 M2 螺钉对应捕获窝，一螺钉配一螺母 |
| M2×5 内六角圆柱头螺钉；按CAD头径/头高核对 | 2 | N003 / N004 侧装磁铁座盖，每个 2 枚 |
| 径向两极磁铁 Φ6×2.5 mm；直径方向充磁，不能买轴向充磁 | 1 | 本步每个实测轴 1 颗，位于对应磁铁座 / 端盖 |

1. 将 盘 A05-01 · H006（骨架／左腕屈伸中间架） 的固定关节座与 盘 A05-04 · P191（骨架／左手腕） 的旋转叉耳摆到图示连接位置。侧槽尚未被挡住时，预装 1 枚 M3 螺母与 1 片 M3 反力垫。
2. 按 [G5 一体铰链](#G5) 和 [G1 轴肩层次](#G1) 装 1 套轴肩结构。单个支点为 1 枚轴肩螺钉、2 片 M4 大垫、2 片 A8 碟簧、1 片 M4 普通垫，外加刚才放入的螺母和反力垫。
3. 调整摩擦后，按 [G4](#G4) 给 盘 A05-11 · N004（左手腕侧摆/侧装磁铁座盖） 装 1 颗磁铁，固化后用 2 枚 M2×5 + 2 枚 M2 螺母固定到旋转侧。
4. 把下表所列传感板装入 盘 A05-15 · X024（左手腕侧摆/传感板托夹），再用 1 枚 M3×8 + 1 枚 M3 螺母固定到固定侧。传感器与磁铁相对，不能把两者都固定到同一旋转骨段。
5. 局部慢慢活动，确认每一相邻活动面不挤压垫片、PCB 和线束。按需要的手感调保持力即可；当前可用行程由实物相邻件与线束决定，软件 raw_limits 不是要求你硬拧到的机械行程。

| 电路端口 / 中央板位号 | 测量轴 | 传感板装在 | 对应磁铁装在 | 每根线建议长度 |
| --- | --- | --- | --- | --- |
| 端口 B08 / J33 | `hand_l.deviate/r0` | 盘 A05-15 · X024（左手腕侧摆/传感板托夹） | 盘 A05-11 · N004（左手腕侧摆/侧装磁铁座盖） | 675 mm × 5 根，首件后定长 |

本步完成检查：B08 标签对应正确；磁铁不相对载体打滑；转轴可手动摆动并保持；线先松放到背盒方向，留待走线章节统一固定。

### S11 · 右锁骨前后

连接 **盘 A02-01 · X046（骨架／胸部） → 盘 A06-01 · H008（骨架／右锁骨前后中间架）**。本步需打开打印盘：A02、A06、A07。

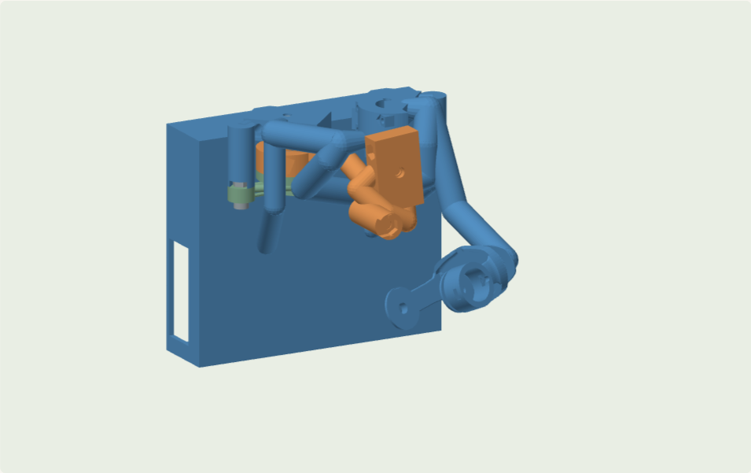
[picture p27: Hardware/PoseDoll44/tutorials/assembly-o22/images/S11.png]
S11 右锁骨前后 · CAD 装配位置；蓝色为父骨架，橙色为子骨架


| 取件位置 | 名称 / 原始键 | 本步用途 / 状态 |
| --- | --- | --- |
| 盘 A02-01 · X046（骨架／胸部） | `frame/chest` | 已在 S02 取用，直接使用已装骨架。一体骨架；已包含 胸部/上叉、头颈/P_固定半壳、左锁骨前后/固定侧关节座、右锁骨前后/固定侧关节座 |
| 盘 A06-01 · H008（骨架／右锁骨前后中间架） | `frame/clavicle_r.protract_frame` | 本步新取。一体骨架；已包含 右锁骨前后/旋转侧叉耳、右锁骨升降/固定侧关节座 |
| 盘 A07-02 · X027（右锁骨前后/传感板托夹） | `clavicle_r.protract/sensor_cassette` | 本步新取。固定传感 PCB；先滑入板，再装到关节 |
| 盘 A07-08 · N004（右锁骨前后/侧装磁铁座盖） | `clavicle_r.protract/magnet_cartridge` | 本步新取。侧面装入并粘固磁铁；旋转侧用 2 枚 M2×5 固定 |

| 五金 / 磁铁 | 本步数量 | 位置 |
| --- | --- | --- |
| M4大平垫圈：外径12、厚1 mm，实物能自由套过Φ4光杆 | 2 | 旋转叉耳两侧，每个支点 2 片 |
| A8不锈钢碟簧：8×4.2×0.4，自由高0.6 mm | 2 | 每个轴肩支点 2 片，相对安装 |
| M4普通平垫圈：外径9、厚0.8 mm，实物通孔验证 | 1 | 螺钉头下、碟簧外侧，每个支点 1 片 |
| 轴肩螺钉 Φ4×8 / M3×0.5，螺纹长6 mm；头Φ7×3，内六角3 mm | 1 | 轴肩摩擦支点，铰链 1 处 / 十字核心 4 处 |
| M3普通六角螺母（不要锁紧螺母替代外形） | 2 | 轴肩捕获窝、板托夹固定点，以及有 P/D 端轴时的摩擦调节槽 |
| M3大平垫圈：外径9、厚0.8 mm，实物通孔验证 | 1 | 固定座内侧，每个支点 1 片反力垫 |
| M3×8 内六角圆柱头螺钉；按CAD头径/头高核对 | 1 | 每只传感板托夹 1 枚；每个 P/D 摩擦块调节 1 枚 |
| M2普通六角螺母（不要锁紧螺母替代外形） | 2 | 本步各 M2 螺钉对应捕获窝，一螺钉配一螺母 |
| M2×5 内六角圆柱头螺钉；按CAD头径/头高核对 | 2 | N003 / N004 侧装磁铁座盖，每个 2 枚 |
| 径向两极磁铁 Φ6×2.5 mm；直径方向充磁，不能买轴向充磁 | 1 | 本步每个实测轴 1 颗，位于对应磁铁座 / 端盖 |

1. 将 盘 A02-01 · X046（骨架／胸部） 的固定关节座与 盘 A06-01 · H008（骨架／右锁骨前后中间架） 的旋转叉耳摆到图示连接位置。侧槽尚未被挡住时，预装 1 枚 M3 螺母与 1 片 M3 反力垫。
2. 按 [G5 一体铰链](#G5) 和 [G1 轴肩层次](#G1) 装 1 套轴肩结构。单个支点为 1 枚轴肩螺钉、2 片 M4 大垫、2 片 A8 碟簧、1 片 M4 普通垫，外加刚才放入的螺母和反力垫。
3. 调整摩擦后，按 [G4](#G4) 给 盘 A07-08 · N004（右锁骨前后/侧装磁铁座盖） 装 1 颗磁铁，固化后用 2 枚 M2×5 + 2 枚 M2 螺母固定到旋转侧。
4. 把下表所列传感板装入 盘 A07-02 · X027（右锁骨前后/传感板托夹），再用 1 枚 M3×8 + 1 枚 M3 螺母固定到固定侧。传感器与磁铁相对，不能把两者都固定到同一旋转骨段。
5. 局部慢慢活动，确认每一相邻活动面不挤压垫片、PCB 和线束。按需要的手感调保持力即可；当前可用行程由实物相邻件与线束决定，软件 raw_limits 不是要求你硬拧到的机械行程。

| 电路端口 / 中央板位号 | 测量轴 | 传感板装在 | 对应磁铁装在 | 每根线建议长度 |
| --- | --- | --- | --- | --- |
| 端口 A13 / J22 | `clavicle_r.protract/r0` | 盘 A07-02 · X027（右锁骨前后/传感板托夹） | 盘 A07-08 · N004（右锁骨前后/侧装磁铁座盖） | 200 mm × 5 根，首件后定长 |

本步完成检查：A13 标签对应正确；磁铁不相对载体打滑；转轴可手动摆动并保持；线先松放到背盒方向，留待走线章节统一固定。

### S12 · 右锁骨升降

连接 **盘 A06-01 · H008（骨架／右锁骨前后中间架） → 盘 A06-04 · X062（骨架／右锁骨）**。本步需打开打印盘：A06、A07。

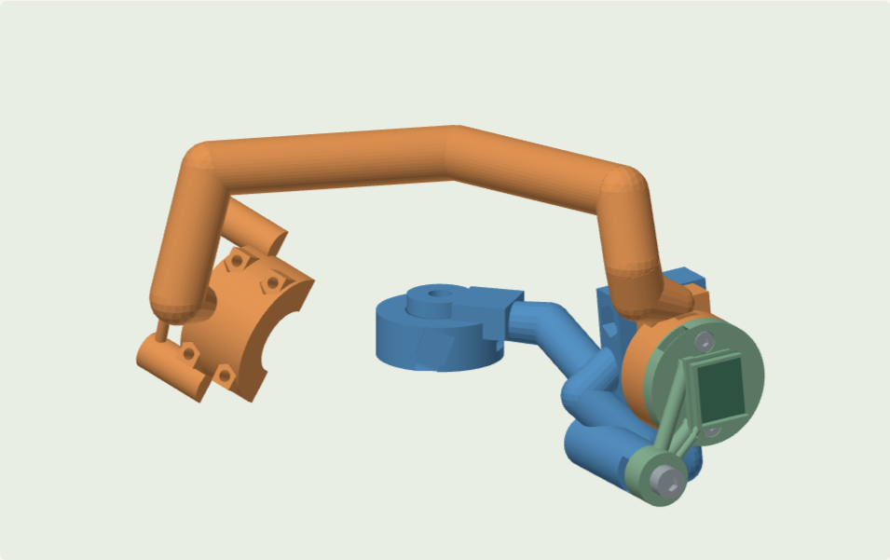
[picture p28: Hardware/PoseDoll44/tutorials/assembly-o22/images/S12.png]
S12 右锁骨升降 · CAD 装配位置；蓝色为父骨架，橙色为子骨架


| 取件位置 | 名称 / 原始键 | 本步用途 / 状态 |
| --- | --- | --- |
| 盘 A06-01 · H008（骨架／右锁骨前后中间架） | `frame/clavicle_r.protract_frame` | 已在 S11 取用，直接使用已装骨架。一体骨架；已包含 右锁骨前后/旋转侧叉耳、右锁骨升降/固定侧关节座 |
| 盘 A06-04 · X062（骨架／右锁骨） | `frame/clavicle_r` | 本步新取。一体骨架；已包含 右肩／上臂/P_固定半壳、右锁骨升降/旋转侧叉耳 |
| 盘 A06-12 · X028（右锁骨升降/传感板托夹） | `clavicle_r.elevate/sensor_cassette` | 本步新取。固定传感 PCB；先滑入板，再装到关节 |
| 盘 A07-11 · N004（右锁骨升降/侧装磁铁座盖） | `clavicle_r.elevate/magnet_cartridge` | 本步新取。侧面装入并粘固磁铁；旋转侧用 2 枚 M2×5 固定 |

| 五金 / 磁铁 | 本步数量 | 位置 |
| --- | --- | --- |
| M4大平垫圈：外径12、厚1 mm，实物能自由套过Φ4光杆 | 2 | 旋转叉耳两侧，每个支点 2 片 |
| A8不锈钢碟簧：8×4.2×0.4，自由高0.6 mm | 2 | 每个轴肩支点 2 片，相对安装 |
| M4普通平垫圈：外径9、厚0.8 mm，实物通孔验证 | 1 | 螺钉头下、碟簧外侧，每个支点 1 片 |
| 轴肩螺钉 Φ4×8 / M3×0.5，螺纹长6 mm；头Φ7×3，内六角3 mm | 1 | 轴肩摩擦支点，铰链 1 处 / 十字核心 4 处 |
| M3普通六角螺母（不要锁紧螺母替代外形） | 2 | 轴肩捕获窝、板托夹固定点，以及有 P/D 端轴时的摩擦调节槽 |
| M3大平垫圈：外径9、厚0.8 mm，实物通孔验证 | 1 | 固定座内侧，每个支点 1 片反力垫 |
| M3×8 内六角圆柱头螺钉；按CAD头径/头高核对 | 1 | 每只传感板托夹 1 枚；每个 P/D 摩擦块调节 1 枚 |
| M2普通六角螺母（不要锁紧螺母替代外形） | 2 | 本步各 M2 螺钉对应捕获窝，一螺钉配一螺母 |
| M2×5 内六角圆柱头螺钉；按CAD头径/头高核对 | 2 | N003 / N004 侧装磁铁座盖，每个 2 枚 |
| 径向两极磁铁 Φ6×2.5 mm；直径方向充磁，不能买轴向充磁 | 1 | 本步每个实测轴 1 颗，位于对应磁铁座 / 端盖 |

1. 将 盘 A06-01 · H008（骨架／右锁骨前后中间架） 的固定关节座与 盘 A06-04 · X062（骨架／右锁骨） 的旋转叉耳摆到图示连接位置。侧槽尚未被挡住时，预装 1 枚 M3 螺母与 1 片 M3 反力垫。
2. 按 [G5 一体铰链](#G5) 和 [G1 轴肩层次](#G1) 装 1 套轴肩结构。单个支点为 1 枚轴肩螺钉、2 片 M4 大垫、2 片 A8 碟簧、1 片 M4 普通垫，外加刚才放入的螺母和反力垫。
3. 调整摩擦后，按 [G4](#G4) 给 盘 A07-11 · N004（右锁骨升降/侧装磁铁座盖） 装 1 颗磁铁，固化后用 2 枚 M2×5 + 2 枚 M2 螺母固定到旋转侧。
4. 把下表所列传感板装入 盘 A06-12 · X028（右锁骨升降/传感板托夹），再用 1 枚 M3×8 + 1 枚 M3 螺母固定到固定侧。传感器与磁铁相对，不能把两者都固定到同一旋转骨段。
5. 局部慢慢活动，确认每一相邻活动面不挤压垫片、PCB 和线束。按需要的手感调保持力即可；当前可用行程由实物相邻件与线束决定，软件 raw_limits 不是要求你硬拧到的机械行程。

| 电路端口 / 中央板位号 | 测量轴 | 传感板装在 | 对应磁铁装在 | 每根线建议长度 |
| --- | --- | --- | --- | --- |
| 端口 A14 / J23 | `clavicle_r.elevate/r0` | 盘 A06-12 · X028（右锁骨升降/传感板托夹） | 盘 A07-11 · N004（右锁骨升降/侧装磁铁座盖） | 275 mm × 5 根，首件后定长 |

本步完成检查：A14 标签对应正确；磁铁不相对载体打滑；转轴可手动摆动并保持；线先松放到背盒方向，留待走线章节统一固定。

### S13 · 右肩／上臂

连接 **盘 A06-04 · X062（骨架／右锁骨） → 盘 A06-05 · X066（骨架／右肩／上臂）**。本步需打开打印盘：A06、A07。

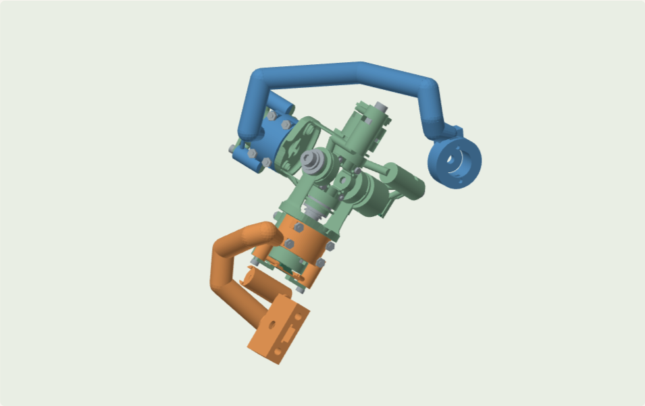
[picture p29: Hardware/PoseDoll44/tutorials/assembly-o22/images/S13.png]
S13 右肩／上臂 · CAD 装配位置；蓝色为父骨架，橙色为子骨架


| 取件位置 | 名称 / 原始键 | 本步用途 / 状态 |
| --- | --- | --- |
| 盘 A06-04 · X062（骨架／右锁骨） | `frame/clavicle_r` | 已在 S12 取用，直接使用已装骨架。一体骨架；已包含 右肩／上臂/P_固定半壳、右锁骨升降/旋转侧叉耳 |
| 盘 A06-05 · X066（骨架／右肩／上臂） | `frame/upperarm_r` | 本步新取。一体骨架；已包含 右肩／上臂/D_固定半壳、右肘屈伸/固定侧关节座 |
| 盘 A06-06 · P071（右肩／上臂/下叉） | `upperarm_r/C01` | 本步新取。十字关节叉臂；与另一叉臂正交穿装 |
| 盘 A06-07 · X061（右肩／上臂/P_活动半壳） | `upperarm_r/P_case_plus` | 本步新取。端轴可拆半壳；4 枚 M2×20 合壳 |
| 盘 A06-08 · X065（右肩／上臂/D_活动半壳） | `upperarm_r/D_case_plus` | 本步新取。端轴可拆半壳；4 枚 M2×20 合壳 |
| 盘 A06-09 · P073（右肩／上臂/下环） | `upperarm_r/C14` | 本步新取。十字关节下环；先装内部螺母和 M3 反力垫 |
| 盘 A06-13 · X009（右肩／上臂/下叉_传感板托夹） | `upperarm_r/C01_sensor_cassette` | 本步新取。固定传感 PCB；先滑入板，再装到关节 |
| 盘 A07-05 · X010（右肩／上臂/上叉_传感板托夹） | `upperarm_r/C02_sensor_cassette` | 本步新取。固定传感 PCB；先滑入板，再装到关节 |
| 盘 A07-07 · P074（右肩／上臂/上环盖） | `upperarm_r/C15` | 本步新取。十字关节上环盖；4 枚 M1.6×6 合环 |
| 盘 A07-09 · P072（右肩／上臂/上叉） | `upperarm_r/C02` | 本步新取。十字关节叉臂；与另一叉臂正交穿装 |
| 盘 A07-13 · P084（右肩／上臂/P_磁铁端盖） | `upperarm_r/P_magnet_cap` | 本步新取。端轴磁铁端盖；2 枚 M2×4 固定 |
| 盘 A07-15 · P089（右肩／上臂/D_磁铁端盖） | `upperarm_r/D_magnet_cap` | 本步新取。端轴磁铁端盖；2 枚 M2×4 固定 |
| 盘 A07-16 · N003（右肩／上臂/下叉_侧装磁铁座盖） | `upperarm_r/C01_magnet_cartridge` | 本步新取。侧面装入并粘固磁铁；旋转侧用 2 枚 M2×5 固定 |
| 盘 A07-17 · N003（右肩／上臂/上叉_侧装磁铁座盖） | `upperarm_r/C02_magnet_cartridge` | 本步新取。侧面装入并粘固磁铁；旋转侧用 2 枚 M2×5 固定 |
| 盘 A07-18 · X063（右肩／上臂/D_板夹_-14） | `upperarm_r/D_pcb_clip_-14` | 本步新取。端轴传感 PCB 的一侧板夹，与另一板夹成对使用 |
| 盘 A07-19 · X059（右肩／上臂/P_板夹_-14） | `upperarm_r/P_pcb_clip_-14` | 本步新取。端轴传感 PCB 的一侧板夹，与另一板夹成对使用 |
| 盘 A07-20 · X064（右肩／上臂/D_板夹_+14） | `upperarm_r/D_pcb_clip_+14` | 本步新取。端轴传感 PCB 的一侧板夹，与另一板夹成对使用 |
| 盘 A07-21 · X060（右肩／上臂/P_板夹_+14） | `upperarm_r/P_pcb_clip_+14` | 本步新取。端轴传感 PCB 的一侧板夹，与另一板夹成对使用 |
| 盘 A07-22 · P083（右肩／上臂/P_径向摩擦块） | `upperarm_r/P_radial_pad` | 本步新取。端轴径向摩擦块；凹面朝轴，M3×8 顶压外侧 |
| 盘 A07-23 · P088（右肩／上臂/D_径向摩擦块） | `upperarm_r/D_radial_pad` | 本步新取。端轴径向摩擦块；凹面朝轴，M3×8 顶压外侧 |

| 五金 / 磁铁 | 本步数量 | 位置 |
| --- | --- | --- |
| M4大平垫圈：外径12、厚1 mm，实物能自由套过Φ4光杆 | 8 | 旋转叉耳两侧，每个支点 2 片 |
| A8不锈钢碟簧：8×4.2×0.4，自由高0.6 mm | 8 | 每个轴肩支点 2 片，相对安装 |
| M4普通平垫圈：外径9、厚0.8 mm，实物通孔验证 | 4 | 螺钉头下、碟簧外侧，每个支点 1 片 |
| 轴肩螺钉 Φ4×8 / M3×0.5，螺纹长6 mm；头Φ7×3，内六角3 mm | 4 | 轴肩摩擦支点，铰链 1 处 / 十字核心 4 处 |
| M3普通六角螺母（不要锁紧螺母替代外形） | 8 | 轴肩捕获窝、板托夹固定点，以及有 P/D 端轴时的摩擦调节槽 |
| M3大平垫圈：外径9、厚0.8 mm，实物通孔验证 | 4 | 固定座内侧，每个支点 1 片反力垫 |
| M1.6×6 内六角圆柱头螺钉；按CAD头径/头高核对 | 4 | C14 / C15 合环 |
| M1.6普通六角螺母（不要锁紧螺母替代外形） | 4 | C14 / C15 合环螺钉对应捕获窝 |
| M2普通六角螺母（不要锁紧螺母替代外形） | 20 | 本步各 M2 螺钉对应捕获窝，一螺钉配一螺母 |
| M2×5 内六角圆柱头螺钉；按CAD头径/头高核对 | 4 | N003 / N004 侧装磁铁座盖，每个 2 枚 |
| 径向两极磁铁 Φ6×2.5 mm；直径方向充磁，不能买轴向充磁 | 4 | 本步每个实测轴 1 颗，位于对应磁铁座 / 端盖 |
| M3×8 内六角圆柱头螺钉；按CAD头径/头高核对 | 4 | 每只传感板托夹 1 枚；每个 P/D 摩擦块调节 1 枚 |
| M2×20 内六角圆柱头螺钉；按CAD头径/头高核对 | 8 | P / D 端轴固定半壳与活动半壳合壳 |
| M2×4 内六角圆柱头螺钉；按CAD头径/头高核对 | 4 | P / D 端轴的磁铁端盖 |
| M2×8 内六角圆柱头螺钉；按CAD头径/头高核对 | 4 | P / D 端轴的成对 PCB 板夹 |

1. 取 盘 A06-09 · P073（右肩／上臂/下环）、盘 A07-07 · P074（右肩／上臂/上环盖）。两叉分别是 盘 A06-06 · P071（右肩／上臂/下叉） 的 C01 部位、盘 A07-09 · P072（右肩／上臂/上叉） 的 C02 部位；已经连在骨架上的叉不要拆分或另找重复打印件。
2. 按 [G2](#G2) 先预装 4 枚 M3 螺母与 4 片 M3 反力垫，把两叉交叉放入环，再按 G1 装四套轴肩结构；随后用 4 枚 M1.6×6 + 4 枚 M1.6 螺母合环。
3. P 端按 [G3](#G3)：盘 A06-04 · X062（骨架／右锁骨） 内是一体固定半壳，容纳 盘 A06-06 · P071（右肩／上臂/下叉） 的圆轴与限位环；装 盘 A07-22 · P083（右肩／上臂/P_径向摩擦块），M3×8 + M3 螺母调摩擦。用 盘 A06-07 · X061（右肩／上臂/P_活动半壳） 和 4 枚 M2×20 + 4 枚 M2 螺母合壳。磁铁端盖用 2 枚 M2×4 + 2 枚 M2 螺母；两只 PCB 板夹用 2 枚 M2×8 + 2 枚 M2 螺母。
4. D 端按 [G3](#G3)：盘 A06-05 · X066（骨架／右肩／上臂） 内是一体固定半壳，容纳 盘 A07-09 · P072（右肩／上臂/上叉） 的圆轴与限位环；装 盘 A07-23 · P088（右肩／上臂/D_径向摩擦块），M3×8 + M3 螺母调摩擦。用 盘 A06-08 · X065（右肩／上臂/D_活动半壳） 和 4 枚 M2×20 + 4 枚 M2 螺母合壳。磁铁端盖用 2 枚 M2×4 + 2 枚 M2 螺母；两只 PCB 板夹用 2 枚 M2×8 + 2 枚 M2 螺母。
5. C01 测量端按 [G4](#G4)：盘 A07-16 · N003（右肩／上臂/下叉_侧装磁铁座盖） 内放 1 颗磁铁，用 2 枚 M2×5 + 2 枚 M2 螺母固定到叉臂端；盘 A06-13 · X009（右肩／上臂/下叉_传感板托夹） 先滑入传感板，再用 M3×8 + M3 螺母固定。
6. C02 测量端按 [G4](#G4)：盘 A07-17 · N003（右肩／上臂/上叉_侧装磁铁座盖） 内放 1 颗磁铁，用 2 枚 M2×5 + 2 枚 M2 螺母固定到叉臂端；盘 A07-05 · X010（右肩／上臂/上叉_传感板托夹） 先滑入传感板，再用 M3×8 + M3 螺母固定。
7. 局部慢慢活动，确认每一相邻活动面不挤压垫片、PCB 和线束。按需要的手感调保持力即可；当前可用行程由实物相邻件与线束决定，软件 raw_limits 不是要求你硬拧到的机械行程。

| 电路端口 / 中央板位号 | 测量轴 | 传感板装在 | 对应磁铁装在 | 每根线建议长度 |
| --- | --- | --- | --- | --- |
| 端口 B09 / J34 | `upperarm_r/r0` | 盘 A07-19 · X059（右肩／上臂/P_板夹_-14） + 盘 A07-21 · X060（右肩／上臂/P_板夹_+14） | 盘 A07-13 · P084（右肩／上臂/P_磁铁端盖） | 350 mm × 5 根，首件后定长 |
| 端口 B10 / J35 | `upperarm_r/r1` | 盘 A06-13 · X009（右肩／上臂/下叉_传感板托夹） | 盘 A07-16 · N003（右肩／上臂/下叉_侧装磁铁座盖） | 550 mm × 5 根，首件后定长 |
| 端口 B11 / J36 | `upperarm_r/r2` | 盘 A07-05 · X010（右肩／上臂/上叉_传感板托夹） | 盘 A07-17 · N003（右肩／上臂/上叉_侧装磁铁座盖） | 525 mm × 5 根，首件后定长 |
| 端口 B12 / J37 | `upperarm_r/r3` | 盘 A07-18 · X063（右肩／上臂/D_板夹_-14） + 盘 A07-20 · X064（右肩／上臂/D_板夹_+14） | 盘 A07-15 · P089（右肩／上臂/D_磁铁端盖） | 500 mm × 5 根，首件后定长 |

本步完成检查：B09、B10、B11、B12 标签对应正确；磁铁不相对载体打滑；转轴可手动摆动并保持；线先松放到背盒方向，留待走线章节统一固定。

### S14 · 右肘屈伸

连接 **盘 A06-05 · X066（骨架／右肩／上臂） → 盘 A06-03 · H010（骨架／右肘）**。本步需打开打印盘：A06、A07。

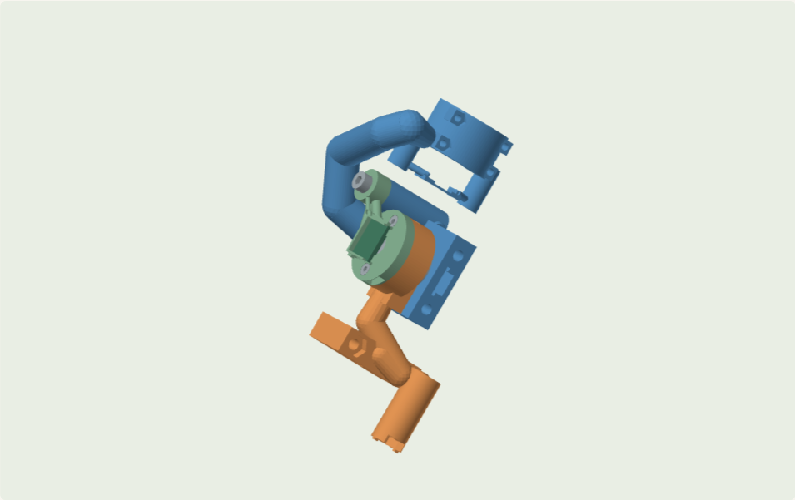
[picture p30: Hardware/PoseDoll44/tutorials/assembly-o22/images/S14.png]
S14 右肘屈伸 · CAD 装配位置；蓝色为父骨架，橙色为子骨架


| 取件位置 | 名称 / 原始键 | 本步用途 / 状态 |
| --- | --- | --- |
| 盘 A06-05 · X066（骨架／右肩／上臂） | `frame/upperarm_r` | 已在 S13 取用，直接使用已装骨架。一体骨架；已包含 右肩／上臂/D_固定半壳、右肘屈伸/固定侧关节座 |
| 盘 A06-03 · H010（骨架／右肘） | `frame/elbow_r` | 本步新取。一体骨架；已包含 右肘屈伸/旋转侧叉耳、右前臂扭转/固定侧关节座 |
| 盘 A07-03 · X029（右肘屈伸/传感板托夹） | `elbow_r.flex/sensor_cassette` | 本步新取。固定传感 PCB；先滑入板，再装到关节 |
| 盘 A07-06 · N004（右肘屈伸/侧装磁铁座盖） | `elbow_r.flex/magnet_cartridge` | 本步新取。侧面装入并粘固磁铁；旋转侧用 2 枚 M2×5 固定 |

| 五金 / 磁铁 | 本步数量 | 位置 |
| --- | --- | --- |
| M4大平垫圈：外径12、厚1 mm，实物能自由套过Φ4光杆 | 2 | 旋转叉耳两侧，每个支点 2 片 |
| A8不锈钢碟簧：8×4.2×0.4，自由高0.6 mm | 2 | 每个轴肩支点 2 片，相对安装 |
| M4普通平垫圈：外径9、厚0.8 mm，实物通孔验证 | 1 | 螺钉头下、碟簧外侧，每个支点 1 片 |
| 轴肩螺钉 Φ4×8 / M3×0.5，螺纹长6 mm；头Φ7×3，内六角3 mm | 1 | 轴肩摩擦支点，铰链 1 处 / 十字核心 4 处 |
| M3普通六角螺母（不要锁紧螺母替代外形） | 2 | 轴肩捕获窝、板托夹固定点，以及有 P/D 端轴时的摩擦调节槽 |
| M3大平垫圈：外径9、厚0.8 mm，实物通孔验证 | 1 | 固定座内侧，每个支点 1 片反力垫 |
| M3×8 内六角圆柱头螺钉；按CAD头径/头高核对 | 1 | 每只传感板托夹 1 枚；每个 P/D 摩擦块调节 1 枚 |
| M2普通六角螺母（不要锁紧螺母替代外形） | 2 | 本步各 M2 螺钉对应捕获窝，一螺钉配一螺母 |
| M2×5 内六角圆柱头螺钉；按CAD头径/头高核对 | 2 | N003 / N004 侧装磁铁座盖，每个 2 枚 |
| 径向两极磁铁 Φ6×2.5 mm；直径方向充磁，不能买轴向充磁 | 1 | 本步每个实测轴 1 颗，位于对应磁铁座 / 端盖 |

1. 将 盘 A06-05 · X066（骨架／右肩／上臂） 的固定关节座与 盘 A06-03 · H010（骨架／右肘） 的旋转叉耳摆到图示连接位置。侧槽尚未被挡住时，预装 1 枚 M3 螺母与 1 片 M3 反力垫。
2. 按 [G5 一体铰链](#G5) 和 [G1 轴肩层次](#G1) 装 1 套轴肩结构。单个支点为 1 枚轴肩螺钉、2 片 M4 大垫、2 片 A8 碟簧、1 片 M4 普通垫，外加刚才放入的螺母和反力垫。
3. 调整摩擦后，按 [G4](#G4) 给 盘 A07-06 · N004（右肘屈伸/侧装磁铁座盖） 装 1 颗磁铁，固化后用 2 枚 M2×5 + 2 枚 M2 螺母固定到旋转侧。
4. 把下表所列传感板装入 盘 A07-03 · X029（右肘屈伸/传感板托夹），再用 1 枚 M3×8 + 1 枚 M3 螺母固定到固定侧。传感器与磁铁相对，不能把两者都固定到同一旋转骨段。
5. 局部慢慢活动，确认每一相邻活动面不挤压垫片、PCB 和线束。按需要的手感调保持力即可；当前可用行程由实物相邻件与线束决定，软件 raw_limits 不是要求你硬拧到的机械行程。

| 电路端口 / 中央板位号 | 测量轴 | 传感板装在 | 对应磁铁装在 | 每根线建议长度 |
| --- | --- | --- | --- | --- |
| 端口 B13 / J38 | `elbow_r.flex/r0` | 盘 A07-03 · X029（右肘屈伸/传感板托夹） | 盘 A07-06 · N004（右肘屈伸/侧装磁铁座盖） | 500 mm × 5 根，首件后定长 |

本步完成检查：B13 标签对应正确；磁铁不相对载体打滑；转轴可手动摆动并保持；线先松放到背盒方向，留待走线章节统一固定。

### S15 · 右前臂扭转

连接 **盘 A06-03 · H010（骨架／右肘） → 盘 A06-02 · W002（骨架／右前臂）**。本步需打开打印盘：A06、A07。

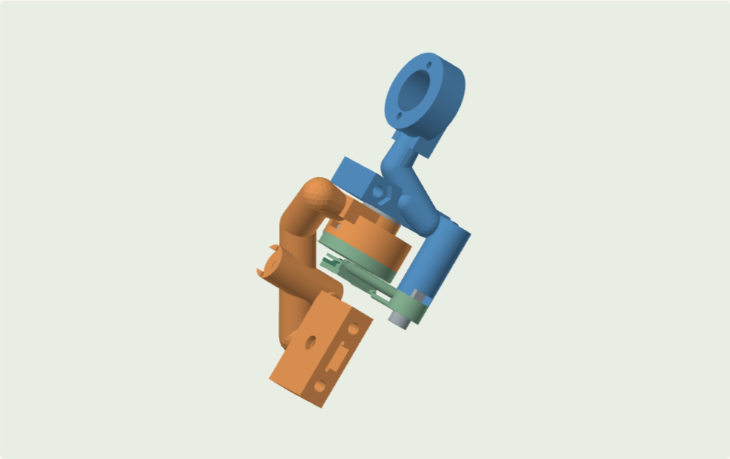
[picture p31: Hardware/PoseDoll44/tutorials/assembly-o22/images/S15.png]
S15 右前臂扭转 · CAD 装配位置；蓝色为父骨架，橙色为子骨架


| 取件位置 | 名称 / 原始键 | 本步用途 / 状态 |
| --- | --- | --- |
| 盘 A06-03 · H010（骨架／右肘） | `frame/elbow_r` | 已在 S14 取用，直接使用已装骨架。一体骨架；已包含 右肘屈伸/旋转侧叉耳、右前臂扭转/固定侧关节座 |
| 盘 A06-02 · W002（骨架／右前臂） | `frame/forearm_r` | 本步新取。一体骨架；已包含 右前臂扭转/旋转侧叉耳、右手腕屈伸/固定侧关节座 |
| 盘 A06-11 · X030（右前臂扭转/传感板托夹） | `forearm_r.twist/sensor_cassette` | 本步新取。固定传感 PCB；先滑入板，再装到关节 |
| 盘 A07-04 · N004（右前臂扭转/侧装磁铁座盖） | `forearm_r.twist/magnet_cartridge` | 本步新取。侧面装入并粘固磁铁；旋转侧用 2 枚 M2×5 固定 |

| 五金 / 磁铁 | 本步数量 | 位置 |
| --- | --- | --- |
| M4大平垫圈：外径12、厚1 mm，实物能自由套过Φ4光杆 | 2 | 旋转叉耳两侧，每个支点 2 片 |
| A8不锈钢碟簧：8×4.2×0.4，自由高0.6 mm | 2 | 每个轴肩支点 2 片，相对安装 |
| M4普通平垫圈：外径9、厚0.8 mm，实物通孔验证 | 1 | 螺钉头下、碟簧外侧，每个支点 1 片 |
| 轴肩螺钉 Φ4×8 / M3×0.5，螺纹长6 mm；头Φ7×3，内六角3 mm | 1 | 轴肩摩擦支点，铰链 1 处 / 十字核心 4 处 |
| M3普通六角螺母（不要锁紧螺母替代外形） | 2 | 轴肩捕获窝、板托夹固定点，以及有 P/D 端轴时的摩擦调节槽 |
| M3大平垫圈：外径9、厚0.8 mm，实物通孔验证 | 1 | 固定座内侧，每个支点 1 片反力垫 |
| M3×8 内六角圆柱头螺钉；按CAD头径/头高核对 | 1 | 每只传感板托夹 1 枚；每个 P/D 摩擦块调节 1 枚 |
| M2普通六角螺母（不要锁紧螺母替代外形） | 2 | 本步各 M2 螺钉对应捕获窝，一螺钉配一螺母 |
| M2×5 内六角圆柱头螺钉；按CAD头径/头高核对 | 2 | N003 / N004 侧装磁铁座盖，每个 2 枚 |
| 径向两极磁铁 Φ6×2.5 mm；直径方向充磁，不能买轴向充磁 | 1 | 本步每个实测轴 1 颗，位于对应磁铁座 / 端盖 |

1. 将 盘 A06-03 · H010（骨架／右肘） 的固定关节座与 盘 A06-02 · W002（骨架／右前臂） 的旋转叉耳摆到图示连接位置。侧槽尚未被挡住时，预装 1 枚 M3 螺母与 1 片 M3 反力垫。
2. 按 [G5 一体铰链](#G5) 和 [G1 轴肩层次](#G1) 装 1 套轴肩结构。单个支点为 1 枚轴肩螺钉、2 片 M4 大垫、2 片 A8 碟簧、1 片 M4 普通垫，外加刚才放入的螺母和反力垫。
3. 调整摩擦后，按 [G4](#G4) 给 盘 A07-04 · N004（右前臂扭转/侧装磁铁座盖） 装 1 颗磁铁，固化后用 2 枚 M2×5 + 2 枚 M2 螺母固定到旋转侧。
4. 把下表所列传感板装入 盘 A06-11 · X030（右前臂扭转/传感板托夹），再用 1 枚 M3×8 + 1 枚 M3 螺母固定到固定侧。传感器与磁铁相对，不能把两者都固定到同一旋转骨段。
5. 局部慢慢活动，确认每一相邻活动面不挤压垫片、PCB 和线束。按需要的手感调保持力即可；当前可用行程由实物相邻件与线束决定，软件 raw_limits 不是要求你硬拧到的机械行程。

| 电路端口 / 中央板位号 | 测量轴 | 传感板装在 | 对应磁铁装在 | 每根线建议长度 |
| --- | --- | --- | --- | --- |
| 端口 B14 / J39 | `forearm_r.twist/r0` | 盘 A06-11 · X030（右前臂扭转/传感板托夹） | 盘 A07-04 · N004（右前臂扭转/侧装磁铁座盖） | 550 mm × 5 根，首件后定长 |

本步完成检查：B14 标签对应正确；磁铁不相对载体打滑；转轴可手动摆动并保持；线先松放到背盒方向，留待走线章节统一固定。

### S16 · 右手腕屈伸

连接 **盘 A06-02 · W002（骨架／右前臂） → 盘 A07-01 · H012（骨架／右腕屈伸中间架）**。本步需打开打印盘：A06、A07。

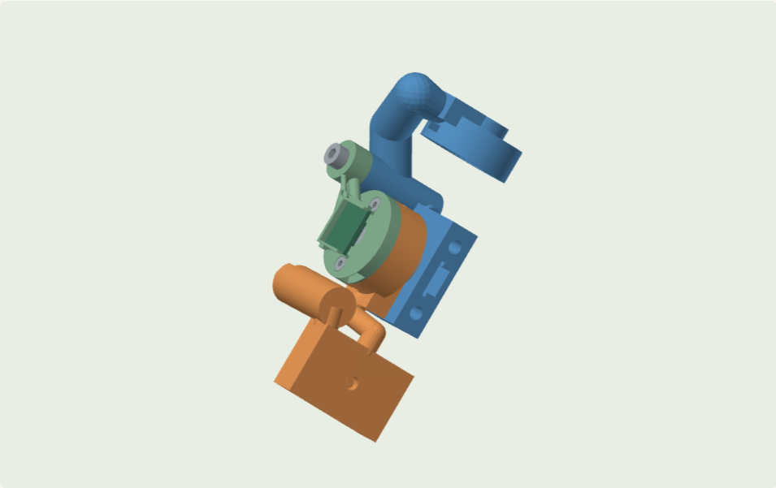
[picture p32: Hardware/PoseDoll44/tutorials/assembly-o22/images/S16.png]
S16 右手腕屈伸 · CAD 装配位置；蓝色为父骨架，橙色为子骨架


| 取件位置 | 名称 / 原始键 | 本步用途 / 状态 |
| --- | --- | --- |
| 盘 A06-02 · W002（骨架／右前臂） | `frame/forearm_r` | 已在 S15 取用，直接使用已装骨架。一体骨架；已包含 右前臂扭转/旋转侧叉耳、右手腕屈伸/固定侧关节座 |
| 盘 A07-01 · H012（骨架／右腕屈伸中间架） | `frame/hand_r.flex_frame` | 本步新取。一体骨架；已包含 右手腕屈伸/旋转侧叉耳、右手腕侧摆/固定侧关节座 |
| 盘 A06-14 · X031（右手腕屈伸/传感板托夹） | `hand_r.flex/sensor_cassette` | 本步新取。固定传感 PCB；先滑入板，再装到关节 |
| 盘 A07-10 · N004（右手腕屈伸/侧装磁铁座盖） | `hand_r.flex/magnet_cartridge` | 本步新取。侧面装入并粘固磁铁；旋转侧用 2 枚 M2×5 固定 |

| 五金 / 磁铁 | 本步数量 | 位置 |
| --- | --- | --- |
| M4大平垫圈：外径12、厚1 mm，实物能自由套过Φ4光杆 | 2 | 旋转叉耳两侧，每个支点 2 片 |
| A8不锈钢碟簧：8×4.2×0.4，自由高0.6 mm | 2 | 每个轴肩支点 2 片，相对安装 |
| M4普通平垫圈：外径9、厚0.8 mm，实物通孔验证 | 1 | 螺钉头下、碟簧外侧，每个支点 1 片 |
| 轴肩螺钉 Φ4×8 / M3×0.5，螺纹长6 mm；头Φ7×3，内六角3 mm | 1 | 轴肩摩擦支点，铰链 1 处 / 十字核心 4 处 |
| M3普通六角螺母（不要锁紧螺母替代外形） | 2 | 轴肩捕获窝、板托夹固定点，以及有 P/D 端轴时的摩擦调节槽 |
| M3大平垫圈：外径9、厚0.8 mm，实物通孔验证 | 1 | 固定座内侧，每个支点 1 片反力垫 |
| M3×8 内六角圆柱头螺钉；按CAD头径/头高核对 | 1 | 每只传感板托夹 1 枚；每个 P/D 摩擦块调节 1 枚 |
| M2普通六角螺母（不要锁紧螺母替代外形） | 2 | 本步各 M2 螺钉对应捕获窝，一螺钉配一螺母 |
| M2×5 内六角圆柱头螺钉；按CAD头径/头高核对 | 2 | N003 / N004 侧装磁铁座盖，每个 2 枚 |
| 径向两极磁铁 Φ6×2.5 mm；直径方向充磁，不能买轴向充磁 | 1 | 本步每个实测轴 1 颗，位于对应磁铁座 / 端盖 |

1. 将 盘 A06-02 · W002（骨架／右前臂） 的固定关节座与 盘 A07-01 · H012（骨架／右腕屈伸中间架） 的旋转叉耳摆到图示连接位置。侧槽尚未被挡住时，预装 1 枚 M3 螺母与 1 片 M3 反力垫。
2. 按 [G5 一体铰链](#G5) 和 [G1 轴肩层次](#G1) 装 1 套轴肩结构。单个支点为 1 枚轴肩螺钉、2 片 M4 大垫、2 片 A8 碟簧、1 片 M4 普通垫，外加刚才放入的螺母和反力垫。
3. 调整摩擦后，按 [G4](#G4) 给 盘 A07-10 · N004（右手腕屈伸/侧装磁铁座盖） 装 1 颗磁铁，固化后用 2 枚 M2×5 + 2 枚 M2 螺母固定到旋转侧。
4. 把下表所列传感板装入 盘 A06-14 · X031（右手腕屈伸/传感板托夹），再用 1 枚 M3×8 + 1 枚 M3 螺母固定到固定侧。传感器与磁铁相对，不能把两者都固定到同一旋转骨段。
5. 局部慢慢活动，确认每一相邻活动面不挤压垫片、PCB 和线束。按需要的手感调保持力即可；当前可用行程由实物相邻件与线束决定，软件 raw_limits 不是要求你硬拧到的机械行程。

| 电路端口 / 中央板位号 | 测量轴 | 传感板装在 | 对应磁铁装在 | 每根线建议长度 |
| --- | --- | --- | --- | --- |
| 端口 B15 / J40 | `hand_r.flex/r0` | 盘 A06-14 · X031（右手腕屈伸/传感板托夹） | 盘 A07-10 · N004（右手腕屈伸/侧装磁铁座盖） | 625 mm × 5 根，首件后定长 |

本步完成检查：B15 标签对应正确；磁铁不相对载体打滑；转轴可手动摆动并保持；线先松放到背盒方向，留待走线章节统一固定。

### S17 · 右手腕侧摆

连接 **盘 A07-01 · H012（骨架／右腕屈伸中间架） → 盘 A07-14 · P185（骨架／右手腕）**。本步需打开打印盘：A06、A07。

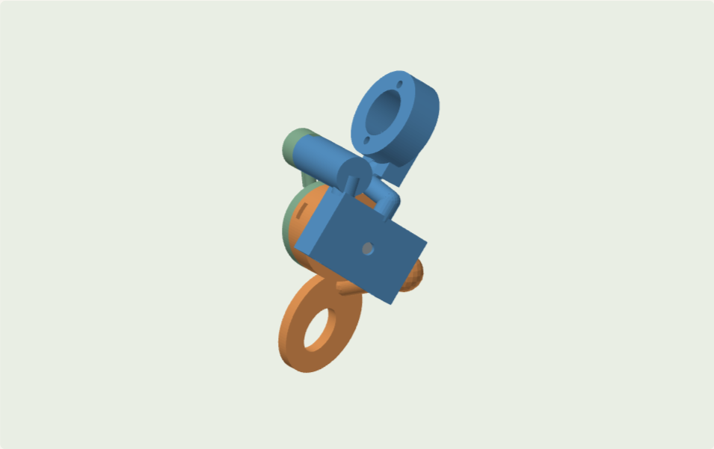
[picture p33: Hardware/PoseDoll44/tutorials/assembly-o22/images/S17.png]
S17 右手腕侧摆 · CAD 装配位置；蓝色为父骨架，橙色为子骨架


| 取件位置 | 名称 / 原始键 | 本步用途 / 状态 |
| --- | --- | --- |
| 盘 A07-01 · H012（骨架／右腕屈伸中间架） | `frame/hand_r.flex_frame` | 已在 S16 取用，直接使用已装骨架。一体骨架；已包含 右手腕屈伸/旋转侧叉耳、右手腕侧摆/固定侧关节座 |
| 盘 A07-14 · P185（骨架／右手腕） | `frame/hand_r` | 本步新取。一体骨架；已包含 右手腕侧摆/旋转侧叉耳 |
| 盘 A06-10 · X032（右手腕侧摆/传感板托夹） | `hand_r.deviate/sensor_cassette` | 本步新取。固定传感 PCB；先滑入板，再装到关节 |
| 盘 A07-12 · N004（右手腕侧摆/侧装磁铁座盖） | `hand_r.deviate/magnet_cartridge` | 本步新取。侧面装入并粘固磁铁；旋转侧用 2 枚 M2×5 固定 |

| 五金 / 磁铁 | 本步数量 | 位置 |
| --- | --- | --- |
| M4大平垫圈：外径12、厚1 mm，实物能自由套过Φ4光杆 | 2 | 旋转叉耳两侧，每个支点 2 片 |
| A8不锈钢碟簧：8×4.2×0.4，自由高0.6 mm | 2 | 每个轴肩支点 2 片，相对安装 |
| M4普通平垫圈：外径9、厚0.8 mm，实物通孔验证 | 1 | 螺钉头下、碟簧外侧，每个支点 1 片 |
| 轴肩螺钉 Φ4×8 / M3×0.5，螺纹长6 mm；头Φ7×3，内六角3 mm | 1 | 轴肩摩擦支点，铰链 1 处 / 十字核心 4 处 |
| M3普通六角螺母（不要锁紧螺母替代外形） | 2 | 轴肩捕获窝、板托夹固定点，以及有 P/D 端轴时的摩擦调节槽 |
| M3大平垫圈：外径9、厚0.8 mm，实物通孔验证 | 1 | 固定座内侧，每个支点 1 片反力垫 |
| M3×8 内六角圆柱头螺钉；按CAD头径/头高核对 | 1 | 每只传感板托夹 1 枚；每个 P/D 摩擦块调节 1 枚 |
| M2普通六角螺母（不要锁紧螺母替代外形） | 2 | 本步各 M2 螺钉对应捕获窝，一螺钉配一螺母 |
| M2×5 内六角圆柱头螺钉；按CAD头径/头高核对 | 2 | N003 / N004 侧装磁铁座盖，每个 2 枚 |
| 径向两极磁铁 Φ6×2.5 mm；直径方向充磁，不能买轴向充磁 | 1 | 本步每个实测轴 1 颗，位于对应磁铁座 / 端盖 |

1. 将 盘 A07-01 · H012（骨架／右腕屈伸中间架） 的固定关节座与 盘 A07-14 · P185（骨架／右手腕） 的旋转叉耳摆到图示连接位置。侧槽尚未被挡住时，预装 1 枚 M3 螺母与 1 片 M3 反力垫。
2. 按 [G5 一体铰链](#G5) 和 [G1 轴肩层次](#G1) 装 1 套轴肩结构。单个支点为 1 枚轴肩螺钉、2 片 M4 大垫、2 片 A8 碟簧、1 片 M4 普通垫，外加刚才放入的螺母和反力垫。
3. 调整摩擦后，按 [G4](#G4) 给 盘 A07-12 · N004（右手腕侧摆/侧装磁铁座盖） 装 1 颗磁铁，固化后用 2 枚 M2×5 + 2 枚 M2 螺母固定到旋转侧。
4. 把下表所列传感板装入 盘 A06-10 · X032（右手腕侧摆/传感板托夹），再用 1 枚 M3×8 + 1 枚 M3 螺母固定到固定侧。传感器与磁铁相对，不能把两者都固定到同一旋转骨段。
5. 局部慢慢活动，确认每一相邻活动面不挤压垫片、PCB 和线束。按需要的手感调保持力即可；当前可用行程由实物相邻件与线束决定，软件 raw_limits 不是要求你硬拧到的机械行程。

| 电路端口 / 中央板位号 | 测量轴 | 传感板装在 | 对应磁铁装在 | 每根线建议长度 |
| --- | --- | --- | --- | --- |
| 端口 B16 / J41 | `hand_r.deviate/r0` | 盘 A06-10 · X032（右手腕侧摆/传感板托夹） | 盘 A07-12 · N004（右手腕侧摆/侧装磁铁座盖） | 675 mm × 5 根，首件后定长 |

本步完成检查：B16 标签对应正确；磁铁不相对载体打滑；转轴可手动摆动并保持；线先松放到背盒方向，留待走线章节统一固定。

### S18 · 左髋／大腿

连接 **盘 A03-01 · X038（骨架／骨盆） → 盘 A08-01 · X073（骨架／左髋／大腿）**。本步需打开打印盘：A03、A08。

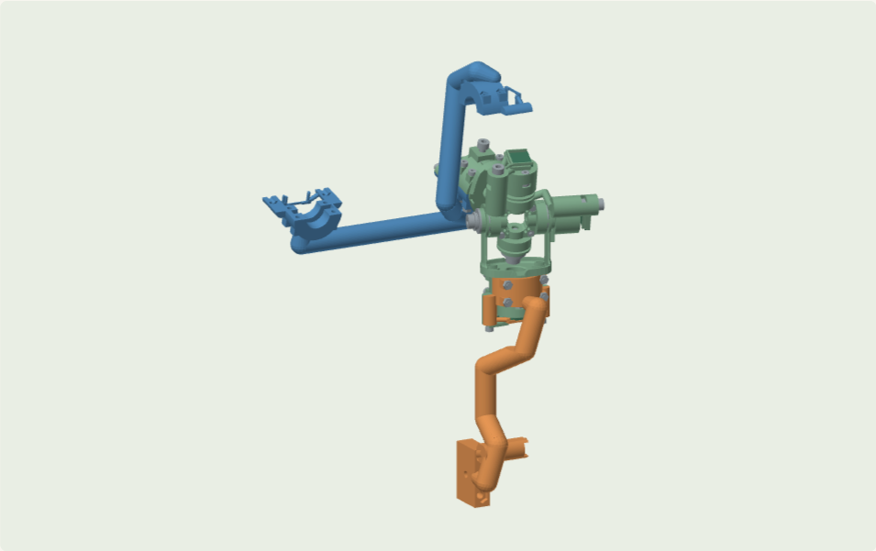
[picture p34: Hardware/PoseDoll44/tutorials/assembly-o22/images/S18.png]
S18 左髋／大腿 · CAD 装配位置；蓝色为父骨架，橙色为子骨架


| 取件位置 | 名称 / 原始键 | 本步用途 / 状态 |
| --- | --- | --- |
| 盘 A03-01 · X038（骨架／骨盆） | `frame/pelvis` | 已在 S01 取用，直接使用已装骨架。一体骨架；已包含 腰部/P_固定半壳、左髋／大腿/P_固定半壳、右髋／大腿/P_固定半壳 |
| 盘 A08-01 · X073（骨架／左髋／大腿） | `frame/thigh_l` | 本步新取。一体骨架；已包含 左髋／大腿/D_固定半壳、左膝／小腿屈伸/固定侧关节座 |
| 盘 A08-02 · P095（左髋／大腿/下环） | `thigh_l/C14` | 本步新取。十字关节下环；先装内部螺母和 M3 反力垫 |
| 盘 A08-03 · P093（左髋／大腿/下叉） | `thigh_l/C01` | 本步新取。十字关节叉臂；与另一叉臂正交穿装 |
| 盘 A08-04 · P094（左髋／大腿/上叉） | `thigh_l/C02` | 本步新取。十字关节叉臂；与另一叉臂正交穿装 |
| 盘 A08-05 · X069（左髋／大腿/P_活动半壳） | `thigh_l/P_case_plus` | 本步新取。端轴可拆半壳；4 枚 M2×20 合壳 |
| 盘 A08-06 · X072（左髋／大腿/D_活动半壳） | `thigh_l/D_case_plus` | 本步新取。端轴可拆半壳；4 枚 M2×20 合壳 |
| 盘 A08-07 · P096（左髋／大腿/上环盖） | `thigh_l/C15` | 本步新取。十字关节上环盖；4 枚 M1.6×6 合环 |
| 盘 A08-08 · X012（左髋／大腿/上叉_传感板托夹） | `thigh_l/C02_sensor_cassette` | 本步新取。固定传感 PCB；先滑入板，再装到关节 |
| 盘 A08-12 · X011（左髋／大腿/下叉_传感板托夹） | `thigh_l/C01_sensor_cassette` | 本步新取。固定传感 PCB；先滑入板，再装到关节 |
| 盘 A08-16 · P106（左髋／大腿/P_磁铁端盖） | `thigh_l/P_magnet_cap` | 本步新取。端轴磁铁端盖；2 枚 M2×4 固定 |
| 盘 A08-17 · P111（左髋／大腿/D_磁铁端盖） | `thigh_l/D_magnet_cap` | 本步新取。端轴磁铁端盖；2 枚 M2×4 固定 |
| 盘 A08-18 · N003（左髋／大腿/下叉_侧装磁铁座盖） | `thigh_l/C01_magnet_cartridge` | 本步新取。侧面装入并粘固磁铁；旋转侧用 2 枚 M2×5 固定 |
| 盘 A08-19 · N003（左髋／大腿/上叉_侧装磁铁座盖） | `thigh_l/C02_magnet_cartridge` | 本步新取。侧面装入并粘固磁铁；旋转侧用 2 枚 M2×5 固定 |
| 盘 A08-22 · X068（左髋／大腿/P_板夹_+14） | `thigh_l/P_pcb_clip_+14` | 本步新取。端轴传感 PCB 的一侧板夹，与另一板夹成对使用 |
| 盘 A08-23 · X067（左髋／大腿/P_板夹_-14） | `thigh_l/P_pcb_clip_-14` | 本步新取。端轴传感 PCB 的一侧板夹，与另一板夹成对使用 |
| 盘 A08-24 · X071（左髋／大腿/D_板夹_+14） | `thigh_l/D_pcb_clip_+14` | 本步新取。端轴传感 PCB 的一侧板夹，与另一板夹成对使用 |
| 盘 A08-25 · X070（左髋／大腿/D_板夹_-14） | `thigh_l/D_pcb_clip_-14` | 本步新取。端轴传感 PCB 的一侧板夹，与另一板夹成对使用 |
| 盘 A08-26 · P105（左髋／大腿/P_径向摩擦块） | `thigh_l/P_radial_pad` | 本步新取。端轴径向摩擦块；凹面朝轴，M3×8 顶压外侧 |
| 盘 A08-27 · P110（左髋／大腿/D_径向摩擦块） | `thigh_l/D_radial_pad` | 本步新取。端轴径向摩擦块；凹面朝轴，M3×8 顶压外侧 |

| 五金 / 磁铁 | 本步数量 | 位置 |
| --- | --- | --- |
| M4大平垫圈：外径12、厚1 mm，实物能自由套过Φ4光杆 | 8 | 旋转叉耳两侧，每个支点 2 片 |
| A8不锈钢碟簧：8×4.2×0.4，自由高0.6 mm | 8 | 每个轴肩支点 2 片，相对安装 |
| M4普通平垫圈：外径9、厚0.8 mm，实物通孔验证 | 4 | 螺钉头下、碟簧外侧，每个支点 1 片 |
| 轴肩螺钉 Φ4×8 / M3×0.5，螺纹长6 mm；头Φ7×3，内六角3 mm | 4 | 轴肩摩擦支点，铰链 1 处 / 十字核心 4 处 |
| M3普通六角螺母（不要锁紧螺母替代外形） | 8 | 轴肩捕获窝、板托夹固定点，以及有 P/D 端轴时的摩擦调节槽 |
| M3大平垫圈：外径9、厚0.8 mm，实物通孔验证 | 4 | 固定座内侧，每个支点 1 片反力垫 |
| M1.6×6 内六角圆柱头螺钉；按CAD头径/头高核对 | 4 | C14 / C15 合环 |
| M1.6普通六角螺母（不要锁紧螺母替代外形） | 4 | C14 / C15 合环螺钉对应捕获窝 |
| M2普通六角螺母（不要锁紧螺母替代外形） | 20 | 本步各 M2 螺钉对应捕获窝，一螺钉配一螺母 |
| M2×5 内六角圆柱头螺钉；按CAD头径/头高核对 | 4 | N003 / N004 侧装磁铁座盖，每个 2 枚 |
| 径向两极磁铁 Φ6×2.5 mm；直径方向充磁，不能买轴向充磁 | 4 | 本步每个实测轴 1 颗，位于对应磁铁座 / 端盖 |
| M3×8 内六角圆柱头螺钉；按CAD头径/头高核对 | 4 | 每只传感板托夹 1 枚；每个 P/D 摩擦块调节 1 枚 |
| M2×20 内六角圆柱头螺钉；按CAD头径/头高核对 | 8 | P / D 端轴固定半壳与活动半壳合壳 |
| M2×4 内六角圆柱头螺钉；按CAD头径/头高核对 | 4 | P / D 端轴的磁铁端盖 |
| M2×8 内六角圆柱头螺钉；按CAD头径/头高核对 | 4 | P / D 端轴的成对 PCB 板夹 |

1. 取 盘 A08-02 · P095（左髋／大腿/下环）、盘 A08-07 · P096（左髋／大腿/上环盖）。两叉分别是 盘 A08-03 · P093（左髋／大腿/下叉） 的 C01 部位、盘 A08-04 · P094（左髋／大腿/上叉） 的 C02 部位；已经连在骨架上的叉不要拆分或另找重复打印件。
2. 按 [G2](#G2) 先预装 4 枚 M3 螺母与 4 片 M3 反力垫，把两叉交叉放入环，再按 G1 装四套轴肩结构；随后用 4 枚 M1.6×6 + 4 枚 M1.6 螺母合环。
3. P 端按 [G3](#G3)：盘 A03-01 · X038（骨架／骨盆） 内是一体固定半壳，容纳 盘 A08-03 · P093（左髋／大腿/下叉） 的圆轴与限位环；装 盘 A08-26 · P105（左髋／大腿/P_径向摩擦块），M3×8 + M3 螺母调摩擦。用 盘 A08-05 · X069（左髋／大腿/P_活动半壳） 和 4 枚 M2×20 + 4 枚 M2 螺母合壳。磁铁端盖用 2 枚 M2×4 + 2 枚 M2 螺母；两只 PCB 板夹用 2 枚 M2×8 + 2 枚 M2 螺母。
4. D 端按 [G3](#G3)：盘 A08-01 · X073（骨架／左髋／大腿） 内是一体固定半壳，容纳 盘 A08-04 · P094（左髋／大腿/上叉） 的圆轴与限位环；装 盘 A08-27 · P110（左髋／大腿/D_径向摩擦块），M3×8 + M3 螺母调摩擦。用 盘 A08-06 · X072（左髋／大腿/D_活动半壳） 和 4 枚 M2×20 + 4 枚 M2 螺母合壳。磁铁端盖用 2 枚 M2×4 + 2 枚 M2 螺母；两只 PCB 板夹用 2 枚 M2×8 + 2 枚 M2 螺母。
5. C01 测量端按 [G4](#G4)：盘 A08-18 · N003（左髋／大腿/下叉_侧装磁铁座盖） 内放 1 颗磁铁，用 2 枚 M2×5 + 2 枚 M2 螺母固定到叉臂端；盘 A08-12 · X011（左髋／大腿/下叉_传感板托夹） 先滑入传感板，再用 M3×8 + M3 螺母固定。
6. C02 测量端按 [G4](#G4)：盘 A08-19 · N003（左髋／大腿/上叉_侧装磁铁座盖） 内放 1 颗磁铁，用 2 枚 M2×5 + 2 枚 M2 螺母固定到叉臂端；盘 A08-08 · X012（左髋／大腿/上叉_传感板托夹） 先滑入传感板，再用 M3×8 + M3 螺母固定。
7. 局部慢慢活动，确认每一相邻活动面不挤压垫片、PCB 和线束。按需要的手感调保持力即可；当前可用行程由实物相邻件与线束决定，软件 raw_limits 不是要求你硬拧到的机械行程。

| 电路端口 / 中央板位号 | 测量轴 | 传感板装在 | 对应磁铁装在 | 每根线建议长度 |
| --- | --- | --- | --- | --- |
| 端口 C01 / J42 | `thigh_l/r0` | 盘 A08-23 · X067（左髋／大腿/P_板夹_-14） + 盘 A08-22 · X068（左髋／大腿/P_板夹_+14） | 盘 A08-16 · P106（左髋／大腿/P_磁铁端盖） | 425 mm × 5 根，首件后定长 |
| 端口 C02 / J43 | `thigh_l/r1` | 盘 A08-12 · X011（左髋／大腿/下叉_传感板托夹） | 盘 A08-18 · N003（左髋／大腿/下叉_侧装磁铁座盖） | 625 mm × 5 根，首件后定长 |
| 端口 C03 / J44 | `thigh_l/r2` | 盘 A08-08 · X012（左髋／大腿/上叉_传感板托夹） | 盘 A08-19 · N003（左髋／大腿/上叉_侧装磁铁座盖） | 575 mm × 5 根，首件后定长 |
| 端口 C04 / J45 | `thigh_l/r3` | 盘 A08-25 · X070（左髋／大腿/D_板夹_-14） + 盘 A08-24 · X071（左髋／大腿/D_板夹_+14） | 盘 A08-17 · P111（左髋／大腿/D_磁铁端盖） | 550 mm × 5 根，首件后定长 |

本步完成检查：C01、C02、C03、C04 标签对应正确；磁铁不相对载体打滑；转轴可手动摆动并保持；线先松放到背盒方向，留待走线章节统一固定。

### S19 · 左膝／小腿屈伸

连接 **盘 A08-01 · X073（骨架／左髋／大腿） → 盘 A10-02 · W007（骨架／左膝／小腿）**。本步需打开打印盘：A08、A10。

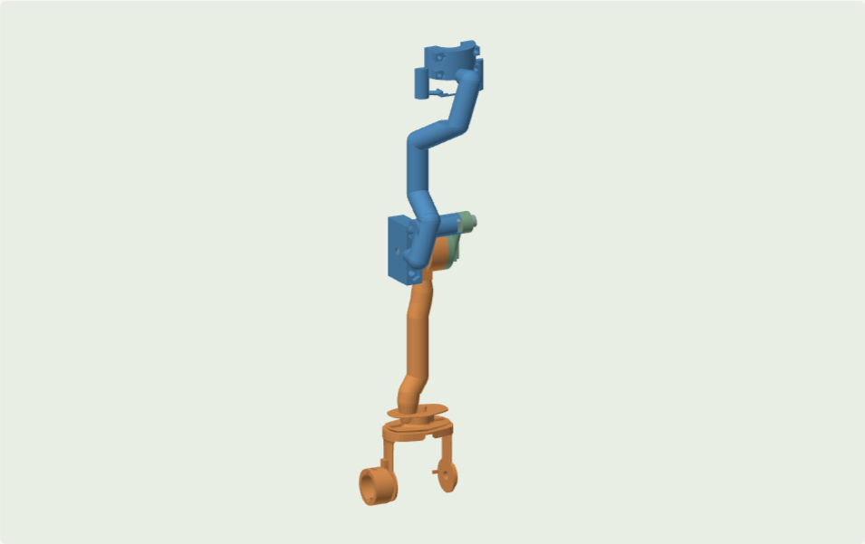
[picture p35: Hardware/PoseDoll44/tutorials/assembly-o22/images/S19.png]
S19 左膝／小腿屈伸 · CAD 装配位置；蓝色为父骨架，橙色为子骨架


| 取件位置 | 名称 / 原始键 | 本步用途 / 状态 |
| --- | --- | --- |
| 盘 A08-01 · X073（骨架／左髋／大腿） | `frame/thigh_l` | 已在 S18 取用，直接使用已装骨架。一体骨架；已包含 左髋／大腿/D_固定半壳、左膝／小腿屈伸/固定侧关节座 |
| 盘 A10-02 · W007（骨架／左膝／小腿） | `frame/calf_l` | 本步新取。一体骨架；已包含 左踝／脚掌/上叉、左膝／小腿屈伸/旋转侧叉耳 |
| 盘 A08-10 · X025（左膝／小腿屈伸/传感板托夹） | `calf_l.flex/sensor_cassette` | 本步新取。固定传感 PCB；先滑入板，再装到关节 |
| 盘 A08-14 · N004（左膝／小腿屈伸/侧装磁铁座盖） | `calf_l.flex/magnet_cartridge` | 本步新取。侧面装入并粘固磁铁；旋转侧用 2 枚 M2×5 固定 |

| 五金 / 磁铁 | 本步数量 | 位置 |
| --- | --- | --- |
| M4大平垫圈：外径12、厚1 mm，实物能自由套过Φ4光杆 | 2 | 旋转叉耳两侧，每个支点 2 片 |
| A8不锈钢碟簧：8×4.2×0.4，自由高0.6 mm | 2 | 每个轴肩支点 2 片，相对安装 |
| M4普通平垫圈：外径9、厚0.8 mm，实物通孔验证 | 1 | 螺钉头下、碟簧外侧，每个支点 1 片 |
| 轴肩螺钉 Φ4×8 / M3×0.5，螺纹长6 mm；头Φ7×3，内六角3 mm | 1 | 轴肩摩擦支点，铰链 1 处 / 十字核心 4 处 |
| M3普通六角螺母（不要锁紧螺母替代外形） | 2 | 轴肩捕获窝、板托夹固定点，以及有 P/D 端轴时的摩擦调节槽 |
| M3大平垫圈：外径9、厚0.8 mm，实物通孔验证 | 1 | 固定座内侧，每个支点 1 片反力垫 |
| M3×8 内六角圆柱头螺钉；按CAD头径/头高核对 | 1 | 每只传感板托夹 1 枚；每个 P/D 摩擦块调节 1 枚 |
| M2普通六角螺母（不要锁紧螺母替代外形） | 2 | 本步各 M2 螺钉对应捕获窝，一螺钉配一螺母 |
| M2×5 内六角圆柱头螺钉；按CAD头径/头高核对 | 2 | N003 / N004 侧装磁铁座盖，每个 2 枚 |
| 径向两极磁铁 Φ6×2.5 mm；直径方向充磁，不能买轴向充磁 | 1 | 本步每个实测轴 1 颗，位于对应磁铁座 / 端盖 |

1. 将 盘 A08-01 · X073（骨架／左髋／大腿） 的固定关节座与 盘 A10-02 · W007（骨架／左膝／小腿） 的旋转叉耳摆到图示连接位置。侧槽尚未被挡住时，预装 1 枚 M3 螺母与 1 片 M3 反力垫。
2. 按 [G5 一体铰链](#G5) 和 [G1 轴肩层次](#G1) 装 1 套轴肩结构。单个支点为 1 枚轴肩螺钉、2 片 M4 大垫、2 片 A8 碟簧、1 片 M4 普通垫，外加刚才放入的螺母和反力垫。
3. 调整摩擦后，按 [G4](#G4) 给 盘 A08-14 · N004（左膝／小腿屈伸/侧装磁铁座盖） 装 1 颗磁铁，固化后用 2 枚 M2×5 + 2 枚 M2 螺母固定到旋转侧。
4. 把下表所列传感板装入 盘 A08-10 · X025（左膝／小腿屈伸/传感板托夹），再用 1 枚 M3×8 + 1 枚 M3 螺母固定到固定侧。传感器与磁铁相对，不能把两者都固定到同一旋转骨段。
5. 局部慢慢活动，确认每一相邻活动面不挤压垫片、PCB 和线束。按需要的手感调保持力即可；当前可用行程由实物相邻件与线束决定，软件 raw_limits 不是要求你硬拧到的机械行程。

| 电路端口 / 中央板位号 | 测量轴 | 传感板装在 | 对应磁铁装在 | 每根线建议长度 |
| --- | --- | --- | --- | --- |
| 端口 C05 / J46 | `calf_l.flex/r0` | 盘 A08-10 · X025（左膝／小腿屈伸/传感板托夹） | 盘 A08-14 · N004（左膝／小腿屈伸/侧装磁铁座盖） | 525 mm × 5 根，首件后定长 |

本步完成检查：C05 标签对应正确；磁铁不相对载体打滑；转轴可手动摆动并保持；线先松放到背盒方向，留待走线章节统一固定。

### S20 · 左踝／脚掌

连接 **盘 A10-02 · W007（骨架／左膝／小腿） → 盘 A10-07 · W016（骨架／左踝／脚掌）**。本步需打开打印盘：A08、A10。

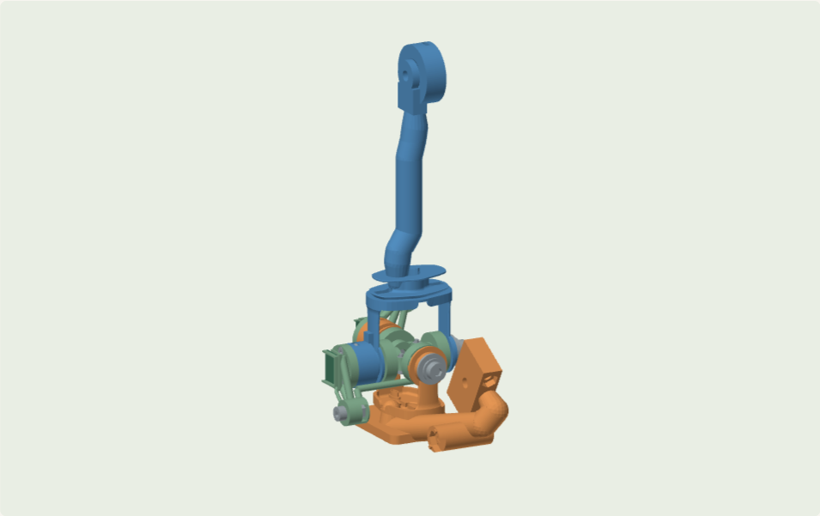
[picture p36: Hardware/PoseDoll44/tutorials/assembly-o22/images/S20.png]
S20 左踝／脚掌 · CAD 装配位置；蓝色为父骨架，橙色为子骨架


| 取件位置 | 名称 / 原始键 | 本步用途 / 状态 |
| --- | --- | --- |
| 盘 A10-02 · W007（骨架／左膝／小腿） | `frame/calf_l` | 已在 S19 取用，直接使用已装骨架。一体骨架；已包含 左踝／脚掌/上叉、左膝／小腿屈伸/旋转侧叉耳 |
| 盘 A10-07 · W016（骨架／左踝／脚掌） | `frame/foot_l` | 本步新取。一体骨架；已包含 左踝／脚掌/下叉、左脚趾屈伸/固定侧关节座 |
| 盘 A08-09 · X016（左踝／脚掌/上叉_传感板托夹） | `foot_l/C02_sensor_cassette` | 本步新取。固定传感 PCB；先滑入板，再装到关节 |
| 盘 A08-11 · X015（左踝／脚掌/下叉_传感板托夹） | `foot_l/C01_sensor_cassette` | 本步新取。固定传感 PCB；先滑入板，再装到关节 |
| 盘 A08-20 · N003（左踝／脚掌/下叉_侧装磁铁座盖） | `foot_l/C01_magnet_cartridge` | 本步新取。侧面装入并粘固磁铁；旋转侧用 2 枚 M2×5 固定 |
| 盘 A08-21 · N003（左踝／脚掌/上叉_侧装磁铁座盖） | `foot_l/C02_magnet_cartridge` | 本步新取。侧面装入并粘固磁铁；旋转侧用 2 枚 M2×5 固定 |
| 盘 A10-03 · P130（左踝／脚掌/下环） | `foot_l/C14` | 本步新取。十字关节下环；先装内部螺母和 M3 反力垫 |
| 盘 A10-09 · P131（左踝／脚掌/上环盖） | `foot_l/C15` | 本步新取。十字关节上环盖；4 枚 M1.6×6 合环 |

| 五金 / 磁铁 | 本步数量 | 位置 |
| --- | --- | --- |
| M4大平垫圈：外径12、厚1 mm，实物能自由套过Φ4光杆 | 8 | 旋转叉耳两侧，每个支点 2 片 |
| A8不锈钢碟簧：8×4.2×0.4，自由高0.6 mm | 8 | 每个轴肩支点 2 片，相对安装 |
| M4普通平垫圈：外径9、厚0.8 mm，实物通孔验证 | 4 | 螺钉头下、碟簧外侧，每个支点 1 片 |
| 轴肩螺钉 Φ4×8 / M3×0.5，螺纹长6 mm；头Φ7×3，内六角3 mm | 4 | 轴肩摩擦支点，铰链 1 处 / 十字核心 4 处 |
| M3普通六角螺母（不要锁紧螺母替代外形） | 6 | 轴肩捕获窝、板托夹固定点，以及有 P/D 端轴时的摩擦调节槽 |
| M3大平垫圈：外径9、厚0.8 mm，实物通孔验证 | 4 | 固定座内侧，每个支点 1 片反力垫 |
| M1.6×6 内六角圆柱头螺钉；按CAD头径/头高核对 | 4 | C14 / C15 合环 |
| M1.6普通六角螺母（不要锁紧螺母替代外形） | 4 | C14 / C15 合环螺钉对应捕获窝 |
| M2普通六角螺母（不要锁紧螺母替代外形） | 4 | 本步各 M2 螺钉对应捕获窝，一螺钉配一螺母 |
| M2×5 内六角圆柱头螺钉；按CAD头径/头高核对 | 4 | N003 / N004 侧装磁铁座盖，每个 2 枚 |
| 径向两极磁铁 Φ6×2.5 mm；直径方向充磁，不能买轴向充磁 | 2 | 本步每个实测轴 1 颗，位于对应磁铁座 / 端盖 |
| M3×8 内六角圆柱头螺钉；按CAD头径/头高核对 | 2 | 每只传感板托夹 1 枚；每个 P/D 摩擦块调节 1 枚 |

1. 取 盘 A10-03 · P130（左踝／脚掌/下环）、盘 A10-09 · P131（左踝／脚掌/上环盖）。两叉分别是 盘 A10-07 · W016（骨架／左踝／脚掌） 的 C01 部位、盘 A10-02 · W007（骨架／左膝／小腿） 的 C02 部位；已经连在骨架上的叉不要拆分或另找重复打印件。
2. 按 [G2](#G2) 先预装 4 枚 M3 螺母与 4 片 M3 反力垫，把两叉交叉放入环，再按 G1 装四套轴肩结构；随后用 4 枚 M1.6×6 + 4 枚 M1.6 螺母合环。
3. C01 测量端按 [G4](#G4)：盘 A08-20 · N003（左踝／脚掌/下叉_侧装磁铁座盖） 内放 1 颗磁铁，用 2 枚 M2×5 + 2 枚 M2 螺母固定到叉臂端；盘 A08-11 · X015（左踝／脚掌/下叉_传感板托夹） 先滑入传感板，再用 M3×8 + M3 螺母固定。
4. C02 测量端按 [G4](#G4)：盘 A08-21 · N003（左踝／脚掌/上叉_侧装磁铁座盖） 内放 1 颗磁铁，用 2 枚 M2×5 + 2 枚 M2 螺母固定到叉臂端；盘 A08-09 · X016（左踝／脚掌/上叉_传感板托夹） 先滑入传感板，再用 M3×8 + M3 螺母固定。
5. 局部慢慢活动，确认每一相邻活动面不挤压垫片、PCB 和线束。按需要的手感调保持力即可；当前可用行程由实物相邻件与线束决定，软件 raw_limits 不是要求你硬拧到的机械行程。

| 电路端口 / 中央板位号 | 测量轴 | 传感板装在 | 对应磁铁装在 | 每根线建议长度 |
| --- | --- | --- | --- | --- |
| 端口 C06 / J47 | `foot_l/r0` | 盘 A08-11 · X015（左踝／脚掌/下叉_传感板托夹） | 盘 A08-20 · N003（左踝／脚掌/下叉_侧装磁铁座盖） | 725 mm × 5 根，首件后定长 |
| 端口 C07 / J48 | `foot_l/r1` | 盘 A08-09 · X016（左踝／脚掌/上叉_传感板托夹） | 盘 A08-21 · N003（左踝／脚掌/上叉_侧装磁铁座盖） | 725 mm × 5 根，首件后定长 |

本步完成检查：C06、C07 标签对应正确；磁铁不相对载体打滑；转轴可手动摆动并保持；线先松放到背盒方向，留待走线章节统一固定。

### S21 · 左脚趾屈伸

连接 **盘 A10-07 · W016（骨架／左踝／脚掌） → 盘 A10-05 · W003（骨架／左脚趾）**。本步需打开打印盘：A08、A10。

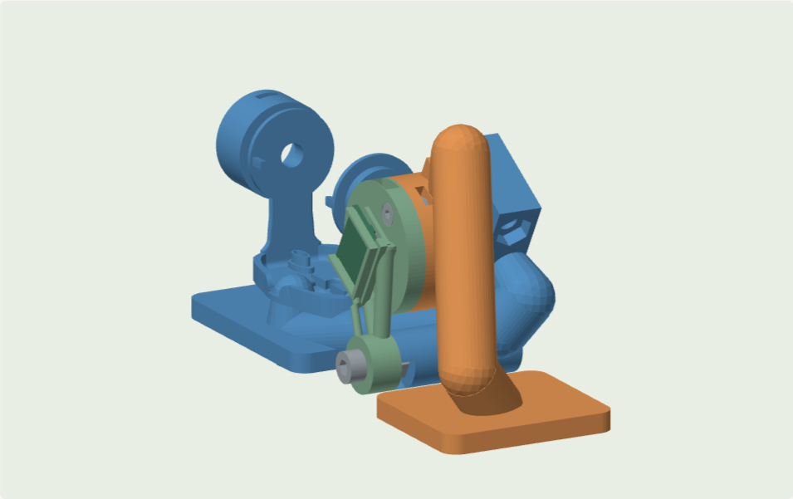
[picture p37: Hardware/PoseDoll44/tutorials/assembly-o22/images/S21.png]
S21 左脚趾屈伸 · CAD 装配位置；蓝色为父骨架，橙色为子骨架


| 取件位置 | 名称 / 原始键 | 本步用途 / 状态 |
| --- | --- | --- |
| 盘 A10-07 · W016（骨架／左踝／脚掌） | `frame/foot_l` | 已在 S20 取用，直接使用已装骨架。一体骨架；已包含 左踝／脚掌/下叉、左脚趾屈伸/固定侧关节座 |
| 盘 A10-05 · W003（骨架／左脚趾） | `frame/ball_l` | 本步新取。一体骨架；已包含 左脚趾屈伸/旋转侧叉耳 |
| 盘 A08-13 · X026（左脚趾屈伸/传感板托夹） | `ball_l.flex/sensor_cassette` | 本步新取。固定传感 PCB；先滑入板，再装到关节 |
| 盘 A08-15 · N004（左脚趾屈伸/侧装磁铁座盖） | `ball_l.flex/magnet_cartridge` | 本步新取。侧面装入并粘固磁铁；旋转侧用 2 枚 M2×5 固定 |

| 五金 / 磁铁 | 本步数量 | 位置 |
| --- | --- | --- |
| M4大平垫圈：外径12、厚1 mm，实物能自由套过Φ4光杆 | 2 | 旋转叉耳两侧，每个支点 2 片 |
| A8不锈钢碟簧：8×4.2×0.4，自由高0.6 mm | 2 | 每个轴肩支点 2 片，相对安装 |
| M4普通平垫圈：外径9、厚0.8 mm，实物通孔验证 | 1 | 螺钉头下、碟簧外侧，每个支点 1 片 |
| 轴肩螺钉 Φ4×8 / M3×0.5，螺纹长6 mm；头Φ7×3，内六角3 mm | 1 | 轴肩摩擦支点，铰链 1 处 / 十字核心 4 处 |
| M3普通六角螺母（不要锁紧螺母替代外形） | 2 | 轴肩捕获窝、板托夹固定点，以及有 P/D 端轴时的摩擦调节槽 |
| M3大平垫圈：外径9、厚0.8 mm，实物通孔验证 | 1 | 固定座内侧，每个支点 1 片反力垫 |
| M3×8 内六角圆柱头螺钉；按CAD头径/头高核对 | 1 | 每只传感板托夹 1 枚；每个 P/D 摩擦块调节 1 枚 |
| M2普通六角螺母（不要锁紧螺母替代外形） | 2 | 本步各 M2 螺钉对应捕获窝，一螺钉配一螺母 |
| M2×5 内六角圆柱头螺钉；按CAD头径/头高核对 | 2 | N003 / N004 侧装磁铁座盖，每个 2 枚 |
| 径向两极磁铁 Φ6×2.5 mm；直径方向充磁，不能买轴向充磁 | 1 | 本步每个实测轴 1 颗，位于对应磁铁座 / 端盖 |

1. 将 盘 A10-07 · W016（骨架／左踝／脚掌） 的固定关节座与 盘 A10-05 · W003（骨架／左脚趾） 的旋转叉耳摆到图示连接位置。侧槽尚未被挡住时，预装 1 枚 M3 螺母与 1 片 M3 反力垫。
2. 按 [G5 一体铰链](#G5) 和 [G1 轴肩层次](#G1) 装 1 套轴肩结构。单个支点为 1 枚轴肩螺钉、2 片 M4 大垫、2 片 A8 碟簧、1 片 M4 普通垫，外加刚才放入的螺母和反力垫。
3. 调整摩擦后，按 [G4](#G4) 给 盘 A08-15 · N004（左脚趾屈伸/侧装磁铁座盖） 装 1 颗磁铁，固化后用 2 枚 M2×5 + 2 枚 M2 螺母固定到旋转侧。
4. 把下表所列传感板装入 盘 A08-13 · X026（左脚趾屈伸/传感板托夹），再用 1 枚 M3×8 + 1 枚 M3 螺母固定到固定侧。传感器与磁铁相对，不能把两者都固定到同一旋转骨段。
5. 局部慢慢活动，确认每一相邻活动面不挤压垫片、PCB 和线束。按需要的手感调保持力即可；当前可用行程由实物相邻件与线束决定，软件 raw_limits 不是要求你硬拧到的机械行程。

| 电路端口 / 中央板位号 | 测量轴 | 传感板装在 | 对应磁铁装在 | 每根线建议长度 |
| --- | --- | --- | --- | --- |
| 端口 C08 / J49 | `ball_l.flex/r0` | 盘 A08-13 · X026（左脚趾屈伸/传感板托夹） | 盘 A08-15 · N004（左脚趾屈伸/侧装磁铁座盖） | 750 mm × 5 根，首件后定长 |

本步完成检查：C08 标签对应正确；磁铁不相对载体打滑；转轴可手动摆动并保持；线先松放到背盒方向，留待走线章节统一固定。

### S22 · 右髋／大腿

连接 **盘 A03-01 · X038（骨架／骨盆） → 盘 A09-01 · X080（骨架／右髋／大腿）**。本步需打开打印盘：A03、A09。

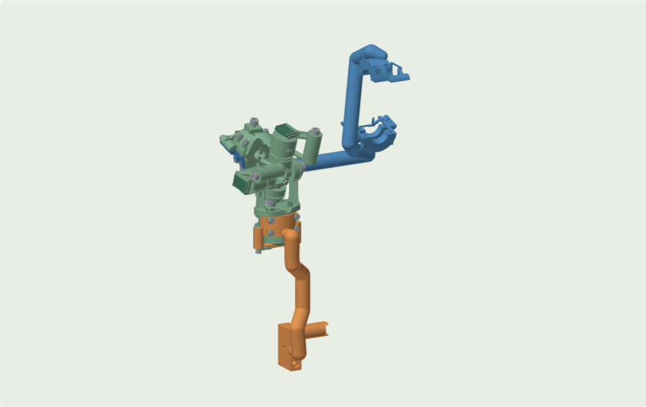
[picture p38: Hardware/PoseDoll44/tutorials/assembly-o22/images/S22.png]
S22 右髋／大腿 · CAD 装配位置；蓝色为父骨架，橙色为子骨架


| 取件位置 | 名称 / 原始键 | 本步用途 / 状态 |
| --- | --- | --- |
| 盘 A03-01 · X038（骨架／骨盆） | `frame/pelvis` | 已在 S01 取用，直接使用已装骨架。一体骨架；已包含 腰部/P_固定半壳、左髋／大腿/P_固定半壳、右髋／大腿/P_固定半壳 |
| 盘 A09-01 · X080（骨架／右髋／大腿） | `frame/thigh_r` | 本步新取。一体骨架；已包含 右髋／大腿/D_固定半壳、右膝／小腿屈伸/固定侧关节座 |
| 盘 A09-02 · P117（右髋／大腿/下环） | `thigh_r/C14` | 本步新取。十字关节下环；先装内部螺母和 M3 反力垫 |
| 盘 A09-03 · P115（右髋／大腿/下叉） | `thigh_r/C01` | 本步新取。十字关节叉臂；与另一叉臂正交穿装 |
| 盘 A09-04 · P116（右髋／大腿/上叉） | `thigh_r/C02` | 本步新取。十字关节叉臂；与另一叉臂正交穿装 |
| 盘 A09-05 · X076（右髋／大腿/P_活动半壳） | `thigh_r/P_case_plus` | 本步新取。端轴可拆半壳；4 枚 M2×20 合壳 |
| 盘 A09-06 · X079（右髋／大腿/D_活动半壳） | `thigh_r/D_case_plus` | 本步新取。端轴可拆半壳；4 枚 M2×20 合壳 |
| 盘 A09-07 · P118（右髋／大腿/上环盖） | `thigh_r/C15` | 本步新取。十字关节上环盖；4 枚 M1.6×6 合环 |
| 盘 A09-08 · X013（右髋／大腿/下叉_传感板托夹） | `thigh_r/C01_sensor_cassette` | 本步新取。固定传感 PCB；先滑入板，再装到关节 |
| 盘 A09-09 · X014（右髋／大腿/上叉_传感板托夹） | `thigh_r/C02_sensor_cassette` | 本步新取。固定传感 PCB；先滑入板，再装到关节 |
| 盘 A09-16 · P013（右髋／大腿/P_磁铁端盖） | `thigh_r/P_magnet_cap` | 本步新取。端轴磁铁端盖；2 枚 M2×4 固定 |
| 盘 A09-17 · P126（右髋／大腿/D_磁铁端盖） | `thigh_r/D_magnet_cap` | 本步新取。端轴磁铁端盖；2 枚 M2×4 固定 |
| 盘 A09-18 · N003（右髋／大腿/下叉_侧装磁铁座盖） | `thigh_r/C01_magnet_cartridge` | 本步新取。侧面装入并粘固磁铁；旋转侧用 2 枚 M2×5 固定 |
| 盘 A09-19 · N003（右髋／大腿/上叉_侧装磁铁座盖） | `thigh_r/C02_magnet_cartridge` | 本步新取。侧面装入并粘固磁铁；旋转侧用 2 枚 M2×5 固定 |
| 盘 A09-22 · X074（右髋／大腿/P_板夹_-14） | `thigh_r/P_pcb_clip_-14` | 本步新取。端轴传感 PCB 的一侧板夹，与另一板夹成对使用 |
| 盘 A09-23 · X075（右髋／大腿/P_板夹_+14） | `thigh_r/P_pcb_clip_+14` | 本步新取。端轴传感 PCB 的一侧板夹，与另一板夹成对使用 |
| 盘 A09-24 · X077（右髋／大腿/D_板夹_-14） | `thigh_r/D_pcb_clip_-14` | 本步新取。端轴传感 PCB 的一侧板夹，与另一板夹成对使用 |
| 盘 A09-25 · X078（右髋／大腿/D_板夹_+14） | `thigh_r/D_pcb_clip_+14` | 本步新取。端轴传感 PCB 的一侧板夹，与另一板夹成对使用 |
| 盘 A09-26 · P012（右髋／大腿/P_径向摩擦块） | `thigh_r/P_radial_pad` | 本步新取。端轴径向摩擦块；凹面朝轴，M3×8 顶压外侧 |
| 盘 A09-27 · P125（右髋／大腿/D_径向摩擦块） | `thigh_r/D_radial_pad` | 本步新取。端轴径向摩擦块；凹面朝轴，M3×8 顶压外侧 |

| 五金 / 磁铁 | 本步数量 | 位置 |
| --- | --- | --- |
| M4大平垫圈：外径12、厚1 mm，实物能自由套过Φ4光杆 | 8 | 旋转叉耳两侧，每个支点 2 片 |
| A8不锈钢碟簧：8×4.2×0.4，自由高0.6 mm | 8 | 每个轴肩支点 2 片，相对安装 |
| M4普通平垫圈：外径9、厚0.8 mm，实物通孔验证 | 4 | 螺钉头下、碟簧外侧，每个支点 1 片 |
| 轴肩螺钉 Φ4×8 / M3×0.5，螺纹长6 mm；头Φ7×3，内六角3 mm | 4 | 轴肩摩擦支点，铰链 1 处 / 十字核心 4 处 |
| M3普通六角螺母（不要锁紧螺母替代外形） | 8 | 轴肩捕获窝、板托夹固定点，以及有 P/D 端轴时的摩擦调节槽 |
| M3大平垫圈：外径9、厚0.8 mm，实物通孔验证 | 4 | 固定座内侧，每个支点 1 片反力垫 |
| M1.6×6 内六角圆柱头螺钉；按CAD头径/头高核对 | 4 | C14 / C15 合环 |
| M1.6普通六角螺母（不要锁紧螺母替代外形） | 4 | C14 / C15 合环螺钉对应捕获窝 |
| M2普通六角螺母（不要锁紧螺母替代外形） | 20 | 本步各 M2 螺钉对应捕获窝，一螺钉配一螺母 |
| M2×5 内六角圆柱头螺钉；按CAD头径/头高核对 | 4 | N003 / N004 侧装磁铁座盖，每个 2 枚 |
| 径向两极磁铁 Φ6×2.5 mm；直径方向充磁，不能买轴向充磁 | 4 | 本步每个实测轴 1 颗，位于对应磁铁座 / 端盖 |
| M3×8 内六角圆柱头螺钉；按CAD头径/头高核对 | 4 | 每只传感板托夹 1 枚；每个 P/D 摩擦块调节 1 枚 |
| M2×20 内六角圆柱头螺钉；按CAD头径/头高核对 | 8 | P / D 端轴固定半壳与活动半壳合壳 |
| M2×4 内六角圆柱头螺钉；按CAD头径/头高核对 | 4 | P / D 端轴的磁铁端盖 |
| M2×8 内六角圆柱头螺钉；按CAD头径/头高核对 | 4 | P / D 端轴的成对 PCB 板夹 |

1. 取 盘 A09-02 · P117（右髋／大腿/下环）、盘 A09-07 · P118（右髋／大腿/上环盖）。两叉分别是 盘 A09-03 · P115（右髋／大腿/下叉） 的 C01 部位、盘 A09-04 · P116（右髋／大腿/上叉） 的 C02 部位；已经连在骨架上的叉不要拆分或另找重复打印件。
2. 按 [G2](#G2) 先预装 4 枚 M3 螺母与 4 片 M3 反力垫，把两叉交叉放入环，再按 G1 装四套轴肩结构；随后用 4 枚 M1.6×6 + 4 枚 M1.6 螺母合环。
3. P 端按 [G3](#G3)：盘 A03-01 · X038（骨架／骨盆） 内是一体固定半壳，容纳 盘 A09-03 · P115（右髋／大腿/下叉） 的圆轴与限位环；装 盘 A09-26 · P012（右髋／大腿/P_径向摩擦块），M3×8 + M3 螺母调摩擦。用 盘 A09-05 · X076（右髋／大腿/P_活动半壳） 和 4 枚 M2×20 + 4 枚 M2 螺母合壳。磁铁端盖用 2 枚 M2×4 + 2 枚 M2 螺母；两只 PCB 板夹用 2 枚 M2×8 + 2 枚 M2 螺母。
4. D 端按 [G3](#G3)：盘 A09-01 · X080（骨架／右髋／大腿） 内是一体固定半壳，容纳 盘 A09-04 · P116（右髋／大腿/上叉） 的圆轴与限位环；装 盘 A09-27 · P125（右髋／大腿/D_径向摩擦块），M3×8 + M3 螺母调摩擦。用 盘 A09-06 · X079（右髋／大腿/D_活动半壳） 和 4 枚 M2×20 + 4 枚 M2 螺母合壳。磁铁端盖用 2 枚 M2×4 + 2 枚 M2 螺母；两只 PCB 板夹用 2 枚 M2×8 + 2 枚 M2 螺母。
5. C01 测量端按 [G4](#G4)：盘 A09-18 · N003（右髋／大腿/下叉_侧装磁铁座盖） 内放 1 颗磁铁，用 2 枚 M2×5 + 2 枚 M2 螺母固定到叉臂端；盘 A09-08 · X013（右髋／大腿/下叉_传感板托夹） 先滑入传感板，再用 M3×8 + M3 螺母固定。
6. C02 测量端按 [G4](#G4)：盘 A09-19 · N003（右髋／大腿/上叉_侧装磁铁座盖） 内放 1 颗磁铁，用 2 枚 M2×5 + 2 枚 M2 螺母固定到叉臂端；盘 A09-09 · X014（右髋／大腿/上叉_传感板托夹） 先滑入传感板，再用 M3×8 + M3 螺母固定。
7. 局部慢慢活动，确认每一相邻活动面不挤压垫片、PCB 和线束。按需要的手感调保持力即可；当前可用行程由实物相邻件与线束决定，软件 raw_limits 不是要求你硬拧到的机械行程。

| 电路端口 / 中央板位号 | 测量轴 | 传感板装在 | 对应磁铁装在 | 每根线建议长度 |
| --- | --- | --- | --- | --- |
| 端口 C09 / J50 | `thigh_r/r0` | 盘 A09-22 · X074（右髋／大腿/P_板夹_-14） + 盘 A09-23 · X075（右髋／大腿/P_板夹_+14） | 盘 A09-16 · P013（右髋／大腿/P_磁铁端盖） | 400 mm × 5 根，首件后定长 |
| 端口 C10 / J51 | `thigh_r/r1` | 盘 A09-08 · X013（右髋／大腿/下叉_传感板托夹） | 盘 A09-18 · N003（右髋／大腿/下叉_侧装磁铁座盖） | 600 mm × 5 根，首件后定长 |
| 端口 C11 / J52 | `thigh_r/r2` | 盘 A09-09 · X014（右髋／大腿/上叉_传感板托夹） | 盘 A09-19 · N003（右髋／大腿/上叉_侧装磁铁座盖） | 550 mm × 5 根，首件后定长 |
| 端口 C12 / J53 | `thigh_r/r3` | 盘 A09-24 · X077（右髋／大腿/D_板夹_-14） + 盘 A09-25 · X078（右髋／大腿/D_板夹_+14） | 盘 A09-17 · P126（右髋／大腿/D_磁铁端盖） | 525 mm × 5 根，首件后定长 |

本步完成检查：C09、C10、C11、C12 标签对应正确；磁铁不相对载体打滑；转轴可手动摆动并保持；线先松放到背盒方向，留待走线章节统一固定。

### S23 · 右膝／小腿屈伸

连接 **盘 A09-01 · X080（骨架／右髋／大腿） → 盘 A10-01 · W006（骨架／右膝／小腿）**。本步需打开打印盘：A09、A10。

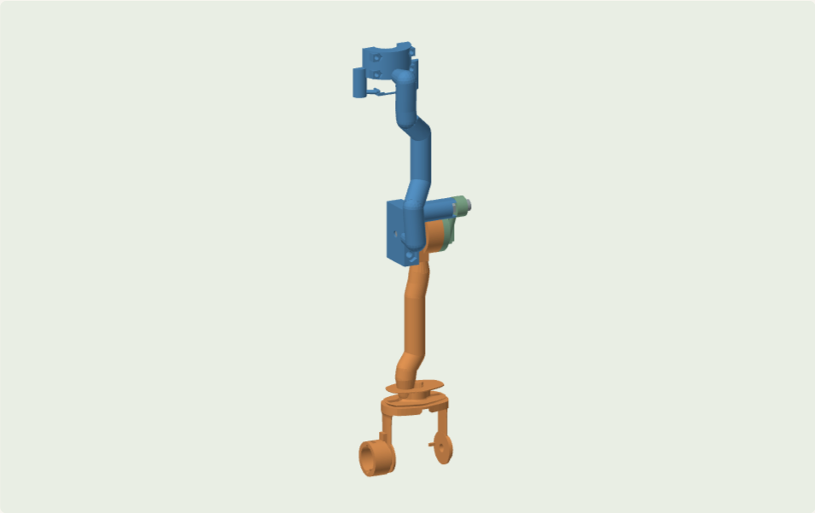
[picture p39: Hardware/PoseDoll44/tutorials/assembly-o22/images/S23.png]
S23 右膝／小腿屈伸 · CAD 装配位置；蓝色为父骨架，橙色为子骨架


| 取件位置 | 名称 / 原始键 | 本步用途 / 状态 |
| --- | --- | --- |
| 盘 A09-01 · X080（骨架／右髋／大腿） | `frame/thigh_r` | 已在 S22 取用，直接使用已装骨架。一体骨架；已包含 右髋／大腿/D_固定半壳、右膝／小腿屈伸/固定侧关节座 |
| 盘 A10-01 · W006（骨架／右膝／小腿） | `frame/calf_r` | 本步新取。一体骨架；已包含 右踝／脚掌/上叉、右膝／小腿屈伸/旋转侧叉耳 |
| 盘 A09-12 · X033（右膝／小腿屈伸/传感板托夹） | `calf_r.flex/sensor_cassette` | 本步新取。固定传感 PCB；先滑入板，再装到关节 |
| 盘 A09-14 · N004（右膝／小腿屈伸/侧装磁铁座盖） | `calf_r.flex/magnet_cartridge` | 本步新取。侧面装入并粘固磁铁；旋转侧用 2 枚 M2×5 固定 |

| 五金 / 磁铁 | 本步数量 | 位置 |
| --- | --- | --- |
| M4大平垫圈：外径12、厚1 mm，实物能自由套过Φ4光杆 | 2 | 旋转叉耳两侧，每个支点 2 片 |
| A8不锈钢碟簧：8×4.2×0.4，自由高0.6 mm | 2 | 每个轴肩支点 2 片，相对安装 |
| M4普通平垫圈：外径9、厚0.8 mm，实物通孔验证 | 1 | 螺钉头下、碟簧外侧，每个支点 1 片 |
| 轴肩螺钉 Φ4×8 / M3×0.5，螺纹长6 mm；头Φ7×3，内六角3 mm | 1 | 轴肩摩擦支点，铰链 1 处 / 十字核心 4 处 |
| M3普通六角螺母（不要锁紧螺母替代外形） | 2 | 轴肩捕获窝、板托夹固定点，以及有 P/D 端轴时的摩擦调节槽 |
| M3大平垫圈：外径9、厚0.8 mm，实物通孔验证 | 1 | 固定座内侧，每个支点 1 片反力垫 |
| M3×8 内六角圆柱头螺钉；按CAD头径/头高核对 | 1 | 每只传感板托夹 1 枚；每个 P/D 摩擦块调节 1 枚 |
| M2普通六角螺母（不要锁紧螺母替代外形） | 2 | 本步各 M2 螺钉对应捕获窝，一螺钉配一螺母 |
| M2×5 内六角圆柱头螺钉；按CAD头径/头高核对 | 2 | N003 / N004 侧装磁铁座盖，每个 2 枚 |
| 径向两极磁铁 Φ6×2.5 mm；直径方向充磁，不能买轴向充磁 | 1 | 本步每个实测轴 1 颗，位于对应磁铁座 / 端盖 |

1. 将 盘 A09-01 · X080（骨架／右髋／大腿） 的固定关节座与 盘 A10-01 · W006（骨架／右膝／小腿） 的旋转叉耳摆到图示连接位置。侧槽尚未被挡住时，预装 1 枚 M3 螺母与 1 片 M3 反力垫。
2. 按 [G5 一体铰链](#G5) 和 [G1 轴肩层次](#G1) 装 1 套轴肩结构。单个支点为 1 枚轴肩螺钉、2 片 M4 大垫、2 片 A8 碟簧、1 片 M4 普通垫，外加刚才放入的螺母和反力垫。
3. 调整摩擦后，按 [G4](#G4) 给 盘 A09-14 · N004（右膝／小腿屈伸/侧装磁铁座盖） 装 1 颗磁铁，固化后用 2 枚 M2×5 + 2 枚 M2 螺母固定到旋转侧。
4. 把下表所列传感板装入 盘 A09-12 · X033（右膝／小腿屈伸/传感板托夹），再用 1 枚 M3×8 + 1 枚 M3 螺母固定到固定侧。传感器与磁铁相对，不能把两者都固定到同一旋转骨段。
5. 局部慢慢活动，确认每一相邻活动面不挤压垫片、PCB 和线束。按需要的手感调保持力即可；当前可用行程由实物相邻件与线束决定，软件 raw_limits 不是要求你硬拧到的机械行程。

| 电路端口 / 中央板位号 | 测量轴 | 传感板装在 | 对应磁铁装在 | 每根线建议长度 |
| --- | --- | --- | --- | --- |
| 端口 C13 / J54 | `calf_r.flex/r0` | 盘 A09-12 · X033（右膝／小腿屈伸/传感板托夹） | 盘 A09-14 · N004（右膝／小腿屈伸/侧装磁铁座盖） | 525 mm × 5 根，首件后定长 |

本步完成检查：C13 标签对应正确；磁铁不相对载体打滑；转轴可手动摆动并保持；线先松放到背盒方向，留待走线章节统一固定。

### S24 · 右踝／脚掌

连接 **盘 A10-01 · W006（骨架／右膝／小腿） → 盘 A10-08 · W017（骨架／右踝／脚掌）**。本步需打开打印盘：A09、A10。

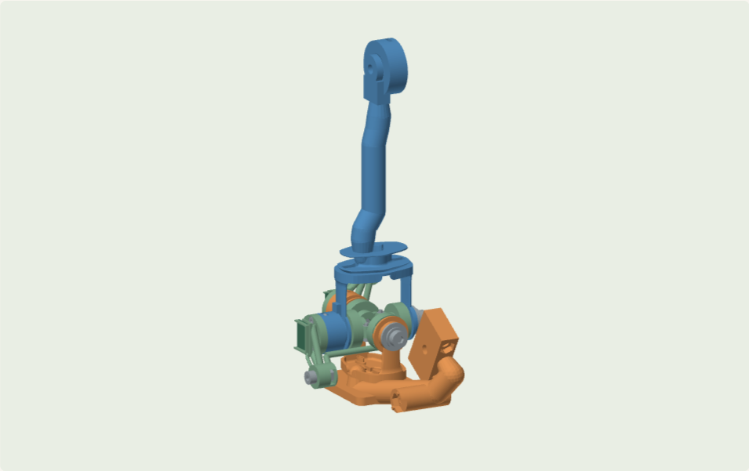
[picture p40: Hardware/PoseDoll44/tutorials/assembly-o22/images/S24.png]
S24 右踝／脚掌 · CAD 装配位置；蓝色为父骨架，橙色为子骨架


| 取件位置 | 名称 / 原始键 | 本步用途 / 状态 |
| --- | --- | --- |
| 盘 A10-01 · W006（骨架／右膝／小腿） | `frame/calf_r` | 已在 S23 取用，直接使用已装骨架。一体骨架；已包含 右踝／脚掌/上叉、右膝／小腿屈伸/旋转侧叉耳 |
| 盘 A10-08 · W017（骨架／右踝／脚掌） | `frame/foot_r` | 本步新取。一体骨架；已包含 右踝／脚掌/下叉、右脚趾屈伸/固定侧关节座 |
| 盘 A09-10 · X017（右踝／脚掌/下叉_传感板托夹） | `foot_r/C01_sensor_cassette` | 本步新取。固定传感 PCB；先滑入板，再装到关节 |
| 盘 A09-11 · X018（右踝／脚掌/上叉_传感板托夹） | `foot_r/C02_sensor_cassette` | 本步新取。固定传感 PCB；先滑入板，再装到关节 |
| 盘 A09-20 · N003（右踝／脚掌/下叉_侧装磁铁座盖） | `foot_r/C01_magnet_cartridge` | 本步新取。侧面装入并粘固磁铁；旋转侧用 2 枚 M2×5 固定 |
| 盘 A09-21 · N003（右踝／脚掌/上叉_侧装磁铁座盖） | `foot_r/C02_magnet_cartridge` | 本步新取。侧面装入并粘固磁铁；旋转侧用 2 枚 M2×5 固定 |
| 盘 A10-04 · P130（右踝／脚掌/下环） | `foot_r/C14` | 本步新取。十字关节下环；先装内部螺母和 M3 反力垫 |
| 盘 A10-10 · P131（右踝／脚掌/上环盖） | `foot_r/C15` | 本步新取。十字关节上环盖；4 枚 M1.6×6 合环 |

| 五金 / 磁铁 | 本步数量 | 位置 |
| --- | --- | --- |
| M4大平垫圈：外径12、厚1 mm，实物能自由套过Φ4光杆 | 8 | 旋转叉耳两侧，每个支点 2 片 |
| A8不锈钢碟簧：8×4.2×0.4，自由高0.6 mm | 8 | 每个轴肩支点 2 片，相对安装 |
| M4普通平垫圈：外径9、厚0.8 mm，实物通孔验证 | 4 | 螺钉头下、碟簧外侧，每个支点 1 片 |
| 轴肩螺钉 Φ4×8 / M3×0.5，螺纹长6 mm；头Φ7×3，内六角3 mm | 4 | 轴肩摩擦支点，铰链 1 处 / 十字核心 4 处 |
| M3普通六角螺母（不要锁紧螺母替代外形） | 6 | 轴肩捕获窝、板托夹固定点，以及有 P/D 端轴时的摩擦调节槽 |
| M3大平垫圈：外径9、厚0.8 mm，实物通孔验证 | 4 | 固定座内侧，每个支点 1 片反力垫 |
| M1.6×6 内六角圆柱头螺钉；按CAD头径/头高核对 | 4 | C14 / C15 合环 |
| M1.6普通六角螺母（不要锁紧螺母替代外形） | 4 | C14 / C15 合环螺钉对应捕获窝 |
| M2普通六角螺母（不要锁紧螺母替代外形） | 4 | 本步各 M2 螺钉对应捕获窝，一螺钉配一螺母 |
| M2×5 内六角圆柱头螺钉；按CAD头径/头高核对 | 4 | N003 / N004 侧装磁铁座盖，每个 2 枚 |
| 径向两极磁铁 Φ6×2.5 mm；直径方向充磁，不能买轴向充磁 | 2 | 本步每个实测轴 1 颗，位于对应磁铁座 / 端盖 |
| M3×8 内六角圆柱头螺钉；按CAD头径/头高核对 | 2 | 每只传感板托夹 1 枚；每个 P/D 摩擦块调节 1 枚 |

1. 取 盘 A10-04 · P130（右踝／脚掌/下环）、盘 A10-10 · P131（右踝／脚掌/上环盖）。两叉分别是 盘 A10-08 · W017（骨架／右踝／脚掌） 的 C01 部位、盘 A10-01 · W006（骨架／右膝／小腿） 的 C02 部位；已经连在骨架上的叉不要拆分或另找重复打印件。
2. 按 [G2](#G2) 先预装 4 枚 M3 螺母与 4 片 M3 反力垫，把两叉交叉放入环，再按 G1 装四套轴肩结构；随后用 4 枚 M1.6×6 + 4 枚 M1.6 螺母合环。
3. C01 测量端按 [G4](#G4)：盘 A09-20 · N003（右踝／脚掌/下叉_侧装磁铁座盖） 内放 1 颗磁铁，用 2 枚 M2×5 + 2 枚 M2 螺母固定到叉臂端；盘 A09-10 · X017（右踝／脚掌/下叉_传感板托夹） 先滑入传感板，再用 M3×8 + M3 螺母固定。
4. C02 测量端按 [G4](#G4)：盘 A09-21 · N003（右踝／脚掌/上叉_侧装磁铁座盖） 内放 1 颗磁铁，用 2 枚 M2×5 + 2 枚 M2 螺母固定到叉臂端；盘 A09-11 · X018（右踝／脚掌/上叉_传感板托夹） 先滑入传感板，再用 M3×8 + M3 螺母固定。
5. 局部慢慢活动，确认每一相邻活动面不挤压垫片、PCB 和线束。按需要的手感调保持力即可；当前可用行程由实物相邻件与线束决定，软件 raw_limits 不是要求你硬拧到的机械行程。

| 电路端口 / 中央板位号 | 测量轴 | 传感板装在 | 对应磁铁装在 | 每根线建议长度 |
| --- | --- | --- | --- | --- |
| 端口 C14 / J55 | `foot_r/r0` | 盘 A09-10 · X017（右踝／脚掌/下叉_传感板托夹） | 盘 A09-20 · N003（右踝／脚掌/下叉_侧装磁铁座盖） | 700 mm × 5 根，首件后定长 |
| 端口 C15 / J56 | `foot_r/r1` | 盘 A09-11 · X018（右踝／脚掌/上叉_传感板托夹） | 盘 A09-21 · N003（右踝／脚掌/上叉_侧装磁铁座盖） | 700 mm × 5 根，首件后定长 |

本步完成检查：C14、C15 标签对应正确；磁铁不相对载体打滑；转轴可手动摆动并保持；线先松放到背盒方向，留待走线章节统一固定。

### S25 · 右脚趾屈伸

连接 **盘 A10-08 · W017（骨架／右踝／脚掌） → 盘 A10-06 · W001（骨架／右脚趾）**。本步需打开打印盘：A09、A10。

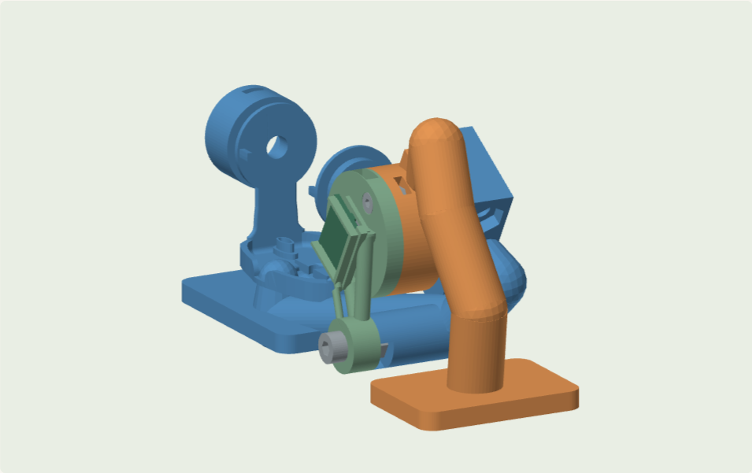
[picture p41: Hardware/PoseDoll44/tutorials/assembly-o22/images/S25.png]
S25 右脚趾屈伸 · CAD 装配位置；蓝色为父骨架，橙色为子骨架


| 取件位置 | 名称 / 原始键 | 本步用途 / 状态 |
| --- | --- | --- |
| 盘 A10-08 · W017（骨架／右踝／脚掌） | `frame/foot_r` | 已在 S24 取用，直接使用已装骨架。一体骨架；已包含 右踝／脚掌/下叉、右脚趾屈伸/固定侧关节座 |
| 盘 A10-06 · W001（骨架／右脚趾） | `frame/ball_r` | 本步新取。一体骨架；已包含 右脚趾屈伸/旋转侧叉耳 |
| 盘 A09-13 · X034（右脚趾屈伸/传感板托夹） | `ball_r.flex/sensor_cassette` | 本步新取。固定传感 PCB；先滑入板，再装到关节 |
| 盘 A09-15 · N004（右脚趾屈伸/侧装磁铁座盖） | `ball_r.flex/magnet_cartridge` | 本步新取。侧面装入并粘固磁铁；旋转侧用 2 枚 M2×5 固定 |

| 五金 / 磁铁 | 本步数量 | 位置 |
| --- | --- | --- |
| M4大平垫圈：外径12、厚1 mm，实物能自由套过Φ4光杆 | 2 | 旋转叉耳两侧，每个支点 2 片 |
| A8不锈钢碟簧：8×4.2×0.4，自由高0.6 mm | 2 | 每个轴肩支点 2 片，相对安装 |
| M4普通平垫圈：外径9、厚0.8 mm，实物通孔验证 | 1 | 螺钉头下、碟簧外侧，每个支点 1 片 |
| 轴肩螺钉 Φ4×8 / M3×0.5，螺纹长6 mm；头Φ7×3，内六角3 mm | 1 | 轴肩摩擦支点，铰链 1 处 / 十字核心 4 处 |
| M3普通六角螺母（不要锁紧螺母替代外形） | 2 | 轴肩捕获窝、板托夹固定点，以及有 P/D 端轴时的摩擦调节槽 |
| M3大平垫圈：外径9、厚0.8 mm，实物通孔验证 | 1 | 固定座内侧，每个支点 1 片反力垫 |
| M3×8 内六角圆柱头螺钉；按CAD头径/头高核对 | 1 | 每只传感板托夹 1 枚；每个 P/D 摩擦块调节 1 枚 |
| M2普通六角螺母（不要锁紧螺母替代外形） | 2 | 本步各 M2 螺钉对应捕获窝，一螺钉配一螺母 |
| M2×5 内六角圆柱头螺钉；按CAD头径/头高核对 | 2 | N003 / N004 侧装磁铁座盖，每个 2 枚 |
| 径向两极磁铁 Φ6×2.5 mm；直径方向充磁，不能买轴向充磁 | 1 | 本步每个实测轴 1 颗，位于对应磁铁座 / 端盖 |

1. 将 盘 A10-08 · W017（骨架／右踝／脚掌） 的固定关节座与 盘 A10-06 · W001（骨架／右脚趾） 的旋转叉耳摆到图示连接位置。侧槽尚未被挡住时，预装 1 枚 M3 螺母与 1 片 M3 反力垫。
2. 按 [G5 一体铰链](#G5) 和 [G1 轴肩层次](#G1) 装 1 套轴肩结构。单个支点为 1 枚轴肩螺钉、2 片 M4 大垫、2 片 A8 碟簧、1 片 M4 普通垫，外加刚才放入的螺母和反力垫。
3. 调整摩擦后，按 [G4](#G4) 给 盘 A09-15 · N004（右脚趾屈伸/侧装磁铁座盖） 装 1 颗磁铁，固化后用 2 枚 M2×5 + 2 枚 M2 螺母固定到旋转侧。
4. 把下表所列传感板装入 盘 A09-13 · X034（右脚趾屈伸/传感板托夹），再用 1 枚 M3×8 + 1 枚 M3 螺母固定到固定侧。传感器与磁铁相对，不能把两者都固定到同一旋转骨段。
5. 局部慢慢活动，确认每一相邻活动面不挤压垫片、PCB 和线束。按需要的手感调保持力即可；当前可用行程由实物相邻件与线束决定，软件 raw_limits 不是要求你硬拧到的机械行程。

| 电路端口 / 中央板位号 | 测量轴 | 传感板装在 | 对应磁铁装在 | 每根线建议长度 |
| --- | --- | --- | --- | --- |
| 端口 C16 / J57 | `ball_r.flex/r0` | 盘 A09-13 · X034（右脚趾屈伸/传感板托夹） | 盘 A09-15 · N004（右脚趾屈伸/侧装磁铁座盖） | 725 mm × 5 根，首件后定长 |

本步完成检查：C16 标签对应正确；磁铁不相对载体打滑；转轴可手动摆动并保持；线先松放到背盒方向，留待走线章节统一固定。

## 05 · 电路、中央板与背盒

以下区分“交给工厂做的电路”和“你总装时需要做的插接”。整机没有电机，也不需要电池、摄像头或旧版 AS5048A 串链排线。传感板各自五线返回中央板。

| 要准备的东西 | 数量 / 规格 | 交付与装配要求 |
| --- | --- | --- |
| MT6701 传感成品板 | 46 使用 + 2 完整备件；12×10×1 mm；SOP8 | 裸板报价口径 50 张、装 48 张；芯片 50 颗含 2 颗加工损耗，不是多装 50 路。板端五线由工厂焊好并标号。 |
| 中央采集成品板 | 1 块；80×94×1.6 mm、四层 | 裸板最小订单按 5 张核价，只装 1 张。使用最终 O22 PCB 与 BOM，不用 placement / route_input 中间板。 |
| XIAO ESP32S3 普通版 | 1 块；两排各 7 针、中心距 15.24 mm | 中央板顶面到 XIAO PCB 底面 4.0 mm，由工厂用盘 A03-09 P242 量规定位焊接后取出。 |
| 中央板传感插座 | 46 个 BM05B-SRSS-TB；SH 1.0 mm 5P 顶插 | 由工厂贴在中央板上；已经计入 PCBA，不再购买另一套。 |
| 线端塑壳 / 压接端子 | 48 个 SHR-05V-S + 240 个 SSH-003T-P0.2-H | 对应 46 套使用线 + 2 套完整备用线；可另留 2 塑壳 / 20 端子作为加工损耗。传感 PCB 端直接焊线，没有第二套插座。 |
| 五色柔性线 | 单根 AWG30 铜线，外径 0.4–0.7 mm | 每色 22.75 m 实装，加两套 750 mm 备件为 24.25 m；再加 10% 下料损耗约 26.68 m/色，五色约 133.38 m。下料表见下一节。 |
| 外部稳压电源与输入尾线 | 5V / 2A 电源 1 个；PH 2P 线端 1 套 | J3 为 PH 2.0 mm，不是传感 SH 1.0 mm。线端 PHR-2 + 2 枚 SPH-002T-P0.5S；可用符合端子绝缘尺寸的 AWG24 柔线。适配器端按实际插头定做，工厂标明正负与导通。 |
| USB 数据线 | 1 根，接 XIAO USB-C | 必须支持数据。线长按桌面布置，插头外形须通过背盒 USB 开口。 |
| 2.5 mm 扎带 | 65 根净用，建议另备 10 根 | 用于局部应力释放、沿骨架分束及背盖；不绕过旋转缝把两骨段锁在一起。 |
| 磁铁固持胶 / 电子固线胶 | 按实际小包装准备 | 磁铁侧壁非导电防转胶；板线出口用可返修、中性柔性电子胶。工厂固线已计入工序时不重复收费。 |

连接器系列与端子依据 [JST SH 官方图纸](https://www.jst-mfg.com/product/pdf/eng/eSH.pdf) 和 [JST PH 官方图纸](https://www.jst-mfg.com/product/pdf/eng/ePH.pdf)。输入尾线列在这里是为了把 J3 的配对件补充说明清楚，不是新增一块电路。实际总价仍按完整询价核算。

### 工厂贴片与焊线：使用这些文件

- [完整电子 BOM](../../bench/revO22/manufacturing/electronic_bom.tsv) 与 [首件加工要求](../../bench/revO22/manufacturing/RFQ.zh-CN.md) 一起给工厂；Gerber、钻孔与坐标文件在 [已保存工程包](../../bench/revO22/PoseDoll_O22_Engineering_Package.zip) 的 manufacturing 目录。
- 传感板每块：U1=MT6701CT-STD-R，C1=100nF X7R 16V 0603，C2=1µF X7R 16V 0603，R1=33Ω 0603 串联 DO，R2=10kΩ 0603 上拉。J1 是五个焊线焊盘，不是另购连接器。芯片脚 1/2 接供电，4 接地，6 为 DO，7 为 CLK，8 为 CSN；按封装圆点与 PCB pin 1 对齐，3/5 不接。
- 中央板主要有 U1/U2=SN74LVC244APWR，U3–U5=CD74HC4067PW，U6=SN74LVC125APWR，Q1=2N7002；由缓冲器、三组 16:1 选通和 MCU 侧电平接口完成采集，不把传感器 DO 直接跨接到 XIAO。
- 供电链为 J3 → F4 输入保护 → D1 SS14 → U7 AP3429AW5-7 + L1 2.2µH → F5 → SENSOR_3V45。F4=1206L110THR；F5=0467001.NR 1A 快断保险丝，不任意换成 PTC。
- 反馈 R50=316kΩ、R51=66.5kΩ，0.1%、≤25ppm/K，对应标称约 3.451V。C7/C8/C9 虽标称 22µF，仍需工厂返回直流偏压曲线；C7 在 4.1V 下有效容量至少 10µF，C8+C9 在 3.45V 下合计至少 20µF。当前候选料号未因教程编写而变成已实测批准。
- 板端焊线、端子压接、套管 / 柔性胶应力释放、端口双端标签、逐芯导通和无短路检查均由供应方完成。器件加焊料总高度不超过 1.85 mm；胶不得进入板托夹导轨或芯片对磁铁的间隙。

降压器依据 [AP3429 官方数据表](https://www.diodes.com/datasheet/download/AP3429.pdf)。完整逐位号 BOM 在网页附录可展开查看；器件采购和工厂焊接不是用户总装时额外重复购买的散件。

### S26 · 安装中央板与 XIAO

本步连接 盘 A02-01 · X046（骨架／胸部）、盘 A01-01 · X081（o22/背盒盖）；盘 A03-09 · P242（工具／XIAO 焊接间距量规） 仅在焊接定位时使用。打印盘 A01 的盖要等 A02 的胸架装好、电路检查完成后再盖；A03 的量规不留在里面。

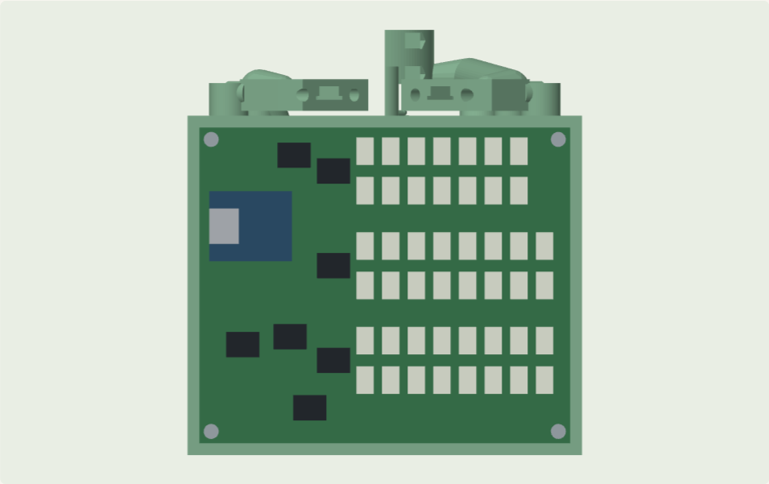
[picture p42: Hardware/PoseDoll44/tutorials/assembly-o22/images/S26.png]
S26 背盒与中央板 CAD，显示装配位置；接线完成前保留敞开状态


1. 让工厂按中央板焊接位置装 XIAO：USB 端口朝板上边缘，两排针间距 15.24 mm，PCB 之间净距 4.0 mm。插入 P242 量规定位后焊接，冷却并检查焊点，再取出量规。J2.7 的 XIAO 5V 不接传感供电，不能拉跨接线去 J3。
2. 把已完成台面电测的中央板放到胸架背盒四根柱上，旋转整块板使 USB-C 对准背盒专用 USB 开口，元件面朝盒外 / 盖板。四角孔对正后用 **4 枚塑料自攻 M2×6、头径≤4 mm** 交替拧入；不用金属 M2 螺母，也不用普通机牙螺钉强行攻塑料。
3. 从预留进线开口引入各身体分束，先按端口表插上短的躯干线，再接手臂、腿部线。端口多而密，捏塑壳插拔，不拉导线。留出电源、USB 插头和拆盖的维护余量。
4. 背盖先放在一旁。先完成单路、单组、左臂和全部通道检查，再收好余线、装背盖，用两条 2.5 mm 扎带穿现有固定槽固定；这两条计入 65 根，不增加盖板螺钉。盖上后再确认没有压住 U 环或线端。

USB 与外部电源的职责、传感电源及回传信号路径

中央板在桌面上的元件面视图，USB 朝图上方；装入背盒后以实体 USB 开口为准。A01 / B01 / C01 是电路端口，不是打印盘

### 五芯线的针序与供电边界

传感板焊线边朝下的正面针序；插头从背面看会镜像，请按针号核对

| 针号 | 颜色 | 传感板网络 | 中央板网络 / 功能 |
| --- | --- | --- | --- |
| 1 | 黑 | GND | 共同地 |
| 2 | 红 | +3V3（旧网络名称） | 实际接 SENSOR_3V45，标称约 3.451V |
| 3 | 蓝 | CLK | 本组 SSI 时钟 |
| 4 | 绿 | DO | 该轴独立返回，经对应 MUX 通道选通 |
| 5 | 黄 | CS_N | 本组片选 |

五根线逐根直通同号针，不交叉。板上叫 +3V3 不表示你应外加 3.3V；它由中央板统一受控供电。46 路都是独立回线，DO 不能并在一起，也不是上一块板出线接下一块板的串链。

### XIAO 引脚核对表（供工厂与排错使用）

| 中央板焊盘 | XIAO 引脚 | GPIO / 电源 | 最终板网络 |
| --- | --- | --- | --- |
| J1.1 | D0 | GPIO1 | EN_MCU |
| J1.2 | D1 | GPIO2 | A0_MCU |
| J1.3 | D2 | GPIO3，未用 | NC |
| J1.4 | D3 | GPIO4 | A1_MCU |
| J1.5 | D4 | GPIO5 | A2_MCU |
| J1.6 | D5 | GPIO6 | A3_MCU |
| J1.7 | D6 | GPIO43 | CS_MCU |
| J2.1 | D7 | GPIO44 | DO_C_MCU |
| J2.2 | D8 | GPIO7 | CLK_MCU |
| J2.3 | D9 | GPIO8 | DO_A_MCU |
| J2.4 | D10 | GPIO9 | DO_B_MCU |
| J2.5 | 3V3 | MCU 3.3V | MCU_3V3 |
| J2.6 | GND | 地 | GND |
| J2.7 | 5V | NC，保持不连接 | NC |

引脚命名依据 [Seeed XIAO ESP32S3 官方文档](https://wiki.seeedstudio.com/xiao_esp32s3_getting_started/)。表中的 J1/J2 是中央板位号；不是传感小板的 J1 五线焊盘。两排针方向按最终原生 PCB 核对，不能按左右两排都从上往下编号来猜。

## 06 · 46 路逐根接线与跨关节走线

下面的长度是**每一根**线的下料候选长度，每路需要黑红蓝绿黄各一根。沿用当前 routing_plan 的运动余量；必须先试装确认，不能按旧 wiring.json 的短报价估计裁线。尽量先做 1 根完整的左臂代表线束，再让工厂定批量长度。

1. 线从传感器出口先随所属刚性骨段固定，再跨关节形成 U 环，然后沿表中路径依次走到胸部中央板。支点扎带落在骨架实体上，不能跨旋转接缝。
2. 名义活动环半径 8 mm，装配最小弯曲半径 7 mm（可绕直径 14 mm 的光滑圆棒成形后取下）。线不绷直，也不让多余环卷进齿形止挡、叉耳或垫片。
3. 每动一个关节，看近端和远端线都没有拉动 PCB、压住相邻件或抽紧插头；再调整局部扎带。远处肢体碰撞可以通过姿势规避，但不能借此忽略相邻关节的夹线。
4. 线两端都标“电路端口 + raw_id”，例如“B05 / elbow_l.flex/r0”；打印件另外标“盘 A04-03”。在两个体系都叫 A01 的地方始终保留“盘”或“端口”前缀。

| 端口 / 位号 | 步骤 / 测量轴 | 传感板固定件 | 磁铁固定件 | 五色各一根 | 沿骨架到背盒 |
| --- | --- | --- | --- | --- | --- |
| A01 / J10 | [S01](#S01) 腰部 / `waist/r0` | 盘 A02-11 · X035（腰部/P_板夹_-14） + 盘 A02-10 · X036（腰部/P_板夹_+14） | 盘 A03-10 · P013（腰部/P_磁铁端盖） | 450 mm | 骨盆 → 腰部 → 胸部 |
| A02 / J11 | [S01](#S01) 腰部 / `waist/r1` | 盘 A03-06 · X001（腰部/下叉_传感板托夹） | 盘 A03-12 · N003（腰部/下叉_侧装磁铁座盖） | 450 mm | 腰部 → 骨盆 → 胸部 |
| A03 / J12 | [S01](#S01) 腰部 / `waist/r2` | 盘 A03-08 · X002（腰部/上叉_传感板托夹） | 盘 A03-13 · N003（腰部/上叉_侧装磁铁座盖） | 450 mm | 腰部 → 骨盆 → 胸部 |
| A04 / J13 | [S02](#S02) 胸部 / `chest/r0` | 盘 A02-09 · X039（胸部/P_板夹_-14） + 盘 A02-08 · X040（胸部/P_板夹_+14） | 盘 A03-11 · P029（胸部/P_磁铁端盖） | 450 mm | 腰部 → 骨盆 → 胸部 |
| A05 / J14 | [S02](#S02) 胸部 / `chest/r1` | 盘 A03-07 · X003（胸部/下叉_传感板托夹） | 盘 A03-14 · N003（胸部/下叉_侧装磁铁座盖） | 275 mm | 胸部 |
| A06 / J15 | [S02](#S02) 胸部 / `chest/r2` | 盘 A03-05 · X004（胸部/上叉_传感板托夹） | 盘 A03-15 · N003（胸部/上叉_侧装磁铁座盖） | 275 mm | 胸部 |
| A07 / J16 | [S03](#S03) 头颈 / `head/r0` | 盘 A01-15 · X043（头颈/P_板夹_-14） + 盘 A01-16 · X044（头颈/P_板夹_+14） | 盘 A01-11 · P040（头颈/P_磁铁端盖） | 225 mm | 胸部 |
| A08 / J17 | [S03](#S03) 头颈 / `head/r1` | 盘 A01-09 · X005（头颈/下叉_传感板托夹） | 盘 A01-13 · N003（头颈/下叉_侧装磁铁座盖） | 350 mm | 头颈 → 胸部 |
| A09 / J18 | [S03](#S03) 头颈 / `head/r2` | 盘 A01-10 · X006（头颈/上叉_传感板托夹） | 盘 A01-14 · N003（头颈/上叉_侧装磁铁座盖） | 350 mm | 头颈 → 胸部 |
| A10 / J19 | [S03](#S03) 头颈 / `head/r3` | 盘 A01-17 · X047（头颈/D_板夹_-14） + 盘 A01-18 · X048（头颈/D_板夹_+14） | 盘 A01-12 · P045（头颈/D_磁铁端盖） | 325 mm | 头颈 → 胸部 |
| A11 / J20 | [S04](#S04) 左锁骨前后 / `clavicle_l.protract/r0` | 盘 A05-22 · X019（左锁骨前后/传感板托夹） | 盘 A05-19 · N004（左锁骨前后/侧装磁铁座盖） | 200 mm | 胸部 |
| A12 / J21 | [S05](#S05) 左锁骨升降 / `clavicle_l.elevate/r0` | 盘 A05-10 · X020（左锁骨升降/传感板托夹） | 盘 A05-05 · N004（左锁骨升降/侧装磁铁座盖） | 325 mm | 左锁骨前后中间架 → 胸部 |
| A13 / J22 | [S11](#S11) 右锁骨前后 / `clavicle_r.protract/r0` | 盘 A07-02 · X027（右锁骨前后/传感板托夹） | 盘 A07-08 · N004（右锁骨前后/侧装磁铁座盖） | 200 mm | 胸部 |
| A14 / J23 | [S12](#S12) 右锁骨升降 / `clavicle_r.elevate/r0` | 盘 A06-12 · X028（右锁骨升降/传感板托夹） | 盘 A07-11 · N004（右锁骨升降/侧装磁铁座盖） | 275 mm | 右锁骨前后中间架 → 胸部 |
| B01 / J26 | [S06](#S06) 左肩／上臂 / `upperarm_l/r0` | 盘 A04-06 · X051（左肩／上臂/P_板夹_-14） + 盘 A04-09 · X052（左肩／上臂/P_板夹_+14） | 盘 A05-24 · P062（左肩／上臂/P_磁铁端盖） | 375 mm | 左锁骨 → 左锁骨前后中间架 → 胸部 |
| B02 / J27 | [S06](#S06) 左肩／上臂 / `upperarm_l/r1` | 盘 A05-07 · X007（左肩／上臂/下叉_传感板托夹） | 盘 A05-25 · N003（左肩／上臂/下叉_侧装磁铁座盖） | 550 mm | 左肩／上臂 → 左锁骨 → 左锁骨前后中间架 → 胸部 |
| B03 / J28 | [S06](#S06) 左肩／上臂 / `upperarm_l/r2` | 盘 A05-06 · X008（左肩／上臂/上叉_传感板托夹） | 盘 A05-26 · N003（左肩／上臂/上叉_侧装磁铁座盖） | 500 mm | 左肩／上臂 → 左锁骨 → 左锁骨前后中间架 → 胸部 |
| B04 / J29 | [S06](#S06) 左肩／上臂 / `upperarm_l/r3` | 盘 A04-08 · X055（左肩／上臂/D_板夹_-14） + 盘 A04-07 · X056（左肩／上臂/D_板夹_+14） | 盘 A05-23 · P067（左肩／上臂/D_磁铁端盖） | 475 mm | 左肩／上臂 → 左锁骨 → 左锁骨前后中间架 → 胸部 |
| B05 / J30 | [S07](#S07) 左肘屈伸 / `elbow_l.flex/r0` | 盘 A05-18 · X021（左肘屈伸/传感板托夹） | 盘 A05-20 · N004（左肘屈伸/侧装磁铁座盖） | 500 mm | 左肩／上臂 → 左锁骨 → 左锁骨前后中间架 → 胸部 |
| B06 / J31 | [S08](#S08) 左前臂扭转 / `forearm_l.twist/r0` | 盘 A05-13 · X022（左前臂扭转/传感板托夹） | 盘 A05-12 · N004（左前臂扭转/侧装磁铁座盖） | 550 mm | 左肘 → 左肩／上臂 → 左锁骨 → 左锁骨前后中间架 → 胸部 |
| B07 / J32 | [S09](#S09) 左手腕屈伸 / `hand_l.flex/r0` | 盘 A05-21 · X023（左手腕屈伸/传感板托夹） | 盘 A05-17 · N004（左手腕屈伸/侧装磁铁座盖） | 625 mm | 左前臂 → 左肘 → 左肩／上臂 → 左锁骨 → 左锁骨前后中间架 → 胸部 |
| B08 / J33 | [S10](#S10) 左手腕侧摆 / `hand_l.deviate/r0` | 盘 A05-15 · X024（左手腕侧摆/传感板托夹） | 盘 A05-11 · N004（左手腕侧摆/侧装磁铁座盖） | 675 mm | 左腕屈伸中间架 → 左前臂 → 左肘 → 左肩／上臂 → 左锁骨 → 左锁骨前后中间架 → 胸部 |
| B09 / J34 | [S13](#S13) 右肩／上臂 / `upperarm_r/r0` | 盘 A07-19 · X059（右肩／上臂/P_板夹_-14） + 盘 A07-21 · X060（右肩／上臂/P_板夹_+14） | 盘 A07-13 · P084（右肩／上臂/P_磁铁端盖） | 350 mm | 右锁骨 → 右锁骨前后中间架 → 胸部 |
| B10 / J35 | [S13](#S13) 右肩／上臂 / `upperarm_r/r1` | 盘 A06-13 · X009（右肩／上臂/下叉_传感板托夹） | 盘 A07-16 · N003（右肩／上臂/下叉_侧装磁铁座盖） | 550 mm | 右肩／上臂 → 右锁骨 → 右锁骨前后中间架 → 胸部 |
| B11 / J36 | [S13](#S13) 右肩／上臂 / `upperarm_r/r2` | 盘 A07-05 · X010（右肩／上臂/上叉_传感板托夹） | 盘 A07-17 · N003（右肩／上臂/上叉_侧装磁铁座盖） | 525 mm | 右肩／上臂 → 右锁骨 → 右锁骨前后中间架 → 胸部 |
| B12 / J37 | [S13](#S13) 右肩／上臂 / `upperarm_r/r3` | 盘 A07-18 · X063（右肩／上臂/D_板夹_-14） + 盘 A07-20 · X064（右肩／上臂/D_板夹_+14） | 盘 A07-15 · P089（右肩／上臂/D_磁铁端盖） | 500 mm | 右肩／上臂 → 右锁骨 → 右锁骨前后中间架 → 胸部 |
| B13 / J38 | [S14](#S14) 右肘屈伸 / `elbow_r.flex/r0` | 盘 A07-03 · X029（右肘屈伸/传感板托夹） | 盘 A07-06 · N004（右肘屈伸/侧装磁铁座盖） | 500 mm | 右肩／上臂 → 右锁骨 → 右锁骨前后中间架 → 胸部 |
| B14 / J39 | [S15](#S15) 右前臂扭转 / `forearm_r.twist/r0` | 盘 A06-11 · X030（右前臂扭转/传感板托夹） | 盘 A07-04 · N004（右前臂扭转/侧装磁铁座盖） | 550 mm | 右肘 → 右肩／上臂 → 右锁骨 → 右锁骨前后中间架 → 胸部 |
| B15 / J40 | [S16](#S16) 右手腕屈伸 / `hand_r.flex/r0` | 盘 A06-14 · X031（右手腕屈伸/传感板托夹） | 盘 A07-10 · N004（右手腕屈伸/侧装磁铁座盖） | 625 mm | 右前臂 → 右肘 → 右肩／上臂 → 右锁骨 → 右锁骨前后中间架 → 胸部 |
| B16 / J41 | [S17](#S17) 右手腕侧摆 / `hand_r.deviate/r0` | 盘 A06-10 · X032（右手腕侧摆/传感板托夹） | 盘 A07-12 · N004（右手腕侧摆/侧装磁铁座盖） | 675 mm | 右腕屈伸中间架 → 右前臂 → 右肘 → 右肩／上臂 → 右锁骨 → 右锁骨前后中间架 → 胸部 |
| C01 / J42 | [S18](#S18) 左髋／大腿 / `thigh_l/r0` | 盘 A08-23 · X067（左髋／大腿/P_板夹_-14） + 盘 A08-22 · X068（左髋／大腿/P_板夹_+14） | 盘 A08-16 · P106（左髋／大腿/P_磁铁端盖） | 425 mm | 骨盆 → 腰部 → 胸部 |
| C02 / J43 | [S18](#S18) 左髋／大腿 / `thigh_l/r1` | 盘 A08-12 · X011（左髋／大腿/下叉_传感板托夹） | 盘 A08-18 · N003（左髋／大腿/下叉_侧装磁铁座盖） | 625 mm | 左髋／大腿 → 骨盆 → 腰部 → 胸部 |
| C03 / J44 | [S18](#S18) 左髋／大腿 / `thigh_l/r2` | 盘 A08-08 · X012（左髋／大腿/上叉_传感板托夹） | 盘 A08-19 · N003（左髋／大腿/上叉_侧装磁铁座盖） | 575 mm | 左髋／大腿 → 骨盆 → 腰部 → 胸部 |
| C04 / J45 | [S18](#S18) 左髋／大腿 / `thigh_l/r3` | 盘 A08-25 · X070（左髋／大腿/D_板夹_-14） + 盘 A08-24 · X071（左髋／大腿/D_板夹_+14） | 盘 A08-17 · P111（左髋／大腿/D_磁铁端盖） | 550 mm | 左髋／大腿 → 骨盆 → 腰部 → 胸部 |
| C05 / J46 | [S19](#S19) 左膝／小腿屈伸 / `calf_l.flex/r0` | 盘 A08-10 · X025（左膝／小腿屈伸/传感板托夹） | 盘 A08-14 · N004（左膝／小腿屈伸/侧装磁铁座盖） | 525 mm | 左髋／大腿 → 骨盆 → 腰部 → 胸部 |
| C06 / J47 | [S20](#S20) 左踝／脚掌 / `foot_l/r0` | 盘 A08-11 · X015（左踝／脚掌/下叉_传感板托夹） | 盘 A08-20 · N003（左踝／脚掌/下叉_侧装磁铁座盖） | 725 mm | 左踝／脚掌 → 左膝／小腿 → 左髋／大腿 → 骨盆 → 腰部 → 胸部 |
| C07 / J48 | [S20](#S20) 左踝／脚掌 / `foot_l/r1` | 盘 A08-09 · X016（左踝／脚掌/上叉_传感板托夹） | 盘 A08-21 · N003（左踝／脚掌/上叉_侧装磁铁座盖） | 725 mm | 左踝／脚掌 → 左膝／小腿 → 左髋／大腿 → 骨盆 → 腰部 → 胸部 |
| C08 / J49 | [S21](#S21) 左脚趾屈伸 / `ball_l.flex/r0` | 盘 A08-13 · X026（左脚趾屈伸/传感板托夹） | 盘 A08-15 · N004（左脚趾屈伸/侧装磁铁座盖） | 750 mm | 左踝／脚掌 → 左膝／小腿 → 左髋／大腿 → 骨盆 → 腰部 → 胸部 |
| C09 / J50 | [S22](#S22) 右髋／大腿 / `thigh_r/r0` | 盘 A09-22 · X074（右髋／大腿/P_板夹_-14） + 盘 A09-23 · X075（右髋／大腿/P_板夹_+14） | 盘 A09-16 · P013（右髋／大腿/P_磁铁端盖） | 400 mm | 骨盆 → 腰部 → 胸部 |
| C10 / J51 | [S22](#S22) 右髋／大腿 / `thigh_r/r1` | 盘 A09-08 · X013（右髋／大腿/下叉_传感板托夹） | 盘 A09-18 · N003（右髋／大腿/下叉_侧装磁铁座盖） | 600 mm | 右髋／大腿 → 骨盆 → 腰部 → 胸部 |
| C11 / J52 | [S22](#S22) 右髋／大腿 / `thigh_r/r2` | 盘 A09-09 · X014（右髋／大腿/上叉_传感板托夹） | 盘 A09-19 · N003（右髋／大腿/上叉_侧装磁铁座盖） | 550 mm | 右髋／大腿 → 骨盆 → 腰部 → 胸部 |
| C12 / J53 | [S22](#S22) 右髋／大腿 / `thigh_r/r3` | 盘 A09-24 · X077（右髋／大腿/D_板夹_-14） + 盘 A09-25 · X078（右髋／大腿/D_板夹_+14） | 盘 A09-17 · P126（右髋／大腿/D_磁铁端盖） | 525 mm | 右髋／大腿 → 骨盆 → 腰部 → 胸部 |
| C13 / J54 | [S23](#S23) 右膝／小腿屈伸 / `calf_r.flex/r0` | 盘 A09-12 · X033（右膝／小腿屈伸/传感板托夹） | 盘 A09-14 · N004（右膝／小腿屈伸/侧装磁铁座盖） | 525 mm | 右髋／大腿 → 骨盆 → 腰部 → 胸部 |
| C14 / J55 | [S24](#S24) 右踝／脚掌 / `foot_r/r0` | 盘 A09-10 · X017（右踝／脚掌/下叉_传感板托夹） | 盘 A09-20 · N003（右踝／脚掌/下叉_侧装磁铁座盖） | 700 mm | 右踝／脚掌 → 右膝／小腿 → 右髋／大腿 → 骨盆 → 腰部 → 胸部 |
| C15 / J56 | [S24](#S24) 右踝／脚掌 / `foot_r/r1` | 盘 A09-11 · X018（右踝／脚掌/上叉_传感板托夹） | 盘 A09-21 · N003（右踝／脚掌/上叉_侧装磁铁座盖） | 700 mm | 右踝／脚掌 → 右膝／小腿 → 右髋／大腿 → 骨盆 → 腰部 → 胸部 |
| C16 / J57 | [S25](#S25) 右脚趾屈伸 / `ball_r.flex/r0` | 盘 A09-13 · X034（右脚趾屈伸/传感板托夹） | 盘 A09-15 · N004（右脚趾屈伸/侧装磁铁座盖） | 725 mm | 右踝／脚掌 → 右膝／小腿 → 右髋／大腿 → 骨盆 → 腰部 → 胸部 |

A 组只使用 A01–A14（J10–J23）；B、C 组各 16 路。没有需要补装的 A15 / A16，J24 / J25 不在本版 46 个传感插座中。对应路径的三维坐标和余量记录见 [当前线束规划](../../bench/revO22/harness/routing_plan.json)。

## 07 · 分段上电、固件与装配检查

先在台面检查中央板与一只传感器，再在关节上检查，最后才连接全部 46 路。插拔、改线和测导通时先断开 USB 与外部 5V。正常串口收到的是二进制帧，不会连续打印可读角度。

| 阶段 | 操作 | 通过标准 / 异常时处理 |
| --- | --- | --- |
| 断电检查 | 核对 J3 的 1 脚 +5V / 2 脚 GND；XIAO 5V 不接 J3；每根五线对号导通 | 万用表查错接、邻针短接及焊点。电容充电可能让蜂鸣器短暂响，不能只凭一次蜂鸣判定短路或通过。 |
| 中央板空载 | 先不插传感器；供应方以受控电源完成电源首件；再分别接 USB 与外部 5V | 确认 MCU_3V3 与 SENSOR_3V45 是不同电压域，后者约 3.451V；没有异常发热、反向送电。 |
| 单路传感器 | 断电后接 A01 / J10，安装或对准磁铁；上电读取原始诊断 | 只要求所装这一轴有有效 SSI 帧、CRC 正确、状态正常，缓慢转磁铁时未标定角度连续变化。其他 45 路未装会无效，这是预期的。 |
| 一组满载 | 先 B01–B16 或 C01–C16 接齐做 16 路检查，A 组只有 14 路 | 核对每路端口，不把共享 CLK / CS 误认为 DO 也能并联。采样稳定，转一轴只影响该轴的相对测量。 |
| 左臂样段 | 接 A11 / A12 + B01–B08，共 10 路；缓慢活动各相邻关节 | 检查焊线不受剥离力，U 环不抽紧，端子不松脱，各轴标号及传感板固定侧正确。首件后确认长度，再复制右臂。 |
| 全部 46 路 | 接齐 A01–A14、B01–B16、C01–C16 后再进入完整捕获 | 远端传感板供电 ≥3.10V 且不超过 3.6V；外部适配器带载出口 ≥4.9V、输入线压降 ≤0.08V、U7 VIN ≥4.05V；电源纹波 / 热态等按原首件表记录。由工厂在易短路的小焊盘处测量。 |
| 完成机械装配 | 逐关节看活动面、磁铁防转、固定螺母、板夹和走线，再盖背盒 | 非相邻身体部件的姿势碰撞可调整姿势规避；相邻件或线束夹住必须重新调整装配 / 行程，不能靠强扭通过。 |

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

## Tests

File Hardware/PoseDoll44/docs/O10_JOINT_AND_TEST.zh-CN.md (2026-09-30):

# O10：实体限位、端面制动与下一步实物输入

运行：`o10_20260926_r1`。入口：[交互说明页面](../tutorials/design-lab/index.html)。本轮没有硬件、采购、供应商联系、commit或push。

**关节数字设计继续推进了，但没有整关节、整臂或整机制造放行。** 单接头保留全部204个原有目标端点；胸肩试排仍保留两个失败端点。下一项会影响尺寸选择的关键输入，是实际摩擦和碟簧工作窗口，已准备独立小样与说明，不要求打印有碰撞的整臂。

## 完成了哪些具体修改

- O9核心继续保留，并在O10加入内部实体限位与两端有限转角外壳。初次小塑料轴颈方案未用作承载定型；载荷核算后改为金属肩轴和较大的端面摩擦结构。
- 两只叉架在O9基础上各再加长1.5 mm；重建金属轴孔、外侧制动面和独立磁铁支撑。两片铝环包住参考M3螺纹座；每个弯折轴两侧各用一根自定义钢轴、两片钢接触片、两片串联碟簧和承压垫圈。没有把原来的细塑料轴颈继续当作保持力承载件。
- 内部实体止挡采用α±28°、β±98°，保留原目标所需的α±25°及最大约96.13°的β。止挡的名义几何不等于已验证的撞击强度。
- 两端各建了分体壳、转子挡肩、轴向垫片和紧固件，保留有限转角，不因为滑环候选就开放无限旋转。外侧转轴的保持力、完整线束和传感器布置仍未定型。
- 自定义轴有2.5 mm对边内六角工具接口；新增环座与旧螺母的4处细小干涉已消除，保留了原轴向承压座面。

完整名义接头计入60件模型（52件新组合及8件原环紧固件）；已建模质量约44.56 g。未建模的电子件、线束、连接架仍须另计，**不是已验证的完整接头重量，更不是成品整机重量**。质量上限仍不以1.2 kg作为硬门槛。

## 验证结果与范围

| 检查 | 结果 | 不能据此推导什么 |
|---|---|---|
| 两叉架连续避让 | 137个单元覆盖α[-28,28]、β[-98,98]，名义间隙保守下界≥0.6 mm；无失败或未知单元 | 不包括其他零件对、实际公差、受载变形及整机运动 |
| 完整接头目标端点 | Manny/Quinn×左右×51目标，204/204未发现所检体积穿插 | 不是完整带线关节的连续路径或任意手动换姿证明 |
| 内部限位与反例 | 工作区内部45个离散组合没有体积穿插；到限位边界有约10⁻⁵ mm³数值接触小体积，保留原报告；越限1°有约0.50 mm³阻挡交叠 | 不代表限位耐冲击或生产公差合格 |
| 范围外75°/75° | 继续检出叉架碰撞，未删除反例 | 不允许把有止挡的真实关节强行操作到该位置 |
| 未合并的固定零件 | 34个固定成员的561对检查，未发现>10⁻⁶ mm³的体积穿插 | 不代表所有零件已能抗拔、保持预紧或承担负载 |
| 轴与参考螺纹 | 名义装配无相交；不旋转而轴向移0.15 mm有阻挡；参考螺旋旋出路径另行复核 | 不等于标准公差等级、剥牙强度、防松或疲劳通过 |
| 内六角工具 | α=β=0的装配直线姿态下，4根直工具杆的完整轴向扫掠没有体积穿插 | 不含手柄、手指或任意姿态下的维护；直线姿态不是解剖中立姿态 |
| 旧锁骨直接接新肩部 | 6处中立干涉由独立实体算法确认 | 不能沿用旧总装后宣布新模块可以直接安装 |
| 双轴锁骨后移试排 | 102个原双侧目标中，100个未发现所检模块间穿插；2个失败 | 仍无完整承力连接架、胸颈、PCBA、外壳与线束；旧模块之间的历史问题未整体关闭 |

具体数量与哈希以本轮JSON报告和`evidence_manifest.json`为准。正体积阈值只是数字求交报告的门槛，不是容许物理穿透的设计公差。

## 检查器和参考螺纹也接受了反例检验

新的布尔网格让旧VTK符号距离出现误判：对30个“深穿透”见证，独立固体角内外判定都落在实体外部。相对容差的网格清理还会把细小三角面折成线段。O10采用保留原始面的无符号距离；零面积面按三条线段参与距离计算，不被默默删除。另以独立闭合实体求交确认初始分离，连续正间隙覆盖连通角度区间，才排除之后的交叠/包含。O9封存文件没有修改。

增加非空零件与质量检查时，发现反向碟簧截面绕序会生成空实体。已修复，并重跑涉及质量、完整接头、固定件与胸肩的检查。失败生成器与无效质量结果留在`rejected/`，不能用作验收输入。

新增旋出检查也揭示了有限Frenet螺纹扫掠的出口问题；改变扫掠长度还不能保持原有配合。最终O10参考螺纹改成明确的圆柱坐标截面扫掠，以1°网格、独立截面积体积估算及螺旋移动求交复核相位。母螺纹切削轨迹延伸过出口。旧CAD STEP已移入`rejected/`，不是当前轴的生产文件；当前参考螺纹仍需标准牙形、入口、公差与生产图纸工作。

专项回归覆盖了内外距离、完全包含、零面积面、双片碟簧、旧碰撞反例、空白测量、合成测量的不升级规则及读数不确定度。合成测试数据不是实测记录。

## 保持力为何需要实物输入

按当前逐件体积、材料密度假设及旧下游零件重心，最苛刻弯折轴保持需求约0.392 N·m，包含1.5倍重力矩与0.02 N·m线束阻力假设。所有缺失件预算仍保留；这个计算不包含手撑地等整机支撑工况。

摩擦面为内半径2.12、外半径6 mm。两侧各210 N、每侧保守计一个有效摩擦通路时，需要有效系数约0.21。不能把自由钢片的两个接触面直接算成两个可叠加的完整保持力。厂家薄碟簧目录存在力偏差；例如按二级189 N下界考虑，会把所需系数提高到约0.24。这里的材料界面与塑料蠕变没有实测。[锐尔立官方目录](https://www.raleigh-spring.cn/discspring/list_84_2/)

因此先测**摩擦—压缩高度—操作力—停留漂移**窗口。这是决定继续复用当前外径，还是增加弹簧/摩擦面尺寸的输入。见[独立小样步骤](../bench/revO10/README.zh-CN.md)。有些总装数字工作仍未完成；没有把小样通过当作修复已知碰撞的替代，也没有宣称其余数字工作都必须等打印才可做。

## 线束与中国供应商

盘绕线方案使用四圈、定长的连续曲线族比较不同半径。当前取样及线间距下界筛选中，外线圈半径18 mm候选对应每根线约322.99 mm、壳体外径约39 mm和9 mm轴向深度。该结果不是实际导线弹性平衡、固定端过渡、完整带线运动或疲劳寿命证明。

晶沛LPMS-05D作为更紧凑的器件候选：目录本体Ø5.5×9.6 mm，另列1 mm长、Ø2 mm转子，5路、每路1 A、48 V。模型保留了独立套筒，在现有Ø8.8轴孔内有名义空间；套筒外径8.3 mm、法兰16 mm，尾部名义增加2 mm。不需要为它直接采用Ø39盘线外壳，但**不能宣称整个关节已经缩小14 mm**。[晶沛型号页面](https://www.electricslipring.com/h-pd-388.html)、[官方目录表](https://www.sliprings.cn/upload/portal/20230920/cf5d5feb2190d6a1f043a01872a3288e.pdf)

不同目录中的LPMS-05/LPMS-05D和长度口径不完全一致；下单前应核对具体版本图纸。当前套筒固定、转子连接与引线应力释放未放行，RS485和掉电恢复也没有实测。型号页的电阻波动指标不能代替接触中断、波形或错误率测试。静态采集可以放宽实时性，但仍需数据完整、新鲜且稳定。

## 胸肩试排为何没有定型

初次旧轴模块直接集成存在真实干涉；仅沿旧轴线大幅移动也没有得到可采用的方案。后续双轴锁骨试排保留中立锚点、骨长和所有原目标，将锁骨轴心设在参考X=-60 mm、Y=±20 mm、原轴心Z+10 mm。各姿势中的平移会随新轴心改变，这不是已校准UE配置。

它解决了许多模块相碰的位置，但双侧同时前收20°时，Manny的两只近端壳体相撞；Quinn还涉及输入叉架。没有缩减前收范围或删除目标。这个试排不作为最终胸肩布局；后续需结合实测保持力/尺寸，继续研究较小的分轴连接或新的安装方向，并补实际承力架和胸颈共同空间。

## 文件与复算

- 源码：`cad/revO10/`，生成结果：`generated/revO10/runs/o10_20260926_r1/`。
- `threads.json` / `assembly_tools.json`：当前参考连接、旋出与工具扫掠。
- `continuous_yokes.json`、`target_motion.json`：连续叉架对与完整接头端点，范围分别记录。
- `face_axis_loads.json`：质量、重心、物理轴重力和保持需求。
- `clavicle_trial/motion.json`：包含失败的双侧试排。
- `slipring/study.json`、`twist_wire_study.json`：紧凑器件候选与盘线研究，均非实测。
- `bench/revO10/`：独立小样STEP/STL、计划和空白测量表；`tutorials/design-lab/`：新页面。

Python数值环境本轮使用NumPy 2.5.3、Manifold3D 3.3.2；CAD验证沿用项目CadQuery/OCP/VTK运行入口。Manifold3D是新增的独立网格实体求交依赖，已安装到项目`.venv`，不替代生产CAD或实物试验。[项目上游](https://github.com/elalish/manifold)

```powershell
.venv/Scripts/python.exe -X utf8 Hardware/PoseDoll44/cad/revO10/run_verification.py geometry
.venv/Scripts/python.exe -X utf8 Hardware/PoseDoll44/tools/run_cad.py Hardware/PoseDoll44/cad/revO10/continuous_face_brake.py
.venv/Scripts/python.exe -X utf8 Hardware/PoseDoll44/cad/revO10/run_verification.py methods
.venv/Scripts/python.exe -X utf8 scripts/seal_revo10.py --verify
```

所有旧O7/O8/O9封存哈希已另行核验。480 mm参考、910 mm备用、静态采集和44轴语义继续保留；本轮没有把几何试排写回UE设备校准或改动固件。

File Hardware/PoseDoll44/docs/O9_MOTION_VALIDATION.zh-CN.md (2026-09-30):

# Rev O9：先验证运动，再决定打样

运行：`o9_20260926_r1`。本轮继续推进数字工作，没有采购、打印、硬件实测、commit 或 push。当前入口是[运动验证页面](../tutorials/motion-lab/index.html)。O8 指南保留为历史资料；其中“当前先需要打印配合小样”的停止条件已经撤销。配合小样是独立的工艺实验，不是继续解决运动问题的前置条件。

## 本轮结果

当前研究候选为：**两只叉架各加长 3 mm，输入叉架磁铁杯底部局部径向避让最多 0.35 mm**。保持磁铁槽、轴颈及两片中间环。四件核心中立包络约 23 × 23 × 55 mm，塑料网格体积 4638.2143 mm³。这些数字不包含完整外接转轴、PCBA、线束和壳体，不能当作完整关节的尺寸或重量。

在第一弯折 α ∈ [−30°, 30°]、第二弯折 β ∈ [−100°, 100°] 内，两只叉架的连续名义间隙保守下界不小于 **0.6 mm**。这次覆盖的是整个角度矩形，不是只检查几个端点。半环及紧固件与两叉架的其余 6 对移动配合，也通过了整个对应区间的连续正间隙检查，详见 `continuous_other_core_pairs.json`；0.01 mm 只是证明名义模型表面分离的数值门槛，绝不是给供应商的打印公差要求。

所有原有目标保留：Manny / Quinn × 左右侧 × 51 个目标，共 **204 个目标**。新的有限转角分配包含 8088 个精确采样旋转、7884 段连续的关节角插值。所选第一弯折只使用 ±25°，为拟议的 ±30° 限位留下 5° 名义角度余量；第二弯折最大约 96.13°。

原来的双向 75° / 75° 反例仍然碰撞，已经重新检查并保留为失败。**没有实体限位之前，不能保证使用者不会进入这个范围。** 当前没有整关节、单臂或整机制造放行。

## 为什么需要这一小步改型

1. O8 的 2 mm 叉架在新增的 117 个混合角度网格中，81 个名义无穿透、36 个失败。所有失败都涉及两只叉架。继续单纯加长不能消除所有大角度混合碰撞。
2. “没有碰到”不等于“留够间隙”。例如 O8 在 α=15°、β=100° 已有约 0.443 mm 的表面距离见证；中央磁铁杯与另一轴附近，在 α=30° 的部分取样处只有约 0.379 mm。这些是所找到点的距离，不是精确的全局最小值。
3. 磁铁杯底部采取局部收拢，参数影响半径 3.2～4.8 mm、轴向 z=−3.5～−1.5 mm 的局部区域。径向映射连续、保持单调，最大改变量 0.35 mm。原来的磁铁凹槽和轴颈顶点逐项检查保持不变；环件完全不变。闭合网格、边界和非流形检查通过。未由这些检查推导材料强度、夹持力或疲劳寿命。
4. 只看角落姿态会选错长度。局部避让后的 2 mm 版本在九个角落/中立组合可达 0.6 mm，但 α=15°、β=100° 的区间内部仍有不足 0.6 mm 的反例。3 mm 版本通过该反例及整个工作矩形的连续检查。因此这轮选择 3 mm，而不是继续盲目加长。

候选和反例分别见 `cup_relief_search.json`、`extension_midangle_counterexample.json`、`continuous_yoke_workspace.json`。没有把非必要范围里的碰撞删除，也没有缩减原有目标来换取通过。

## 连续检查怎样得到结论

完整精度的闭合三角网格用于验证；页面仅为显示把坐标舍入到 0.00001 mm。校验器没有对验证网格做简化。

对于两叉架，在角度区间中心求表面距离，减去源三角形包络半径，以及该三角形在整个角度区间内可能发生的位移上界。位移采用每个旋转轴的弦长上界。另用“刚体绕原点旋转不改变到原点的距离”建立排除球，避免在中央杯附近不必要地反复细分。无法完成的单元返回细分或 UNKNOWN，计算预算耗尽不会返回通过。

最终 48 个保守单元覆盖全部 12000 平方度的参数矩形；没有失败或未知单元。已检查初始完整闭合实体互不包含；连续正表面间隙排除了随后发生穿越或包含的可能。数值证据仍受原始 STL 精度、重建轴心和浮点运算限制，不是生产公差分析。

半环/轴颈的细小间隙另作处理：把每个轴颈网格分成圆锥台包络覆盖的表面与其余表面。包络对该轴的旋转保持不变，并以支撑平面给出保守间隙；其余每个三角面都保留在连续检查中。开口的表面子集使用无符号距离，体积关系仍由完整闭合模型的初始检查约束。没有把需要配合的零件整对忽略。

`test_continuous.py` 包括 5000 个弦长界复核、两端无碰撞而中途相撞、完全包含、原杯间隙反例和开口表面所需的独立检查。`test_journal_sweeps.py` 另检查圆柱包络、包络内的反例及无漏面的网格分区。

## 姿势没有删除，但这仍是候选运动方式

保留 O7 的全部姿势名称和目标角度，也保留之前超出 profile 的应力测试。四角分配采用同一物理中立与零位，不会为每个目标重新归零。接近 β=90° 时，固定间隔扫描近端转角会漏解，因此最终算法改为扫描第一弯折角并精确求其余角度；初次漏解记录只作为算法试验保存，不计作设计失败。

| 范围（相对同一中立） | 左侧 | 右侧 |
|---|---:|---:|
| 近端 φ | 约 −163.90°～44.09° | 约 −48.10°～164.05° |
| 第一弯折 α | −25°～25° | −25°～25° |
| 第二弯折 β | 约 −84.27°～96.13° | 约 −84.76°～96.08° |
| 远端 ψ，合并两个人体参考 | 约 −64.26°～86.65° | 约 −72.12°～64.22° |

近端跨度从上一轮约 334° 降为约 208°～212°。关节角的线性插值处于凸的已检查弯折矩形内，因此核心的连续避让结论覆盖这些路径。采样旋转和终点都精确重建，但实际四角线性插值不等于原来的人体角度插值；与相邻目标旋转中间姿态相比，已检查中点最大偏差约 **0.166°**。它不是全部连续时间的误差上界。

这些路径通过共同中立构成可达性证据，不表示已证明任意直接换姿、自然手感、完整肩部的平移、骨长和外壳不干涉。旧 O7 的 45/102 个整臂失败仍是旧总装的结果，没有被这次局部实验升级为通过。

## 装配、维护和走线

- 改型后的 63 个工作区离散位置，包含两只叉架、两半环和全部 8 件紧固件，没有移动配合穿透；另一个 75° / 75° 反例失败。
- 五阶段装配重新检查了 123 个离散位置，末端半环贴合为明确的预期接触。没有证明任意装配顺序或连续装配公差。
- 四颗螺钉的工具接近姿态现在分别可取 (α,β)=(0°,30°)、(15°,0°)、(−15°,0°)、(0°,−30°)。检查的是 1.5 mm 对边直工具杆及 15 mm 外撤的扫掠包络，不包含未建模手柄、手指和实际拧紧力。
- `path_audit.json` 给出拟议的有限转角区间和角度余量，**实体限位尚未建模**。它们是后续零件的约束，不是已经存在的物理止挡。
- 走线目前只得到有限转角需求。没有由“跨度变小”推断电线不会拉紧、刮擦、夹住或疲劳；也没有把转动弧长当成电线所需长度。线束路径、固定点、应力释放、最小弯曲半径和周边共同空间仍须建模。

## 后续工作的顺序

先把实体限位、外接两端转动接头、线束固定和完整胸肩/手臂共同装配推进到能做数字检验的程度，再确定值得制作的样件。本轮没有新增需要用户决定的功能取舍，也不需要用户现在下单。

在这之后，材料保持力、打印配合、摩擦、反向加载、停留漂移和线材循环寿命才需要通过对应实物试验回答。用户没有硬件，因此本轮不把这些项目写成已测。

480 mm 解剖参考、910 mm 备用、静态姿势采集及 44 轴语义继续保留；1.2 kg 不作为硬门槛。没有改动 UE 插件和固件，也没有更换供应商。

## 可复算入口

源码：[cad/revO9](../cad/revO9/)。输出：[本轮运行目录](../generated/revO9/runs/o9_20260926_r1/)。最终证据清单为该目录的 `evidence_manifest.json`。

在 design 仓库根目录，沿用现有运行环境：

```powershell
.venv/Scripts/python.exe -X utf8 Hardware/PoseDoll44/tools/run_cad.py Hardware/PoseDoll44/cad/revO9/verify_journal_sweeps.py
.venv/Scripts/python.exe -X utf8 Hardware/PoseDoll44/tools/run_cad.py Hardware/PoseDoll44/cad/revO9/continuous_clearance.py
.venv/Scripts/python.exe -X utf8 Hardware/PoseDoll44/cad/revO9/allocate_paths.py
.venv/Scripts/python.exe -X utf8 Hardware/PoseDoll44/cad/revO9/audit_paths.py
.venv/Scripts/python.exe -X utf8 scripts/seal_revo9.py --verify
```

`continuous_core_pairs.py` 是早期的通用细分尝试，在细小配合面上计算效率不足；最终配合连续证据来自 `verify_journal_sweeps.py`。初次固定转角网格漏解、较小/较大源网格尝试和未完成日志均保留，未作为通过证据。哈希锁定存储的来源和结果，不会把局部数字结果提升为制造放行。

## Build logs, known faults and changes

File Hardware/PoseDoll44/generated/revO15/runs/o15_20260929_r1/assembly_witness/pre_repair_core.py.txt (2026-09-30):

"""Dual-axis printed core with both complete magnetic encoders.
The mechanical core comes from sealed O13; O15 adds retained cups and PCBA supports.
"""
from common import *
import hinge
G13=H/'generated/revO13/runs/o13_20260929_r1';G8=H/'generated/revO8/runs/o8_20260925_r1'
def make(signs=(1,1),phases=(0,180),extensions=(0,0),wide=False,rear_second=False):
 old={k:from_tri(t) for k,t in np.load(G13/'printed_core/parts.npz').items()};hp,ho,hs=hinge.make();p={};o={};sku={}
 stock={'inner_M4_wide':'W_M4_D12_T1','outer_M4_wide':'W_M4_D12_T1','front_M4_washer':'W_M4_D9_T0P8','spring_1':'A8_SS','spring_2':'A8_SS','shoulder_D4_L8_M3_thread6':'SHOULDER_D4_L8_M3_L6','M3_nut':'NUT_M3','M3_reaction_washer':'W_M3_D9_T0P8'}
 for k,s in old.items():
  if k in ('C01','C02') and extensions[0 if k=='C01' else 1]:
   tt=tri(s);direction=-1 if k=='C01' else 1;tt[:,:,2]+=direction*extensions[0 if k=='C01' else 1]*np.clip((direction*tt[:,:,2]-8)/6,0,1);s=from_tri(tt)
  p[k]=s;o[k]=k if k in ('C01','C02') else 'ring';sku[k]=None if k in ('C01','C02','C14','C15') else next(v for a,v in stock.items() if k.endswith(a))
 for k,t in np.load(G8/'fastened_core/fasteners.npz').items():p['ring_'+k]=from_tri(t);o['ring_'+k]='ring';sku['ring_'+k]='NUT_M1P6' if 'nut' in k.lower() else 'SCREW_M1P6_L6'
 frames=[];attachments=md.Manifold()
 for i,(key,sgn,phase,e) in enumerate(zip(('C01','C02'),signs,phases,extensions)):
  Z=np.eye(3)[i]*sgn;X=np.array([0,0,-1 if i==0 else 1]);Y=np.cross(Z,X);M=np.c_[X,Y,Z]@rot(2,phase);pos=Z*16;frames.append((M,pos))
  def tr(s):return pose(s,M,pos)
  # Compact retained cup: keyed to the printed fork, no adhesive or metal machining.
  cup=washer(8.5,6.3,1.4,7.1)+cyl(8.5,8.4,10.6)
  cup-=cyl(3.1,10.4,10.7)+cyl(1.9,8.3,10.7)
  cup+=box([6.4,-2,-.8],[12,2,2.2])
  cap=cyl(8.5,10.6,13.1)-cyl(3.075,10.5,12.95)-cyl(2.9,12.8,13.2)
  extras={}
  for xx in (-6.1,6.1):
   cup-=cyl(1.1,5.9,10.7).translate([xx,0,0]);cup-=hexagon(4.3,6.1,7.8).translate([xx,0,0]);cup-=box([6 if xx>0 else -10,-2.2,6.05],[10 if xx>0 else -6,2.2,7.8])
   cap-=(cyl(1.15,10.5,13.2)+cyl(2.05,11.1,13.2)).translate([xx,0,0])
   extras[f'magnet_nut_{xx}']=(nut(2,4,1.6,6.2).translate([xx,0,0]),key,'NUT_M2')
   extras[f'magnet_screw_{xx}']=(screw(2,5,3.8,2,11.1).translate([xx,0,0]),key,'SCREW_M2_L5')
  # Cup frame follows the fork stem, independently of fixed support placement.
  MC=np.c_[X,Y,Z]
  p[key]+=pose(cup,MC,pos)
  for kk,(ss,oo,sk) in extras.items():p[key+'_'+kk]=pose(ss,MC,pos);o[key+'_'+kk]=oo;sku[key+'_'+kk]=sk
  p[key+'_magnet_cap']=pose(cap,MC,pos);o[key+'_magnet_cap']=key;sku[key+'_magnet_cap']=None
  p[key+'_magnet']=pose(cyl(3,10.4,12.9),MC,pos);o[key+'_magnet']=key;sku[key+'_magnet']='MAGNET_D6_T2P5_DIAMETRIC'
  holder=hp['base_sensor_half']-box([-50,-50,-50],[50,50,-2.5])
  anchor=np.array([6,-9,-3]) if i==0 else np.array([9,6,-3])
  tip=M@np.array([-13.5,-13.5,-2.4])+pos
  via=np.array([13.8,-11.5,-3]) if i==0 else np.array([11.5,13.8,-3])
  if wide and i==0:
   holder=holder^box([-50,-50,10.5],[50,50,50]);anchor=np.array([6,-9,-5]);via=np.array([27,-9,-5]);tip=np.array([27,-13.5,13.5]);attachments+=tr(holder)+beam(anchor,via,1.3)+beam(via,tip,1.3)
  elif rear_second and i==1:
   holder=holder^box([-50,-50,10.5],[50,50,50]);anchor=np.array([-9,0,-6.5]);via=np.array([-9,27,-6.5]);tip=np.array([-13.5,27,-13.5]);attachments+=tr(holder)+beam(anchor,via,1.3)+beam(via,tip,1.3)
  else:attachments+=tr(holder)+beam(anchor,via,1.8)+beam(via,tip,1.8)
  for k,ss in hp.items():
   if k.startswith(('sensor_','passive_','pcb_')):p[key+'_'+k]=tr(ss);o[key+'_'+k]='ring';sku[key+'_'+k]=hs[k]
 # Preserve mating-half clearance and the real fastener insertion bores.
 for k in ['C15']+[kk for kk in p if kk.startswith('ring_') or ('pcb_clip_' in kk and (wide or rear_second))]:
  clearance=p[k]
  for ax in range(3):
   for ss in (-1,1):clearance+=p[k].translate(np.eye(3)[ax]*ss*.15)
  attachments-=clearance
 p['C14']+=attachments
 return p,o,sku

def frames(a,b):return {'ring':np.eye(3),'C01':rot(0,a),'C02':rot(1,b)}
def main():
 p,o,s=make(); rec={k:mesh_record(v) for k,v in p.items()};nom=hits(p)
 motion=[]
 for a,b in itertools.product((-25,0,25),(-95,-60,0,60,95)):
  fs=frames(a,b);pp={k:pose(v,fs[o[k]]) for k,v in p.items()};hh=[h for h in hits(pp) if o[h['pair'][0]]!=o[h['pair'][1]]];motion.append({'angles_deg':[a,b],'findings':hh})
 save('core_build.json',{'parts':rec,'owners':o,'stock_skus':s,'nominal_findings':nom,'motion':motion,'physical_tested':False});np.savez_compressed(OUT/'core_parts.npz',**{k:tri(v) for k,v in p.items()})
 print('core',len(p),'components',[(k,r['components']) for k,r in rec.items() if r['components']!=1], 'nominal',nom,'motion',[(x['angles_deg'],len(x['findings'])) for x in motion],flush=True)
if __name__=='__main__':main()

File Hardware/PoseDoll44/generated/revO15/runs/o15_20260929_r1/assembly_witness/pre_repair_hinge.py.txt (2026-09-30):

"""Complete printed single-axis joint using O12 stock friction stack.
Positive through-bolts retain housing and removable sensor/magnet caps.
Magnetic performance and printed material properties remain deferred tests.
"""
from common import *
def make():
 src=H/'bench/revO12/parts.npz';old={k:from_tri(t) for k,t in np.load(src).items()};p={};owners={};sku={}
 def put(k,s,owner,stock=None):p[k]=from_tri(tri(s));owners[k]=owner;sku[k]=stock
 # Exact received stock friction stack, relocated so the lever bearing plane is Z=0.
 for k,s in old.items():
  if k.startswith(('printed_','case_')):continue
  put(k,s.translate([0,0,-10.5]),'parent',{'shoulder_D4_L8_M3_thread6':'SHOULDER_D4_L8_M3_L6','inner_M4_wide':'W_M4_D12_T1','outer_M4_wide':'W_M4_D12_T1','front_M4_washer':'W_M4_D9_T0P8','spring_1':'A8_SS','spring_2':'A8_SS','M3_nut':'NUT_M3','M3_reaction_washer':'W_M3_D9_T0P8'}[k])
 cavity=(hexagon(5.8,-8.65,-6.05)+cyl(4.65,-6.15,-5.3)+cyl(1.7,-10.6,-3.5)+cyl(2.125,-4.4,-2.0))
 base=box([-14,-10,-10.5],[14,10,-2.5])-cavity
 for i,x in enumerate((-10,10)):
  M=rot(0,-90);origin=[x,0,-6.5];base-=pose(cyl(1.7,-14,16),M,origin)
  put(f'case_screw_{i}',pose(screw(3,25,5.6,3,12),M,origin),'parent','SCREW_M3_L25')
  put(f'case_nut_{i}',pose(nut(3,5.5,2.4,-12.4),M,origin),'parent','NUT_M3')
 # One fixed support in the unused angular sector; operating range -90..145 deg.
 # The rest of the 360-degree sweep is explicitly outside this joint's use range.
 holder=box([-6.3,-5.1,15.0],[-5.5,5.1,16.495])+box([5.5,-5.1,15.0],[6.3,5.1,16.495])
 # Positive XY location: the top clip alone cannot stop a PCB sliding out.
 for side in (-1,1):
  lo,hi=sorted((side*6.05,side*7.05));holder+=box([lo,-6.1,16.195],[hi,6.1,17.495])
  lo,hi=sorted((side*5.1,side*6.1));holder+=box([-7.05,lo,16.195],[7.05,hi,17.495])
 x,y=-13.5,-13.5
 post=cyl(5,-9.5,17.495).translate([x,y,0])
 post-=box([x-3.3,y-7,11.0],[x+3.3,y,13.55]);post-=hexagon(5.8,11.1,13.55).translate([x,y,0]);post-=cyl(1.7,10.8,19.1).translate([x,y,0])
 holder+=post+beam([-12,-8,-7],[x,y,-7],3)
 for side in (-1,1):holder+=beam([x,y,15.0],[side*5.9,-4.7,15.0],1.45)
 clip=box([-6.2,-5.5,17.495],[6.2,-4.6,19])+box([-6.2,-4.6,17.495],[-5.6,5.1,19])+box([5.6,-4.6,17.495],[6.2,5.1,19])
 clip+=cyl(5,17.495,19).translate([x,y,0])+beam([x,y,18.3],[-5.9,-5,18.3],.7)
 clip-=cyl(1.7,17.3,19.1).translate([x,y,0])
 # Key across the split prevents the one-screw clip turning about its fastener.
 key=box([x-4.7,y-.6,17.2],[x-2.7,y+.6,18.0]);holder+=key;clip-=key.translate([0,0,.0])
 put('pcb_clip',clip,'parent');put('pcb_clip_screw',screw(3,8,5.6,3,19).translate([x,y,0]),'parent','SCREW_M3_L8')
 put('pcb_clip_nut',nut(3,5.5,2.4,11.1).translate([x,y,0]),'parent','NUT_M3')
 for xx,yy in ((-2.3,-3.7),(-2.3,3.7),(2.3,-3.7),(2.3,3.75)):holder-=box([xx-1.2,yy-.95,15.0],[xx+1.2,yy+.95,16.6])
 base_minus=(base^box([-20,-20,-20],[20,0,0]))+holder
 base_minus-=cyl(1.7,10.8,19.1).translate([x,y,0])
 for xx in (-10,10):base_minus-=pose(cyl(1.7,-14,16)+hexagon(5.8,-12.6,-9.99),rot(0,-90),[xx,0,-6.5])
 put('base_service_half',base^box([-20,0,-20],[20,20,0]),'parent')
 put('base_sensor_half',base_minus,'parent')
 lever=cyl(6,-1.5,1.5)+box([4,-6,-1.5],[30,6,4.5]);lever-=cyl(6.15,1.5,4.6);lever-=cyl(2.125,-1.6,4.6)
 # Positive cup-to-lever union, retained magnet cup cap with two M2 fasteners.
 cup=washer(11.5,6.3,1.5,8.5)+cyl(11.5,8.4,10.6);cup-=cyl(3.1,10.4,10.7)+cyl(1.9,8.3,10.7)
 lever+=cup
 for x in (-8,8):
  lever-=cyl(1.1,5.9,10.7).translate([x,0,0]);lever-=hexagon(4.3,6.1,7.8).translate([x,0,0])
  lever-=box([7.9 if x>0 else -13,-2.2,6.05],[13 if x>0 else -7.9,2.2,7.8])
  put(f'magnet_cap_nut_{x:+}',nut(2,4,1.6,6.2).translate([x,0,0]),'child','NUT_M2')
  put(f'magnet_cap_screw_{x:+}',screw(2,5,3.8,2,11.1).translate([x,0,0]),'child','SCREW_M2_L5')
 cap=cyl(11.5,10.6,13.1)-cyl(3.075,10.5,12.95)-cyl(2.9,12.8,13.2)
 for x in (-8,8):cap-=(cyl(1.15,10.5,13.2)+cyl(2.05,11.1,13.2)).translate([x,0,0])
 put('lever_cup',lever,'child');put('magnet_cap',cap,'child');put('magnet',cyl(3,10.4,12.9),'child','MAGNET_D6_T2P5_DIAMETRIC')
 put('sensor_PCB',box([-6,-5,16.495],[6,5,17.495]),'parent','AS5048A_MINI_PCBA')
 put('sensor_IC',box([-3.25,-2.5,14.5],[3.25,2.5,16.495]),'parent','PCBA_INCLUDED')
 put('sensor_FPC_connector',box([-2.575,-1.575,17.495],[2.575,1.575,18.495]),'parent','PCBA_INCLUDED')
 # Conservative original passive component packages, tracked as PCBA constituents.
 for i,(x,y) in enumerate(((-2.3,-3.7),(-2.3,3.7),(2.3,-3.7),(2.3,3.75))):put(f'passive_{i}',box([x-1,y-.75,15.2],[x+1,y+.75,16.495]),'parent','PCBA_INCLUDED')
 return p,owners,sku

def main():
 p,owners,sku=make();rec={k:mesh_record(s) for k,s in p.items()};nom=hits(p)
 np.savez_compressed(OUT/'hinge_parts.npz',**{k:tri(s) for k,s in p.items()})
 samples=[]
 for angle in sorted(set(range(-180,181,10))|set(range(-90,146,5))):
  pp={k:pose(s,rot(2,angle)) if owners[k]=='child' else s for k,s in p.items()};cross=[]
  for h in hits(pp):
   if owners[h['pair'][0]]!=owners[h['pair'][1]]:cross.append(h)
  samples.append({'angle_deg':angle,'inside_operating_range':-90<=angle<=145,'findings':cross})
 save('hinge_build.json',{'inputs_sha256':{str(Path(__file__).relative_to(H)):sha(__file__),'bench/revO12/parts.npz':sha(H/'bench/revO12/parts.npz')},'parts':rec,'owners':owners,'stock_skus':sku,'nominal_findings':nom,'motion':samples,'operating_range_deg':[-90,145],'magnet_airgap_to_package_mm':1.6,'physical_tested':False,'assumption':'O12 friction stack usable as user-directed design input; new mounts and whole joint still untested'})
 print('hinge parts',len(p),'components',[(k,r['components']) for k,r in rec.items() if r['components']!=1], 'nominal',nom,'motion hits',[(r['angle_deg'],len(r['findings'])) for r in samples if r['findings'] and r['inside_operating_range']],flush=True)
if __name__=='__main__':main()

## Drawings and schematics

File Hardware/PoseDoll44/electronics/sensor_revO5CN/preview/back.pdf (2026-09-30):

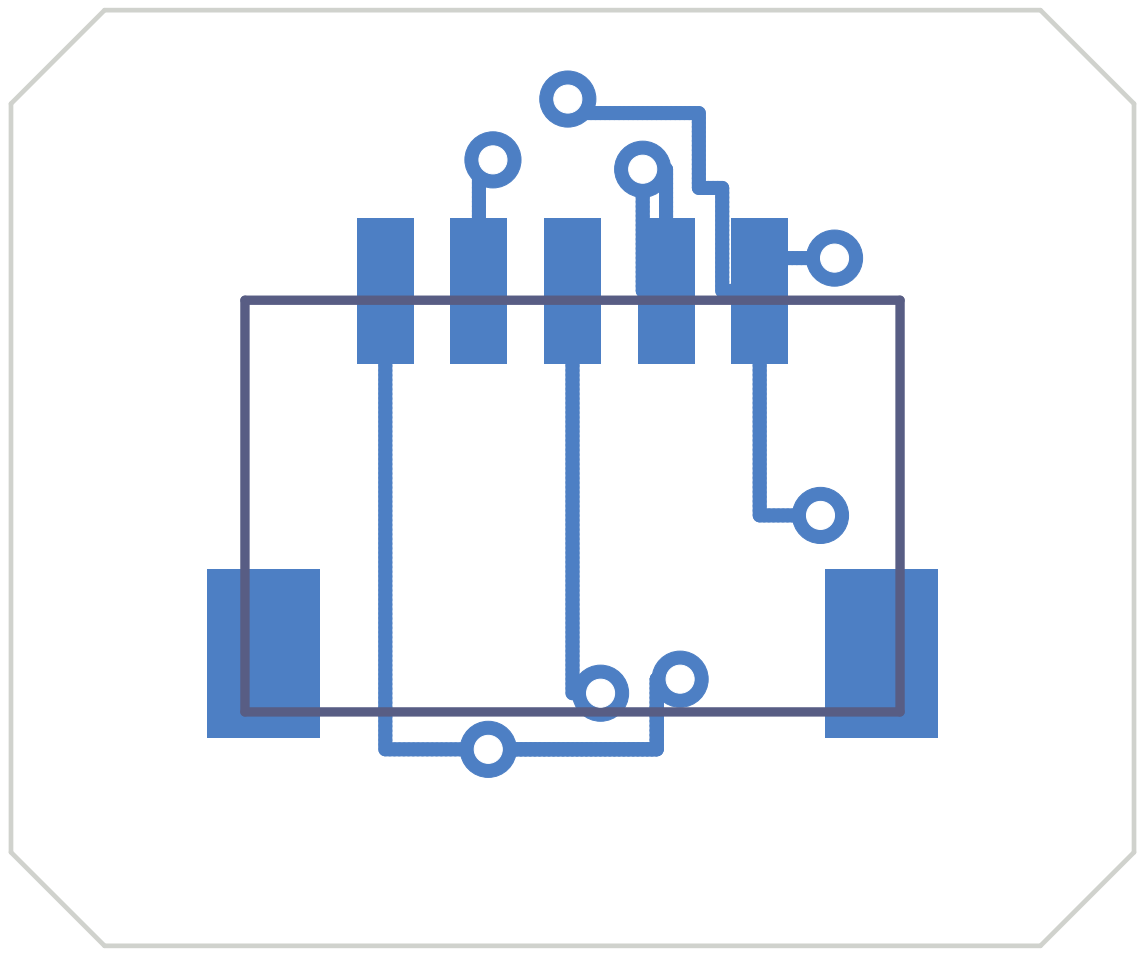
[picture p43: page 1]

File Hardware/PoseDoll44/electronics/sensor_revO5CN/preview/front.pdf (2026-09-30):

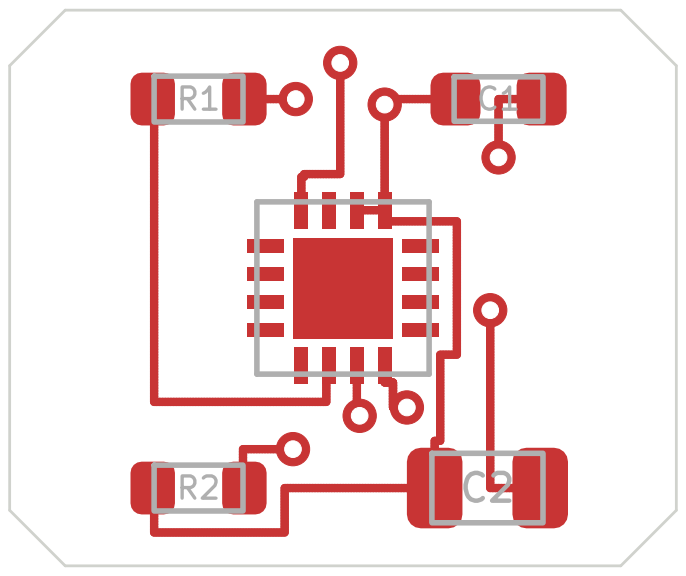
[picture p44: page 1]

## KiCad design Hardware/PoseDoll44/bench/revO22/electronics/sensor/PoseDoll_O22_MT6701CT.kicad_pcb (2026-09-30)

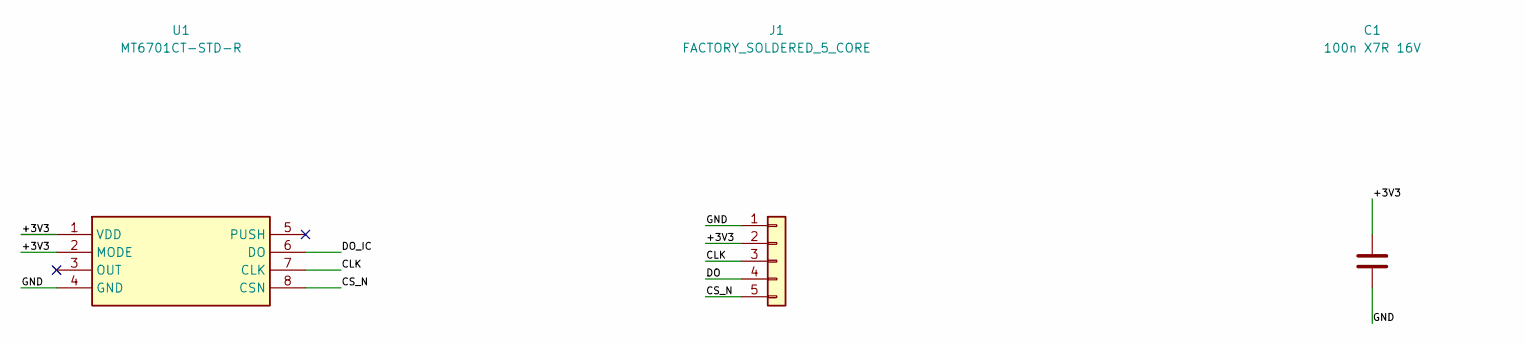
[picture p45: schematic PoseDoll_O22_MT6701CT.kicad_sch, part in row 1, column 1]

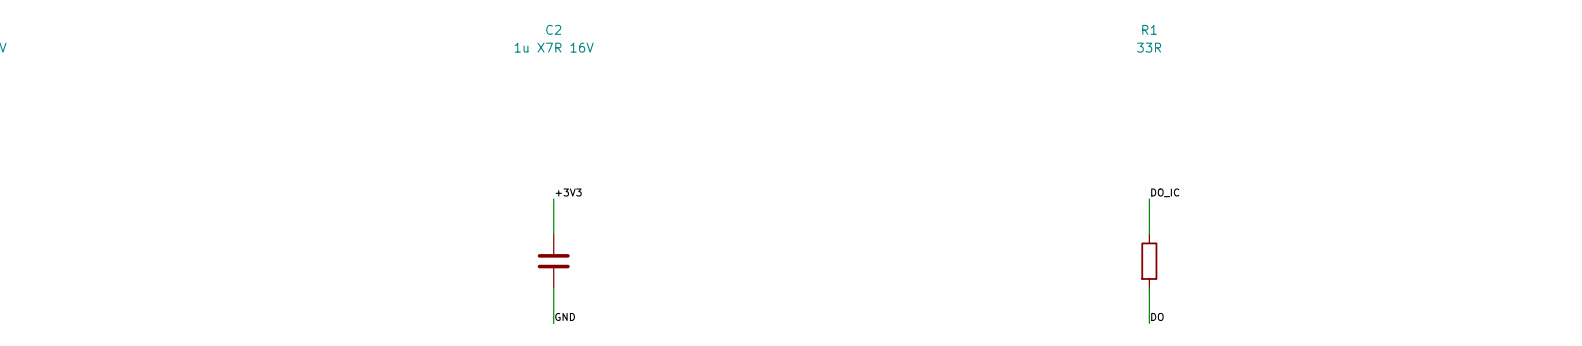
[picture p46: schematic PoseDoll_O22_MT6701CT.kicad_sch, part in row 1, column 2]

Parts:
C1: 100n X7R 16V; C_0603_1608Metric
C2: 1u X7R 16V; C_0603_1608Metric
J1: FACTORY_SOLDERED_5_CORE; WirePads_5P
R1: 33R; R_0603_1608Metric
R2: 10k; R_0603_1608Metric
U1: MT6701CT-STD-R; SOIC-8_3.9x4.9mm_P1.27mm

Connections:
/+3V3: C1.1, C2.1, J1.2, R2.1, U1.1 (VDD), U1.2 (MODE)
/CLK: J1.3, U1.7 (CLK)
/CS_N: J1.5, R2.2, U1.8 (CSN)
/DO: J1.4, R1.2
/DO_IC: R1.1, U1.6 (DO)
/GND: C1.2, C2.2, J1.1, U1.4 (GND)

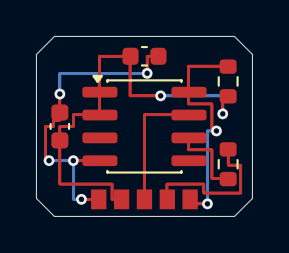
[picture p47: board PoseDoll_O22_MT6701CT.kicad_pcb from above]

Board: 2 copper layers, 12.0 x 10.0 mm, 6 parts (0 on the bottom side), 6 nets.

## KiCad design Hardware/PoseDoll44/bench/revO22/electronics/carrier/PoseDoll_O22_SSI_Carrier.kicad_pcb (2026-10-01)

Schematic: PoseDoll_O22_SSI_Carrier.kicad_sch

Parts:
C1, C2, C3, C4, C5, C6: 100n; C_0603_1608Metric
C7, C8, C9: 22u 10V X7R effective >=10u; C_0805_2012Metric
C10: 22p C0G starting value; C_0603_1608Metric
D1: SS14 input reverse protection; D_SMA
F4: 1206L110THR / input 1.1A; Fuse_1206_3216Metric
F5: 0467001.NR / 1A fast; Fuse_0603_1608Metric
H1, H2, H3, H4: M2 clearance; MountingHole_2.2mm_M2
J1: XIAO_LEFT D0-D6; PinHeader_1x07_P2.54mm_Vertical
J2: XIAO_RIGHT D7-D10,3V3,GND,5V NC; PinHeader_1x07_P2.54mm_Vertical
J3: EXTERNAL REGULATED 5V ONLY; NO USB VBUS TIE; JST_PH_B2B-PH-SM4-TB_1x02-1MP_P2.00mm_Vertical
J10: A01 BM05B-SRSS-TB; JST_SH_BM05B-SRSS-TB_1x05-1MP_P1.00mm_Vertical
J11: A02 BM05B-SRSS-TB; JST_SH_BM05B-SRSS-TB_1x05-1MP_P1.00mm_Vertical
J12: A03 BM05B-SRSS-TB; JST_SH_BM05B-SRSS-TB_1x05-1MP_P1.00mm_Vertical
J13: A04 BM05B-SRSS-TB; JST_SH_BM05B-SRSS-TB_1x05-1MP_P1.00mm_Vertical
J14: A05 BM05B-SRSS-TB; JST_SH_BM05B-SRSS-TB_1x05-1MP_P1.00mm_Vertical
J15: A06 BM05B-SRSS-TB; JST_SH_BM05B-SRSS-TB_1x05-1MP_P1.00mm_Vertical
J16: A07 BM05B-SRSS-TB; JST_SH_BM05B-SRSS-TB_1x05-1MP_P1.00mm_Vertical
J17: A08 BM05B-SRSS-TB; JST_SH_BM05B-SRSS-TB_1x05-1MP_P1.00mm_Vertical
J18: A09 BM05B-SRSS-TB; JST_SH_BM05B-SRSS-TB_1x05-1MP_P1.00mm_Vertical
J19: A10 BM05B-SRSS-TB; JST_SH_BM05B-SRSS-TB_1x05-1MP_P1.00mm_Vertical
J20: A11 BM05B-SRSS-TB; JST_SH_BM05B-SRSS-TB_1x05-1MP_P1.00mm_Vertical
J21: A12 BM05B-SRSS-TB; JST_SH_BM05B-SRSS-TB_1x05-1MP_P1.00mm_Vertical
J22: A13 BM05B-SRSS-TB; JST_SH_BM05B-SRSS-TB_1x05-1MP_P1.00mm_Vertical
J23: A14 BM05B-SRSS-TB; JST_SH_BM05B-SRSS-TB_1x05-1MP_P1.00mm_Vertical
J26: B01 BM05B-SRSS-TB; JST_SH_BM05B-SRSS-TB_1x05-1MP_P1.00mm_Vertical
J27: B02 BM05B-SRSS-TB; JST_SH_BM05B-SRSS-TB_1x05-1MP_P1.00mm_Vertical
J28: B03 BM05B-SRSS-TB; JST_SH_BM05B-SRSS-TB_1x05-1MP_P1.00mm_Vertical
J29: B04 BM05B-SRSS-TB; JST_SH_BM05B-SRSS-TB_1x05-1MP_P1.00mm_Vertical
J30: B05 BM05B-SRSS-TB; JST_SH_BM05B-SRSS-TB_1x05-1MP_P1.00mm_Vertical
J31: B06 BM05B-SRSS-TB; JST_SH_BM05B-SRSS-TB_1x05-1MP_P1.00mm_Vertical
J32: B07 BM05B-SRSS-TB; JST_SH_BM05B-SRSS-TB_1x05-1MP_P1.00mm_Vertical
J33: B08 BM05B-SRSS-TB; JST_SH_BM05B-SRSS-TB_1x05-1MP_P1.00mm_Vertical
J34: B09 BM05B-SRSS-TB; JST_SH_BM05B-SRSS-TB_1x05-1MP_P1.00mm_Vertical
J35: B10 BM05B-SRSS-TB; JST_SH_BM05B-SRSS-TB_1x05-1MP_P1.00mm_Vertical
J36: B11 BM05B-SRSS-TB; JST_SH_BM05B-SRSS-TB_1x05-1MP_P1.00mm_Vertical
J37: B12 BM05B-SRSS-TB; JST_SH_BM05B-SRSS-TB_1x05-1MP_P1.00mm_Vertical
J38: B13 BM05B-SRSS-TB; JST_SH_BM05B-SRSS-TB_1x05-1MP_P1.00mm_Vertical
J39: B14 BM05B-SRSS-TB; JST_SH_BM05B-SRSS-TB_1x05-1MP_P1.00mm_Vertical
J40: B15 BM05B-SRSS-TB; JST_SH_BM05B-SRSS-TB_1x05-1MP_P1.00mm_Vertical
J41: B16 BM05B-SRSS-TB; JST_SH_BM05B-SRSS-TB_1x05-1MP_P1.00mm_Vertical
J42: C01 BM05B-SRSS-TB; JST_SH_BM05B-SRSS-TB_1x05-1MP_P1.00mm_Vertical
J43: C02 BM05B-SRSS-TB; JST_SH_BM05B-SRSS-TB_1x05-1MP_P1.00mm_Vertical
J44: C03 BM05B-SRSS-TB; JST_SH_BM05B-SRSS-TB_1x05-1MP_P1.00mm_Vertical
J45: C04 BM05B-SRSS-TB; JST_SH_BM05B-SRSS-TB_1x05-1MP_P1.00mm_Vertical
J46: C05 BM05B-SRSS-TB; JST_SH_BM05B-SRSS-TB_1x05-1MP_P1.00mm_Vertical
J47: C06 BM05B-SRSS-TB; JST_SH_BM05B-SRSS-TB_1x05-1MP_P1.00mm_Vertical
J48: C07 BM05B-SRSS-TB; JST_SH_BM05B-SRSS-TB_1x05-1MP_P1.00mm_Vertical
J49: C08 BM05B-SRSS-TB; JST_SH_BM05B-SRSS-TB_1x05-1MP_P1.00mm_Vertical
J50: C09 BM05B-SRSS-TB; JST_SH_BM05B-SRSS-TB_1x05-1MP_P1.00mm_Vertical
J51: C10 BM05B-SRSS-TB; JST_SH_BM05B-SRSS-TB_1x05-1MP_P1.00mm_Vertical
J52: C11 BM05B-SRSS-TB; JST_SH_BM05B-SRSS-TB_1x05-1MP_P1.00mm_Vertical
J53: C12 BM05B-SRSS-TB; JST_SH_BM05B-SRSS-TB_1x05-1MP_P1.00mm_Vertical
J54: C13 BM05B-SRSS-TB; JST_SH_BM05B-SRSS-TB_1x05-1MP_P1.00mm_Vertical
J55: C14 BM05B-SRSS-TB; JST_SH_BM05B-SRSS-TB_1x05-1MP_P1.00mm_Vertical
J56: C15 BM05B-SRSS-TB; JST_SH_BM05B-SRSS-TB_1x05-1MP_P1.00mm_Vertical
J57: C16 BM05B-SRSS-TB; JST_SH_BM05B-SRSS-TB_1x05-1MP_P1.00mm_Vertical
L1: 74438357022 / 2.2uH; L_Wuerth_MAPI-4030
Q1: 2N7002; SOT-23
R1, R10, R11, R12, R13, R14, R15: 100k; R_0603_1608Metric
R2, R40, R41, R42: 10k; R_0603_1608Metric
R30, R31, R32, R33, R34, R35: 33R candidate; R_0603_1608Metric
R50: 316k 0.1%; R_0603_1608Metric
R51: 66.5k 0.1%; R_0603_1608Metric
TP1: GND; TestPoint_Pad_D1.0mm
TP2: REG_3V45; TestPoint_Pad_D1.0mm
TP3: SENSOR_3V45; TestPoint_Pad_D1.0mm
TP4: VIN; TestPoint_Pad_D1.0mm
U1, U2: SN74LVC244APWR; TSSOP-20_4.4x6.5mm_P0.65mm
U3, U4, U5: CD74HC4067PW; TSSOP-24_4.4x7.8mm_P0.65mm
U6: SN74LVC125APWR; TSSOP-14_4.4x5mm_P0.65mm
U7: AP3429AW5-7; TSOT-23-5

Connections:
/A0: U1.5 (Y6), U3.10 (S0), U4.10 (S0), U5.10 (S0)
/A0_MCU: J1.2, R10.1, U1.15 (A6)
/A1: U1.3 (Y7), U3.11 (S1), U4.11 (S1), U5.11 (S1)
/A01_DO: J10.4, U3.9 (I0)
/A1_MCU: J1.4, R11.1, U1.17 (A7)
/A2: U2.18 (Y0), U3.14 (S2), U4.14 (S2), U5.14 (S2)
/A02_DO: J11.4, U3.8 (I1)
/A2_MCU: J1.5, R12.1, U2.2 (A0)
/A3: U2.16 (Y1), U3.13 (S3), U4.13 (S3), U5.13 (S3)
/A03_DO: J12.4, U3.7 (I2)
/A3_MCU: J1.6, R13.1, U2.4 (A1)
/A04_DO: J13.4, U3.6 (I3)
/A05_DO: J14.4, U3.5 (I4)
/A06_DO: J15.4, U3.4 (I5)
/A07_DO: J16.4, U3.3 (I6)
/A08_DO: J17.4, U3.2 (I7)
/A09_DO: J18.4, U3.23 (I8)
/A10_DO: J19.4, U3.22 (I9)
/A11_DO: J20.4, U3.21 (I10)
/A12_DO: J21.4, U3.20 (I11)
/A13_DO: J22.4, U3.19 (I12)
/A14_DO: J23.4, U3.18 (I13)
/B01_DO: J26.4, U4.9 (I0)
/B02_DO: J27.4, U4.8 (I1)
/B03_DO: J28.4, U4.7 (I2)
/B04_DO: J29.4, U4.6 (I3)
/B05_DO: J30.4, U4.5 (I4)
/B06_DO: J31.4, U4.4 (I5)
/B07_DO: J32.4, U4.3 (I6)
/B08_DO: J33.4, U4.2 (I7)
/B09_DO: J34.4, U4.23 (I8)
/B10_DO: J35.4, U4.22 (I9)
/B11_DO: J36.4, U4.21 (I10)
/B12_DO: J37.4, U4.20 (I11)
/B13_DO: J38.4, U4.19 (I12)
/B14_DO: J39.4, U4.18 (I13)
/B15_DO: J40.4, U4.17 (I14)
/B16_DO: J41.4, U4.16 (I15)
/C01_DO: J42.4, U5.9 (I0)
/C02_DO: J43.4, U5.8 (I1)
/C03_DO: J44.4, U5.7 (I2)
/C04_DO: J45.4, U5.6 (I3)
/C05_DO: J46.4, U5.5 (I4)
/C06_DO: J47.4, U5.4 (I5)
/C07_DO: J48.4, U5.3 (I6)
/C08_DO: J49.4, U5.2 (I7)
/C09_DO: J50.4, U5.23 (I8)
/C10_DO: J51.4, U5.22 (I9)
/C11_DO: J52.4, U5.21 (I10)
/C12_DO: J53.4, U5.20 (I11)
/C13_DO: J54.4, U5.19 (I12)
/C14_DO: J55.4, U5.18 (I13)
/C15_DO: J56.4, U5.17 (I14)
/C16_DO: J57.4, U5.16 (I15)
/CLK_A: J10.3, J11.3, J12.3, J13.3, J14.3, J15.3, J16.3, J17.3, J18.3, J19.3, J20.3, J21.3, J22.3, J23.3, R30.2
/CLK_A_DRV: R30.1, U1.18 (Y0)
/CLK_B: J26.3, J27.3, J28.3, J29.3, J30.3, J31.3, J32.3, J33.3, J34.3, J35.3, J36.3, J37.3, J38.3, J39.3, J40.3, J41.3, R32.2
/CLK_B_DRV: R32.1, U1.16 (Y1)
/CLK_C: J42.3, J43.3, J44.3, J45.3, J46.3, J47.3, J48.3, J49.3, J50.3, J51.3, J52.3, J53.3, J54.3, J55.3, J56.3, J57.3, R34.2
/CLK_C_DRV: R34.1, U1.14 (Y2)
/CLK_MCU: J2.2, R14.1, U1.2 (A0), U1.4 (A1), U1.6 (A2)
/CS_A: J10.5, J11.5, J12.5, J13.5, J14.5, J15.5, J16.5, J17.5, J18.5, J19.5, J20.5, J21.5, J22.5, J23.5, R31.2
/CS_A_DRV: R31.1, U1.12 (Y3)
/CS_B: J26.5, J27.5, J28.5, J29.5, J30.5, J31.5, J32.5, J33.5, J34.5, J35.5, J36.5, J37.5, J38.5, J39.5, J40.5, J41.5, R33.2
/CS_B_DRV: R33.1, U1.9 (Y4)
/CS_C: J42.5, J43.5, J44.5, J45.5, J46.5, J47.5, J48.5, J49.5, J50.5, J51.5, J52.5, J53.5, J54.5, J55.5, J56.5, J57.5, R35.2
/CS_C_DRV: R35.1, U1.7 (Y5)
/CS_MCU: J1.7, R15.1, U1.8 (A3), U1.11 (A4), U1.13 (A5)
/DO_A: R40.1, U3.1 (COM), U6.2 (A1)
/DO_A_MCU: J2.3, U6.3 (Y1)
/DO_B: R41.1, U4.1 (COM), U6.5 (A2)
/DO_B_MCU: J2.4, U6.6 (Y2)
/DO_C: R42.1, U5.1 (COM), U6.9 (A3)
/DO_C_MCU: J2.1, U6.8 (Y3)
/ENABLE_N: Q1.3 (D), R2.1, U1.1 (OE1_N), U1.19 (OE2_N), U2.1 (OE1_N), U2.19 (OE2_N), U3.15 (E), U4.15 (E), U5.15 (E)
/EN_MCU: J1.1, Q1.1 (G), R1.1
/EXT5V: F4.1, J3.1
/FB: C10.2, R50.2, R51.1, U7.5 (FB)
/FUSED5V: D1.2 (A), F4.2
/GND: C1.2, C2.2, C3.2, C4.2, C5.2, C6.2, C7.2, C8.2, C9.2, J2.6, J3.2, J10.1, J11.1, J12.1, J13.1, J14.1, J15.1, J16.1, J17.1, J18.1, J19.1, J20.1, J21.1, J22.1, J23.1, J26.1, J27.1, J28.1, J29.1, J30.1, J31.1, J32.1, J33.1, J34.1, J35.1, J36.1, J37.1, J38.1, J39.1, J40.1, J41.1, J42.1, J43.1, J44.1, J45.1, J46.1, J47.1, J48.1, J49.1, J50.1, J51.1, J52.1, J53.1, J54.1, J55.1, J56.1, J57.1, Q1.2 (S), R1.2, R10.2, R11.2, R12.2, R13.2, R14.2, R15.2, R51.2, TP1.1, U1.10 (GND), U2.6 (A2), U2.8 (A3), U2.10 (GND), U2.11 (A4), U2.13 (A5), U2.15 (A6), U2.17 (A7), U3.12 (GND), U3.16 (I15), U3.17 (I14), U4.12 (GND), U5.12 (GND), U6.1 (OE1_N), U6.4 (OE2_N), U6.7 (GND), U6.10 (OE3_N), U6.12 (A4), U7.2 (GND)
/LX: L1.1, U7.3 (LX)
/MCU_3V3: C6.1, J2.5, U6.13 (OE4_N), U6.14 (VCC)
/REG_3V45: C8.1, C9.1, C10.1, F5.1, L1.2, R50.1, TP2.1
/SENSOR_3V45: C1.1, C2.1, C3.1, C4.1, C5.1, F5.2, J10.2, J11.2, J12.2, J13.2, J14.2, J15.2, J16.2, J17.2, J18.2, J19.2, J20.2, J21.2, J22.2, J23.2, J26.2, J27.2, J28.2, J29.2, J30.2, J31.2, J32.2, J33.2, J34.2, J35.2, J36.2, J37.2, J38.2, J39.2, J40.2, J41.2, J42.2, J43.2, J44.2, J45.2, J46.2, J47.2, J48.2, J49.2, J50.2, J51.2, J52.2, J53.2, J54.2, J55.2, J56.2, J57.2, R2.2, R40.2, R41.2, R42.2, TP3.1, U1.20 (VCC), U2.20 (VCC), U3.24 (VCC), U4.24 (VCC), U5.24 (VCC)
/VIN: C7.1, D1.1 (K), TP4.1, U7.1 (EN), U7.4 (VIN)

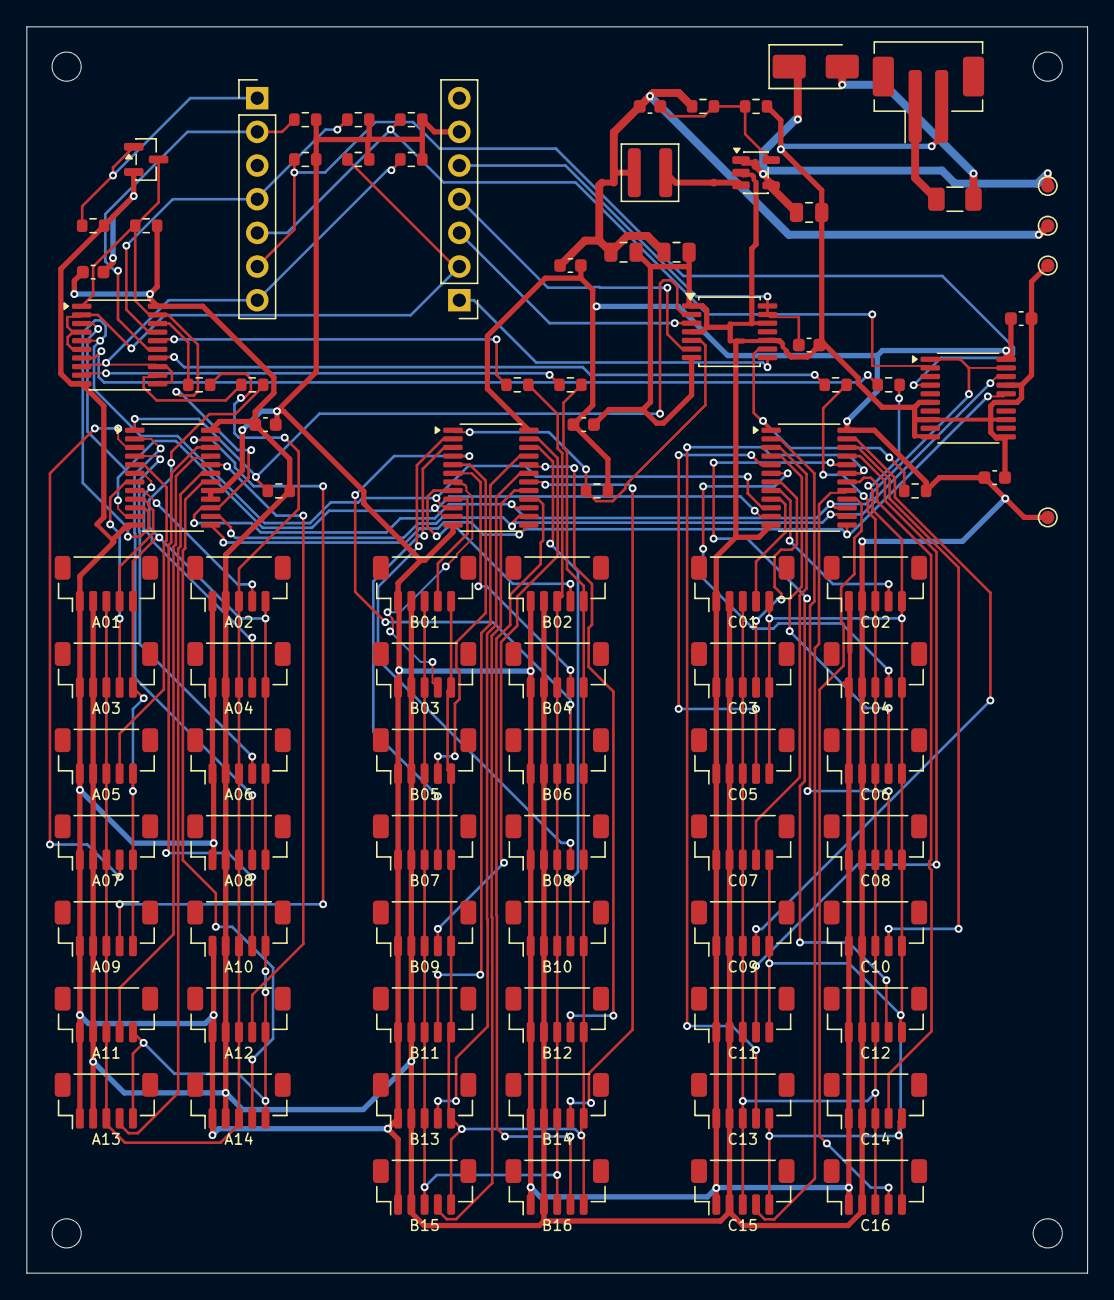
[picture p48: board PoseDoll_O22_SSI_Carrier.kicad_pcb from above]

Board: 4 copper layers, 80.0 x 94.0 mm, 98 parts (0 on the bottom side), 85 nets.

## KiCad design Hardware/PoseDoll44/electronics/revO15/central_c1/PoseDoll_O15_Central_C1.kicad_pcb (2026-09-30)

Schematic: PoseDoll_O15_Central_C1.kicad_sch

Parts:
C1, C2: 10u X7R 10V; C_0603_1608Metric
C100, C102, C103, C104, C105, C200, C202, C203, C204, C205, C300, C302, C303, C304, C305, C400, C402, C403, C404, C405, C500, C502, C503, C504, C505, C600, C602, C603, C604, C605: 100n X7R 10V; C_0603_1608Metric
C101, C201, C301, C401, C501, C601: 1u X7R 10V; C_0603_1608Metric
D1: SS14 / 1A 40V; D_SMA
J1: CHAIN1 GND,3V3,SCK,MOSI,MISO,CS; JST_GH_SM06B-GHS-TB_1x06-1MP_P1.25mm_Horizontal
J2: CHAIN2 GND,3V3,SCK,MOSI,MISO,CS; JST_GH_SM06B-GHS-TB_1x06-1MP_P1.25mm_Horizontal
J3: CHAIN3 GND,3V3,SCK,MOSI,MISO,CS; JST_GH_SM06B-GHS-TB_1x06-1MP_P1.25mm_Horizontal
J4: CHAIN4 GND,3V3,SCK,MOSI,MISO,CS; JST_GH_SM06B-GHS-TB_1x06-1MP_P1.25mm_Horizontal
J5: CHAIN5 GND,3V3,SCK,MOSI,MISO,CS; JST_GH_SM06B-GHS-TB_1x06-1MP_P1.25mm_Horizontal
J6: CHAIN6 GND,3V3,SCK,MOSI,MISO,CS; JST_GH_SM06B-GHS-TB_1x06-1MP_P1.25mm_Horizontal
J7: 5V INPUT ONLY / JST PH 2; JST_PH_B2B-PH-SM4-TB_1x02-1MP_P2.00mm_Vertical
J8: Pololu D24V22F3 harness: GND, VIN5, VOUT3V3; JST_PH_B3B-PH-SM4-TB_1x03-1MP_P2.00mm_Vertical
Q1, Q2, Q3, Q4, Q5, Q6: 2N7002; SOT-23
R1, R2, R106, R206, R306, R406, R506, R606: 100k; R_0603_1608Metric
R100, R200, R300, R400, R500, R600: 88.7k 1%; R_0603_1608Metric
R101, R108, R109, R110, R201, R208, R209, R210, R301, R308, R309, R310, R401, R408, R409, R410, R501, R508, R509, R510, R601, R608, R609, R610: 47k; R_0603_1608Metric
R102, R107, R202, R207, R302, R307, R402, R407, R502, R507, R602, R607: 10k; R_0603_1608Metric
R103, R104, R105, R203, R204, R205, R303, R304, R305, R403, R404, R405, R503, R504, R505, R603, R604, R605: 100R; R_0603_1608Metric
TP1: P1_FAULT_N; TestPoint_Pad_D1.0mm
TP2: P2_FAULT_N; TestPoint_Pad_D1.0mm
TP3: P3_FAULT_N; TestPoint_Pad_D1.0mm
TP4: P4_FAULT_N; TestPoint_Pad_D1.0mm
TP5: P5_FAULT_N; TestPoint_Pad_D1.0mm
TP6: P6_FAULT_N; TestPoint_Pad_D1.0mm
U1: Seeed XIAO ESP32S3; 2x 1x7 P2.54 male pin strips; XIAO_ESP32S3_2x7_PTH
U100, U200, U300, U400, U500, U600: TPS2553DBVR-1 / latched-off; SOT-23-6
U101, U102, U103, U104, U201, U202, U203, U204, U301, U302, U303, U304, U401, U402, U403, U404, U501, U502, U503, U504, U601, U602, U603, U604: SN74LVC1G125DBVR; SOT-23-5

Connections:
/CS1: R102.2, U1.2 (D1_GPIO2), U103.2 (A), U104.1 (OE_N)
/CS2: R202.2, U1.4 (D3_GPIO4), U203.2 (A), U204.1 (OE_N)
/CS3: R302.2, U1.5 (D4_GPIO5), U303.2 (A), U304.1 (OE_N)
/CS4: R402.2, U1.6 (D5_GPIO6), U403.2 (A), U404.1 (OE_N)
/CS5: R502.2, U1.7 (D6_GPIO43), U503.2 (A), U504.1 (OE_N)
/CS6: R602.2, U1.8 (D7_GPIO44), U603.2 (A), U604.1 (OE_N)
/GND: C1.2, C2.2, C100.2, C101.2, C102.2, C103.2, C104.2, C105.2, C200.2, C201.2, C202.2, C203.2, C204.2, C205.2, C300.2, C301.2, C302.2, C303.2, C304.2, C305.2, C400.2, C401.2, C402.2, C403.2, C404.2, C405.2, C500.2, C501.2, C502.2, C503.2, C504.2, C505.2, C600.2, C601.2, C602.2, C603.2, C604.2, C605.2, J1.1, J2.1, J3.1, J4.1, J5.1, J6.1, J7.2, J8.1, Q1.2 (S), Q2.2 (S), Q3.2 (S), Q4.2 (S), Q5.2 (S), Q6.2 (S), R1.2, R100.2, R106.2, R108.2, R109.2, R200.2, R206.2, R208.2, R209.2, R300.2, R306.2, R308.2, R309.2, R400.2, R406.2, R408.2, R409.2, R500.2, R506.2, R508.2, R509.2, R600.2, R606.2, R608.2, R609.2, U1.13 (GND), U100.2 (GND), U101.3 (GND), U102.3 (GND), U103.3 (GND), U104.3 (GND), U200.2 (GND), U201.3 (GND), U202.3 (GND), U203.3 (GND), U204.3 (GND), U300.2 (GND), U301.3 (GND), U302.3 (GND), U303.3 (GND), U304.3 (GND), U400.2 (GND), U401.3 (GND), U402.3 (GND), U403.3 (GND), U404.3 (GND), U500.2 (GND), U501.3 (GND), U502.3 (GND), U503.3 (GND), U504.3 (GND), U600.2 (GND), U601.3 (GND), U602.3 (GND), U603.3 (GND), U604.3 (GND)
/IO_ENABLE: Q1.1 (G), Q2.1 (G), Q3.1 (G), Q4.1 (G), Q5.1 (G), Q6.1 (G), R1.1, U1.1 (D0_GPIO1)
/MCU_3V3: C103.1, C203.1, C303.1, C403.1, C503.1, C603.1, R2.2, R102.1, R202.1, R302.1, R402.1, R502.1, R602.1, U1.12 (3V3_MCU), U104.5 (VCC), U204.5 (VCC), U304.5 (VCC), U404.5 (VCC), U504.5 (VCC), U604.5 (VCC)
/MCU_5V: D1.1 (K), U1.14 (5V_VBUS)
/MISO: R2.1, U1.10 (D9_GPIO8), U104.4 (Y), U204.4 (Y), U304.4 (Y), U404.4 (Y), U504.4 (Y), U604.4 (Y)
/MOSI: U1.11 (D10_GPIO9), U102.2 (A), U202.2 (A), U302.2 (A), U402.2 (A), U502.2 (A), U602.2 (A)
/P1_3V3: C101.1, C102.1, C104.1, C105.1, J1.2, R101.1, R107.1, U100.6 (OUT), U101.5 (VCC), U102.5 (VCC), U103.5 (VCC)
/P1_CS: J1.6, R105.2, R107.2
/P1_CS_DRV: R105.1, U103.4 (Y)
/P1_FAULT_N: R110.2, TP1.1, U100.4 (FAULT_N)
/P1_ILIM: R100.1, U100.5 (ILIM)
/P1_MISO: J1.5, R106.1, U104.2 (A)
/P1_MOSI: J1.4, R104.2, R109.1
/P1_MOSI_DRV: R104.1, U102.4 (Y)
/P1_OE_N: Q1.3 (D), R101.2, U101.1 (OE_N), U102.1 (OE_N), U103.1 (OE_N)
/P1_SCK: J1.3, R103.2, R108.1
/P1_SCK_DRV: R103.1, U101.4 (Y)
/P2_3V3: C201.1, C202.1, C204.1, C205.1, J2.2, R201.1, R207.1, U200.6 (OUT), U201.5 (VCC), U202.5 (VCC), U203.5 (VCC)
/P2_CS: J2.6, R205.2, R207.2
/P2_CS_DRV: R205.1, U203.4 (Y)
/P2_FAULT_N: R210.2, TP2.1, U200.4 (FAULT_N)
/P2_ILIM: R200.1, U200.5 (ILIM)
/P2_MISO: J2.5, R206.1, U204.2 (A)
/P2_MOSI: J2.4, R204.2, R209.1
/P2_MOSI_DRV: R204.1, U202.4 (Y)
/P2_OE_N: Q2.3 (D), R201.2, U201.1 (OE_N), U202.1 (OE_N), U203.1 (OE_N)
/P2_SCK: J2.3, R203.2, R208.1
/P2_SCK_DRV: R203.1, U201.4 (Y)
/P3_3V3: C301.1, C302.1, C304.1, C305.1, J3.2, R301.1, R307.1, U300.6 (OUT), U301.5 (VCC), U302.5 (VCC), U303.5 (VCC)
/P3_CS: J3.6, R305.2, R307.2
/P3_CS_DRV: R305.1, U303.4 (Y)
/P3_FAULT_N: R310.2, TP3.1, U300.4 (FAULT_N)
/P3_ILIM: R300.1, U300.5 (ILIM)
/P3_MISO: J3.5, R306.1, U304.2 (A)
/P3_MOSI: J3.4, R304.2, R309.1
/P3_MOSI_DRV: R304.1, U302.4 (Y)
/P3_OE_N: Q3.3 (D), R301.2, U301.1 (OE_N), U302.1 (OE_N), U303.1 (OE_N)
/P3_SCK: J3.3, R303.2, R308.1
/P3_SCK_DRV: R303.1, U301.4 (Y)
/P4_3V3: C401.1, C402.1, C404.1, C405.1, J4.2, R401.1, R407.1, U400.6 (OUT), U401.5 (VCC), U402.5 (VCC), U403.5 (VCC)
/P4_CS: J4.6, R405.2, R407.2
/P4_CS_DRV: R405.1, U403.4 (Y)
/P4_FAULT_N: R410.2, TP4.1, U400.4 (FAULT_N)
/P4_ILIM: R400.1, U400.5 (ILIM)
/P4_MISO: J4.5, R406.1, U404.2 (A)
/P4_MOSI: J4.4, R404.2, R409.1
/P4_MOSI_DRV: R404.1, U402.4 (Y)
/P4_OE_N: Q4.3 (D), R401.2, U401.1 (OE_N), U402.1 (OE_N), U403.1 (OE_N)
/P4_SCK: J4.3, R403.2, R408.1
/P4_SCK_DRV: R403.1, U401.4 (Y)
/P5_3V3: C501.1, C502.1, C504.1, C505.1, J5.2, R501.1, R507.1, U500.6 (OUT), U501.5 (VCC), U502.5 (VCC), U503.5 (VCC)
/P5_CS: J5.6, R505.2, R507.2
/P5_CS_DRV: R505.1, U503.4 (Y)
/P5_FAULT_N: R510.2, TP5.1, U500.4 (FAULT_N)
/P5_ILIM: R500.1, U500.5 (ILIM)
/P5_MISO: J5.5, R506.1, U504.2 (A)
/P5_MOSI: J5.4, R504.2, R509.1
/P5_MOSI_DRV: R504.1, U502.4 (Y)
/P5_OE_N: Q5.3 (D), R501.2, U501.1 (OE_N), U502.1 (OE_N), U503.1 (OE_N)
/P5_SCK: J5.3, R503.2, R508.1
/P5_SCK_DRV: R503.1, U501.4 (Y)
/P6_3V3: C601.1, C602.1, C604.1, C605.1, J6.2, R601.1, R607.1, U600.6 (OUT), U601.5 (VCC), U602.5 (VCC), U603.5 (VCC)
/P6_CS: J6.6, R605.2, R607.2
/P6_CS_DRV: R605.1, U603.4 (Y)
/P6_FAULT_N: R610.2, TP6.1, U600.4 (FAULT_N)
/P6_ILIM: R600.1, U600.5 (ILIM)
/P6_MISO: J6.5, R606.1, U604.2 (A)
/P6_MOSI: J6.4, R604.2, R609.1
/P6_MOSI_DRV: R604.1, U602.4 (Y)
/P6_OE_N: Q6.3 (D), R601.2, U601.1 (OE_N), U602.1 (OE_N), U603.1 (OE_N)
/P6_SCK: J6.3, R603.2, R608.1
/P6_SCK_DRV: R603.1, U601.4 (Y)
/SCK: U1.9 (D8_GPIO7), U101.2 (A), U201.2 (A), U301.2 (A), U401.2 (A), U501.2 (A), U601.2 (A)
/SENSOR_3V3: C2.1, C100.1, C200.1, C300.1, C400.1, C500.1, C600.1, J8.3, R110.1, R210.1, R310.1, R410.1, R510.1, R610.1, U100.1 (IN), U100.3 (EN), U200.1 (IN), U200.3 (EN), U300.1 (IN), U300.3 (EN), U400.1 (IN), U400.3 (EN), U500.1 (IN), U500.3 (EN), U600.1 (IN), U600.3 (EN)
/VIN_5V: C1.1, D1.2 (A), J7.1, J8.2

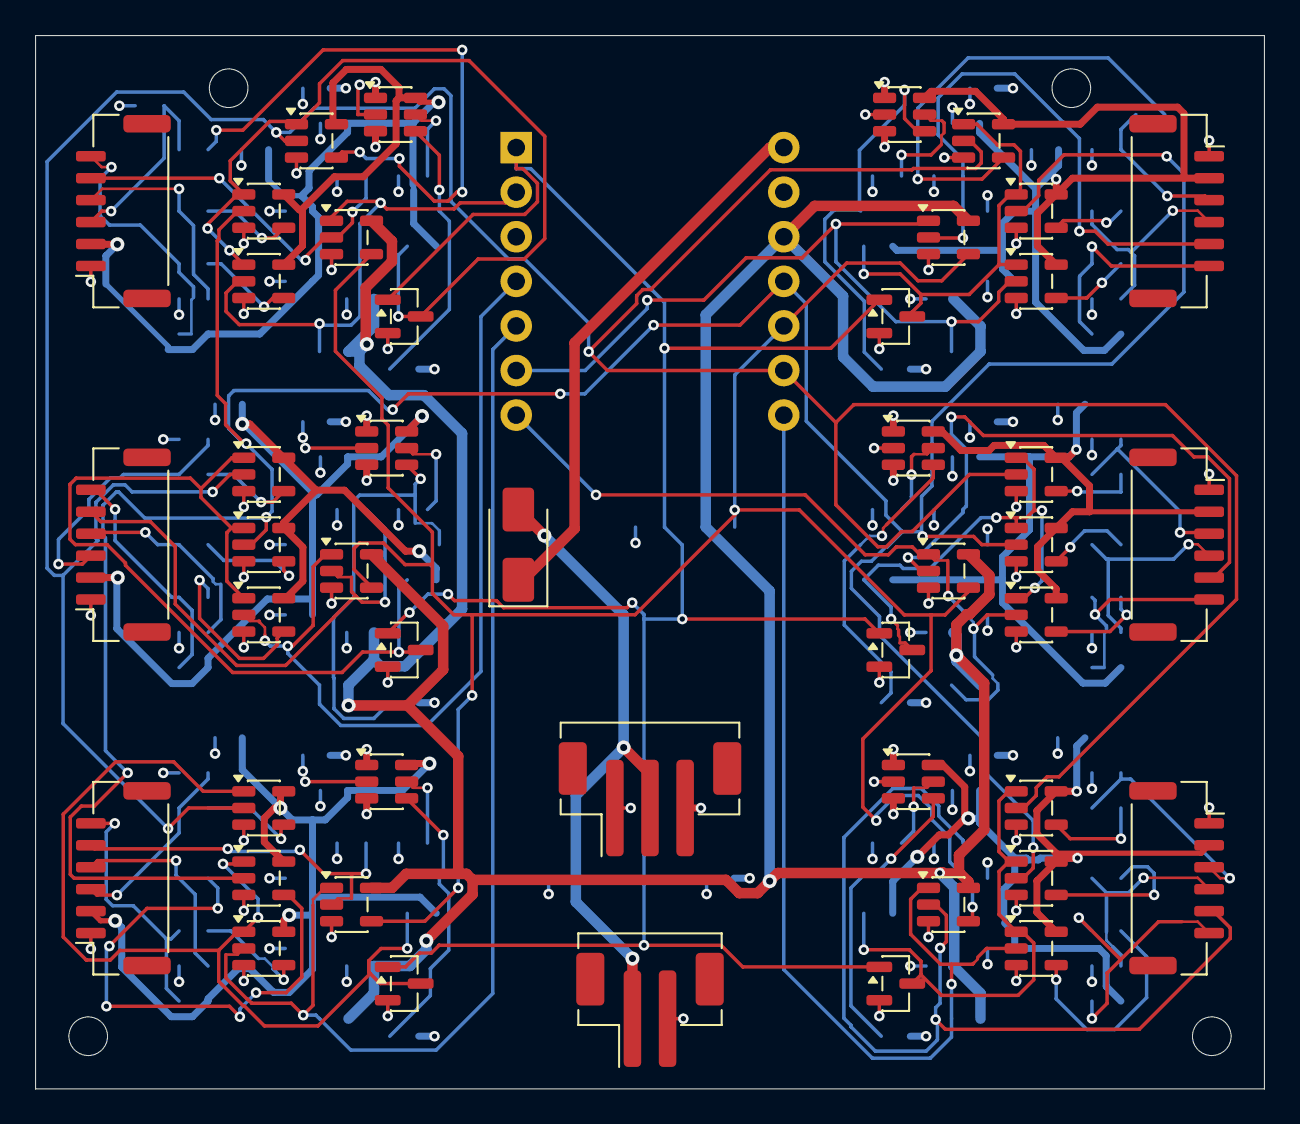
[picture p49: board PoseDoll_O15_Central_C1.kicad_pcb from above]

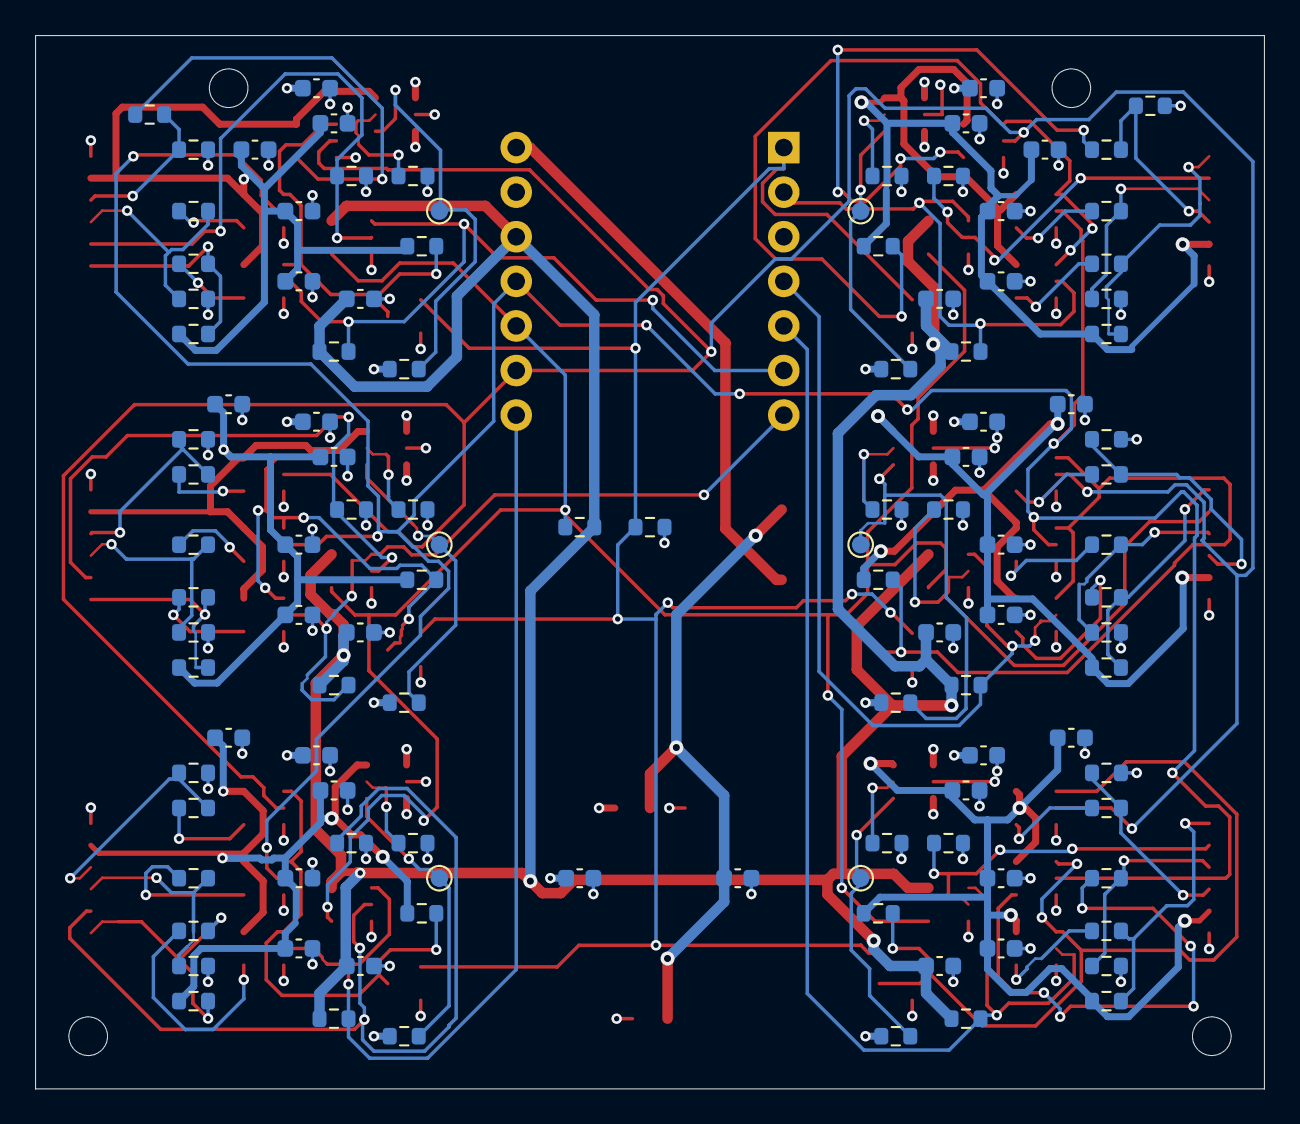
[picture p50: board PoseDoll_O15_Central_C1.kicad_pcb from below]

Board: 4 copper layers, 70.0 x 60.0 mm, 162 parts (112 on the bottom side), 81 nets.

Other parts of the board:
H1, H2, H3, H4: MountingHole_2.2mm_M2

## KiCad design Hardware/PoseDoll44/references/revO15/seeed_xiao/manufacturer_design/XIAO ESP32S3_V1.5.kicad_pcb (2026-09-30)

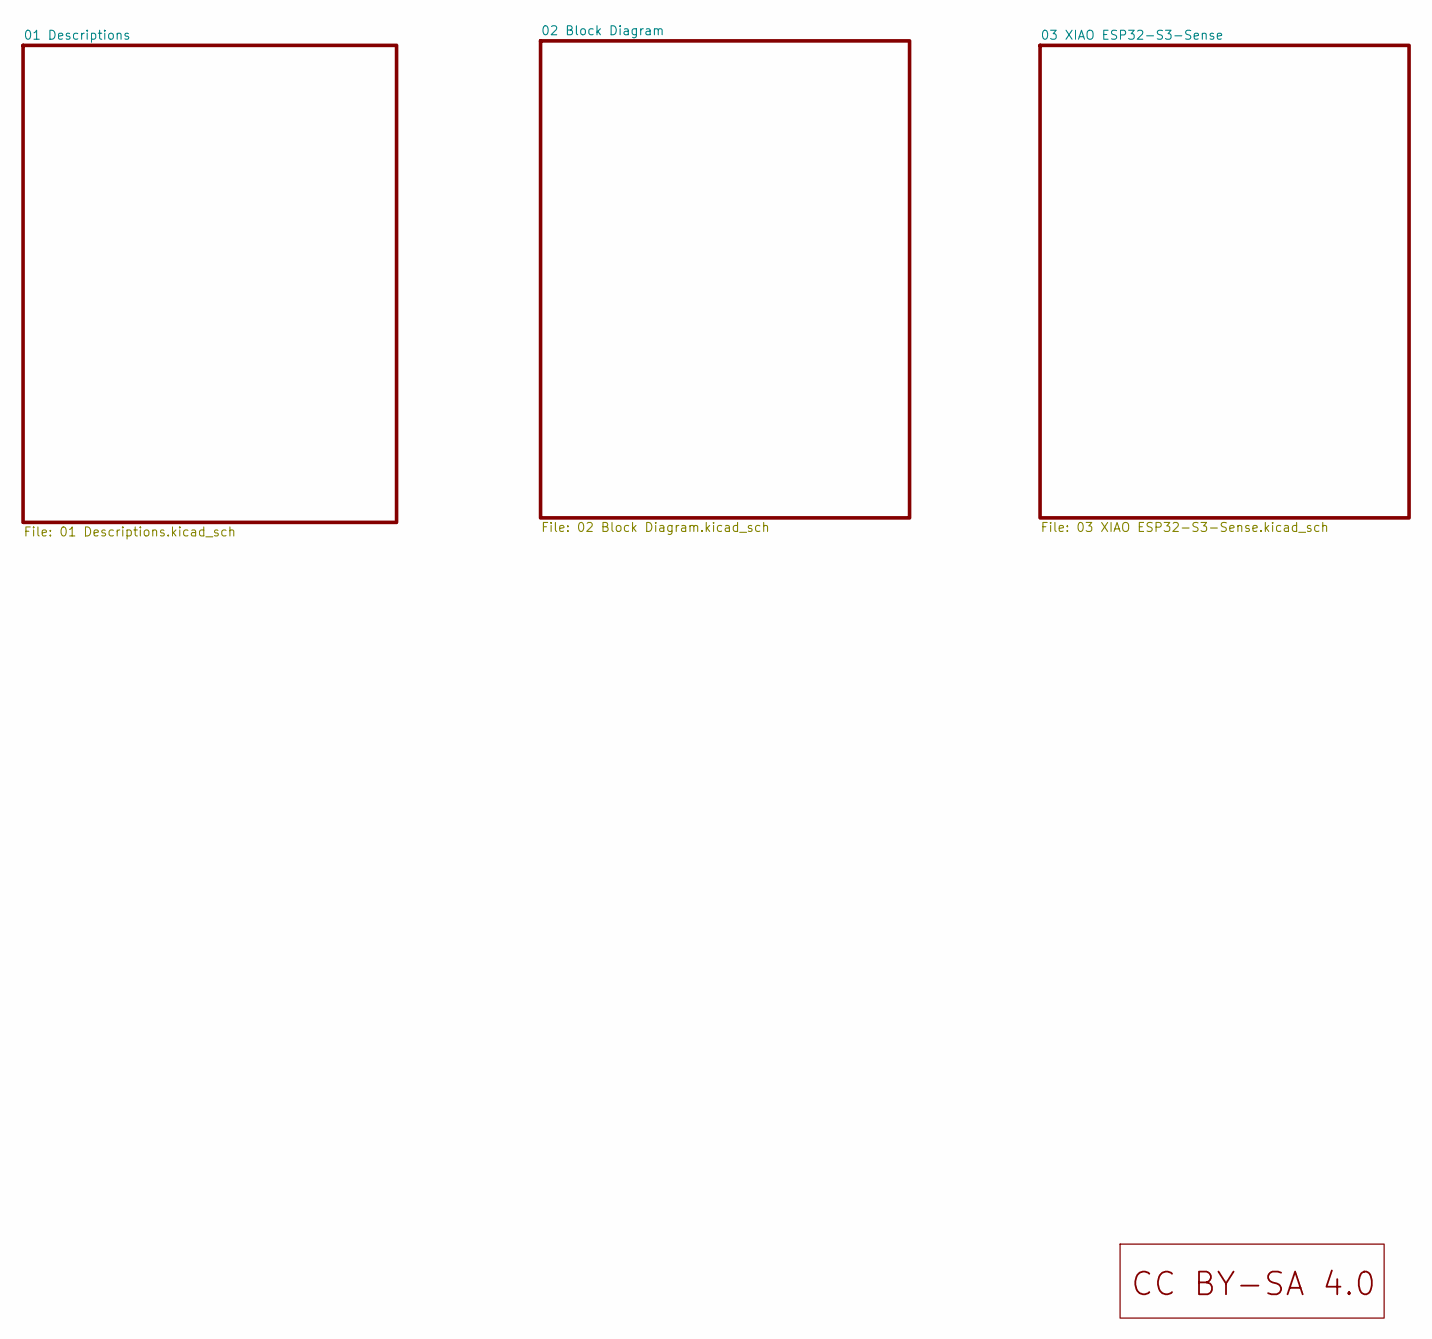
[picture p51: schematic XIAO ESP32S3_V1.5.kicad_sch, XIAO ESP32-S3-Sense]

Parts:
U6: LOGO_CC_BY-SA_4.0

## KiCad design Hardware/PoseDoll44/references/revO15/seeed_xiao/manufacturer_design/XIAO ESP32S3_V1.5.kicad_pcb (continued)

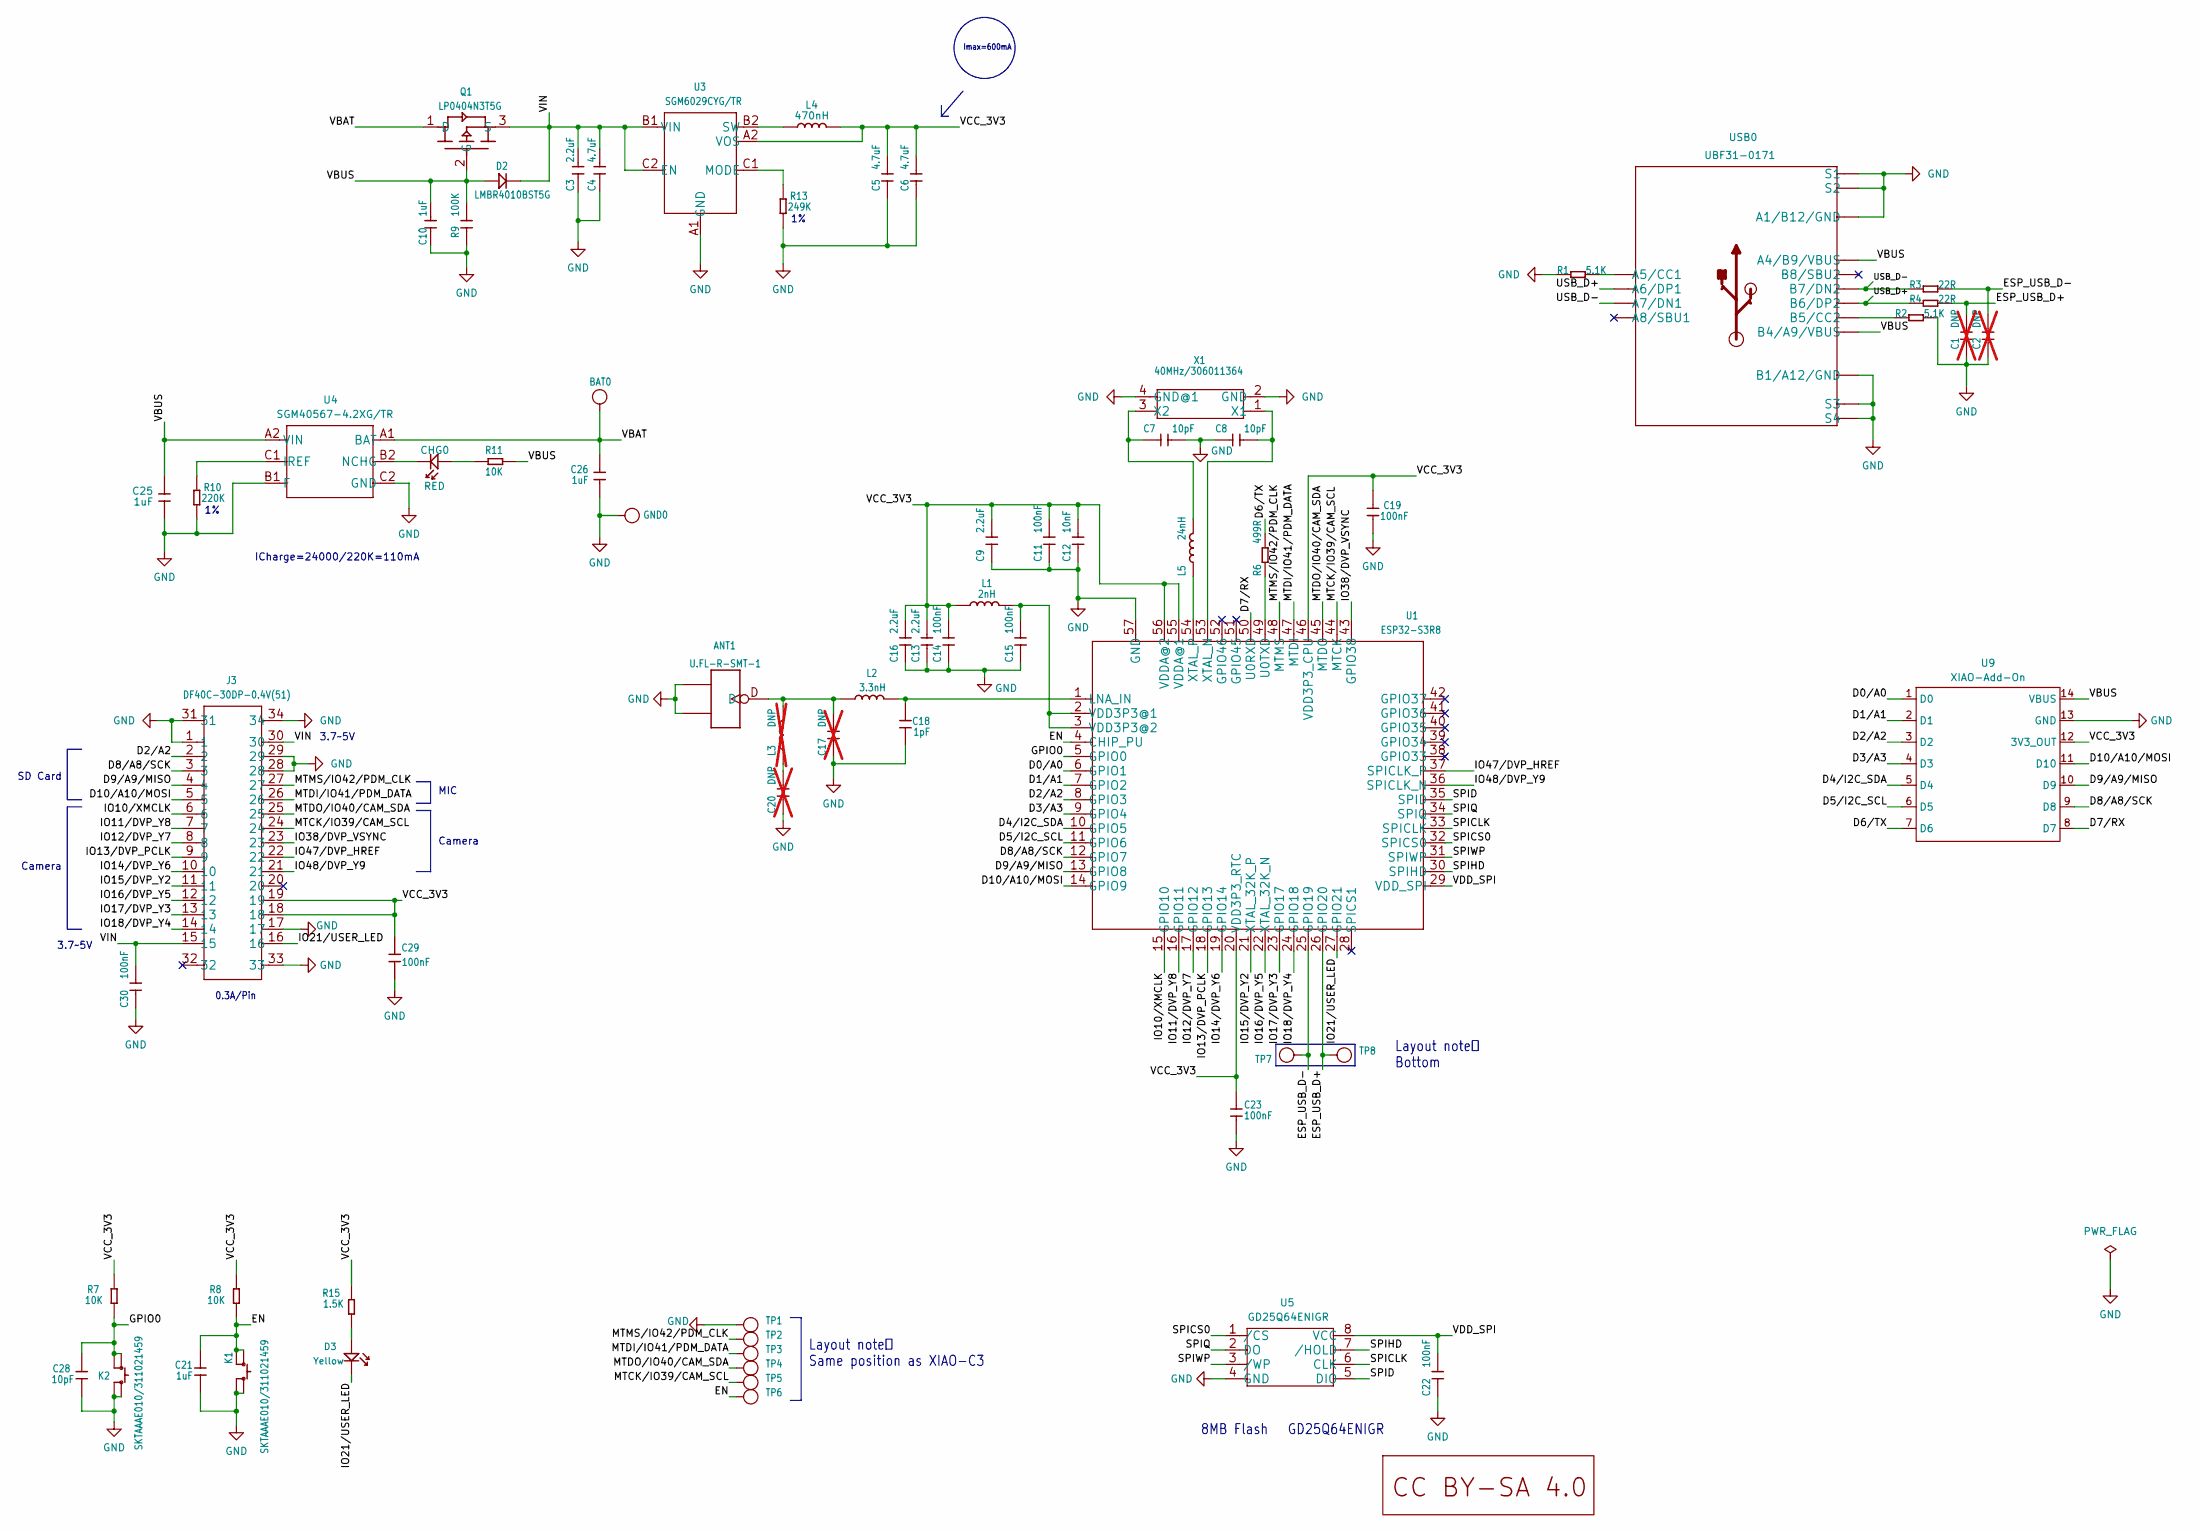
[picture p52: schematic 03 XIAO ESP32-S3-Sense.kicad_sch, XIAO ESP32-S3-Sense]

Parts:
ANT1: U.FL-R-SMT-1; U-FL3P-SMD-2.6X2.6X1.0MM
BAT0: VBAT; TP-80X40MIL
C1, C2, C17, C20: DNP; C0201; not fitted
C3, C9, C13, C16: 2.2uF; C0201
C4, C5, C6: 4.7uF; C0201
C7, C8, C28: 10pF; C0201
C10, C21, C25, C26: 1uF; C0201
C11, C14, C15, C19, C22, C23, C29, C30: 100nF; C0201
C12: 10nF; C0201
C18: 1pF; C0201
CHG0: RED; LED-0402
D2: LMBR4010BST5G; DFN1006-2L
D3: Yellow; LED-0402
GND0: GND; TP-80X40MIL
J3: DF40C-30DP-0.4V(51); BTB30-0.4-7.52X2.97X1.14
K1, K2: SKTAAAE010/311021459; SW4-SMD-2.8-2.6X1.6X0.53MM
L1: 2nH; L0201
L2: 3.3nH; L0201
L3: DNP; L0201; not fitted
L4: 470nH; L0603
L5: 24nH; L0201
Q1: LP0404N3T5G; PMOS_1.0_0.6_0.35MM
R1, R2: 5.1K; R0201
R3, R4: 22R; R0201
R6: 499R; R0201
R7, R8, R11: 10K; R0201
R9: 100K; C0201
R10: 220K; R0201
R13: 249K; R0201
R15: 1.5K; R0201
TP1, TP2, TP3, TP4, TP5, TP6, TP7, TP8: TEST-POINT'4545'; TP-D45MIL
U1: ESP32-S3R8; QFN56G-0.4-7X7MM
U3: SGM6029CYG/TR; BGA6-0.35-0.745X10.95X0.4MM
U4: SGM40567-4.2XG/TR; WLCSP-0.4-0.92X1.16X0.4MM
U5: GD25Q64ENIGR; USON8-0.8-4X3MM
U8: LOGO_CC_BY-SA_4.0
U9: XIAO-Add-On; XIAO-14P-Add-On
USB0: UBF31-0171; USB2.0-TYPE-C
X1: 40MHz/306011364; X4-SMD-1.6X1.2X0.35MM

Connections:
/03 XIAO ESP32-S3-Sense/D0/A0: U1.6 (GPIO1), U9.1 (D0)
/03 XIAO ESP32-S3-Sense/D1/A1: U1.7 (GPIO2), U9.2 (D1)
/03 XIAO ESP32-S3-Sense/D2/A2: J3.2, U1.8 (GPIO3), U9.3 (D2)
/03 XIAO ESP32-S3-Sense/D3/A3: U1.9 (GPIO4), U9.4 (D3)
/03 XIAO ESP32-S3-Sense/D4/I2C_SDA: U1.10 (GPIO5), U9.5 (D4)
/03 XIAO ESP32-S3-Sense/D5/I2C_SCL: U1.11 (GPIO6), U9.6 (D5)
/03 XIAO ESP32-S3-Sense/D6/TX: R6.2, U9.7 (D6)
/03 XIAO ESP32-S3-Sense/D7/RX: U1.50 (U0RXD), U9.8 (D7)
/03 XIAO ESP32-S3-Sense/D8/A8/SCK: J3.3, U1.12 (GPIO7), U9.9 (D8)
/03 XIAO ESP32-S3-Sense/D9/A9/MISO: J3.4, U1.13 (GPIO8), U9.10 (D9)
/03 XIAO ESP32-S3-Sense/D10/A10/MOSI: J3.5, U1.14 (GPIO9), U9.11 (D10)
/03 XIAO ESP32-S3-Sense/EN: C21.2, K1.1 (A0), K1.3 (A1), R8.1, TP6.T, U1.4 (CHIP_PU)
/03 XIAO ESP32-S3-Sense/ESP_USB_D+: C1.2, R4.2, TP8.T, U1.26 (GPIO20)
/03 XIAO ESP32-S3-Sense/ESP_USB_D-: C2.2, R3.2, TP7.T, U1.25 (GPIO19)
/03 XIAO ESP32-S3-Sense/GPIO0: C28.2, K2.1 (A0), K2.3 (A1), R7.1, U1.5 (GPIO0)
/03 XIAO ESP32-S3-Sense/IO10/XMCLK: J3.6, U1.15 (GPIO10)
/03 XIAO ESP32-S3-Sense/IO11/DVP_Y8: J3.7, U1.16 (GPIO11)
/03 XIAO ESP32-S3-Sense/IO12/DVP_Y7: J3.8, U1.17 (GPIO12)
/03 XIAO ESP32-S3-Sense/IO13/DVP_PCLK: J3.9, U1.18 (GPIO13)
/03 XIAO ESP32-S3-Sense/IO14/DVP_Y6: J3.10, U1.19 (GPIO14)
/03 XIAO ESP32-S3-Sense/IO15/DVP_Y2: J3.11, U1.21 (XTAL_32K_P)
/03 XIAO ESP32-S3-Sense/IO16/DVP_Y5: J3.12, U1.22 (XTAL_32K_N)
/03 XIAO ESP32-S3-Sense/IO17/DVP_Y3: J3.13, U1.23 (GPIO17)
/03 XIAO ESP32-S3-Sense/IO18/DVP_Y4: J3.14, U1.24 (GPIO18)
/03 XIAO ESP32-S3-Sense/IO21/USER_LED: D3.-, J3.16, U1.27 (GPIO21)
/03 XIAO ESP32-S3-Sense/IO38/DVP_VSYNC: J3.23, U1.43 (GPIO38)
/03 XIAO ESP32-S3-Sense/IO47/DVP_HREF: J3.22, U1.37 (SPICLK_P)
/03 XIAO ESP32-S3-Sense/IO48/DVP_Y9: J3.21, U1.36 (SPICLK_N)
/03 XIAO ESP32-S3-Sense/MTCK/IO39/CAM_SCL: J3.24, TP5.T, U1.44 (MTCK)
/03 XIAO ESP32-S3-Sense/MTDI/IO41/PDM_DATA: J3.26, TP3.T, U1.47 (MTDI)
/03 XIAO ESP32-S3-Sense/MTDO/IO40/CAM_SDA: J3.25, TP4.T, U1.45 (MTDO)
/03 XIAO ESP32-S3-Sense/MTMS/IO42/PDM_CLK: J3.27, TP2.T, U1.48 (MTMS)
/03 XIAO ESP32-S3-Sense/SPICLK: U1.33 (SPICLK), U5.6 (CLK)
/03 XIAO ESP32-S3-Sense/SPICS0: U1.32 (SPICS0), U5.1 (/CS)
/03 XIAO ESP32-S3-Sense/SPID: U1.35 (SPID), U5.5 (DIO)
/03 XIAO ESP32-S3-Sense/SPIHD: U1.30 (SPIHD), U5.7 (/HOLD)
/03 XIAO ESP32-S3-Sense/SPIQ: U1.34 (SPIQ), U5.2 (DO)
/03 XIAO ESP32-S3-Sense/SPIWP: U1.31 (SPIWP), U5.3 (/WP)
/03 XIAO ESP32-S3-Sense/USB_D+: R4.1, USB0.A6 (A6/DP1), USB0.B6 (B6/DP2)
/03 XIAO ESP32-S3-Sense/USB_D-: R3.1, USB0.A7 (A7/DN1), USB0.B7 (B7/DN2)
/03 XIAO ESP32-S3-Sense/VBAT: BAT0.1 (T), C26.1, Q1.1 (D), U4.A1 (BAT)
/03 XIAO ESP32-S3-Sense/VBUS: C10.1, C25.1, D2.+, Q1.2 (G), R9.2, R11.1, U4.A2 (VIN), U9.14 (VBUS), USB0.A4_B9 (A4/B9/VBUS), USB0.B4_A9 (B4/A9/VBUS)
/03 XIAO ESP32-S3-Sense/VCC_3V3: C5.2, C6.2, C9.2, C11.2, C12.2, C13.2, C14.2, C16.2, C19.2, C23.1, C29.2, J3.18, J3.19, L1.1, L4.2, R7.2, R8.2, R15.2, U1.20 (VDD3P3_RTC), U1.46 (VDD3P3_CPU), U1.55 (VDDA@1), U1.56 (VDDA@2), U3.A2 (VOS), U9.12 (3V3_OUT)
/03 XIAO ESP32-S3-Sense/VDD_SPI: C22.2, U1.29 (VDD_SPI), U5.8 (VCC)
/03 XIAO ESP32-S3-Sense/VIN: C3.1, C4.1, C30.2, D2.-, J3.15, J3.30, Q1.3 (S), U3.B1 (VIN), U3.C2 (EN)
GND: ANT1.GND1, ANT1.GND2, C1.1, C2.1, C3.2, C4.2, C5.1, C6.1, C7.2, C8.1, C9.1, C10.2, C11.1, C12.1, C13.1, C14.1, C15.1, C16.1, C17.1, C18.1, C19.1, C20.1, C21.1, C22.1, C23.2, C25.2, C26.2, C28.1, C29.1, C30.1, GND0.1 (T), J3.1, J3.17, J3.28, J3.29, J3.31, J3.33, J3.34, K1.2 (B0), K1.4 (B1), K2.2 (B0), K2.4 (B1), R1.1, R2.2, R9.1, R10.1, R13.1, TP1.T, U1.57 (GND), U3.A1 (GND), U4.B1 (F), U4.C2 (GND), U5.4 (GND), U9.13 (GND), USB0.A1_B12 (A1/B12/GND), USB0.B1_A12 (B1/A12/GND), USB0.S1, USB0.S2, USB0.S3, USB0.S4, USB0.S5 (S1), USB0.S6 (S2), X1.2 (GND), X1.4 (GND@1)
unnamed: ANT1.D, C17.2, L2.1, L3.2
unnamed: C20.2, L3.1
unnamed: CHG0.+, R11.2
unnamed: D3.+, R15.1
unnamed: C18.2, L2.2, U1.1 (LNA_IN)
unnamed: R6.1, U1.49 (U0TXD)
unnamed: C15.2, L1.2, U1.2 (VDD3P3@1), U1.3 (VDD3P3@2)
unnamed: C8.2, U1.53 (XTAL_N), X1.1 (X1)
unnamed: L5.1, U1.54 (XTAL_P)
unnamed: R13.2, U3.C1 (MODE)
unnamed: L4.1, U3.B2 (SW)
unnamed: R10.2, U4.C1 (IREF)
unnamed: CHG0.-, U4.B2 (NCHG)
unnamed: R1.2, USB0.A5 (A5/CC1)
unnamed: R2.1, USB0.B5 (B5/CC2)
unnamed: C7.1, L5.2, X1.3 (X2)

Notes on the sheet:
SD Card
Layout note： Bottom
Camera
ICharge=24000/220K=110mA
MIC
Layout note： Same position as XIAO-C3
Imax=600mA
3.7~5V
0.3A/Pin
8MB Flash GD25Q64ENIGR

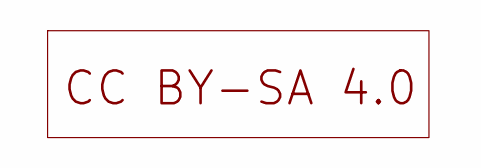
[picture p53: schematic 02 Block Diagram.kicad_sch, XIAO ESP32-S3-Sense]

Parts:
U7: LOGO_CC_BY-SA_4.0

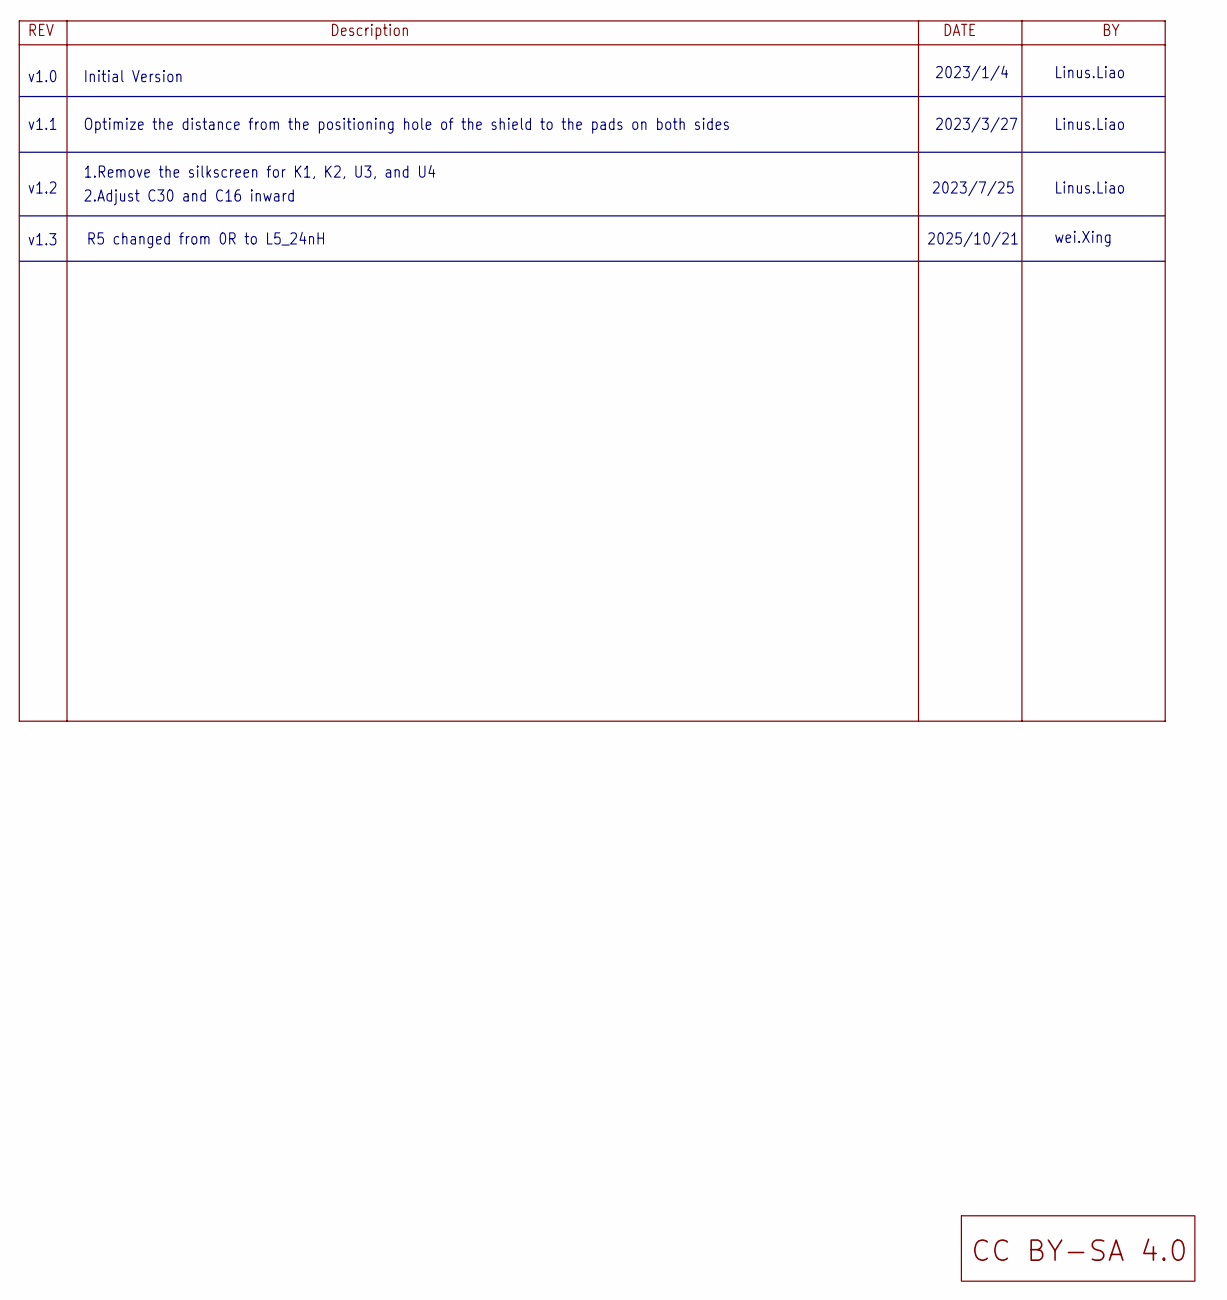
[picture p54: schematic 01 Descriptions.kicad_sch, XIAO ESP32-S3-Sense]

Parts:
U2: LOGO_CC_BY-SA_4.0

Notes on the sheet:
wei.Xing
Initial Version
R5 changed from 0R to L5_24nH
2.Adjust C30 and C16 inward
v1.1
v1.3
Linus.Liao
v1.0
2025/10/21
2023/7/25
v1.2
2023/1/4
1.Remove the silkscreen for K1, K2, U3, and U4
Optimize the distance from the positioning hole of the shield to the pads on both sides
2023/3/27

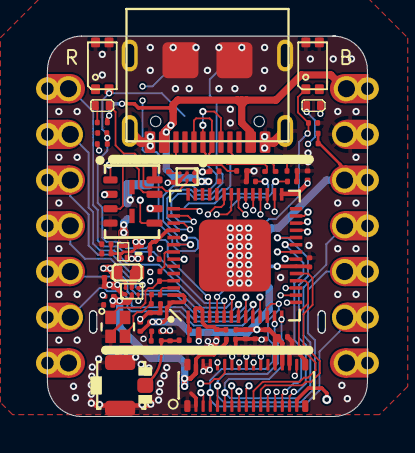
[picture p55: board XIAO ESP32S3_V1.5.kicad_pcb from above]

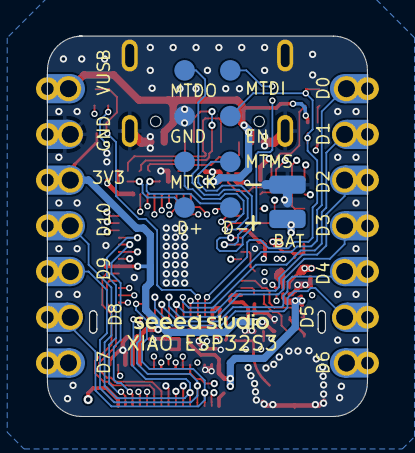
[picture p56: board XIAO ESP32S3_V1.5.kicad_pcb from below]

Board: 4 copper layers, 17.8 x 21.1 mm, 70 parts (10 on the bottom side), 62 nets.

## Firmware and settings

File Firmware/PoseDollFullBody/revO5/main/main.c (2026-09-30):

/* Rev O5 request-driven G0 + six A-topology remote nodes. PD41 v1 remains unchanged; no calibration, UDP, IMU or OTP writes.
 * ESP-IDF 6.1 esp_twai API. One pending TX buffer; it stays alive until completion.
 * Each acquired cohort starts blank. A missing node cannot reuse older angles.
 */
#include <stdatomic.h>
#include <string.h>
#include "sdkconfig.h"
#include "freertos/FreeRTOS.h"
#include "freertos/task.h"
#include "freertos/queue.h"
#include "freertos/semphr.h"
#include "driver/spi_master.h"
#include "driver/gpio.h"
#include "driver/usb_serial_jtag.h"
#include "esp_twai.h"
#include "esp_twai_onchip.h"
#include "esp_timer.h"
#include "esp_rom_sys.h"
#include "esp_random.h"
#include "esp_mac.h"
#include "esp_err.h"
#include "pd41_config.h"
#include "static_gateway.h"
#define PD_FAULT 0x8000
enum { NODE=CONFIG_PD_NODE_ID, IO_FAIL=1, PARITY_FAIL=2, SENSOR_ERROR=4, MAGNET_FAIL=8, NONZERO_OTP=16 };
typedef struct {uint64_t us;uint32_t id;uint8_t bytes[8];} rx_event_t;
#if !CONFIG_PD_EXTERNAL_GATEWAY
static spi_device_handle_t sensor;
#endif
static twai_node_handle_t can;
static QueueHandle_t receive_queue;
static SemaphoreHandle_t transmit_done;
static atomic_bool rx_overflow;
static volatile bool tx_success;
static twai_frame_t transmit_frame;
static uint8_t transmit_bytes[8];
static uint64_t boot_id;
static uint64_t clock_us(void){return (uint64_t)esp_timer_get_time();}
static uint64_t random_id(void){uint64_t n=0;while(!n)n=((uint64_t)esp_random()<<32)|esp_random();return n;}
#if !CONFIG_PD_EXTERNAL_GATEWAY
static uint16_t even_parity(uint16_t v){unsigned p=0;for(unsigned i=0;i<15;i++)p^=(v>>i)&1;return v|((uint16_t)p<<15);}
static bool even(uint16_t v){unsigned p=0;for(unsigned i=0;i<16;i++)p^=(v>>i)&1;return p==0;}
static esp_err_t spi_word(unsigned port,uint16_t tx,uint16_t *rx){
    uint8_t a[2]={(uint8_t)(tx>>8),(uint8_t)tx},b[2]={0};
    spi_transaction_t t={.length=16,.tx_buffer=a,.rx_buffer=b};
    gpio_set_level(pd_cs_gpio[port],0);esp_rom_delay_us(1);
    esp_err_t e=spi_device_polling_transmit(sensor,&t);
    esp_rom_delay_us(1);gpio_set_level(pd_cs_gpio[port],1);esp_rom_delay_us(1);
    *rx=((uint16_t)b[0]<<8)|b[1];return e;
}
static uint16_t read_reg(unsigned port,uint16_t addr,uint16_t *value){
    uint16_t dummy=0,r=0,flags=0;
    esp_err_t a=spi_word(port,even_parity(0x4000|addr),&dummy),b=spi_word(port,0,&r);
    if(a!=ESP_OK || b!=ESP_OK)flags|=IO_FAIL;
    if(!even(r))flags|=PARITY_FAIL;
    if(r&0x4000)flags|=SENSOR_ERROR;
    *value=r&0x3fff;return flags;
}
static uint16_t read_axis(unsigned port){
    uint16_t diag=0,mag=0,angle=0,hi=0,lo=0,dummy=0,flags=0;
    flags|=read_reg(port,0x3ffd,&diag);flags|=read_reg(port,0x3ffe,&mag);flags|=read_reg(port,0x3fff,&angle);
    flags|=read_reg(port,0x0016,&hi);flags|=read_reg(port,0x0017,&lo);
    if(!(diag&0x100) || (diag&0xe00))flags|=MAGNET_FAIL;
    if(((hi&255)<<6)|(lo&63))flags|=NONZERO_OTP;
    if(flags&SENSOR_ERROR)(void)read_reg(port,1,&dummy); /* read-to-clear only */
    return flags?(uint16_t)(PD_FAULT|flags):angle;
}
static void spi_setup(void){
    uint64_t mask=0;for(unsigned i=0;i<9;i++)mask|=1ULL<<pd_cs_gpio[i];
    gpio_config_t pins={.pin_bit_mask=mask,.mode=GPIO_MODE_OUTPUT};ESP_ERROR_CHECK(gpio_config(&pins));
    for(unsigned i=0;i<9;i++)gpio_set_level(pd_cs_gpio[i],1);
    spi_bus_config_t bus={.mosi_io_num=11,.miso_io_num=13,.sclk_io_num=12,.quadwp_io_num=-1,.quadhd_io_num=-1,.max_transfer_sz=2};
    ESP_ERROR_CHECK(spi_bus_initialize(SPI2_HOST,&bus,SPI_DMA_DISABLED));
    spi_device_interface_config_t device={.clock_speed_hz=250000,.mode=1,.spics_io_num=-1,.queue_size=1};
    ESP_ERROR_CHECK(spi_bus_add_device(SPI2_HOST,&device,&sensor));
    ESP_ERROR_CHECK(gpio_set_pull_mode(GPIO_NUM_13,GPIO_PULLUP_ONLY));
}
#endif
static bool on_rx(twai_node_handle_t handle,const twai_rx_done_event_data_t *edata,void *context){
    (void)edata;(void)context;rx_event_t e={.us=clock_us()};twai_frame_t f={.buffer=e.bytes,.buffer_len=8};BaseType_t woken=pdFALSE;
    if(twai_node_receive_from_isr(handle,&f)==ESP_OK && !f.header.ide && !f.header.rtr && !f.header.fdf && f.header.dlc==8){
        e.id=f.header.id;if(xQueueSendFromISR(receive_queue,&e,&woken)!=pdTRUE)atomic_store(&rx_overflow,true);
    }
    return woken==pdTRUE;
}
static bool on_tx(twai_node_handle_t handle,const twai_tx_done_event_data_t *edata,void *context){
    (void)handle;(void)context;BaseType_t woken=pdFALSE;tx_success=edata->is_tx_success;xSemaphoreGiveFromISR(transmit_done,&woken);return woken==pdTRUE;
}
static void can_setup(void){
    twai_onchip_node_config_t c={.io_cfg={.tx=17,.rx=18,.quanta_clk_out=-1,.bus_off_indicator=-1},.bit_timing={.bitrate=500000},.fail_retry_cnt=0,.tx_queue_depth=1,.intr_priority=2,.flags={.no_receive_rtr=1}};
    ESP_ERROR_CHECK(twai_new_node_onchip(&c,&can));twai_event_callbacks_t callbacks={.on_rx_done=on_rx,.on_tx_done=on_tx};
    ESP_ERROR_CHECK(twai_node_register_event_callbacks(can,&callbacks,NULL));ESP_ERROR_CHECK(twai_node_enable(can));
}
static void can_reset(void){
    twai_node_status_t status;ESP_ERROR_CHECK(twai_node_get_info(can,&status,NULL));
    if(status.state!=TWAI_ERROR_BUS_OFF)ESP_ERROR_CHECK(twai_node_disable(can));
    ESP_ERROR_CHECK(twai_node_delete(can)); /* driver releases queued frame pointers before global buffer reuse */
    xQueueReset(receive_queue);while(xSemaphoreTake(transmit_done,0)==pdTRUE){}
    atomic_store(&rx_overflow,false);can_setup();
}
static bool send8(uint32_t id,const uint8_t *data){
    while(xSemaphoreTake(transmit_done,0)==pdTRUE){}
    memcpy(transmit_bytes,data,8);transmit_frame=(twai_frame_t){.header={.id=id,.dlc=8},.buffer=transmit_bytes,.buffer_len=8};tx_success=false;
    if(twai_node_transmit(can,&transmit_frame,0)!=ESP_OK)return false;
    /* The next call is forbidden after failure until can_reset destroys old TX references. */
    if(xSemaphoreTake(transmit_done,pdMS_TO_TICKS(4))!=pdTRUE || !tx_success)return false;
    return twai_node_transmit_wait_all_done(can,4)==ESP_OK;
}

/* Each region request is a CRC-protected datagram with full G0 boot, monotonically
 * increasing token and expected region boot. Old responses cannot complete it. */
enum { O5_QUERY=0x600,O5_REPLY=0x610 };
static bool send_packet(uint32_t id,const uint8_t* raw,size_t bytes,uint64_t deadline)
{
    for(unsigned i=0;i<(bytes+6)/7;i++){
        uint8_t fragment[8];pd5_make_fragment(raw,bytes,i,fragment);
        if(clock_us()>=deadline||!send8(id,fragment)){can_reset();return false;}
    }
    return clock_us()<deadline;
}
#if CONFIG_PD_EXTERNAL_GATEWAY
static uint32_t next_token;
static uint64_t device_id;
static pd5_usb identity,current;
static uint8_t command_buffer[PD5_USB_BYTES];
static size_t command_bytes;
static uint64_t command_started;
static bool active;
static uint64_t next_scan;
static uint8_t seen[32][16];
static unsigned seen_count,seen_next;
static bool output(pd5_usb* msg)
{
    uint8_t wire[PD5_USB_BYTES];pd5_encode_usb(msg,wire);size_t sent=0;uint64_t deadline=clock_us()+20000;
    while(sent<sizeof(wire)&&clock_us()<deadline){int n=usb_serial_jtag_write_bytes(wire+sent,sizeof(wire)-sent,pdMS_TO_TICKS(1));if(n>0)sent+=(size_t)n;}
    return sent==sizeof(wire);
}
static bool query(unsigned node,uint64_t expected,unsigned operation,pd5_region_request* req,pd5_region_result* result,uint64_t deadline)
{
    if(next_token==UINT32_MAX)return false; /* reboot/re-negotiate instead of token wrap */
    *req=(pd5_region_request){.node=(uint8_t)node,.operation=(uint8_t)operation,.gateway_boot=boot_id,.expected_boot=expected,.token=++next_token};
    uint8_t raw[28];pd5_encode_request(req,raw);xQueueReset(receive_queue);atomic_store(&rx_overflow,false);
    if(!send_packet(O5_QUERY+node,raw,sizeof(raw),deadline))return false;
    pd5_fragments fragments={0};rx_event_t event;
    while(clock_us()<deadline){
        if(atomic_exchange(&rx_overflow,false))return false;
        if(xQueueReceive(receive_queue,&event,1)!=pdTRUE)continue;
        if(event.id!=O5_REPLY+node)continue;
        int status=pd5_fragment(&fragments,event.bytes,52,event.us);
        if(status<0)return false;
        if(status==1){
            if(!pd5_decode_result(fragments.data,52,result))return false;
            return result->node==node&&result->gateway_boot==boot_id&&result->token==req->token&&(!expected||result->boot==expected);
        }
    }
    return false;
}
static void discover(void)
{
    active=false;identity=(pd5_usb){.type=PD5_HELLO,.device=device_id,.boot=boot_id};pd5_blank_scan(&identity);
    for(unsigned node=1;node<=6;node++){
        pd5_region_request req;pd5_region_result res;
        if(query(node,0,PD5_PROBE,&req,&res,clock_us()+25000)){
            identity.source_boot[node-1]=res.boot;
            for(unsigned port=0;port<pd_port_count[node-1];port++)if(res.mask&(1u<<port))identity.physical_mask|=UINT64_C(1)<<pd_axis_index[node-1][port];
        }
    }
    (void)output(&identity);
}
static void fail_capture(void){active=false;current.type=PD5_ERROR;(void)output(&current);}
static void accept_command(const pd5_usb* cmd)
{
    if(cmd->type==PD5_PROBE){discover();return;}
    if(cmd->device!=device_id||cmd->boot!=boot_id){fail_capture();return;}
    if(cmd->type==PD5_CANCEL||cmd->type==PD5_STOP){if(!memcmp(cmd->capture,current.capture,16))active=false;return;}
    if(cmd->type!=PD5_REQUEST){fail_capture();return;}
    unsigned nonzero=0;for(unsigned i=0;i<16;i++)nonzero|=cmd->capture[i];
    if(!nonzero){fail_capture();return;}
    if(active&&!memcmp(cmd->capture,current.capture,16)){
        pd5_usb ack=current;ack.type=PD5_ACCEPTED;ack.scan=0;ack.start_us=ack.end_us=0;(void)output(&ack);return;
    }
    for(unsigned i=0;i<seen_count;i++)if(!memcmp(seen[i],cmd->capture,16)){fail_capture();return;}
    memcpy(seen[seen_next],cmd->capture,16);seen_next=(seen_next+1)%32;if(seen_count<32)++seen_count;
    current=identity;current.type=PD5_ACCEPTED;memcpy(current.capture,cmd->capture,16);current.scan=0;
    current.request_us=clock_us();current.start_us=current.end_us=0;active=output(&current);next_scan=clock_us();
}
static void read_commands(void)
{
    uint8_t b;
    if(command_bytes&&clock_us()-command_started>500000){command_bytes=0;fail_capture();}
    for(unsigned budget=0;budget<PD5_USB_BYTES*2;budget++){
        if(usb_serial_jtag_read_bytes(&b,1,0)!=1)break;
        if(command_bytes==0)command_started=clock_us();
        command_buffer[command_bytes++]=b;
        if(command_bytes<=4&&memcmp(command_buffer,"PDG5",command_bytes)){command_bytes=0;fail_capture();continue;}
        if(command_bytes==PD5_USB_BYTES){
            pd5_usb cmd;command_bytes=0;
            if(pd5_decode_usb(command_buffer,sizeof(command_buffer),&cmd))accept_command(&cmd);else fail_capture();
        }
    }
}
static void gateway(void)
{
    uint8_t mac[6];ESP_ERROR_CHECK(esp_efuse_mac_get_default(mac));for(unsigned i=0;i<6;i++)device_id=(device_id<<8)|mac[i];
    current.device=device_id;current.boot=boot_id;
    for(;;){
        read_commands();uint64_t now=clock_us();
        if(active&&(!usb_serial_jtag_is_connected()||now-current.request_us>3000000)){fail_capture();}
        if(active&&now>=next_scan){
            current.type=PD5_SCAN;++current.scan;pd5_blank_scan(&current);current.start_us=clock_us();
            bool complete=true;
            for(unsigned node=1;node<=6;node++){
                pd5_region_request req;pd5_region_result res;uint64_t deadline=clock_us()+20000;
                if(deadline>current.start_us+100000)deadline=current.start_us+100000;
                if(!identity.source_boot[node-1]||!query(node,identity.source_boot[node-1],PD5_REQUEST,&req,&res,deadline)||!pd5_merge_region(&current,&res,&req,clock_us())){complete=false;continue;}
            }
            current.end_us=clock_us();
            /* Missing/invalid regions remain explicit. No retry resets this start time. */
            if(!output(&current))active=false;
            if(!complete)active=false;
            next_scan=current.start_us+100000;
        }
        vTaskDelay(1);
    }
}
#else
static uint16_t read_port(void* unused,unsigned port){(void)unused;return read_axis(port);}
static void regional(void)
{
    pd5_fragments fragments={0};rx_event_t event;uint64_t last_gateway=0;uint32_t last_token=0;
    for(;;){
        if(atomic_exchange(&rx_overflow,false)){can_reset();fragments=(pd5_fragments){0};}
        if(xQueueReceive(receive_queue,&event,1)!=pdTRUE)continue;
        if(event.id!=O5_QUERY+NODE)continue;
        int state=pd5_fragment(&fragments,event.bytes,28,event.us);
        if(state!=1)continue;
        pd5_region_request req;
        if(!pd5_decode_request(fragments.data,28,&req)||req.node!=NODE||(req.expected_boot&&req.expected_boot!=boot_id))continue;
        if(req.gateway_boot==last_gateway&&req.token<=last_token)continue; // A aborts lost datagrams; no cached angle reply.
        last_gateway=req.gateway_boot;last_token=req.token;
        pd5_region_result result={.node=NODE,.count=pd_port_count[NODE-1],.gateway_boot=req.gateway_boot,.boot=boot_id,.token=req.token};
        unsigned ports=CONFIG_PD_BENCH_PORTS;if(ports>result.count)ports=result.count;
        uint64_t start=clock_us();
        if(req.operation==PD5_REQUEST)pd5_acquire_ports(&result,ports,read_port,NULL);
        else{result.mask=(uint16_t)((1u<<ports)-1);for(unsigned i=0;i<9;i++)result.words[i]=PD5_MISSING;}
        result.duration_us=(uint32_t)(clock_us()-start);if(!result.duration_us)result.duration_us=1;
        uint8_t reply[52];if(pd5_encode_result(&result,reply)&&!atomic_load(&rx_overflow))
            (void)send_packet(O5_REPLY+NODE,reply,sizeof(reply),start+100000);
    }
}
#endif
void app_main(void)
{
    vTaskPrioritySet(NULL,configMAX_PRIORITIES-3);boot_id=random_id();
    receive_queue=xQueueCreate(64,sizeof(rx_event_t));transmit_done=xSemaphoreCreateBinary();configASSERT(receive_queue&&transmit_done);can_setup();
#if CONFIG_PD_EXTERNAL_GATEWAY
    usb_serial_jtag_driver_config_t usb={.tx_buffer_size=1024,.rx_buffer_size=1024};ESP_ERROR_CHECK(usb_serial_jtag_driver_install(&usb));gateway();
#else
    spi_setup();regional();
#endif
}

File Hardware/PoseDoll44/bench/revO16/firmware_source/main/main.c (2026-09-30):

/* O15-C1 experimental raw46 central scanner + external G0. No OTP writes.
 * Pair MACs explicitly before hardware tests. Default zero MAC cannot pair.
 * G0 start/end bracket radio request+fresh body scan+reply in G0 clock domain.
 * Declared chain lengths never prove physical node count. Commission every node.
 */
#include <stdatomic.h>
#include <string.h>
#include <stdio.h>
#include "sdkconfig.h"
#include "freertos/FreeRTOS.h"
#include "freertos/task.h"
#include "freertos/queue.h"
#include "freertos/semphr.h"
#include "driver/spi_master.h"
#include "driver/gpio.h"
#include "driver/usb_serial_jtag.h"
#include "esp_wifi.h"
#include "esp_now.h"
#include "esp_event.h"
#include "nvs_flash.h"
#include "esp_timer.h"
#include "esp_rom_sys.h"
#include "esp_random.h"
#include "esp_system.h"
#include "esp_mac.h"
#include "esp_err.h"
#include "raw46.h"
static QueueHandle_t radio_rx;
static SemaphoreHandle_t radio_done;
static atomic_bool overflow;
static volatile bool tx_ok;
static uint8_t peer[6],transmit[P15_BYTES];
static bool paired;
static uint64_t boot_id,device;
static uint64_t clock_us(void){return (uint64_t)esp_timer_get_time();}
static uint64_t random_id(void){uint64_t n=0;while(!n)n=((uint64_t)esp_random()<<32)|esp_random();return n;}
static void rx_callback(const esp_now_recv_info_t *info,const uint8_t* data,int n){
 if(!paired||n!=P15_BYTES||memcmp(info->src_addr,peer,6))return;
 if(xQueueSend(radio_rx,data,0)!=pdTRUE)atomic_store(&overflow,true);
}
static void tx_callback(const esp_now_send_info_t *info,esp_now_send_status_t status){(void)info;tx_ok=status==ESP_NOW_SEND_SUCCESS;xSemaphoreGive(radio_done);}
static void radio_setup(void){
 esp_err_t e=nvs_flash_init();if(e==ESP_ERR_NVS_NO_FREE_PAGES||e==ESP_ERR_NVS_NEW_VERSION_FOUND){ESP_ERROR_CHECK(nvs_flash_erase());e=nvs_flash_init();}ESP_ERROR_CHECK(e);
 ESP_ERROR_CHECK(esp_netif_init());ESP_ERROR_CHECK(esp_event_loop_create_default());wifi_init_config_t c=WIFI_INIT_CONFIG_DEFAULT();
 ESP_ERROR_CHECK(esp_wifi_init(&c));ESP_ERROR_CHECK(esp_wifi_set_storage(WIFI_STORAGE_RAM));ESP_ERROR_CHECK(esp_wifi_set_mode(WIFI_MODE_STA));ESP_ERROR_CHECK(esp_wifi_start());ESP_ERROR_CHECK(esp_wifi_set_ps(WIFI_PS_NONE));ESP_ERROR_CHECK(esp_wifi_set_channel(CONFIG_P15_CHANNEL,WIFI_SECOND_CHAN_NONE));
 uint8_t mac[6];ESP_ERROR_CHECK(esp_wifi_get_mac(WIFI_IF_STA,mac));device=0;for(unsigned i=0;i<6;i++)device=(device<<8)|mac[i];
 unsigned p[6]={0};int used=0;const char*s=CONFIG_P15_PEER_MAC;
 if(sscanf(s,"%2x:%2x:%2x:%2x:%2x:%2x%n",p,p+1,p+2,p+3,p+4,p+5,&used)==6&&used==17&&strlen(s)==17){
  unsigned nonzero=0;for(unsigned i=0;i<6;i++){peer[i]=(uint8_t)p[i];nonzero|=p[i];}paired=nonzero&&!(peer[0]&1)&&memcmp(peer,mac,6);
 }
 radio_rx=xQueueCreate(16,P15_BYTES);radio_done=xSemaphoreCreateBinary();configASSERT(radio_rx&&radio_done);
 ESP_ERROR_CHECK(esp_now_init());ESP_ERROR_CHECK(esp_now_register_recv_cb(rx_callback));ESP_ERROR_CHECK(esp_now_register_send_cb(tx_callback));
 if(paired){esp_now_peer_info_t cfg={0};memcpy(cfg.peer_addr,peer,6);cfg.channel=CONFIG_P15_CHANNEL;cfg.ifidx=WIFI_IF_STA;cfg.encrypt=false;ESP_ERROR_CHECK(esp_now_add_peer(&cfg));}
}
static bool send_radio(const p15_message*m){
 if(!paired||!p15_encode(m,transmit))return false;
 while(xSemaphoreTake(radio_done,0)==pdTRUE){}tx_ok=false;
 if(esp_now_send(peer,transmit,sizeof(transmit))!=ESP_OK)return false;
 // A timeout can leave SDK transmission pending. Reboot, never overwrite its buffer.
 if(xSemaphoreTake(radio_done,pdMS_TO_TICKS(60))!=pdTRUE)esp_restart();
 return tx_ok;
}
static bool receive_radio(p15_message*m,uint64_t deadline){
 uint8_t bytes[P15_BYTES];
 while(clock_us()<deadline){
  if(atomic_exchange(&overflow,false))return false;
  if(xQueueReceive(radio_rx,bytes,1)==pdTRUE&&p15_decode(bytes,sizeof(bytes),m))return true;
 }
 return false;
}
#if !CONFIG_P15_GATEWAY
static spi_device_handle_t spi;
static const int cs[6]={2,4,5,6,43,44};
static void sensor_setup(void){
 // GPIO1 enables six branch-local open-drain OE stages. Low means disconnected.
 uint64_t mask=UINT64_C(1)<<1;for(unsigned i=0;i<6;i++)mask|=UINT64_C(1)<<cs[i];
 gpio_config_t c={.pin_bit_mask=mask,.mode=GPIO_MODE_OUTPUT};ESP_ERROR_CHECK(gpio_config(&c));gpio_set_level(1,0);
 for(unsigned i=0;i<6;i++)gpio_set_level(cs[i],1);
 spi_bus_config_t bus={.mosi_io_num=9,.miso_io_num=8,.sclk_io_num=7,.quadwp_io_num=-1,.quadhd_io_num=-1,.max_transfer_sz=20};
 ESP_ERROR_CHECK(spi_bus_initialize(SPI2_HOST,&bus,SPI_DMA_DISABLED));
 spi_device_interface_config_t dev={.clock_speed_hz=100000,.mode=1,.spics_io_num=-1,.queue_size=1};ESP_ERROR_CHECK(spi_bus_add_device(SPI2_HOST,&dev,&spi));
 ESP_ERROR_CHECK(gpio_set_pull_mode(8,GPIO_PULLUP_ONLY));vTaskDelay(pdMS_TO_TICKS(50));gpio_set_level(1,1);
}
static void fresh_scan(p15_message*m){
 unsigned offset=0;m->valid_mask=0;for(unsigned i=0;i<46;i++)m->words[i]=P15_FAULT;
 for(unsigned chain=0;chain<6;chain++){
  unsigned n=p15_counts[chain];uint16_t rx[6][10]={0};bool io=true;
  for(unsigned b=0;b<6;b++){
   uint16_t w=b<5?p15_command(p15_registers[b]):0;uint8_t tx[20]={0},r[20]={0};
   for(unsigned j=0;j<n;j++){tx[2*j]=(uint8_t)(w>>8);tx[2*j+1]=(uint8_t)w;}
   spi_transaction_t t={.length=n*16,.tx_buffer=tx,.rx_buffer=r};
   gpio_set_level(cs[chain],0);esp_rom_delay_us(2);if(spi_device_polling_transmit(spi,&t)!=ESP_OK)io=false;esp_rom_delay_us(2);gpio_set_level(cs[chain],1);esp_rom_delay_us(2);
   for(unsigned j=0;j<n;j++)rx[b][j]=(uint16_t)(((uint16_t)r[2*j]<<8)|r[2*j+1]);
  }
  if(io){
   bool good=p15_decode_chain(rx,n,m->words+offset);
   // Clear latched AS5048 communication errors for a subsequent new request.
   // Never replace this failed scan with the clearing responses.
   if(!good)for(unsigned b=0;b<2;b++){
    uint16_t w=b==0?p15_command(0x0001):0;uint8_t tx[20]={0},r[20]={0};
    for(unsigned j=0;j<n;j++){tx[2*j]=(uint8_t)(w>>8);tx[2*j+1]=(uint8_t)w;}
    spi_transaction_t t={.length=n*16,.tx_buffer=tx,.rx_buffer=r};
    gpio_set_level(cs[chain],0);esp_rom_delay_us(2);(void)spi_device_polling_transmit(spi,&t);esp_rom_delay_us(2);gpio_set_level(cs[chain],1);esp_rom_delay_us(2);
   }
  }
  for(unsigned j=0;j<n;j++)if(m->words[offset+j]<0x4000)m->valid_mask|=UINT64_C(1)<<(offset+j);
  offset+=n;
 }
}
static void body(void){
 sensor_setup();uint64_t bound=0;uint32_t last=0;
 for(;;){
  p15_message m;if(!receive_radio(&m,clock_us()+100000))continue;
  if(m.device!=device)continue; // bind calibration to the physical body MAC
  if(m.type==P15_PROBE){
   if(!m.gateway_boot)continue;
   if(bound!=m.gateway_boot){bound=m.gateway_boot;last=0;}
   m.type=P15_HELLO;m.body_boot=boot_id;m.valid_mask=0;(void)send_radio(&m);continue;
  }
  if(m.type!=P15_READ||!bound||m.gateway_boot!=bound||m.body_boot!=boot_id||!m.token||m.token<=last||!m.scan)continue;
  last=m.token;m.type=P15_BODY_SCAN;m.start_us=clock_us();fresh_scan(&m);m.end_us=clock_us();(void)send_radio(&m);
 }
}
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

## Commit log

2026-09-30 design: deliver O15 full-doll prototype and consolidated validation batch
    Checkpoint the previously uncommitted O5-O14 iterations and the O15 full-body
    FDM prototype, stock hardware, electronics, firmware, static-capture bridge,
    interactive guide, and Quinn/Manny print and procurement packages.
    Add the current review entry point and a clone-portable integrity checker.
    Preserve sealed historical bytes and include their required dependencies;
    exclude local browser sessions, scratch output, builds and diagnostic G-code.
    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
    [01 Descriptions.kicad_sch, 02 Block Diagram.kicad_sch, 03 XIAO ESP32-S3-Sense.kicad_sch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]
2026-09-30 design: preserve O16 single universal pose doll baseline
    [P001.3mf, P001.stl, P002.3mf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]
2026-09-30 design: add O17 USB simplification prototype with integrated sensor mounts
    [N001.3mf, N001.stl, N002.3mf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]
2026-09-30 design: add O18 integrated hinge housings with 188-piece print set
    [H001.3mf, H001.stl, H002.3mf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]
2026-09-30 Align O19 leg beam spans and record accepted O11 friction test
    [H001.3mf, H001.stl, H002.3mf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]
2026-09-30 Simplify O20 toe housings and lighten rigid carriers
    [H003.3mf, H003.stl, H004.3mf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]
2026-09-30 Add O21 MT6701 cost-down engineering design and budget
    [PoseDoll_O21_MT6701CT.kicad_pcb, PoseDoll_O21_MT6701CT.kicad_sch, PoseDoll_O21_SSI_Carrier.kicad_sch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]
2026-10-01 Implement O22 measured-pose engineering revision and review closure package
    [C1.stl, C2.stl, H004.3mf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]
2026-10-01 Add grouped A1 mini print plates for the O22 doll
    [A01_head.3mf, A02_torso_1.3mf, A03_torso_2.3mf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]
2026-10-02 Add plate-aware O22 assembly and wiring tutorial
2026-10-04 Add native O22 A1 mini PLA support projects and clearance checks
    [A01_head_PLA_supports.3mf, A02_torso_1_PLA_supports.3mf, A03_torso_2_PLA_supports.3mf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]
2026-10-17 Add O22F7 PLA assembly release and preserve print revision history
    - Record O22F1-F7 delivery directories, source tools and required frozen inputs.
    - Include the C7 left-clavicle split, PLA support fixes and the complete
    26-chapter assembly and electrical animation.
    - Preserve successful simulation toolchain benchmarks and release evidence.
    - Keep iterative slicing workspaces, duplicate archives and failed trial
    runs local through explicit ignore rules.
    - Store four large O22F7 delivery assets in Git LFS.
    Validation: 1,628 released-file checksums match; 722 new Python scripts
    parse successfully. Existing digital release checks remain recorded;
    this commit does not claim physical printin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
2026-10-21 Add O23 humanoid design through unified O23I mounts
    Consolidate the O22F7-to-O23I design work: humanoid structural walls,
    UE-aligned hip centres and limb proportions, fixed five-finger fists,
    seated rod ends, continuous mounting contours, and internal wire routing.
    Preserve source snapshots, geometry-bound verification, current preview,
    32 closed STL models, and selected G/H/I native A1 mini PLA projects.
    Use Git LFS for model artifacts and omit reproducible local trial caches.
    Record the current review status explicitly: 408 daily and 114 transition
    poses pass required adjacent checks; I print validation passes 23/32 parts.
    Nine support candidates remain unfinished; no manufacturing relea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
2026-10-25 Add O24 design revisions through T6 joint kits and O24D snapshots
    Preserve O24A/B/C arm designs, T1-T6 test kits, O24D work and baseline
    snapshots, including CAD sources, STL, print projects and assembly tutorials.
    Introduce the T6 captured nylon-locknut joint kit while retaining the existing
    shoulder screws, with hardware/reprint lists and a 100-cycle test procedure.
    T6 digital delivery checks pass; physical 100-cycle validation remains pending.
    Track O24 manufacturing assets and release archives with Git LFS and update
    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
2026-10-30 Add O24E arm revisions and complete R5 seven-axis sensing
    Preserve the O24E whole-body and R1-R4 arm baselines needed to rebuild R5,
    including the accepted R4 mechanical feedback and O24D redesign audit.
    Add six O22 MT6701CT channels and a TMAG5170A1 wrist-deviation channel,
    with real sensor mounts, independent wrist measurements, wiring, firmware,
    calibration tools, print projects and a 409-step assembly guide. Retain
    R4 friction, preload and capture hardware; reprint five main parts and
    reuse six unchanged main parts.
    Archive the CAD sources, delivery packages and digital verification
    reports using existing Git LFS rules. Exclude local firmware and slicer
    build caches and add the R5 entr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
